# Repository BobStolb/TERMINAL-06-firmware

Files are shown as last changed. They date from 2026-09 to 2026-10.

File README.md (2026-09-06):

# TERMINAL-06 firmware

Six-digit Soviet nixie tube clock firmware — 4x IN-12A (HH:MM) + 2x IN-17 (SS),
built on Arduino Nano / ATmega328P.

Derived from [AlexGyver's NixieClock v2.5](https://github.com/AlexGyver/NixieClock_v2)
(MIT-spirited open project). Keep the original attribution if you redistribute
this source — see the header of `nixieClock_TS06.ino`.

## What's in here

- `firmware/nixieClock_TS06/` — the main clock sketch. Open
  `nixieClock_TS06.ino` in the Arduino IDE; the other `.ino` files in the same
  folder are tabs of the same sketch and compile together automatically.
  `nixieClock_TS06.hex` alongside them is a precompiled build — flashable
  directly with avrdude if you don't want to rebuild from source.
- `firmware/secCathodeMap/` — a standalone bench jig (its own `setup()`/
  `loop()`, deliberately kept in a separate sketch folder from the main
  firmware so the two don't collide at compile time). Run it once per new
  SEC module to map IN-17 cathodes to K155ID1 pins — see the comment header
  in `secCathodeMap.ino` for the full procedure.
- `libraries/` — actual source for the third-party libraries this sketch
  depends on: `GyverButton/` and `RTClib/`, each in the standard Arduino
  library layout (`.h`/`.cpp`, `library.properties`, examples). To build
  from scratch, copy both folders into your Arduino sketchbook's
  `libraries/` directory before compiling. Wire and EEPROM are built into
  the Arduino AVR core and don't need anything extra.

## Status vs. the project spec (as of 28.08.26)

This code is the display-layer port described in `TERMINAL-06-spec.md` §5:
six-tube multiplex ISR (Timer2 at AlexGyver's original prescaler 8, 50 Hz
refresh with 640 us of optocoupler dead time — see MULTIPLEX TIMING in the
sketch), anti-poisoning and glitch effects extended to all six tubes (both
now switchable off at build time, and currently off pending bench sign-off
of the timing), buzzer removed (D2 reused),
old rev B control scheme (2 buttons + 1 lever) — not the rotary/lever panel
described elsewhere in the project, which is a later firmware milestone.

**One known discrepancy, not yet fixed here:** the spec states `DOT_BRIGHT`
was retuned for neon (170/90) instead of the LED-era default (35/15), but
this source still has `DOT_BRIGHT 35` / `DOT_BRIGHT_N 15`
(`nixieClock_TS06.ino`). Doesn't affect the digit-multiplex testing this
firmware is used for (P2 in the prototype plan), but worth fixing before the
colon step (P6).

## Board settings for flashing

Arduino IDE: Board = Arduino Nano, Processor = ATmega328P. If upload fails
with a programmer-not-responding error, switch Processor to
"ATmega328P (Old Bootloader)" — common on CH340-based Nano clones.

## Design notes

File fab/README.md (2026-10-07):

# Fab packages: TS06-DISP, TS06-DRV and the fascia R

**To order, read `ORDER.md` (the order sheet for the owner).** Pictures of the boards are in `preview/`.

One zip per board of the through-hole pair, built from the committed boards by `tools/mkfab.sh`
(grill.md G8, second half). Rebuilt 30.09.26 from `pcb/kicad-boards` at 77e3b11 (TS06-DISP with
the circuit-as-ornament silkscreen art; TS06-DRV unchanged), with KiCad 10.0.6's `kicad-cli` in Docker.
First built at b8d3f25 (the rev B merge).

The fascia R (rev A, with the Divider gold) was added on 02.10.26. **On 07.10.26 it became rev B** (J1 is the upright JST B6B-PH-SM4-TB instead of the
side-entry S6B-PH-SM4-TB, `PCB/TS06-FASCIA-rhythm/J1-UPRIGHT.md`): `TS06-FASCIA-R-revB-divider-holes04-fab.zip` is the ordered one (control holes
opened 0.4 mm and level leaders, picked by the owner on 02.10.26). Rev A's zip with those holes is kept as `TS06-FASCIA-R-revA-divider-holes04-notordered-fab.zip`
and the first fascia zip, holes as drawn, as `TS06-FASCIA-R-revA-divider-slope-notordered-fab.zip`: both NOT ordered. See below.
It was rebuilt the same day, after the design-for-manufacture check (`tools/dfm_check.py`, the table below) had found
four things on it: thin silk, a small back legend, slivers of mask at four dial rings, and "None" as the finish in its job file.
All four are fixed in the generators; TS06-DISP's and TS06-DRV's zips did not change.

Not ordered: the prototype run is the owner's decision (grill G14). Filling the committed board files (G8, first half) is also the owner's decision.

## What is in each zip

`TS06-DISP-revB-fab.zip` and `TS06-DRV-revB-fab.zip` hold the same 12 files, named after the board:

| File | What it is |
|---|---|
| `<board>-F_Cu.gtl`, `<board>-B_Cu.gbl` | Copper, front and back, with the pours filled by KiCad (`--check-zones`) |
| `<board>-F_Mask.gts`, `<board>-B_Mask.gbs` | Solder mask, front and back |
| `<board>-F_Silkscreen.gto`, `<board>-B_Silkscreen.gbo` | Silkscreen, front and back |
| `<board>-Edge_Cuts.gm1` | Board outline |
| `<board>-PTH.drl`, `<board>-NPTH.drl` | Excellon drills, mm, plated and non-plated in separate files |
| `<board>-PTH-drl_map.gbr`, `<board>-NPTH-drl_map.gbr` | Drill maps (Gerber X2) |
| `<board>-job.gbrjob` | Gerber job file: board size, layer count, thickness, the file list |

All Gerbers are Gerber X2, 4.6 mm format, KiCad's default Protel extensions. There are no paste
layers: every part is through-hole (no SMD pads on either board), and neither board has a via.

| Board | Size (job file) | Plated holes | Non-plated holes |
|---|---|---|---|
| TS06-DISP rev B | 191.5 × 44.1 mm | 179 | 10 |
| TS06-DRV rev B | 191.5 × 100.1 mm | 427 | 8 |
| Fascia R rev B, Divider gold | 191.45 × 40.05 mm, 2.0 mm thick | 0 | 9 |

TS06-DISP's silkscreen files carry the art: front 29 kB to 121 kB, back 104 kB to 173 kB. Its
copper, mask, outline and drill files are the same as before the art, apart from the creation
date, and the thinnest silk line in them is 0.15 mm (the apertures in the two silk files).
TS06-DRV's files are the same as before, apart from the creation date.

The hole counts are the drill files' hits; they equal the boards' through-hole and
non-plated pads. Both job files say 2 layers, 1.6 mm and ENIG, from the boards' own setup; the
finish and the mask colour are chosen when the boards are ordered.

## The fascia R zip

`TS06-FASCIA-R-revB-divider-holes04-fab.zip` is the fascia `PCB/TS06-FASCIA-rhythm` (rev B) with the Plates white
print and a gold: the **Divider** by default. The committed board has no gold of its own, so `tools/mkfab.sh`
builds the art board in its scratch directory with `tools/fascia_gold.py divider OUT --base R` (that
script's own checks must be clean) and plots that. Nothing under `PCB/` is written.

* The zip has 11 files: the same names as above with the prefix `TS06-FASCIA-R-divider`, and one more,
  `B_Paste.gbp` (the eight 1206 resistors are surface-mount on the back). There is no plated drill file or
  plated drill map: the board has no plated hole. The board is 2.0 mm thick (the job file says so), and its job
  file says finish ENIG, as the other two: the board file carries the same stack-up (black mask, white silk, ENIG), written by `tools/mkpcb_fascia_rhythm.py`.
* The gold is in F.Cu as copper, 0.05 mm wider each side than the opening in F.Mask over it, so a mask
  misregistration shows gold and never bare board. `tools/mkfab.sh` reads the plotted Gerbers back with
  `tools/gerbers.py gold` (no KiCad): F.Cu must carry the gold; F.Mask must be open over all of it (about
  85% of the copper's area, the rest is the 0.05 mm rim); no opening may lie past the copper. The same check is
  run on a mask with the gold's openings removed, and must FAIL. Found: the openings are present, and no thin web
  of mask is left over the gold (the Divider's lines end clear of the dial rings' holes; before, four rings had 0.05 mm slivers).
* The name carries the gold. `--gold VARIANT` picks another (`ladder`, `fans`, `guilloche`; `none` is the bare
  board, `TS06-FASCIA-R-revB-bare-fab.zip`). Only the divider is laid out for R; the other three stop on their own
  checks (`tools/fascia_gold.py` says why).

## Design-for-manufacture check

`python3 tools/dfm_check.py` (limits *inferred*, typical of a low-cost two-layer service; `ORDER.md` lists them) reads each
board twice: KiCad's DRC under the fab limits, and the zip's own Gerbers and drills. Worst value found, and the
rule's limit; the fascia R's column is after the fixes, with the value it had before.

| Rule | Limit | TS06-DISP | TS06-DRV | Fascia R (before the fixes) |
|---|---|---|---|---|
| Track width | 0.15 | 0.25 | 0.25 | 0.25 |
| Copper clearance | 0.15 | 0.25 | 0.21 | 0.325 (rev A 0.375) |
| Annular ring | 0.15 | 0.30 | 0.20 | over 0.40 |
| Copper to edge | 0.30 | 0.75 | 0.75 | over 0.80 |
| Silk line, DRC text stroke | 0.15 | 0.15 | 0.15 | 0.15 (0.12) |
| Silk text height | 1.0 | 1.0 | 1.0 | 1.0 (0.8) |
| Smallest silk aperture, front / back, from the zip | 0.15 | 0.15 / 0.15 | 0.15 / 0.15 | 0.15 / 0.15 (0.12 / 0.10) |
| Smallest plated / non-plated drill | 0.3 / 0.5 | 0.9 / 3.2 | 0.8 / 3.2 | none / 2.7 |
| Narrowest mask web, front | 0.10 | 0.3 | 0.3 | 0.100 (0.05) |
| Narrowest mask web, back | 0.10 | 0.3 | 0.3 | over 0.35 |
| Board size | within 500 x 400 | 191.4 x 44.0 | 191.4 x 100.0 | 191.4 x 40.0 |
| **Result** | | all PASS | all PASS | all PASS (4 rows FAILed) |

Rows that do not appear above (plated drill, non-plated drill and hole-to-hole in the DRC; the fascia's gold exposed) also
PASS. The check's own self-test, a copy of TS06-DISP with one planted fault per rule, shows FAIL on all 17 rows, so the
rows can fail. The mask web reading is the raster's (steps of 0.025 mm, about +-0.03 mm).

## Region check

Every copper Gerber is exported twice: with `--check-zones` (KiCad fills every pour before it
plots; this is the set in the zip) and without it (a control, not shipped). The script counts the
region blocks (`G36` … `G37`) in each. A copper layer that carries a pour in the board file must
have more regions filled than unfilled, or the script fails and does not write the zip.

| Board | Copper layer | Pour in the board file (net) | Regions without --check-zones | Regions with --check-zones | Difference | Check |
|---|---|---|---|---|---|---|
| TS06-DISP rev B | F.Cu | BL_K | 0 (13 kB) | 1 (221 kB) | +1 | PASS |
| TS06-DISP rev B | B.Cu | none | 0 (27 kB) | 0 (27 kB) | +0 | n/a: no pour on this layer |
| TS06-DRV rev B | F.Cu | GND | 0 (57 kB) | 15 (550 kB) | +15 | PASS |
| TS06-DRV rev B | B.Cu | GND | 0 (54 kB) | 10 (443 kB) | +10 | PASS |

**What the difference means.** The committed boards store no fill. Plotted without
`--check-zones`, TS06-DISP's F.Cu has no BL_K pour, so all nine LEDs would be open, and TS06-DRV
has no ground pour on either face. TS06-DISP's back face has no pour by design, so it has nothing
to check. The filled counts equal the pieces KiCad's own fill keeps in
`tools/verify_pair.sh`'s "pours (KiCad)" rows (BL_K 1; GND 15 on the front, 10 on the back): one
region per piece.

## Rebuild

From the repository root:

```
bash tools/mkfab.sh                                   # all three boards; prints the table above
bash tools/mkfab.sh TS06-FASCIA-rhythm --gold fans    # the fascia with another gold (see above)
bash tools/mkfab.sh --keep                            # the same, and keeps the scratch directory (both exports, logs)
python3 tools/dfm_check.py                            # design-for-manufacture tables (inferred generic limits), see ORDER.md
bash tools/mkfab.sh TS06-FASCIA-rhythm --committed-holes   # the fascia as committed (holes 8.8 / 8.0), NOT ordered: ...-notordered-fab.zip
python3 tools/dfm_check.py --committed-holes          # the same DFM check on that zip (the default checks the ordered one)
```

`TS06-FASCIA-R-revB-divider-holes04-fab.zip` is the ordered fascia zip (the dial hole 8.8 opened to 9.2, the lever and button holes 8.0 to 8.4:
the owner's pick, 2026-10-02) with the level leaders (his second pick, the same day). The zip with the holes as drawn is kept as
`TS06-FASCIA-R-revA-divider-slope-notordered-fab.zip`, not ordered. `HOLES-VARIANT.md` says what differs and the margins; `ORDER.md` names the zip.

It needs `zip`, `python3` and KiCad 10's `kicad-cli`: a local one, or Docker with
`mirror.gcr.io/kicad/kicad:10.0`, found the same way as in `tools/verify_pair.sh`. The committed
board files are only read. The Gerbers and drills carry their creation date, so a rebuild is not
byte-identical to these zips; the region counts and the file list are. So that a rebuild does not leave a
changed file behind for nothing, `tools/mkfab.sh` keeps the zip already in this folder when the rebuilt one
differs from it only in those dates (it says so).

The fascia's gold check needs numpy, scipy and Pillow as well; `tools/dfm_check.py` needs the same.

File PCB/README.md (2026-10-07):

# TERMINAL-06 — custom PCBs

The fascia goes to Rezonit with the clock's electronics. For a small production run, the electronics are the through-hole pair **TS06-DISP + TS06-DRV**: tubes on one board, everything else on the one behind it, no vias on either. The one-board TS06-MAIN is kept, with its history. A tube board of the old kind is deliberately deferred.

| Board | Size | Stack | Status |
|---|---|---|---|
| **TS06-FASCIA** | 176 × 40 mm | 2.0 mm FR4, black mask, white silk, ENIG | Routed. The control panel AND the printed product face. One board, not two. Surface-mount build: no solder visible from the front. Height compressed from the original 52mm 2026-09 - see below. |
| **TS06-FASCIA-rhythm** (fascia R) | 191.4 × 40 mm | 2.0 mm FR4, black mask, white silk, ENIG | **The fascia of the order** (`fab/ORDER.md`). Controls on the tubes' grid, surface-mount on the back, no plated hole. **Rev B (7.10.26): J1 is an upright JST B6B-PH-SM4-TB** (top entry: the plug stands off the back and the wires leave straight back; rev A had the side-entry S6B-PH-SM4-TB, whose lead bent 90 + 12 degrees onto the floor and cost the case 7.3 mm) - `PCB/TS06-FASCIA-rhythm/J1-UPRIGHT.md`, `PCB/TS06-FASCIA-rhythm/bom.md`. The 176 TS06-FASCIA above is unchanged (it keeps the side-entry part). |
| **TS06-FASCIA-THT** | 176 × 52 mm | same stack, ENIG | Second build of the same board, routed. Through-hole, with the A6 divider ON the face. Pick one to fabricate; they are alternatives, not a pair. Not yet height-compressed (the SMD build was chosen for fabrication). |
| **TS06-DISP** + **TS06-DRV** | 191.4 × 44 mm + 191.4 × 100 mm | 1.6 mm, matte black | **The through-hole pair (25.09.26), the build for a small production run.** A display board with the tubes and nothing else, plugged by pin strips into a driver board behind it, the way AlexGyver builds his. **Zero vias on either board.** Both at rev B (30.09.26): TS06-DRV rev B is routed and merged, `tools/verify_pair.sh` gives 27 PASS, 0 FAIL, 0 SKIP, and the fab packages are in `../fab/`. Not ordered. See below. |
| **TS06-MAIN** / **TS06-MAIN-THT** | 176 × 96 mm | 1.6 mm, matte black | **The whole clock on one board**, two builds, one outline, one netlist. Placed and checked; routing in progress — see below. Replaces the inherited AlexGyver board, SEC and COLON. |
| ~~TS06-SEC~~ | 67 × 55 mm | 1.6 mm, matte black | **Superseded 17.09.26 by TS06-MAIN.** Surface-mount build routed and clean (1159 tracks, 79 vias); kept as the worked example of a hard placement and of the router. |
| ~~TS06-COLON~~ | 6.5 mm strip | — | **Superseded 17.09.26 by TS06-MAIN**, which carries the two ИНС-1 at the same measured positions. Placement only. |
| ~~TS06-TUBE~~ | — | — | **Deferred 08.09.26.** See below. |

## The two builds of the fascia

Same outline, same artwork, same netlist, same connector. They differ in one decision:
where the solder is.

* **TS06-FASCIA** — every pad is surface-mount on the back face. The customer sees black
  mask, white silkscreen and the decorative gold, and no joint anywhere. Routed with 64
  signal tracks, all on B.Cu, and **zero vias anywhere on the board** — F.Cu carries only
  the decorative gold, so no signal net can ever collide with it. GND is a pour over the
  back face, same as THT, and reaches all 7 GND pads on its own: R6 (the A7 pull-up) used
  to sit directly in the corridor the other five nets needed to reach J1, walling three
  GND pads (SW4.1, R8.2, R7.2) off from the plane with no B.Cu path a router could find at
  any trace width. Moving R6 out of that corridor — no other placement changed — opened it
  up enough that the pour alone closes the gap, confirmed by checking every GND pad against
  KiCad's own computed `filled_polygon`, not just this repo's simulated one. No stitch
  traces, no vias, nothing extra: placement fixed what routing couldn't.
* **TS06-FASCIA-THT** — the A6 resistor ladder is on the FRONT: five axial resistors above
  the rotary's seven landing holes, and the copper between them is bare, so the divider
  reads as a circuit rather than as decoration. Every other part is behind the panel with
  its front mask closed, so those holes show no gold ring. Routed with 34 tracks and no
  vias: the ladder on F.Cu under opened mask, six signals on B.Cu under mask, and GND as a
  pour over the whole back face.

`preview.svg` (`preview.png` too, where regenerated) in each board's folder is generated
by `tools/render.py` from the board file itself — front face and back face — so the board
can be looked at without opening KiCad.

**TS06-FASCIA height compression (2026-09).** The board felt oversized next to the tube
row, so it was cut from 52mm to 40mm tall. This was a pure translation, not a re-route:
every footprint, all 64 tracks, the GND pour and the silkscreen legend were shifted up by
a fixed 12mm (the dead margin above the control row - SR25's 12.5mm lever-throw keepout
was the real floor, not the visible knob bezel), then the board outline itself was
redrawn 12mm shorter. Nothing about the routing was redesigned, so R6's placement (still
load-bearing for the GND pour closing without vias, see above) is untouched. The two
mounting holes nearest the top edge are the one exception: they're anchored to the board
edge, not the control row, so they were NOT shifted, keeping their original 4.5mm inset
from the (new) top edge. All five checker tools pass clean and match the pre-compression
board's output exactly (same 2 pour islands, same 86% coverage, same 12-net agreement
with the schematic). One thing the pure translation did NOT fix on its own: the MODE
dial's decorative arc (position labels 1-6, their tick marks, and the "MODE" title)
was drawn for the old 26mm-radius-from-center clearance and clipped the new 14mm
budget - the checker tools don't validate silkscreen against the board edge, only
copper, so this needed its own pass. Fixed by rescaling the whole arc/tick/number
system by 0.789 (position 1, the tallest point, now sits at 12.5mm above center
instead of 15.84mm) and moving the "MODE" title from directly above the shaft to
its left, clear of position 1's tick - it was the single tallest element (19mm)
and didn't belong to the numbered fan, so it got its own placement rather than
being scaled with the rest. `checkpcb.py`'s rotary-keepout check had the rotary's position
hardcoded as a literal (30.0, 26.0) from the old layout - fixed to read the rotary
footprint's real position instead, since a checker that only works for one specific
layout isn't a checker. TS06-FASCIA-THT was not touched - the SMD build was the one
chosen for fabrication.

**Two leftovers of that compression, fixed 30.09.26.**
* **Five circles moved by half.** The compression moved each circle's end point up 12 mm
  but not its centre. The rotary's 25 mm body ring, on F.SilkS, would have printed as a
  34.7 mm ring 12 mm below the knob and run 3.3 mm off the bottom edge. Its four siblings
  (lever and button keepouts on User.1) had the same fault. These were the board's only 2
  KiCad DRC warnings. All five centres are moved up 12 mm, so each radius is horizontal
  again (12.5 and 12.0 mm). The body ring is back on User.1, where `tools/mkpcb.py` drew it.
* **A stale ground fill.** The stored GND fill reached 11.5 mm above the top edge, and
  Gerbers plot the stored fill. KiCad 10 refilled the pour and saved the board.

After both fixes:
* KiCad DRC: 0 violations and 0 unconnected, at every severity.
* `checkpcb`, `checkcopper` and `audit`: clean.
* `checkmatch`: agrees with the schematic.

**One picture outlived the fix.** `PCB/TS06-FASCIA-rhythm/composite-0-centred.png`, the
reference that the fascia variants are judged against, was drawn from a board older than
the ring fix. So it still showed the ring 12 mm below the knob, and the owner's review
reported it as "the SW1 white circle isn't centred on its hole". It is redrawn from the
fixed board. `tools/mkpcb_fascia_rhythm.py` now refuses to draw a composite from a board
whose F.SilkS ring encloses a control hole off-centre (`silk_rings_off_centre()`).
`tools/render_kicad.py` renders a board in KiCad 10 with the black mask and white silk
that are ordered.

**Fascia R, rev B (7.10.26): J1 is upright.** The footprint `TS06_JST_PH_B6B-PH-SM4-TB_Back` (KiCad's land pattern, mirrored in X for the back; SMD, no plated hole) keeps the pin order and the place between the buttons; the case model's floor rose from Y -7.3 to -4.5 (204.4 × 120.0 × 81.0 mm outside). The rest of this section is about the 176 TS06-FASCIA.

**J1 pin order is fixed for both builds: 1 +5V, 2 GND, 3 A6, 4 A7, 5 D7, 6 D8.** It used
to be whatever the surface-mount routing preferred (D8, D7, GND, A7, +5V, A6). The
through-hole board cannot route to that order, and two builds of one product must not
need two different cables, so the pin order stopped being a layout convenience and became
a specification. The legend is printed on the back silkscreen of both boards.

## TS06-DISP + TS06-DRV — the through-hole pair (25.09.26)

**The clock as two stacked boards, the way AlexGyver builds his: a display board with the tubes
and nothing else, and a driver board behind it with everything else, joined by pin strips.**
Through-hole throughout, **no vias on either board**. The layout is designed as a whole, not
packed and then routed. This supersedes TS06-MAIN-THT as the build for a small production
run. TS06-MAIN (SMD) and its history stay as they are.

A critical review of the pair, and what it means for the case, is in
`../Claude outputs/TS06-pair-review.md`.

### Why two boards, and why these two

The one-board TS06-MAIN failed on the thing the owner cares most about:
* 476, then 339, then 177 vias;
* a ground pour in hundreds of islands;
* cathode switches squeezed into tube rings.

The split study (`../Claude outputs/TS06-split-study.md`) found an 18-wire cut. The owner chose
the Gyver cut instead: **tubes only on the display board**. The halves join the way Gyver joins
his, with a straight pin strip (PLS / рейка штыревая) on one board plugged into a socket strip
(PBS) on the other. No wires, no cable to make up.

That cut is what makes zero vias possible:
* The display board has no drivers, so its copper is only the tube wiring. The ИН-12 cathode
  bus can be threaded through the sockets on one face, as Gyver's tube half does it.
* The driver board has no tube fields, so every block can sit behind the strip pins it drives.

### Circuit changes for the pair (owner, 24.09.26)

| Change | Why |
|---|---|
| **ИН-15 pair on 2 × К155ИД1 + 1 × MCP23017** instead of 18 MPSA42 + 18 base resistors + 2 expanders | A symbol tube lights one glyph at a time, exactly like a digit, so a decoder does the whole job. 37 fewer parts, ~110 fewer joints. Firmware writes a code per tube; 10–15 blanks it. |
| **Every backlight LED addressable**: one MCP23017 port-B pin and one resistor per LED (RN1, an isolated 8 × 220 R network), cathodes common through the MPSA42 on D11 | A lit LED can show which tube's setting is being changed; D11 stays the global brightness PWM. |
| **A second К155ИД1 (U17) for the ИН-17 pair**, on the same A0–A3 lines | The display board delivers the ИН-12 bus and the ИН-17 bundle in the orders their tubes impose. One decoder feeding both would need a ten-line permutation, which two layers cannot make without vias. |
| **`BOARD_TYPE 4`** in the firmware | The pair's own digit map, `digitMask[] = {1, 0, 5, 4, 6, 7, 3, 2, 9, 8}`, and its own anode order `opts[]` (hours on D6/D5, minutes on D4/D3, S10 on D2, S1 on D13: the order types 1 and 2 use). The anode pins are the same six, driving different tubes, so the Nano's digital row fans out without crossing itself. |

Every other Nano pin keeps its function.

### The stack

**TS06-DISP**, 191.4 × 44 mm.
* **On its front:** 4 × ИН-12, 2 × ИН-17, 2 × ИН-15, 2 × ИНС-1 and 9 LEDs.
* **On its back, seven male strips:**
  * XP11 on the left edge (the ИН-12 bus);
  * XP12 on the top edge (31 pins: the ИН-17 bundle and both ИН-15, with 3 spares after pin 10);
  * XP21–XP25 on the bottom edge (anodes, colon, LEDs).
* **Silkscreen: the circuit as ornament** (the owner's choice of 30.09.26, from three art
  directions: "the best for display pcb is circuit as ornament"). It is drawn over rev B's labels
  by `tools/mkpcb_disp.py`, which writes it by default (`tools/disp_art.py`; `--art none` writes
  plain rev B). The art is the board's own circuit: the ИН-12 bus strands and the cathode order
  1 6 2 7 5 0 4 9 8 3 on the front, only where the finished clock shows the board, and every
  socket's pinout on the back. White silk only, lines from 0.15 mm, clear of every pad; the copper
  is unchanged. Three back-face pin labels are left out for room (H and m, the top pins of the two
  ИН-15; A, the ИН-15Б's ampere cathode); XP12's legend names all three.

**TS06-DRV**, 191.4 × 100 mm, sits 11 mm behind the display on M3 standoffs (a standard 8.5 mm
PBS socket plus a 2.5 mm PLS body). Its seven socket strips are on its **back** face, towards
the display. Every other part is on its front, towards the back of the case, so nothing taller
than the strips lives between the boards. It has three bands:
* **The top band, 26 mm above the display:**
  * the Nano across the top-right corner, its USB proud of the edge;
  * the 12 V jack through the other edge;
  * fuse, polarity diode and 5 V regulator;
  * the 185 V converter in one tight loop, with its driver and control block beside it, and
    (rev B) an over-voltage clamp that stops the switch at 225-270 V without the comparator.
* **The tube band, behind the display:**
  * the three К155ИД1 for the ИН-15 pair and the ИН-17 pair under the top strip;
  * U2 beside the left strip;
  * the six anode channels as three cells over the bottom strips: two resistors and two optos
    per pair of tubes. Rev B draws the resistors for МЛТ-0,5 (15.24 mm), so the seconds' cell lays
    its two back to back in one row and the minutes' and hours' cells keep two rows 5.0 mm apart.
* **The bottom band, 30 mm below the display:**
  * the MCP23017 with its LED network stacked on port B;
  * the RTC module;
  * J1, the fascia connector. It is top-entry, so the cable leaves straight towards the fascia.
    Rev B's 1 k + 10 nF on D7 and D8 and 1 M on A6 sit between the strips and J1, each part on its
    own line's way in, so the lines still fan into J1 in its pin order
    (`recovered/drv-revb/OPTIONS.md`: placed as a block in front of J1, they stalled the route).

The strip order is a specification shared by both boards (`tools/ts06pair.py HEADERS`).
`tools/mkpcb_drv.py` proves three things: every XS pin lands on its XP pin, it carries the
same net, and every display standoff has its hole.

**Why 191.4 mm, not 176** (29.09.26). The two ИН-17 were first drawn 13 mm apart, as every board
before had them, but their Ø20 stems need 20.5 (the tube's outline drawing; concept Rev F). The
owner chose to widen the boards and keep the Gyver pitch:
* the ИН-12s and the colon did not move;
* the seconds pair now stands 20.5 apart, each stem 2.2 mm from the glass beside it;
* the ИН-15 pair moved 15.4 mm right.

XP12 stays one strip of 31 pins, with three spares where the ИН-15 group moved further than the
ИН-17 group. On the driver board, what sits behind the ИН-17s moved 7.62 mm, and what sits behind
the ИН-12s, with the Nano and U2, moved 15.4. It was then re-routed. The review has the finding.

### How the driver board has no vias

A through-hole pad is copper on both faces, so it is the only place a net may change face.
The driver board is placed so that every crossing happens in a part the circuit already has.
There are no wire links and no zero-ohm jumpers.

The long buses are laid by hand, each on one face:
* **Port A of the expander:** out of the bottom of U3, up the left edge, and east under the
  two ИН-15 decoders, as one eight-line bus. In every bend, the inner line turns first.
* **The LED ribbon:** from the network up into lanes under the bottom strips. The two lines
  to the hours' strip run on the front face, so the back face under the strips is free for
  the button lines to cross on their way to J1.
* **The U17 branch of A0–A3:** it leaves under the Nano and runs down a corridor beside it.
  It enters U17 between the chip's rows, the one approach that lands every line on its own
  pin; from below, the bus would arrive mirrored.
* **D9, D10, D12 and D13:** they share that corridor and end in four standing resistors at
  its exit. Their outputs leave on the other face.

The Nano's fan-out below the module is also laid by hand:
* **The digital row, on the back face,** in lanes just below the module:
  * D2–D4 go to the minutes' and S10's opto resistors, standing under the module's end;
  * D5 and D6 go to the hours' opto resistors, lying straight above their optos;
  * D7, D8 and D11 go down the gap between the hours' cell and U2.
* **A7, A6, SCL and SDA, on the front face,** come down the same gap and west between the
  hours' optos' pin rows. They end in one column of their filters and pull-ups, in the order
  they arrive, and change face there.

Everything else is routed by `tools/netroute.py`, which never places a via. It uses negotiated
congestion (PathFinder), with diagonals priced above two straight steps, so long runs come out
square with 45° corners. A polish pass then re-routes each net alone. The result is saved in
`tools/mkpcb_drv_routes.json`, so the board regenerates exactly.

### Assembly-friendly by design

* **Every part is through-hole**, on standard footprints read out of KiCad 10's own libraries
  (`PCB/lib/TS06.pretty`). Nothing needs hot air or paste.
* **Every IC is in a socket and the Nano is on two PBS-15 strips**, so a dead chip or Nano is
  a swap, not a desolder.
* **References are on the silkscreen** of TS06-DRV's component face, and (rev B) the legends a
  builder needs: the block names, the 185 V areas fenced and marked "DANGER 185 V", "12 V DC,
  centre +" at the jack, "HV SET" at the trimmer, "fit U12 before U11", "USB only with 12 V on",
  the RTC module's "- NC C D +" and its outline, J1's pinout and every strip's pin 1 on the face
  towards the display, and the title. All at the fab's floor: 1.0 mm text, 0.15 mm lines, off
  every pad.
* **No wiring harness between the boards.** The fascia cable (JST PH, spec pin order) is the
  only cable.
* **The anode channels are drawn from one pattern**, so a mistake in one is easy to see in all.
* **High voltage is kept in its own net class**, with 0.6 mm clearance enforced by KiCad's DRC
  from the project file. On TS06-DRV (rev B) every bare high-voltage pad keeps 0.8 mm
  (IPC-2221B table 6-1, A6) from all other copper on both faces, the ground pours included: a
  rule in `TS06-DRV.kicad_dru` that KiCad's DRC and zone filler apply, that the router routes to,
  and that `checkcopper.py --hv-pad 0.8` checks. Cathode pads keep 0.5 mm from other nets.
* **No copper within 3.8 mm of a standoff hole** on TS06-DRV (rev B), both faces: keep-out areas
  KiCad holds, clear of a 7 mm washer (3.5) and a 5.5 mm hex spacer's corners (3.18).

**Solder the strips while the two boards are plugged together.** See the review, finding 2.

### TS06-DRV rev B (30.09.26): what changed

Rev B closes the review's open items for the driver board (the review's second grill, E, M and R
rows). Rev A is 78105d6. The record of the work, with the routing choice, is in
`../recovered/drv-revb/` (`STATUS.md`, `OPTIONS.md`).

| Change | Parts | Review item |
|---|---|---|
| **An over-voltage clamp independent of U12:** a zener string (82 + 82 + 75 V) into an NPN that pulls PWM_G low. It starts at 225 V or more and clamps by 270 V at every tolerance (computed in `tools/ts06pair.py`, not measured) | VD5, VD6 (1N4762A), VD7 (1N4761A), R75 100k, R76 10k, VT2 2N3904 | E1 |
| **0.8 mm from every bare 185 V pad to all other copper**, both faces, the ground pours included: a rule in `TS06-DRV.kicad_dru` that KiCad's DRC and zone filler apply | - | E3 |
| **A USB back-feed diode** across the 5 V regulator | VD3 1N5819 | E5 |
| **An input TVS** after the fuse, so a 19-24 V adapter trips F1 | VD4 1.5KE18A | E8 |
| **The fascia inputs filtered and pulled down:** 1 M from A6 to ground, 1 k + 10 nF on D7 and D8 (J1 pins 5 and 6 are now D7_J and D8_J). Placed by hand between the strips and J1, each on its own line's way in | R72, R73, R74, C18, C19 | E11 |
| **0.5 mm from cathode pads to other nets**, with oval-pad sockets for the decoders | U2, U15-U17 | E10, R8 |
| **МЛТ-0,5 footprints** for the 0.5 W resistors: 1.1 mm holes at 15.24 mm | R27-R32, R56-R63 | M4 |
| **A real L1:** Bourns 5900-221-RC, 220 µH, 1.8 A, axial, lying | L1 | E4, M2 |
| **The RTC module on a male PLS-5**, its outline and the "- NC C D +" legend drawn | U13 | M1 |
| **Larger holes** for VT21 (1.2 mm) and J1 (0.85 mm) | VT21, J1 | M7 |
| **No copper within 3.8 mm of a standoff hole**, as KiCad keep-out areas | H1-H8 | M12, R1 |
| **Silkscreen legends at the fab's floor** (1.0 mm text, 0.15 mm lines): block names, the 185 V fences, the jack, the trimmer, the bring-up order, J1's pinout | - | M8 |
| **The DNP attribute** on the bleeders | R33-R44 | R13 |
| **A reproducible route:** the router pins its hash seed, and a fresh `--route` rebuilds the saved route byte for byte (2aec60c) | - | R6 |

**What rev B scores against rev A** (`scorecard.py`, from the board files alone):

| | Rev A (78105d6) | Rev B |
|---|---|---|
| Segments / vias | 1097 / **0** | 1164 / **0** |
| Signal copper / its floor | 5936 / 4479 mm = 1.33 | 5918 / 4533 mm = **1.31** |
| Straight (0°/90°) share | **86.1 %** | 83.3 % |
| DIP orientations | 3 | 4 (U11, below) |
| Case depth (the case model) | 83.6 mm | **81.6 mm** |

**U11 now stands at 0°, a fourth DIP orientation.** In rev A the TC4420 stood at 180°, like U12
and U2. Rev B's placement came from the work recovered after the layout agent was lost, and it
puts U11 at 0°, moved from (81, 20.7) to (57, 14.8) in the board's frame. It is not on the change
list above. The board passes every check with it, but a fourth orientation is one more way to
fit a socket backwards (review, finding 5). Whether to turn it back is the owner's choice;
turning it moves its pins, so the board would be routed again.

**The case is 81.6 mm deep, not 83.6.** The case model now reads the new footprints' real
heights. With U13 on a male header, C7 (20 mm, worst case) is the tallest part, 5.0 mm clear of
the rear panel.

### Checked

`tools/verify_pair.sh` runs every check below on both boards in one command, with the accepted items
listed in its header. `TS06-pair-testing.md` explains it for the owner, with how to view the boards
and the staged bench bring-up. Two of its checks read the written files with KiCad's own geometry
(`tools/kicad_checks.py`, under the KiCad image's Python):
* **`mate`:** all 63 strip pins and the 4 standoff holes, with their positions, nets, drills
  and faces;
* **`fill`:** the pours as KiCad fills them.

**The committed boards store no zone fill.** Refill before plotting Gerbers: press B in the PCB
editor, or use `kicad-cli pcb export gerbers --check-zones`. TS06-DISP's LED return, BL_K, is a
pour with no tracks, so a Gerber plotted unfilled leaves all nine LEDs open. `tools/mkfab.sh`
builds the fab packages that way (`../fab/`, grill.md G8) and checks that every poured copper
layer's Gerber carries its pour regions. Filling the committed files is the owner's decision.

**`tools/verify_pair.sh` on rev B (30.09.26, after 2dc04ec, and again with the circuit silk, 77e3b11): 27 PASS, 0 FAIL, 0 SKIP.**

`checkcopper.py --hv` is run with the pair's HV list, `ts06pair.HV_PATTERNS`:
`HV185,SW,BLEED_*,FB_MID,COLON_*,ANODE_*,EMIT_*`. The cathode nets have their own class,
CATH, at 0.25 mm.

Both boards are generated from `tools/mkpcb_disp.py` and `tools/mkpcb_drv.py` and pass every
board checker in this repo, plus KiCad 10's own DRC (`kicad-cli pcb drc --refill-zones`, HV class from
the project file). Since 30.09.26 the pair has schematics as well, generated from the same netlist by `tools/mksch_pair.py`, one sheet per section. `checksch.py` finds no dangling pin, `checkmatch.py` agrees net for net with each board (136 nets on rev B's TS06-DRV, 59 on TS06-DISP), and KiCad's ERC reports 0 violations at every severity. `verify_pair.sh` runs all three.
The results as of 30.09.26 (TS06-DRV rev B), on the widened boards:

| | TS06-DISP | TS06-DRV |
|---|---|---|
| Tracks / vias | rev B (30.09.26): 388 / **0** | rev B (30.09.26): 1164 / **0** (373 laid by hand, 791 routed); rev A 1097 / 0 |
| Copper, and its ratio to the placement's floor | 2125 mm, 1.15× its 1851 mm floor. Like for like with TS06-DRV: signals only, since BL_K is poured and has no tracks (the 1.04× given before counted BL_K's 164 mm in the floor; rev A was 1.14× on this basis) | 6689 mm: 5918 mm of signals, 1.31× their 4533 mm floor, and 772 mm of ground tracks under the ground pours (rev A: 5936 mm, 1.33× 4479 mm) |
| Straight (0°/90°) share of the copper | 53 % | 83.3 % (rev A 86.1 %) |
| DIP orientations | - | 4 (rev A 3): U11 now stands at 0°, from the recovered placement and not on rev B's change list; the owner decides whether to turn it back |
| Ground pours as KiCad fills them | BL_K: 1 piece | GND: 15 pieces on the front (the largest 92 %), 10 on the back (the largest 33 %); rev A 13 and 14 |
| Case model (`3d/case-pair`) | the pair's case: 204.4 × 122.8 × 81.6 mm outside | 81.6 mm deep (rev A 83.6): C7 is the tallest part, 5.0 mm clear of the rear panel |
| Routing | drawn by hand; every bare 185 V pad 0.8 mm from other copper (IPC-2221B A6), every cathode pad 0.5 mm, no copper within 3.8 mm of a standoff hole | converged in negotiated routing: round 13, 0 nets sharing, 0 unrouted; then polished (30 nets shorter). PYTHONHASHSEED pinned to 0 by the script: a fresh `--route` reproduces the saved route byte for byte (checked 30.09.26); the saved route is the source. Every bare HV pad 0.8 mm from other copper (the `.kicad_dru` rule, proved live), 0 cathode pads under 0.5 mm, no copper within 3.8 mm of a standoff hole |
| `check_mate()` | — | `[]`: all 63 strip pins (59 carry a net) land on their pins with the same net, all four display standoffs have holes |
| `checkcopper.py --hv` | clean | clean |
| `audit.py` | clean; BL_K in one piece | clean |
| KiCad 10 DRC | **0 unconnected**, 0 warnings, 2 errors, accepted, awaiting the test fit: the colon lamps' courtyards overlap the M10 tube's by 0.135 mm. Run with `TS06-DISP.kicad_dru`, the A6 rule (0.8 mm, HV pad to any other net), which the pour fill honours too | **0 errors, 0 unconnected**, 2 warnings: the Nano's USB outline stands past the edge by design. Run with `TS06-DRV.kicad_dru`, the A6 rule (0.8 mm, HV pad to any other net) |
| `checkpcb.py` | H3's courtyard 0.15 mm past the top edge; XP11's 0.17 mm past the left edge (the mirror of XS11); the two colon overlaps | the Nano's courtyard past the edge (its USB, by design); XS11's 0.17 mm past it (the strip sits where the display's XP11 is) |

A second, independent model checks the boards as objects too: the case model in `3d/case-pair`
reads both generators and tests the tubes, strips, standoffs, tall parts and connectors against
the case. It is what found the ИН-17 spacing. Its check of the pair now reads stem to stem
0.5 mm, and 2.2 mm to the glass either side.

The same checks against the display's standoffs caught one thing no courtyard check sees: a
standoff and a strip body share the 11 mm gap. H4 was moved 2 mm to clear XP12 (review, finding 1).

### Open before fabrication

* **Bench gates:** the ИН-17 lead order, the ИН-15 pinouts, the ИН-17 pip and the RTC module
  (rev B draws the module lying beside its PLS-5; check its body falls on the outlined side).
* **Rev B on the bench:** with U12 out of its socket and RP1 at either end, the OV clamp must
  hold the rail between 225 and 270 V (typically ~242 V; computed from the parts' tolerances, not
  yet measured) - bring it up on a current-limited 12 V supply with C7 bled. L1 is the Bourns 5900-221-RC (axial, 1.8 A): check the supplier's
  datasheet revision before ordering.
* **Parts to measure:** the PBS and PLS heights of the batch being bought.
* **Test fit:** the colon lamps against the M10 glass.
* **The owner's decisions:** whether rev B is the board for the prototype, and whether U11 turns
  back to 180° (rev B stands it at 0°, a fourth DIP orientation); the prototype order (grill.md
  G14); filling the committed boards (G8, first half). The fab packages are built (`../fab/`).

Cathode-order surprises are firmware tables. Only anode identity and the RTC pin order are
copper. On the firmware side, `BOARD_TYPE 4` now runs the pair: six slots, the "m" LED, the
expander, and the MODE rotary as PROGRAM/RUN. The rotary's other screens, the levers on A7 and
the ИН-15 content are still to write. The review has the list.

## TS06-SEC — seconds and AM/PM

Generated by `tools/mkpcb_sec.py`: placement, then routing by `tools/pcbroute.py`. A full
run takes about five minutes. The generator's docstring carries the reasoning in full; in
short:

* **67 × 55 mm, not the spec's 46 × 34.** The tube centres are not a layout choice — they
  come from the reviewed 8-tube assembly (`3d/Clock.FCStd`). The four tubes span 66 mm and
  their glass covers most of the front, so everything but the tubes, the three LEDs and the
  connectors mounts on the back. The ИН-17 at V5 overhangs the left edge by 1.37 mm (its
  glass, standing on its leads, not the board); `checkpcb.py` reports that courtyard, and it
  is accepted.
* **What it carries:** 2× ИН-17 and their TLP627 anode drivers; 2× ИН-15 (V9 ИН-15Б for AM,
  V10 ИН-15А for PM) with 18 cathode channels — two MCP23017s and eighteen MMBTA42s, one per
  real cathode; the colon switch (the colon board arrives on XS4); two amber backlight LEDs
  for the ИН-17s and the "m" LED HL3. XS1 is 185 V in, XS2 the ИН-17 cathode bus (IDC 2×5),
  XS3 the logic connector.
* **High voltage is its own clearance class:** 0.6 mm around the 185 V feed, the tube
  anodes, the TLP627 emitters, the bleed mid-points, every ИН-15 cathode and the colon
  return. The ИН-17 cathode bus is not in it: the К155ИД1 outputs clamp near 60 V, and the
  tube's own pins sit 0.9 mm apart.
* **79 vias — the first board in the family with any.** Four tube pin fields, ~90 nets and
  every part on one face of 67 × 55 mm do not route on two layers without them. The router
  charges each via as much as 15 mm of track, so each one is a detour it could not find.
* **Routing.** The high-voltage locals are laid first. Everything else — the ИН-17 bus, the
  185 V feed, the 5 V signals, +5V and GND — is negotiated at once in the manner of
  PathFinder, because laid one net at a time they walled each other in: the 185 V feed cut
  the back face in two, and the bus, laid early, boxed in the backlight LEDs.
* **GND is a routed tree and a pour on each face.** The pours alone left GND pads in
  pockets that signal tracks had closed on both faces — `audit.py` and KiCad's refilled DRC
  both said so — so GND is routed from XS3 like any other net, and the pours fill whatever
  the tracks leave. Surface-mount pads join the pours solid, through-hole pads by spokes;
  HL3's GND pin joins solid too, because tracks leave no room there for two spokes.
* **Checked:** `checkcopper.py --hv "HV185,CAT_*,ANODE_*,EMIT_*,BLEED_*,COLON_RET"` clean,
  `audit.py` clean (both pours), KiCad 10 DRC with zones refilled clean at every severity;
  `checkpcb.py` reports only the V5 overhang above. There is no SEC schematic yet, so
  `checksch.py` and `checkmatch.py` do not apply.
* **Footprints corrected on the way:** `TS06_IN12_Socket` and `TS06_IN17_Socket` were
  mirrored in Y; the ИН-12 socket's description carried raw quotes that stopped the whole
  `TS06.pretty` library loading; the ИН-17 pip hole is gone — the ТУ's 8 mm soldering rule
  holds the glass at least 6.4 mm off the board — and its silkscreen outlines were redrawn
  clear of the pads.
* **Still open:** the through-hole build (tube board plus a stacked driver board); a bench
  check of the ИН-15 pinouts (taken from tec.org.ru and rudatasheet.ru, which agree) and of
  the ИН-17 pip's projection, which must be under 6.4 mm; HL3's position is provisional; and
  the fascia was drawn around the old SEC outline, to be revisited.

## Checking

Nothing here is checked by KiCad until it is opened in KiCad, so five tools check it
first. Run all of them after any change to `tools/mk*.py`:

    python3 tools/checkpcb.py   <board>.kicad_pcb    # placement, keepouts, front copper vs pads
    python3 tools/checkcopper.py <board>.kicad_pcb   # clearance and per-pad connectivity
    python3 tools/audit.py      <board>.kicad_pcb    # per-net connectivity, pour fill, silkscreen
    python3 tools/checksch.py   <board>.kicad_sch    # dangling pins and the net list
    python3 tools/checkmatch.py <board>.kicad_sch <board>.kicad_pcb   # the two files agree

`checkcopper.py --hv NETS` (a trailing `*` matches every net with that prefix) holds 0.6 mm wherever a listed net is on
either side of a gap, and keeps copper 0.25 mm from unplated holes. `audit.py` checks a
poured net as one net across both faces — pour islands, pads, tracks and vias together — so
a back-face pad that reaches a front pour through a via is checked rather than skipped; a
round pad is cut out of the pour as a circle, not its bounding square; and two vias of a net
count as joined only where their copper touches. `checkpcb.py` reads each courtyard graphic
as a whole block and compares courtyards only between parts on the same face.

`checkmatch.py` is the one that matters most and was written last: every other tool can
pass while the schematic and the board disagree about what they are connecting.

All five tools, plus `render.py`, read `.kicad_pcb` files two different ways depending on
who last saved them: this repo's own `tools/mk*.py` generators outdent each `(footprint
...)` block to column 0 and always number net references, while the real KiCad 10 install
this board gets edited in indents footprints normally *and* writes every net reference —
pads, tracks, vias, the zone itself — as a bare name with no code at all, no matter how
many times the file gets saved. Every tool here parses both forms; nothing needs
reformatting by hand before a check runs, and nothing should ever again. If a check comes
back suspiciously empty (`0 footprints`, `no tracks or vias`) after a real KiCad save, that
means a *new* variant slipped through, not that the board is broken — fix the parser, not
the file.

`IN-12_norm/` is the inherited AlexGyver/itworkclub board's fab data, kept as reference.
`lib/` holds project-local symbols and footprints — nothing here relies on a stock KiCad
library, because none of the Soviet panel hardware has one.

## Why TS06-TUBE is deferred

Three reasons were ever offered for fabricating a custom ИН-12 tube board. Only one is
still alive, and it is not an electrical one:

1. **Four anode bleed resistors need a home.** **Withdrawn 06.09.26** — the ghosting root
   cause turned out to be empty multiplex slots (spec §5a-pre), not the anode drivers.
   Dead reason.
2. **The socket pin pattern.** **Not a reason.** The footprint is fully known from the
   inherited board's Gerbers — see `../TERMINAL-06-measurements-PCB-IN12BOARD.md`. The
   tube defines the pattern, so any socket that fits the tube fits those holes.
3. **Deck geometry — the only live reason.** Tube pitch (23.36 / 27.42 / 23.36 mm), deck
   height, forward offset and rake are all fixed by someone else's layout. Spec §6's
   "Brow reveal" note is the argument: the brow was sized to clear the 18.63 mm digit, but
   the envelope is 28.70 mm, so ~10 mm of glass sits behind the top deck.

**Against it:** ten main boards are already owned, therefore ten tube halves are already
owned. TS06-TUBE is ~1 425 ₽/unit of Group D that does not have to be spent.

**Decision rule: print a brow, test-fit it against a real tube, and see whether the case
alone gives the reveal.** Do not order copper to fix a plastic problem. Revisit only if
the test-fit fails.

## TS06-MAIN — one board for the whole clock (17.09.26)

The three-board electrical stack (inherited AlexGyver board + TS06-SEC + TS06-COLON) is
replaced by **one board carrying every tube, every driver, the Nano, the RTC and the 185 V
converter**, in two builds like the fascia: **TS06-MAIN** (surface-mount wherever a part
exists in that form) and **TS06-MAIN-THT**. Same outline, same netlist, same connectors;
one gets fabricated. The brief is `../Claude outputs/TS06-MAIN-handoff.md`.

**Decisions taken by the owner on 17.09.26**, answering the brief's open questions:

| Question | Decision |
|---|---|
| Power input | **12 V on the same 5.5 × 2.1 mm barrel jack the stock board uses, not 5 V**: the stock converter is an energy-limited stage good for ≈1 W and the full clock needs ≈3.5 W (see `../TERMINAL-06-measurements-PCB-GYVER-NETLIST.md`). An R-78E5.0-1.0 switching regulator feeds the 5 V rail. The Nano's USB is reachable through the left edge, for reflashing and for a PC time-set link; USB alone runs the logic with the tubes dark. |
| MCU | Arduino Nano on headers in **both** builds. |
| RTC | Bare DS3231SN with a CR2032 holder in the SMD build; the owner's **DS3231 mini module** (pins − NC C D +, the same header the stock board carries) on a 5-way header in the THT build. The one place the two netlists differ. |
| Tube positions | The reviewed coordinates, Gyver pitch included, unchanged. The board is sized for itself; the fascia is not a width constraint (it happens to be 176 mm too). |
| Anode chain | One series resistor per digit tube (the stock board has a single shared 10 kΩ) plus DNP bleed footprints on all six. 6k8 for the ИН-12s is a design value until bench gate 2. |
| Optos | Six TLP627 singles. |
| "m" LED | HL9 on the free D12 through its resistor, so always-on versus 12-hour-only is a firmware choice. |
| Backlight | Eight amber LEDs, the ИН-15 pair included. |
| Layers | Two. Vias budgeted, not hunted. |

**How it is built.** `tools/ts06main.py` is the netlist both builds share — every part,
pin and net, with the display chain, the AM/PM section and the colon carried over from the
inherited copper and SEC, and the converter redesigned: 12 V in, the same 220 µH / 31 kHz
boost clocked from D9, but through a TC4420 driver, with an LM393 watching the rail through
a 1.5 M / 20.5 k divider and holding the driver off whenever the rail is above the set-point
(152–252 V on the trimmer). `tools/mksch_main.py` draws it as a labelled netlist grouped by
function into `lib/TS06M.kicad_sym`; `tools/mkfp_main.py` adds the footprints (every land
pattern read out of KiCad 10's own libraries, back-mounted and pre-rotated as this repo does
it); `tools/mkpcb_main.py` places and, with `--route`, routes either build; `tools/bom_main.py`
writes each build's `bom.md`.

**Where things are.** The board is vertical in the plane the inherited tube board
occupied, tubes on the front, everything else on the back. World coordinates are the FreeCAD
assembly's; board local (x, y) = (world X, 100 − world Y), so the board runs from world Y 100
down to 4 — the extra height is below the tubes, behind the fascia, where the through-hole
build needs it. Three bands on the back: the logic band above the tube rings (Nano across the
top left with its USB 2.4 mm proud of the left edge, the converter, the two ИН-17 anode
switches, the AM/PM small parts above the ИН-15 rings), the tube band (bleed pairs inside the
ИН-12 rings, ИН-15 cathode switches inside their rings), and the power band below the LEDs
(the four ИН-12 anode switches under their tubes, the 12 V jack at the left edge, the
converter's control loop, the fascia cable at the bottom edge, the decoder, the RTC, the two
expanders under the ИН-15s).

**Checked.** Both placements pass `checkpcb.py` except three intended items — the Nano's USB
connector proud of the edge, and the two colon lamps' courtyards touching the M10 glass
courtyard by 0.3 mm at their measured positions — and `checkcopper.py --hv` finds no bare
pad pair inside the high-voltage clearance. Both schematics pass `checksch.py` with no
dangling pin, KiCad 10 loads them, and **KiCad's own netlist export agrees with the netlist
module net for net** (141 nets in the SMD build). `3d/Clock.FCStd` now carries the board
(`3d/TS06-MAIN.step`, KiCad's export) in the tube plane with the two inherited halves and
the colon board switched off.

**Routing, 18.09.26.** Three stages and a retry, and the ORDER is most of it. High voltage
first including the 185 V trunk, then GND as a tree while there is still room, then everything
else negotiated at once, then one more try alone at whatever was dropped. Five other orders were
tried and every one is worse; each is recorded beside its decision in `tools/mkpcb_main.py`.

The rest is the cost function, and it was rebuilt after the first routed board turned out to be
legal and badly routed at the same time — 476 vias, no grain at all, a ground pour in 292
islands, and every checker in this repo quiet. Ten rules were implemented, each switchable, each
run against a control; twenty-two configurations were measured. `../Claude outputs/TS06-routing-study.md`
has the table and the reasoning, including the two ideas of mine that turned out to be wrong.
What is kept: a face grain (F.Cu east-west, B.Cu north-south), a via priced honestly at 9 mm of
track instead of 2.5, a relaxation that lets a net off the grain when it keeps failing, two
passes of rip-up-and-reroute for length, and an exemption that frees any net with eight or more
pads from all of it. What is implemented and off, with numbers: compaction, bundling, the
return-path rule, T-junction discipline, the via lattice, history decay.

| | TS06-MAIN | TS06-MAIN-THT |
|---|---|---|
| Tracks / vias | 2852 / **339** (was 3047 / 476) | 2340 / **177** (was 2823 / 271) |
| Nets not connected | **0** (was 1) | **13**, unchanged |
| Copper | 8726 mm at 1.23× its floor | 7403 mm at 1.30× |
| Grain, front / back | **49 / 11**, **46 / 13** (was 33 / 25) | **44 / 14**, **43 / 13** (was 26 / 33) |
| GND through copper alone | 3 pieces; the pour closes one | **whole** |
| `checkmatch.py` | agrees, 141 nets | agrees, 140 nets |
| `checkcopper.py --hv` | **clean** | 87 items, all pads of the 13 split nets |

**The surface-mount build routes completely.** Every signal net is connected — the VT2 base that
used to be split is routed — and `checkcopper.py --hv` finds nothing at all. `checkpcb.py` still
reports the same three intended items as before: the Nano's USB proud of the edge and the two
colon lamps touching the M10 glass courtyard by 0.3 mm.

**Its one remaining defect is two ground pads,** and it is now understood. VT10.2 and VT11.2, the
emitters of two ИН-15 cathode switches, sit inside a socket ring and cannot be reached. The
ring's PADS are not the fence — they leave 1.9 to 2.5 mm between them and a 0.2 mm track between
two 185 V pads needs 1.4 — it is stage 1's twelve cathode TRACKS, which leave the ring through
those same gaps with a 0.6 mm halo each and never move.

Letting them out first works and costs too much, measured twice: all twelve in-ring GND pads
given a stub before the high voltage gives a whole ground and **24** signal nets overlapping;
only the two the high voltage actually walls in gives a ground in two pieces and **7** signal
nets lost. Seven signals for two grounds is a bad trade, so it is not made. Those two emitters
need a wire link, or the switches moved out of the ring — itself measured, and worse (3 nets
unplaced became 13). Widening the in-ring switch spread does not help either: the escape
corridor measures the same at 4.7, 5.2 and 5.6 mm, because the barrier is the tracks.

This defect was in every board this project has made. It was hidden by a stage-2 retry that
offered a stranded pad the three nearest GND pads **regardless of whether they were themselves
connected**: the two are 4.4 mm apart, each was offered the other, the connection succeeded and
both were counted saved. The retry now only anchors on pads that reach the hub, and the routing
log prints how many pieces the copper alone joins GND into before the pour is given any credit.

**The through-hole build is still not routable as placed.** The new rules improve its copper
markedly — 177 vias against 271, and a grain of 44 / 14 where it used to run more across than
along — but they do not touch its connectivity: 13 nets are split either way, including the I²C
pair, the backlight return and one cathode line. Through-hole pads block both faces, so there is
far less room. It is the alternative build and only one gets made, so this does not block the
surface-mount board. What it needs is a placement pass, not a router.

**And the router was not the main thing wrong.** `tools/placecheck.py` measures what a placement
costs before any routing: the Euclidean MST over each net's own pads, which no router can beat.
The Nano sits in a corner with 28 connections reaching across a 176 mm board, and the decoder
sits 40 mm above the row of tubes it drives, so each of its ten cathode lines pays that detour
twice. Sliding the Nano along the edge it is already pinned to — USB unchanged — is worth 7.4 %
of the floor, and moving the decoder onto the tube row beside it takes it to **16 %**. That is
five times what every routing rule put together achieved. Both positions collide with tube
sockets as they stand, so it needs a real placement pass.

`tools/boardsplit.py` prices the other way out, the one the inherited board took: a display board
and a driver board joined by **18 wires** — three power, four BCD, six ИН-12 anodes, SDA, SCL,
the backlight cathode and two spare Nano pins. `../Claude outputs/TS06-split-study.md` has the
curve and the case either way. It agrees with the placement finding: both say the decoder belongs
beside the tubes.

**The bench still owes** the items in `../knowledge/TERMINAL-06-measurements-TS06-MAIN-gates.txt`:
the stock stage's operating point, the sustaining voltages, the ИН-17 lead order, the ИН-15
pinouts, the pip projection, the mini module's battery, the adapter.

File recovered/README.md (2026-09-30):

# Recovered work of two agents lost on 30.09.26

Two of the orchestrator's agents went silent on 30.09.26 between 02:27 and 02:33 UTC. The platform
later reported them as "stopped by the user", but the owner stopped nothing. **The likely cause:** a
message from the owner reached the orchestrator as "[Request interrupted by user]" at about 02:28.
That interrupt ends the orchestrator's turn, and the platform stops the background agents with it.

The evidence:
* The viewer agent's last screenshot is timestamped 02:27:06.
* The layout agent's router wrote its last round at 02:33:26.
* The only agents lost were the two still running at that moment. Every other agent that night had
  finished earlier.

Both agents' work is kept here, in full, so a successor can pick it up.

## TS06-DRV rev B (the layout agent)
**Mission:** the driver board's revision B, all the review's open items:
* an independent over-voltage clamp;
* 0.8 mm at bare 185 V pads, as a KiCad rule;
* the USB back-feed diode and the input TVS;
* the fascia-input RC and pull-down;
* МЛТ-0,5 footprints;
* a real L1;
* the RTC's male header;
* keep-outs at the mounting holes;
* the silkscreen legends.

**Done:**
* `patches/0001`: the tools. The HV pad rule, the hole keep-outs and the DNP attribute.
* `patches/0002`: the rev B netlist and footprints. The OV clamp, the protection parts, МЛТ-0,5
  and L1.
* `patches/0003`: the recovered work in progress: `tools/mkpcb_drv.py` (+446/−93 lines) and the
  README, uncommitted when the agent was lost.

**Left unfinished:** the routing.
* Run r1 stalled at 5 nets sharing after 45 rounds.
* Run r2 was at 4 nets sharing after round 15: +5V, D8, GND and SCL. See `scratch/route-r*.log`.
* The congestion sits round J1, where the fascia link now carries the new 1 k + 10 nF on D7/D8 and
  1 M on A6.
* The agent was re-placing parts when it was lost. See `scratch/diag*.log`, `scratch/region.py`
  and `scratch/clamp.py`.

**To resume:**
1. Start a worktree from `pcb/kicad-boards`.
2. `git am recovered/drv-revb/patches/*.patch`.
3. Place, then route. The saved route no longer matches the netlist.

## Viewer v2 (the page agent)
**Mission:** rebuild the board viewer in three.js:
* camera buttons, with dragging that works;
* the assembled stack in its case, with an explode slider;
* an 18-step build and bring-up walkthrough;
* the schematic sections;
* the fascia variants A/W/R/F;
* a black mask with white silkscreen.

**Done:** the page and its build.
* `index.html` and `app.js` are the built page.
* `src/` is the source.
* `tools/` holds the exporters: `kicad_export.sh`, `glb2json.py`, `assembly.py`, `stl2gltf.py`,
  `kparts.py` and `sections.py`.
* `test/` holds its Playwright tests.
* `build.sh` rebuilds everything from the repo's boards. The built assets (about 26 MB) are not
  kept here.

**Left unfinished:** its last run of the final tests, and the rebuild from the latest boards. It was
built from f376a3b, before TS06-DISP rev B's silkscreen was merged.

## Lessons (also in agent-commons lessons.md)
* Interrupting the orchestrator's turn stops its background agents. So:
  * finish or checkpoint long runs before an interrupt;
  * a long agent commits work in progress at least every 30 minutes, so a loss costs at most 30
    minutes.
* An agent's report of "stopped by the user" isn't proof that the owner stopped it. Check the
  timeline.

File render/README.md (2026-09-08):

# -06 render toolkit

Generates every drawing in the concept-plate pages from millimetre dimensions. Pure Python
standard library — **no pip install, no dependencies**. Tested on Python 3.11; needs 3.6+
for f-strings.

## The three files

| File | What it is | Run it? |
|---|---|---|
| `tubes.py` | Shared primitives — the hand-authored wire-cathode glyph paths, the glow filter stack, the tube face, the knob / lever / button / hexmark. | No. Imported by the other two. |
| `render.py` | **Axonometric heroes** (3/4 views) and **general-arrangement sheets** (front + profile + plan, dimensioned). Self-contained. | Yes |
| `render2.py` | **Lit front elevations**, the **rear panel** and the **tube macro**. Imports `tubes` and `render`. | Yes |
| `render3.py` | **Night heroes** and the **rear three-quarter**. Imports `tubes` and `render`. | Yes |
| `render4.py` | **TERMINAL-06 extended set** — left 3/4, right profile, plan, exploded, fascia macro, scale sheet. Imports `tubes`, `render`, `render3`. | Yes |

Keep all five in the same folder.

## Running it

```bash
python3 render.py     # 8 files: svg-*-hero.svg, svg-*-ga.svg
python3 render2.py    # 6 files: v-*-front.svg, v-terminal-rear.svg, v-terminal-macro.svg
python3 render3.py    # 5 files: n-*-night.svg, n-terminal-rear34.svg
python3 render4.py    # 6 files: n-terminal-{left,profile,plan,exploded,fascia,scale}.svg
```

Both write `.svg` into **their own folder** (`OUT = os.path.dirname(__file__)`), print each
filename and its byte size, and overwrite silently. 14 files, ~740 KB total.

| Output | View |
|---|---|
| `svg-terminal-hero.svg` · `svg-mimi-hero.svg` · `svg-quadrant-hero.svg` · `svg-scaler-hero.svg` | 3/4 axonometric |
| `svg-terminal-ga.svg` · `svg-mimi-ga.svg` · `svg-quadrant-ga.svg` · `svg-scaler-ga.svg` | front + right profile + plan, with dimensions |
| `v-terminal-front.svg` · `v-mimi-front.svg` · `v-quadrant-front.svg` · `v-scaler-front.svg` | lit front elevation, 1:1, full silkscreen |
| `v-terminal-rear.svg` | rear panel — DC in, service USB, vent, HV warning |
| `v-terminal-macro.svg` | one ИН-12А at ×5 with callouts (listing slot 4) |
| `n-terminal-night.svg` · `n-mimi-night.svg` · `n-quadrant-night.svg` · `n-scaler-night.svg` | night 3/4 — tubes are the only light source |
| `n-terminal-rear34.svg` | rear three-quarter, night — DC in, service port, vent, HV triangle |
| `n-terminal-left.svg` | left three-quarter, lit — the side the hero hides |
| `n-terminal-profile.svg` | right profile, 1:1 orthographic, dimensioned |
| `n-terminal-plan.svg` | plan, 1:1 orthographic — plinth inset, tube pitch, the two gaps |
| `n-terminal-exploded.svg` | four layers on the vertical, captioned |
| `n-terminal-fascia.svg` | fascia detail ×2.6 — rotary at 32°/detent, levers, buttons |
| `n-terminal-scale.svg` | 1:1 beside a 146 × 71 phone and a ⌀80 × 95 mug |

## Fonts — read this before judging the output

The SVGs reference **IBM Plex Sans Condensed** and **IBM Plex Mono** by name. They are not
embedded. If those aren't installed on the machine viewing the file, every label silently
falls back to Arial Narrow / a default mono and the drawings look subtly wrong — wider
labels, collisions in the dial legend.

Install both (free, OFL): <https://github.com/IBM/plex/releases> or Google Fonts. In the
published plate pages this doesn't arise, because the page loads them from Google Fonts.

Digits inside the tubes are **not** type — they're vector paths, so they render identically
everywhere regardless of fonts.

## Viewing and rasterising

Open any `.svg` straight in a browser. For PNG:

```bash
# best quality, honours installed fonts
inkscape --export-type=png --export-width=2400 v-terminal-front.svg

# lighter alternative
rsvg-convert -w 2400 v-terminal-front.svg -o v-terminal-front.png

# no tools installed? headless Chrome works
chromium --headless --screenshot=out.png --window-size=2400,1400 v-terminal-front.svg
```

For Etsy, export the front elevations at **2000 px on the long edge or more** — the glow is
built from Gaussian blur filters and low resolution muddies it.

## Changing the design

All geometry is millimetres, declared as constants at the top of each product block.

**`render.py`** — world coordinates, **y up**, z into the screen.

```python
T_W, T_H, T_D, T_LEAN            = 237.0, 56.0, 104.0, 12.0   # base slab + front rake
T_PW, T_PH, T_PD, T_PX, T_PZ     = 213.0, 16.0, 46.0, 12.0, 30.0   # plinth: w, h, d, inset, setback
T_TUBES = [(24.5, 22, 24, "2"), ...]   # (centre_x, width, height, lit glyph)
```

Camera lives in each `*_hero()`: `Scene(yaw=29, pitch=10, scale=2.75)`. Lower `pitch` for a
flatter, more product-shot angle; `scale` is px per mm and only affects framing.

**`render2.py`** — screen coordinates, **y down** from the top of the object.

```python
TW, TBASE_H, TPL_H, TTUBE_H = 237.0, 56.0, 16.0, 24.0
TUBES = [(24.5, 22, 24, "2"), ...]
SCREENS = ["RUN", "TIME", "DISP", "AMB", "INFO", "DATE"]   # dial legend
```

**`tubes.py`** — the `GLYPH` dict holds one SVG path per cathode, authored in a 12 × 18 box,
y down. They are **stroked, never filled** (`stroke-linecap="round"`), because a nixie cathode
is a bent wire. To add a glyph, draw it in that box and add an entry. `tube_face()` takes
`digit_frac` (glyph height as a fraction of tube height), `ghost_op` (unlit cathode opacity),
`dim` (0–1 brightness) and `glyphset` (which cathodes exist in this tube).

**`render3.py`** — same world as `render.py` (y up), plus two things worth knowing.

`night(col, k, warm, warmth)` is the whole lighting model: take the daylight colour, multiply
it down by `NIGHT * k`, then bleed `warmth` of the glow colour into it. Every surface in every
night render is one call to that. Raise `NIGHT` to lift the whole set; change a face's `k` to
relight one panel.

`frag_on_face(sc, origin, frag)` drops a `tubes.tube_face()` fragment — glass, mesh, ghost
cathodes, the four-layer glow — onto an axonometric face, so the 3/4 views get the same tube
rendering the 1:1 elevations do. `origin` is the world point the fragment's **top-left** corner
lands on, which for a tube is `(x0, deck + height, z)`.

> **The y-flip trap.** The world is y-**up**; every `tube_face()` fragment is y-**down**. The
> helper passes `(0, -1, 0)` as the face's v vector to reconcile them. Get that sign wrong and
> every glyph renders vertically mirrored — and it is genuinely hard to spot, because a flipped
> 3 still looks like a 3 and a flipped A looks like a slightly odd A. Check a **4** or a **9**.

Note also that `glyph_path()` falls back to the `"8"` path for any character not in `GLYPH`,
silently. Cyrillic **Р** and **П** are their own entries now (U+0420 / U+041F) — they are *not*
the Latin lookalikes, and before they were added the AM/PM tube rendered a perfectly plausible
8. If a new symbol tube renders an 8 you did not ask for, that is why.

**`render4.py`** — two lessons are baked into this one, both worth knowing before you add
a view of your own.

*Do not use the axonometric camera for a plan or a profile.* `Scene` sorts faces by a depth
term that **grows with height**, so at a steep pitch the upper geometry sorts as *further
away* and the drawing silently inverts — the plan view came out as a bare case lid with
mirrored type on it. Elevations are built as true orthographic SVG instead, which is what
they should have been anyway: they are drawings, and a drawing is measurable.

*Captions are not silkscreen.* `text_on_face()` maps type onto a surface, which is right for
a wordmark on a panel and wrong for a label — on a horizontal plane it foreshortens into an
unreadable smear. `screen_label()` projects an anchor point and then writes plain
screen-space text, and it also pushes the text's far end into `sc.pts` so the viewBox
actually includes it. Without that last step a caption hangs off the edge of the sheet with
no warning, because `Scene` sizes its viewBox from geometry only.

One more, for any hand-built sheet: **those are screen-space, y down.** The detent-fan and
knob-pointer maths were copied from the world-space (y up) code and came out mirrored, with
the dial legend fanning below the knob instead of around it. Negate `cos` when you move
angle maths between the two.

### The one trap

**The two scripts each hold their own copy of the dimensions.** Change the plinth width in
`render.py` and the hero updates but the elevation doesn't — they will silently disagree.
This is the same class of error that put a 190 mm plinth under a 210 mm tube row in Rev E.

Until a shared `dims.py` exists: **change a number in both files, then regenerate both and
put the hero and the elevation side by side before trusting either.**

## Where the output goes

The plate pages inline these SVGs directly rather than linking them, so regenerating a file
does not update a published page — the SVG has to be re-injected and the page republished.
The pages that consume them:

- TERMINAL-06 concept plates → hero, GA, front, rear, macro
- MIMI-06 «KURO» → hero, GA, front
- QUADRANT → hero, GA, front
- SCALER-06 → hero, GA, front

## Provenance

Written for the TERMINAL-06 Rev E case revision, 02.09.2026. Supersedes nothing — the older
`terminal06-render-source.zip` toolchain (`front.py`, `dial.py`, `hero.py`) still describes
the **Rev C trench geometry** and has not been updated. Feed `dial.py` **32°**, the measured
detent angle, if you go back to it.

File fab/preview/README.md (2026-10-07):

# Pictures of the boards as ordered

Rendered by KiCad 10's own 3D renderer from the committed board files, as the fab would build them:
black solder mask, white silkscreen, ENIG (gold) where the mask is open. Front (top) views. Saved here
so that a product page can use them later; nothing in this folder is published.

| Picture | What it shows |
|---|---|
| `fascia-R-divider-top.png` | The fascia R (`PCB/TS06-FASCIA-rhythm`, rev B) with the Plates white print and the Divider gold, seen from the front: the six position names, MODE / FIELD / SUB nameplates, the dial drawn as its own resistor divider, the SUB rule, the lever ladder and the two key frames. 191.4 x 40 mm. |
| `three-boards-top.png` | The three boards one under the other, each labelled: TS06-DISP rev B (the tubes), TS06-DRV rev B (the driver) and the fascia R with the Divider gold. Same scale for all three. |

## Regenerate

From the repository root (KiCad 10 in Docker, or `KICAD_CLI`; needs Pillow):

```
python3 tools/fab_preview.py fab/preview                    # both pictures, the Divider gold
python3 tools/fab_preview.py fab/preview --gold ladder      # another gold (see fab/ORDER.md: only the divider is laid out for R)
```

`tools/fab_preview.py` builds the fascia's art board in a scratch directory with `tools/fascia_gold.py`
(nothing under `PCB/` is written) and renders each board with `tools/render_kicad.py`. A single board
can be rendered by hand, for example:

```
python3 tools/fascia_gold.py divider /tmp/fascia-R-divider.kicad_pcb --base R
python3 tools/render_kicad.py /tmp/fascia-R-divider.kicad_pcb fascia.png --side top --px-per-mm 12
```

Size limits kept by the script: at most 2400 px wide and 3 MB a file.

Each board is shown whole, with a 2 mm margin. `tools/render_kicad.py` frames a board from a rule that holds for the
fascia (191.4 x 40 mm) but not for TS06-DRV (191.4 x 100 mm), where KiCad draws about 9% larger than the rule says; the
three-board picture used to lose TS06-DRV's left and top edges because of it. `tools/fab_preview.py` now measures the
scale first (two white squares planted on a scratch copy are found in a test render) and frames the real render from
that. It needs numpy and scipy as well as Pillow.

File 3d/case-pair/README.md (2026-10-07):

# TS06 pair case, concept A

A parametric case for the through-hole pair, TS06-DISP riding on TS06-DRV. It is drawn around
the boards as they are in this repository. The brief is the case section of
`Claude outputs/TS06-pair-review.md`. It keeps Rev F's idea: two cheeks carry everything, and
nothing else is structure. The module (both boards) hangs from four bosses and lifts out
backwards as one piece. A brow, a top plate, a trench frame, a base and a rear panel close the
box between the cheeks.

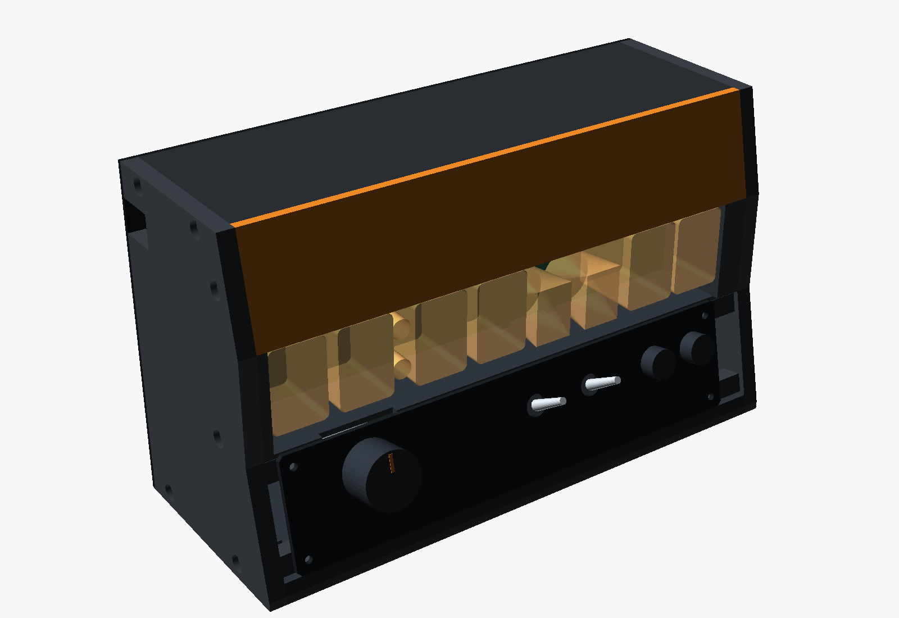
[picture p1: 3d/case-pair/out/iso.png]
front


| File | What it is |
|---|---|
| `case_pair.py` | The generator. It reads the boards, holds every dimension with its source, derives the geometry, runs the checks, and writes `params.scad`, `checks.md` and the drawings. |
| `case.scad` | The OpenSCAD model. It includes `params.scad` and derives the same numbers. It echoes them so they can be compared with the generator's (`--render` does this). |
| `params.scad` | Generated. Every dimension is a named variable with its kind and source, plus the board data in world coordinates. |
| `boards.json` | Generated by `--extract`. Holes, parts and courtyards of TS06-DISP, TS06-DRV and TS06-FASCIA in world coordinates, with hashes of the files they came from. |
| `checks.md` | Generated. The envelope, every interference check, every screw, and every dimension with its source. |
| `out/front.svg`, `section.svg`, `plan.svg`, `exploded.svg` | Dimensioned drawings at 1:1: front elevation, side section through M10 with the ±10° sight lines and every cheek screw, plan section through the jack axis, exploded side view with the screws per part. |
| `out/*.png` | OpenSCAD views: `iso`, `iso_rear`, `front`, `exploded`, `module`. |
| `out/*.stl` | Printable parts in world position: `cheek_l`, `cheek_r`, `brow`, `top`, `trench`, `base`, `rear`, and `fascia_blank` (the PETG fit proxy that cad-component-library §5 asks for). `fascia_frame` is variant D's (below). |

**Frame.** X and Y are the FreeCAD assembly's frame, the one the review uses. X runs across the
front from the clock's left, where TS06-DISP's x = 0. Y points up: TS06-DISP's top edge is at
78 and TS06-DRV's bottom edge is at 4. Z is depth: 0 at the ИН-12 glass front, positive toward
the back. OpenSCAD maps x = X, y = Z, z = Y, so the clock faces -y.

**Where the board numbers come from.** `tools/mkpcb_disp.py` and `tools/mkpcb_drv.py` are
imported as modules. That runs their placement and hand-laid copper, with no router and no file
written; the same generators write the committed `PCB/TS06-DISP` and `PCB/TS06-DRV` boards.
`TS06-FASCIA.kicad_pcb` is parsed directly, and `FASCIA_PCB=<board>` puts another fascia in its
place. Parts are keyed by reference; each TS06-DRV part also carries whether any of its pads is on
a 185 V net (the generator's own net classes) and the height its footprint's descr states. A
footprint the height table does not know takes that height, so a new L1 footprint is picked up,
not refused.

## Envelope: 204.4 W x 122.8 H x 83.6 D (mm, outside)

It was 204.4 x 120.3 x 83.6. The case review's end blocks (below) put an 8 mm block under the
top plate at the rear, above TS06-DRV's top edge, so the case is 2.5 mm taller.

**7 October 2026, fascia R rev B: the fascia's J1 is upright.** The wires leave the plug straight back, so the
7.3 mm the side-entry bend cost is gone: the floor is at Y -4.5 (was -7.3) and the case is **204.4 x 120.0 x 81.0**
(2.8 mm lower, 0.55 mm shorter at the toe). What holds the floor at -4.5 now is the base's end blocks (8 mm tall on
the floor), which must clear TS06-DRV's bottom edge by 0.5 as the module slides out (checks.md 7 and 8); the lead
no longer sets it. The depth, width and what-if tables below predate this and some of the depths (83.6, the 81.6 of
`PCB/README.md`); `checks.md`, regenerated, has the current ones. `PCB/TS06-FASCIA-rhythm/J1-UPRIGHT.md` has the study.

| Width | mm | Source |
|---|---|---|
| Boards | 191.4 | `mkpcb_disp.W`, `mkpcb_drv.W` (widened from 176 for the ИН-17 pair's 20.5 mm) |
| Clearance, 2 x 0.5 | 1.0 | review, envelope |
| Cheeks, 2 x 6 | 12.0 | review, envelope |
| **Outside** | **204.4** | |

| Depth, front to back | mm | Source |
|---|---|---|
| Kick-strip toe to the face plane | 9.8 (9.25 since rev B) | the 12° rake (spec §6) run down to the floor |
| Glass recess behind the face | 1.0 | design: a knock lands on the case, not the glass |
| ИН-12 glass to TS06-DISP's front face | 30.0 | envD 25.5 (`3d/IN12.FCStd`) + socket seat 4.5 (**assumed**, review "≈ 30") |
| TS06-DISP | 1.6 | pcbkit |
| Stack gap | 11.0 | PBS 8.5 + PLS body 2.5 (`bom.md`); review finding 1: measure them |
| TS06-DRV | 1.6 | pcbkit |
| Tallest part, U13 (DS3231 mini standing) | 22.0 | review finding 6 |
| Air in front of the rear panel | 5.0 | review, envelope |
| Rear panel, FR4 blank | 1.6 | review suggestion 2 |
| **Outside** | **83.6** | glass front to the rear panel is 71.2 (review: 65–72) |

| Height, bottom to top | mm | Source |
|---|---|---|
| Base | 3.0 | design |
| Floor to TS06-DRV's bottom edge | 8.5 (was 11.3) | 4.0 in the FreeCAD frame, + 4.5 for the base's end blocks (below); the fascia lead no longer sets it (was + 7.3) |
| TS06-DRV | 100.0 | `mkpcb_drv.H` (Y 4 to 104) |
| Top clearance | 5.5 | 0.5 for the module to slide + an 8 mm rear block − the 3 mm plate (was the review's 3) |
| Top plate | 3.0 | design |
| **Outside** | **120.0** (was 122.8) | inside, floor to top plate: 114.0 (review: ~106) |

The front face, bottom up: kick strip 4.4 (7.2 before rev B) · TS06-FASCIA 39.1 (40 along the 12° rake) · trench
window 36.4 · brow 37.1. The trench window is 179.0 wide (X 3.0–182.0).

What-ifs are one command each (see "Regenerate"):

| What changes | Outside W x H x D |
|---|---|
| This concept | 204.4 x 122.8 x 83.6 |
| U13, C7 and VT21 laid down (review finding 6) | 204.4 x 122.8 x 78.2 |
| Tubes soldered straight into the board, no socket seat (`IN12_SEAT=0`) | 204.4 x 122.8 x 79.1 |
| 7.0 mm PBS instead of 8.5 (`PBS_H=7.0`) | 204.4 x 122.8 x 82.1 |
| The floor at Y -1.5 (needs the base's end blocks cut to 8 mm tall counting the 3 mm base; not drawn): 3.0 mm lower again | about 204.4 x 117.0 (estimated, not run) |
| Variant D, the fascia frame (`FASCIA_FRAME=1`) | 204.4 x 122.8 x 83.6 |

## Review suggestions implemented

1. **Cheeks and boards.** Two 6 mm cheeks. TS06-DRV's H6 and H8 go to the left cheek (world X 3.5;
   Y 7.5 and 81.5), and H5 and H7 to the right (X 187.9; Y 7.5 and 100.5). Each lands on an 8 mm
   boss with an M3 heat-set insert, in front of TS06-DRV. The display rides on its four 11 mm
   standoffs, so the pair lifts out as one module.
2. **The rear panel is a board.** It is a 1.6 mm FR4 blank. Seven 2.0 mm vent slots sit over the
   logic side (X 6.9–35.9, Y 85–100, over the Nano), and the panel carries the 12 V / 185 V /
   "unplug, wait 15 s" label. It is fixed along its long edges (below).
3. **Connector openings.**
   - DC jack: a Ø9 hole through, and a Ø14 counterbore **from the outside** that leaves a 1.5 mm
     web. The plug engages 7.2 mm. The review's "pocket from inside" would leave the outer face
     where it is, and the plug would engage only 2.7 mm.
   - USB: a 12 x 9 slot, **open to the cheek's rear edge**. The mini-B receptacle sits 1.9 mm
     inside the cheek, so a closed window would trap the module.
4. **Brow and trench.**
   - The soffit is 0.8 mm above the tall glass. Behind the ИН-17 pair a valance rib comes down to
     Y 74.0, the "top 4 mm" of the review, and hides XP12. Over the ИН-12s and ИН-15s the rib
     cannot be there: those tubes would not come out past it.
   - The left trench wall is at X 3.0 and hides XP11. The right wall is at X 182.035: ИН-15А's
     glass plus the +0.4 allowance plus 0.5. It hides the H4 screw and XP12's last pins (X 183.55).
   - A sill at Y 39.0 hides XP21–25. That is the review's "≥ 38", kept under the ИН-17 LEDs.
   - The brow face is safety orange (spec §6); the top plate behind it is a separate part, black
     like the chassis.
5. **Fascia.**
   - The fascia is tied to the cheeks with four M2.5 bosses at its real holes. It is centred under
     the tube row (`FASCIA_X0` 4.305, X 4.3–180.3): on the middle of H10 and ИН-15А, X 92.3, not
     on the boards' middle, 95.7. TS06-DISP's margins are 3.5 mm left of the glass and 10.3 right.
   - The fascia lead runs from DRV J1 (top entry, X 44–54, Y 9) down to the floor, diagonally
     across it, and up into the fascia's J1 at X 156.3.
6. **Heat.** Top-of-panel vents only, as the review says; over the logic, not over the 185 V
   converter.
7. **Service.** Take the rear panel off (6 screws) and the module screws out (4). Draw the module
   back, unplug DRV J1 from below, and lift it out.

## Case review (30.09.26): what changed

- **F7, fixings.** The cheek's M3 holes used to land on the edges of 3 mm plates (the top bar at
  Y 108.5, the base at −8.8), and the M3 x 8 into the 3.5 mm left trench wall reached X 3.5,
  0.025 mm from H10's glass (3.475). Every cheek screw now goes into a heat-set insert in an end
  block of at least 8 mm on the part it holds:
  - base: 8 x 11 x 8 blocks on the floor at each cheek, front (Z 10) and rear (Z 59.2);
  - trench: 8 x 8 blocks under H10's and ИН-15А's glass, through the sill (Y 36.7–44.7, 1.0 below
    the glass), where the wall is too thin for an insert;
  - brow: 8 x 8 blocks behind the face at Y 93.5;
  - top plate: 8 x 8 blocks at the front (Z 20) and the rear (Z 59.2), and a full-width 8 mm lip
    at the rear. That lip sits above TS06-DRV's top edge, which is why the case grew 2.5 mm.

  The trench screw now stays 3.5 mm from H10's glass; check 10 measures every screw's whole shank
  against the glass and the boards, and none comes within 2.5 mm. Screw lengths are on
  `section.svg` and `exploded.svg`, and in the table below.
- **F8, lead-ins.** 45° x 3 mm lead-ins on the rear edges the module passes within 1 mm: the
  soffit's (0.8 over the tall glass; the soffit ends in a 2 mm lip that carries it), the left trench
  wall's inner edge (0.475 from H10), and the sill's, only at X 105.7–111.5 and 126.2–132.0 where
  HL5 and HL6's flanges pass 0.59 over it. A full-width sill lead-in would let XP21–25's joints be
  seen from about 20° to 52° above; these stay 2.65 mm clear of the pads. The new trench blocks'
  rear top edges have one too. What they cost in sight lines: XP11's joints now show from the
  right past 7.8° (was 28.8°), only through H10's glass; TS06-DRV's front face at Y 95 shows from
  48–52° below, through the soffit's lead-in.
- **F9, printed spacing, FR4 holes.** The printed crossmembers set the 192.4 mm between the
  cheeks; at 0.4% shrink they come out 0.77 mm short, and TS06-DRV's H5–H8 float only 0.1. So:
  **screw the module in first, so the DRV locates the cheeks**, then tighten the crossmember screws;
  scale the crossmembers (brow, top plate, trench, base, frame) by +0.4% in X in the slicer, or by
  whatever a 150 mm test bar in the same filament says. The FR4 rear panel's holes are slotted
  ±0.6 along X. The crossmembers themselves are held by screws along X through the cheeks, which a
  slot cannot float; the module-first order and the scale do that job.
- **m1, rotary.** `ROTARY_D` 25.00, from `knowledge/TERMINAL-06-spec.txt` §6, MEASURE BEFORE
  ORDERING PANELS, which supersedes the withdrawn 26.94. `ROTARY_DEPTH` 22: the lugs sit at least
  11.3 behind the fascia and are 10 long. The sill notch is re-derived: it steps back to Z 3.55 (was
  8.21), over X 20.8–47.8, leaving a 2.5 mm slot behind the fascia's top edge (was 7.2).
- **m4, rear panel.** Six M2.5 x 6: three along the bottom into the base's rear lip and three
  along the top into the top plate's, at X 3.5, 95.7 and 187.9. Its longest free edge is 92.2 mm
  (was 198.4). None go into the cheeks' 6 mm rear edges: an M2.5 insert (Ø3.5) there has 1.25 mm
  of wall. In the lips it has 2.25. The vents moved from X 100–130, over VT21, C7, VD1 and R62, to
  X 6.9–35.9 over the Nano; no 185 V part is within 5 mm of them.
- **m5, top plate.** A separate part, black; the brow face stays safety orange.
- **n1.** `LEAD_LEN` 190 (the BOM's 180–200): 51 mm of slack, was 11. Every output regenerated.
  Stale text fixed: the generator's docstring (TS06-DRV is not "the older 100 x 70 driver half"),
  the front elevation's fascia registration note and label, the plan's fascia outline, the BOM
  line on case screws (it now lists all four, H5–H8).

## Screws

| Screw | Qty | Holds | Into |
|---|---|---|---|
| M3 x 8, low head (DIN 7984), from a 2 mm counterbore | 4 | base | inserts in its end blocks, front and rear |
| M3 x 8, low head | 2 | trench (sill and walls) | the blocks under H10 and ИН-15А |
| M3 x 8, low head | 2 | brow | its end blocks |
| M3 x 8, low head | 4 | top plate | its end blocks, front and rear |
| M3 x 8 + nylon washer | 4 | the module (H5–H8) | cheek bosses, from behind TS06-DRV |
| M2.5 x 6 | 4 | TS06-FASCIA | cheek bosses |
| M2.5 x 6 | 6 | rear panel (holes slotted ±0.6 in X) | the base's and the top plate's rear lips |
| M3 x 6 | 8 | TS06-DISP to TS06-DRV | 11 mm standoffs (`PCB/TS06-DISP/bom.md`) |

Inserts: 12 x M3 (5.7 long, Ø4.0 hole), 10 x M2.5 (4 long, Ø3.5 hole), plus 4 x M3 in the module
bosses. Variant D: no fascia bosses on the cheeks; add 2 x M3 x 8 into the frame, 4 x M2.5 x 6
for the panel and 2 x M2.5 x 6 countersunk ties down through the sill. Clearances to glass and
boards per screw are in `checks.md`, "Screws".

**Assembly order.** Cheeks and crossmembers loosely together; the module in and screwed down, so
TS06-DRV sets the cheeks' spacing; then the crossmember screws; the rear panel last.

## Variant D: the fascia frame (`FASCIA_FRAME=1`, off by default)

The owner has not chosen a fascia variant, so the fascia stays as it is and the frame is a switch.
With it on, a printed frame sits between the cheeks, raked 12°. Its pocket continues the trench
walls (X 3.0–182.035) and takes a 179 x 40 panel in a rabbet: a 2 mm ledge behind its sides and
bottom, a top rail under the sill, and two ribs behind its middle, at X 71.8 and 134.7, in the
widest gaps between the controls. The panel screws into four bosses: two over the ribs at the
top, two at its bottom corners. Each cheek screws into an end block; the sill bears on the top
rail and is screwed down into the rib heads. It replaces the four bosses cantilevered from the
cheeks. The frame is cut over the rotary and over the fascia's J1. There is no 179 board yet;
the 176 board stands in, at its own X 4.3–180.3, marked "176 STAND-IN" in the views; its holes do
not meet the frame's.

| Against today's mounting | Today (cheek bosses) | Variant D |
|---|---|---|
| Boss vs R5's courtyard | −1.20 mm, on the pad (**fail**) | 1.86 mm to the bottom-left boss (ok) |
| SW5 (КМД1) vs the top-right fixing | 1.22 / 2.62 mm from the hole, by orientation (**tight**) | no fixing there; 1.04 / 2.62 mm to the frame's top rail (ok) |
| Open slots beside the fascia | 4.80 mm left, 11.59 right; TS06-DRV shows (note) | 179 panel: 0.02 a side; 176 stand-in: 1.30 / 1.73, the ledge behind both (ok) |
| The 179 panel's fit in the pocket | – | 0.02 a side (**tight**): make the board 178.6, or ease the pocket 0.2 a side |
| Sill | held at its ends | also tied along its front edge |
| Envelope | 204.4 x 122.8 x 83.6 | the same |

## Interference results

Full table: `checks.md`. What does not simply pass:

| | Result |
|---|---|
| Rear panel vs parts | U13 is 5.0 clear, C7 7.0, VT21 8.0, the Nano 10.4 (16.6 tall, not the review's ~15), and L1 11.0 (16 tall per its footprint, not 12–14). |
| Jack engagement | Plain 6 mm cheek: 2.7 mm (**fail**). Outside counterbore: 7.2 mm (ok). The review's inside pocket: 2.7 mm (**fail**). |
| Brow at 10° from above | The digits stay visible for any cathode depth, up to 12.6° for the rearmost one. The glass top shows only for its first 3.6 of 25.5 mm; the brow takes the dome band, as spec §6's "brow reveal" describes. |
| What the brow hides | XP12 over the ИН-17s is hidden down to 43.6° below. Over the ИН-15s it shows only through the 0.8 mm slot above the glass (±0.8°), or through the glass from below. TS06-DRV's top band is hidden within ±47°. XP21–25 are hidden within ±60°. |
| Left trench wall vs H10 glass | 0.475 mm nominal, 0.075 mm with the library's +0.4 glass allowance (**tight**; the trench coupon settles it). A lead-in guides the glass past it. |
| Sill vs ИН-17 LEDs | 0.59 mm (**tight**), with a lead-in under them. |
| Right trench wall vs ИН-15А glass | 0.9 mm nominal, 0.5 mm with the +0.4 glass allowance (ok). |
| SR25 rotary vs sill | The rotary (Ø25.00, 22 deep) comes 1.5 mm below the fascia's top edge. The sill steps back to Z 3.55 over X 20.8–47.8, which leaves a 2.5 mm slot behind the fascia's top edge (**tight**). |
| Fascia lead vs floor | Fascia R rev B's J1 is upright: the plug stands 9.5 off the back (assumed) and the wires leave straight back over its pin row, 6.8 above the FreeCAD Y 0. The lead goes to the floor on a 45° slope between two R3 bends. The floor is at **Y -4.5** (was -7.3 with the side-entry J1), held there by the base's end blocks, 0.5 mm under TS06-DRV's bottom edge. |
| Fascia plug vs the КМД1 bodies and the kick strip | 4.3 mm to the nearest КМД1 body (assumed 20 deep), 3.25 mm from the plug's courtyard to the fascia's bottom edge (the old side-entry plug stood below it, 0.5 mm from the strip: tight). |
| КМД1 (SW5) vs the fascia's top-right hole | 1.2 or 2.6 mm from the hole centre, depending on how the body is turned (**tight**). Variant D removes it. |
| Fascia boss vs R5 | −1.2 mm to R5's courtyard: the boss lands on R5's pad (**fail**). Trim the boss, move the hole, or take variant D (1.9 mm clear). |
| ИН-17 pair | Centres 20.5 apart against Ø20 stems: 0.5 mm stem to stem, 2.2 mm to the glass either side (**tight**). |

## Still assumed

- The socket seat of 4.5 mm (the ИН-12 glass front 30 in front of TS06-DISP).
- PBS 8.5 and PLS 2.5 (review finding 1).
- Part heights: U13 22, C7 20, VT21 19; the jack body 11 with its axis 6.5; F1, U14, the
  trimmer, discs and DIP sockets.
- A 9.5 mm 5.5/2.1 barrel whose nose is Ø10, needing 7 mm of engagement.
- The mini-B receptacle at 7.7 x 4.0, and its overmould at 11 x 8.
- The fascia lead's geometry: the upright header 6.0 high (inferred: the 6.0 of the through-hole B6B-PH-K's STEP
  and JST's listing; the SM4-TB datasheet was not readable), the mated PHR-6 9.5 off the fascia's back (the same
  as DRV J1's), a 45° slope to the floor, and a bend radius of 3.
- The control bodies behind the fascia: МТ1 30 deep, КМД1 20 deep. The КМД1's orientation is
  not known. (The rotary's 25.00 x 22 is now from the spec.)
- The LED flange of Ø3.8, the pin tails of 1.5, and low screw heads of 2.0.
- Heat-set inserts: M3 Ø4.0 x 5.7, M2.5 Ø3.5 x 4; PETG shrink 0.4%; a 0.8 mm nylon washer.
- The fascia's registration in X: centred under the tube row here; the FreeCAD assembly has it elsewhere (review 5).
- Variant D: the 179 board's layout. The ribs and the panel's holes are placed against the 176
  board's controls and back-side parts; the new board has to leave them free.

## Regenerate

```
python3 3d/case-pair/case_pair.py --extract   # re-read the boards (imports tools/, writes boards.json only)
python3 3d/case-pair/case_pair.py             # params.scad, checks.md, out/*.svg
python3 3d/case-pair/case_pair.py --render    # + out/*.stl and out/*.png (OpenSCAD 2021.01, xvfb-run)
python3 3d/case-pair/case_pair.py IN12_SEAT=0 # what-if: prints the envelope, writes nothing
openscad -D 'PART="cheek_r"' -o cheek_r.stl 3d/case-pair/case.scad
openscad -D FASCIA_FRAME=1 -D 'PART="cheek_l"' -o cheek_l.stl 3d/case-pair/case.scad   # variant D's cheeks
```

The generator needs only Python 3's standard library. OpenSCAD comes from apt
(`apt-get install openscad`). The PNG views need an X server, so `--render` wraps them in
`xvfb-run`. The `--render` step also checks that `case.scad` derives the same numbers as the
generator, and prints `ok` or `MISMATCH` for each. Variant D is scored in `checks.md` section 12
on every run, whatever `FASCIA_FRAME` is set to.

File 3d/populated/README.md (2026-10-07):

# TS06 boards with every component drawn

Populated renders of the three TS06 boards (TS06-DISP, TS06-DRV and the fascia **R**, `PCB/TS06-FASCIA-rhythm`),
the three together as they stand in the case, the GLBs the product page's 3D view can load, the fit table made
from the placed models, and everything that regenerates them. Nothing under `PCB/` or `fab/` was edited: the
models are attached to a scratch copy of each board at render time (`tools/models3d.json`).

**The fascia is drawn as it is ordered**: R with the Plates white print and the **Divider gold** (`fab/ORDER.md`),
not the committed board with its plain silk. The committed `PCB/TS06-FASCIA-rhythm` carries no gold; `tools/fascia_gold.py
divider OUT --base R` builds the art board in a scratch directory (the board `tools/mkfab.sh` plots), and the render
reads that, with the same model map, so the controls keep their bodies. The option is `--gold VARIANT` (`none` is the
committed board; `divider` is the default of `tools/populated_all.sh`; the other three golds are laid out for the
narrower fascia A and stop on their own checks on R).

Everything below is regenerated by one command, `tools/populated_all.sh` (about 8 minutes: KiCad 10 in Docker,
then headless Chromium). Each picture's own command is in the tables.

## Pictures

All PNGs are transparent, trimmed to the board, at most 2400 px wide and under 3 MB.

| File | Shows | Command |
|---|---|---|
| `TS06-stack-front.png` | The assembled stack seen from the front: TS06-DISP (tubes, lamps, LEDs) in front of TS06-DRV, the fascia R (with its Plates print and Divider gold) in front of both, placed from `3d/case-pair/case_pair.py`'s geometry. The gold lines are real geometry in the fascia's GLB (see below); this scene gives the metallic gold a diffuse lean so it reads as gold and not as the pale cream a mirror-metal gives in a dim room | `node 3d/populated/stack/render_stack.mjs 3d/populated/stack.json 3d/populated 3d/populated front` |
| `TS06-stack-iso.png` | The same, from the front right and above | `... render_stack.mjs ... iso` |
| `TS06-DISP-top.png` `-iso.png` `-bottom.png` | The display board: six ИН-12/15 on their socket contacts, two ИН-17 on wire leads (the glass 19.72 mm long, its pip under it), the two ИНС-1 colon lamps, nine LEDs; bottom = the face that meets TS06-DRV, with the XP headers on their pads | `python3 tools/render_populated.py TS06-DISP 3d/populated` |
| `TS06-DRV-top.png` `-iso.png` `-bottom.png` | The driver board: 14 DIP chips in their sockets, the Nano on its PBS strips, the RTC module on its header, the choke L1, the МЛТ resistors, the fuse; bottom = the display-facing face, the PBS strips on their pads | `python3 tools/render_populated.py TS06-DRV 3d/populated` |
| `TS06-FASCIA-rhythm-top.png` `-iso.png` `-bottom.png` | The fascia R **as ordered, with the Plates print (white names, the MODE / FIELD / SUB nameplates, hairlines) and the Divider gold** (the dial's six taps as pads with a resistor between each pair, the FIELD / SUB rule, the divider chain, the - and + frames): the dial (SR25), two МТ1 levers and two КМД1 buttons with their bodies, the bushings in the panel holes; bottom = the back, with the bodies, the eight 1206 resistors and the JST header. KiCad draws the ENIG gold yellow | `python3 tools/render_populated.py TS06-FASCIA-rhythm 3d/populated --gold divider` |
| `before/TS06-*-iso.png` | Today's bare render of each board (only the models the boards carry themselves), same camera: the "before" half of the review pairs | `python3 tools/render_populated.py TS06-DRV 3d/populated/before --views iso --no-glb --bare` |

## 3D files

| File | What | Size |
|---|---|---|
| `TS06-DISP-populated.glb` | the populated display board | 6.0 MB (5.7 MiB) |
| `TS06-DRV-populated.glb` | the populated driver board | 14.0 MB (13.4 MiB) |
| `TS06-FASCIA-rhythm-populated.glb` | the populated fascia R, with its Plates print and the Divider gold. The gold is graphic lines on F.Cu under openings in the mask; KiCad writes copper graphics only with `--include-tracks`, so `--gold` exports this GLB with the copper (without it the mask is open over bare FR4 and the gold is not in the file) | 1.24 MB (1.19 MiB) |
| `stack.json` | where each board stands in the case: a 4x4 matrix per board, the case numbers the fit table uses; `fascia_gold` names the gold of the fascia it was made for | small |

The GLBs of TS06-DISP and TS06-DRV are exported with `--fuse-shapes` and **without the copper tracks** (they lie under the black mask; pads, silk,
mask and every part are in). TS06-DRV with tracks and fused shapes is 15.7 MB (15.0 MiB), and 19.6 MB without
`--fuse-shapes`, so the tracks stay out to keep each file under 15 MB; `--glb-tracks` puts them back.
The fascia R's GLB is the exception: it is exported **with** the copper, because its gold is copper graphics that KiCad writes only then (the file grows from 0.64 to 1.19 MiB; 953 copper pieces under the mask openings).

Frame of a board's GLB: KiCad's: metres, x right, y up out of the board, z = the board's y (down the page); the
board's back face at y = 0, its component face at y = thickness (1.6 mm; fascia 2.0 mm). To stack them in three.js:
load each GLB, `scene.scale.setScalar(1000)` (to millimetres), and put the group under
`new Matrix4().set(...stack.matrix["TS06-DISP" | "TS06-DRV" | "fascia"])`. The stack frame is X across the front from
the clock's left, Y up, Z towards the viewer, the ИН-12 glass front at Z = 0.
`stack/stack.html` + `stack/render_stack.mjs` do exactly that (three.js r186 vendored in `stack/vendor/three`, MIT).

## The fit table

`fit-table.md` (and `fit-table.json`): per board and side, the tallest parts as drawn against the space
`case_pair.py` gives. Command: `python3 tools/fit_table.py 3d/populated 3d/populated/fit-table.md 3d/populated/fit-table.json --gold divider`
(27 PASS, 8 TIGHT, 0 FAIL). `tools/stack_frame.py` and `tools/fit_table.py` read the fascia board for its outline, holes and
parts; with `--gold divider` they read the art board, which has the same ones (the gold and the print change no footprint, hole
or edge: `fascia_gold.py` asserts it), so the numbers are the same as for the committed board, and the files now say which board
they were made for.
`python3 3d/case-pair/case_pair.py --extract` still ends `checks: 3 FAIL, 7 NOTE, 62 OK, 9 TIGHT`, the same three
FAILs as before: the two rejected jack openings and the fascia boss on R5 (variant A). Running it changes only a
stale source hash in `3d/case-pair/boards.json` (`tools/mkpcb_disp.py` was committed after the last extract); the
geometry is identical, and that file was left as committed.

The control holes in the table are read from the fascia board, not typed: from the board that is ordered, every control hole opened 0.4 mm
(+0.29 a side; the owner's pick, `fab/HOLES-VARIANT.md`). Under the table is the same three bushing rows for the committed holes (8.8 / 8.0,
+0.09 a side, the zip that was not ordered): shown beside the table, not in its tally, and in `fit-table.json` under `holes_committed`, not in its rows.
`--in17-seat MM` seats the ИН-17 glass at another height than the case model's 10.28 (next section); without it the table is the case model's seat. The ИН-17's three rows (the glass front against the window plane, the lead against the ТУ's 8 mm and the tube's 35 mm, the nearest part) are in the table at whatever seat.
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

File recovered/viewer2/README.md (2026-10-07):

# TS06 board viewer v2: the source of the product page

The page "TS06 Board Viewer v2": a three.js viewer of the boards, the case and the fascia, a build and bring-up
stepper, the circuit sections, the front panel view, and the **Order** view. This folder is its whole source. A fresh
clone and one command build it; nothing is read from a session's scratch folder any more.

```
bash recovered/viewer2/build.sh                    # builds recovered/viewer2/site/ (git-ignored), about 2 minutes
OUT=/some/dir bash recovered/viewer2/build.sh      # builds into /some/dir/site instead, nothing written in the checkout
node recovered/viewer2/test/run.mjs                # the Playwright checks (SITE=... if you built elsewhere)
```
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

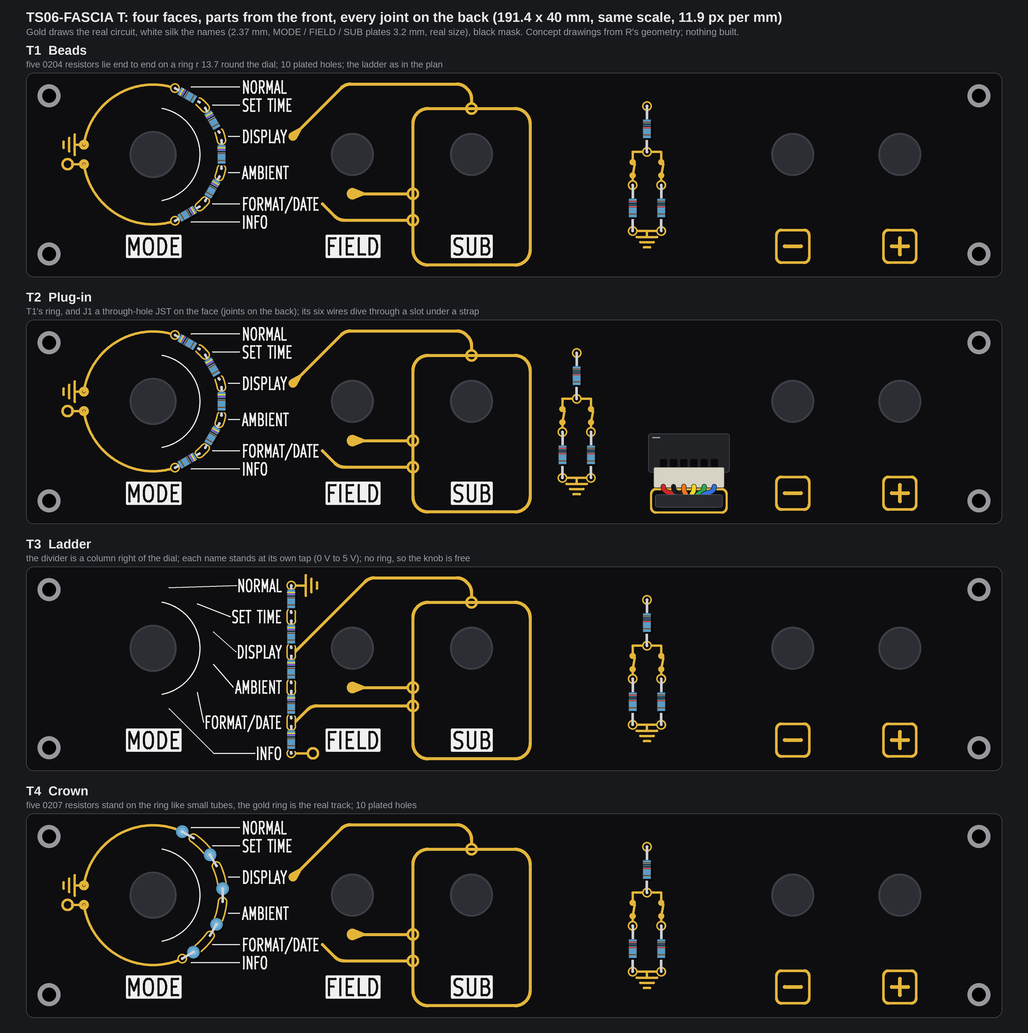
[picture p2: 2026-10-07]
PCB/TS06-FASCIA-T-concepts/contact-sheet.png

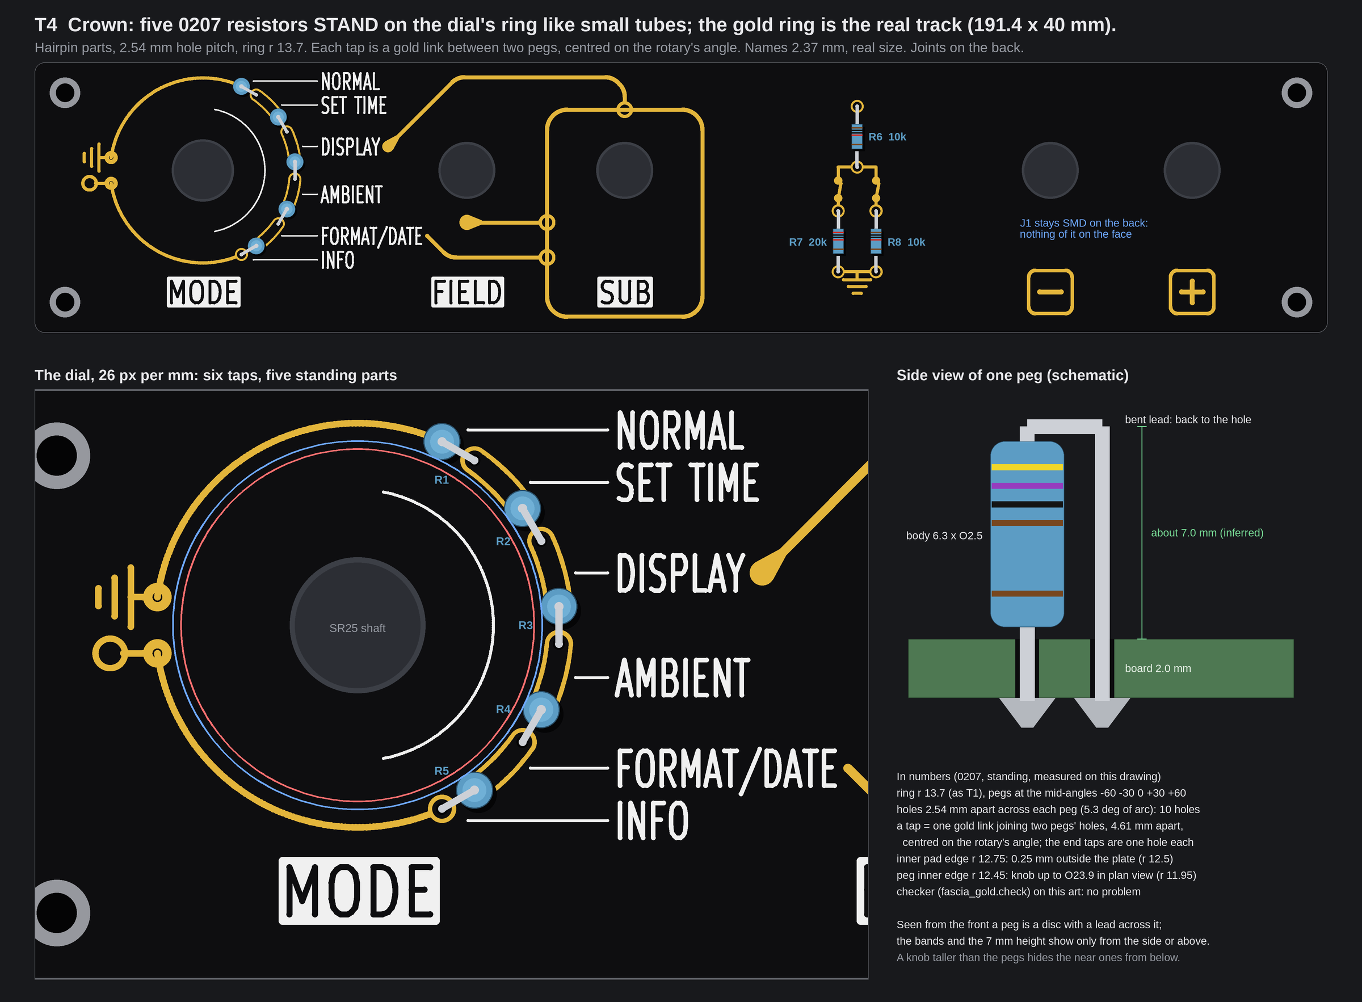
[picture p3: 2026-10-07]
PCB/TS06-FASCIA-T-concepts/T4-crown.png

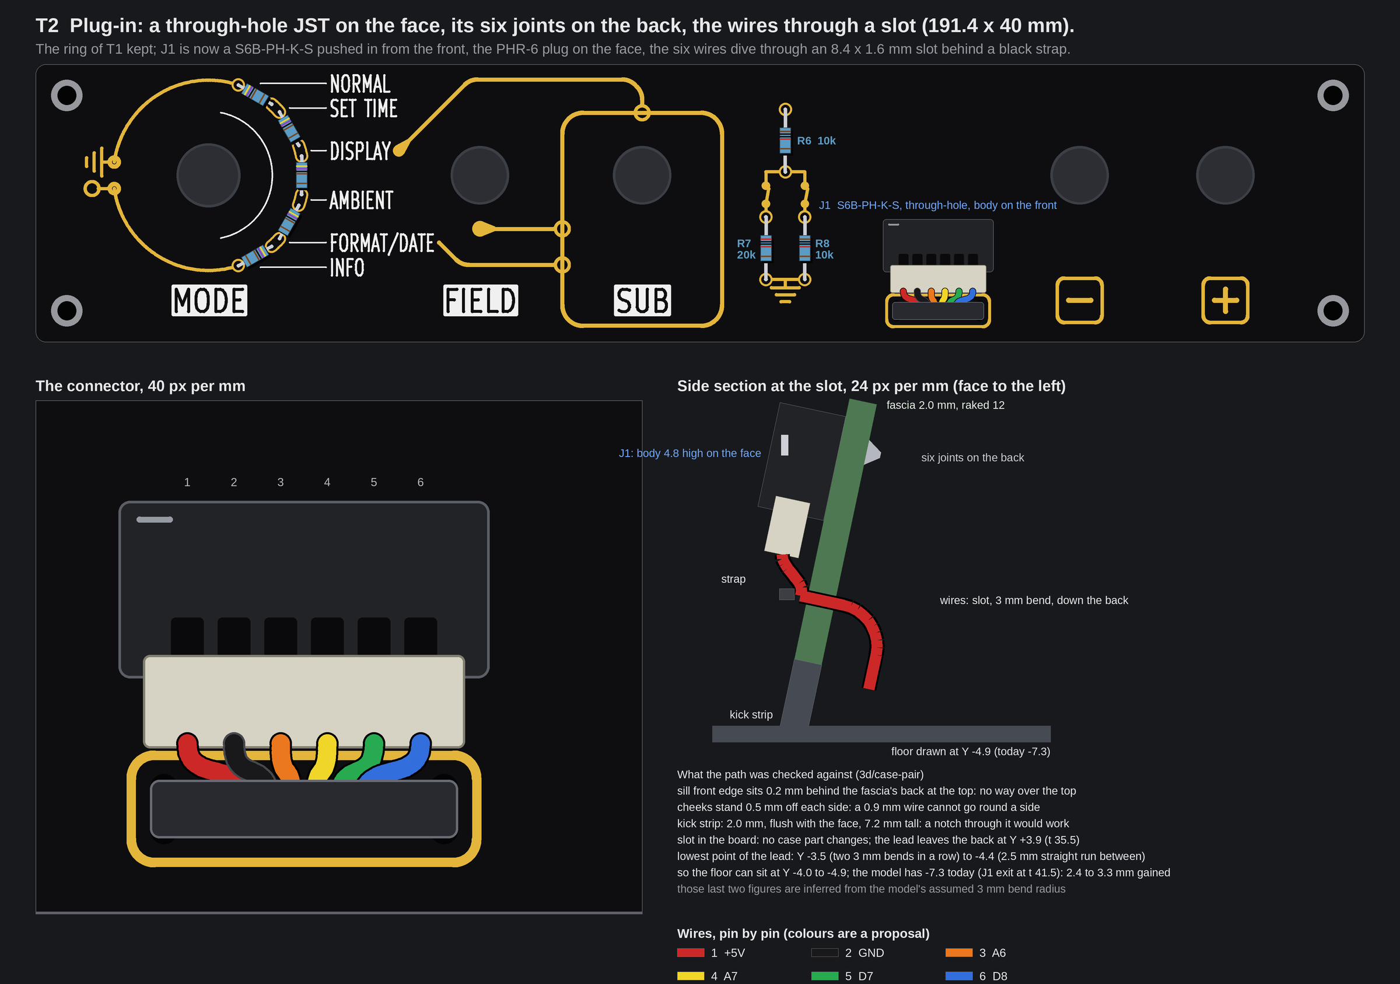
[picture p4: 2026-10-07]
PCB/TS06-FASCIA-T-concepts/T2-plug-in.png

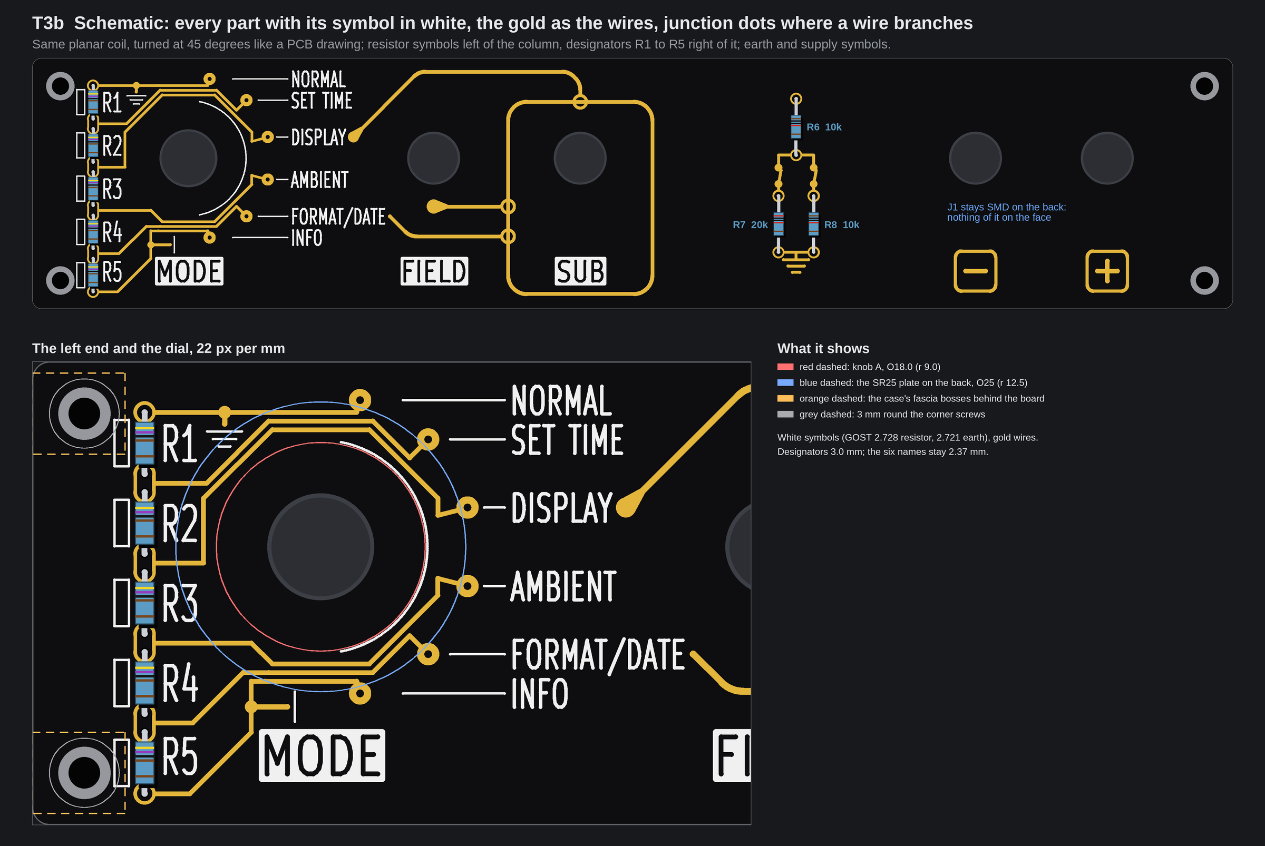
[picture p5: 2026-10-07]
PCB/TS06-FASCIA-T3-variants/T3b-schematic.png

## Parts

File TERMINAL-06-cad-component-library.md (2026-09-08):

# TERMINAL-06 — building a 3D component library

**Purpose:** a parametric library of the physical parts so enclosure revisions are a
boolean operation instead of a re-measurement. Open-source toolchain, STEP as the
interchange format, git as the history.

---

## 0. What you are modelling (and what you are not)

You are not making replicas. You are making **fit solids**. Every part in the library
carries two solids:

| Solid | Contains | Used for |
|---|---|---|
| `BODY` | Simplified real geometry — envelope, bushing, base, leads | Renders, sanity, section views |
| `KEEPOUT` | Worst case swept volume: body ⊕ lever swing ⊕ plunger travel ⊕ tool access ⊕ finger access | The boolean the enclosure is cut with |

Clearance lives in `KEEPOUT`, never in the enclosure. When you find out the МТ1 lever
fouls the brow, you fix it in one file and every downstream part updates.

The third thing each part carries is a **published hole diameter**. The fascia sketch
should reference `INS_MT1.HOLE_D`, not a number you typed from memory.

---

## 1. Toolchain

| Tool | Role | Why this one |
|---|---|---|
| **FreeCAD 1.0+** | Primary CAD. Part Design, Sketcher, Spreadsheet, Assembly WB | Real B-rep solids, native STEP in and out, parametric, toposcopy improved in 1.0 |
| **KiCad 8/9 + StepUp** | Export TS06-FASCIA and the tube board as STEP | Makes the PCB the single source of truth for hole X/Y. You already have Gerbers; hole positions should never be typed twice |
| **OpenSCAD** | Optional, for parts that are pure numbers (neon holder, J-LEAD comb, print jigs) | Plain text → diffs cleanly in git, trivially parametric |
| **Blender 4.x** | Listing renders only | Import via FreeCAD → glTF/OBJ. Do not model dimensioned parts here |
| **Inkscape** | Trace scanned silhouettes → SVG → FreeCAD sketch | For irregular metal bodies (КМД1-1 box, lever mounting plate) |
| **git + git-lfs** | History | `.FCStd` is a zip; LFS it. Commit measurement tables as plain text so they diff |

**Skip photogrammetry.** Meshroom on a nixie tube is the worst case in the discipline:
transparent envelope, specular metal cathodes, no texture, and no scale reference. You
get an unusable mesh after an hour. Calipers take four minutes and are more accurate.

---

## 2. Conventions — decide once, before the first part

### Origin rules

These matter more than modelling skill. Get them right and placing a part in an
assembly is one drag, no arithmetic.

- **Panel-mount parts** (levers, buttons): origin at the **centre of the mounting hole,
  on the front face of the panel**. +Z points out of the panel toward the user. +Y up.
  The bushing straddles the origin — hardware in front, body behind.
- **Socketed board-mount parts** (IN-12): the tube's own origin is **on the tube axis at
  the pin-exit shoulder** — the plane where glass meets the pin comb, i.e. where it seats
  into a socket. That's intrinsic to the tube and doesn't move if the board layout does.
  The **socket** is a separate part, origin on the tube axis at the PCB top surface; its
  height is what actually places the tube above the board. Digit-centre-above-PCB is
  therefore always `socket.seat_h + tube.pin_exit_to_digit`, never a number either part
  owns by itself — don't let it drift back into being "the tube's height."
  +Z along the viewing direction.
- **Wire-ended parts** (IN-17, ИНС-1): origin at the seating plane your jig defines, not
  at the glass. The J-LEAD comb sets the real Z — so model the jig and let it own the
  datum, and the tube references it. The samples on the mat came with a **loose moulded
  spacer that slides along the leads** rather than a fused base — that's not a socket,
  it's close kin to the J-LEAD comb the build plan already calls for. Worth photographing
  it dimensioned on its own; it may save you designing the jig from scratch.

### Naming

```
TS06-LIB-IN12.FCStd
TS06-LIB-SOCKET.FCStd
TS06-LIB-IN17.FCStd
TS06-LIB-INS1.FCStd
TS06-LIB-MT1.FCStd
TS06-LIB-KMD1.FCStd
TS06-LIB-ROTARY.FCStd
TS06-LIB-DCJACK.FCStd
```

### Spreadsheet-driven

Every part document opens with a `dims` spreadsheet. Alias every measured number:
`env_w`, `env_h`, `pin_pcd`, `bush_d`, `bush_len`, `body_l`, `swing_deg`, `clear_r`,
`panel_t`. Nothing typed into a sketch dimension box. When you re-measure a better
sample, you edit one cell.

Also alias the **derived** values you want published: `HOLE_D = bush_d + fit_clear`.

---

## 3. Measuring

Ground rules for Soviet stock:

- Digital calipers at 0.01 mm. Measure **three samples minimum**, record min / mean / max.
  Design against **max + clearance**. Your own spec already flags batch variance in
  envelope tint — dimensional spread is the same story.
- Never clamp glass. Set the jaws slightly open and slide the part until it just drags.
- Threads: pitch gauge plus major diameter. Record as `M12×0.75`, not "about 12".
- **Flatbed scanner trick** — part flat on the glass, black card draped over it, 600 dpi,
  steel rule in frame. You get a 1:1 silhouette. Verify against the rule, trace in
  Inkscape, import the SVG as a FreeCAD sketch and dimension over it. Best method there
  is for the КМД1-1's stamped box and the toggle's mounting plate.
- Photograph alternative: maximum working distance plus zoom, ruler in the same plane as
  the feature. Your cutting-mat shots are good documentation but too close for tracing —
  perspective on the near corner will cost you a millimetre.

### Per-part capture sheets

**IN-12 (ИН-12А)** — tube-intrinsic only. Nothing here should depend on how it's mounted.
- Envelope W × H × D at widest point; corner radius
- Tip-off pip: location and projection (this is what hits a trench wall)
- Pin count, pin circle / grid pitch, pin diameter, free pin length
- **Pin-exit shoulder to digit centre** — measured from where glass meets the pin comb,
  i.e. the tube's own seating reference. This is the number that used to be miscast as
  "seated height above PCB"; it isn't that, because the socket owns the other half of
  the stack-up (below)
- Depth from front glass to the digit plane — matters for parallax under the 12° rake
- Getter flash location (photographs badly if it lands in the trench opening)

**Tube socket** — not yet in the library; add it before the trench floor is trustworthy.
- PCB top face to the seat where the tube's pin-exit shoulder lands (`seat_h`) — this is
  the other half of digit-centre-above-PCB
- Pin/pin-hole pattern, matched to the tube's pin circle — same alias source, don't
  re-measure it independently and risk the two drifting apart
- Outer body diameter and height — this is what actually occupies the trench floor and
  needs its own keepout; the tube keepout alone understates the footprint
- Retention style (friction socket vs. soldered pins) — affects whether the tube can be
  pulled for service without touching the board, worth noting in `docs/measurements.md`
  even though it doesn't drive a dimension
- **Digit centre height above the PCB** is `socket.seat_h + tube.pin_exit_to_digit` — a
  derived value, computed in the assembly document, not typed into either part's
  spreadsheet

**IN-17 (seconds)**
- Glass max diameter, overall length, base disc diameter and thickness — n/a, no base;
  see lead spacer below instead
- **Two glass-only diameter passes so far: 19.30 mm and 17.50 mm**, at different points
  along the body (confirmed jaws-on-glass, not on the lead spacer). Single sample each —
  needs min/mean/max before either is a `dims.*` alias
- Lead count, lead circle diameter, lead diameter, free lead length — rough visual count
  off zoomed photos: ~6–8 leads, low confidence, count by hand once fanned out. Worth
  reconciling against a full 0–9 cathode set if this is meant to share the K155ID1 bus
- Digit centre height above the base seat → reword: **above the J-LEAD jig's seating
  plane** once that jig exists
- Front glass to digit plane — not yet visible in any shot with a ruler in frame
- **Loose lead spacer** — dimension it as its own small part. If its slide positions are
  usable as-is, it may substitute for designing J-LEAD from scratch; if not, at minimum
  it tells you the target lead spacing directly instead of guessing it

**ИНС-1 (colon neon)** — asymmetric ends, not a simple wire-both-sides part. One end is a
fine flexible lead; the other terminates in a **metal ferrule/cap** rather than a second
bare lead, and the viewing surface is a rounded glass dome past the cap end. Worth
confirming which end actually carries the mounting connection before committing to a
wire-ended-both-sides model — this may need a hybrid origin, cap-referenced rather than
lead-referenced, closer in spirit to a subminiature lamp base than to a two-lead neon.
- Glass diameter and length, lead diameter and free length — **first two readings in
  hand: envelope diameter 6.97 mm (confident, jaws pinched tight on bare glass); overall
  span ~22.7 mm (low confidence — caliper was photographed upside-down, worth re-shooting
  right-side-up before trusting the digit)**
- Metal cap: diameter, length, and how it's actually retained (crimped, soldered,
  cemented) — new field, not in the original sheet, added because the cap turned out to
  be real rather than assumed away
- **Glow-point position along the axis** — the holder registers on the glow, not the
  envelope centre. Two tubes with identical glass can glow 1.5 mm apart

**МТ1 / ТВ1-2 lever** — four clean caliper reads in hand, two more need a re-shoot
right-side-up. See `TERMINAL-06-measurements-MT1.md` for the full table.
- Bushing thread major diameter and pitch — not directly measured; rough visual estimate
  off a face-on reference photo against the mat grid puts it around 8–9 mm, placeholder
  only
- **Bushing usable length** — this caps your fascia + any dress plate stack
- Anti-rotation flat: width across, angular position relative to the lugs — not yet
  measured
- Body box L × W × H behind the panel (your spec says 30 mm depth; verify per sample) —
  two candidates in hand (10.43 mm, 11.92 mm), endpoints not fully confirmed
- Solder lug projection and how far lugs extend past the body — not yet measured
- Front hardware stack height: nut + lockwasher + any dress nut — two ambiguous caliper
  reads exist for this area but the photos were upside-down; not trustworthy yet
- **Lever swing:** length from pivot to tip, and full throw angle. Model as a revolved
  cone or a union of the two extreme positions. Under a 12° rake the up position sweeps
  toward the brow — this is a real collision, not a theoretical one. Not yet measured —
  none of the current photos capture the lever at its throw extremes

**КМД1-1 button** — measured differentially against МТ1: only what's unique to this part
was captured this round. See `TERMINAL-06-measurements-KMD1.md` for the full table.
- Bushing thread and usable length — **not re-measured; carried over from МТ1 on the
  assumption the bushing hardware is shared between the two parts.** That's a real
  assumption, not a confirmed fact — both parts look like they use the same
  thread/nut/washer stack in the reference photos, but nothing has actually put a caliper
  on this part's bushing yet. Flag it before it becomes load-bearing
- Body box behind the panel — **two new readings unique to this part: 13.75 mm and
  16.91 mm**, best-guess candidates for body box length/width, not yet assigned to L vs.
  W with confidence
- Plunger free height and pressed height → **travel** goes in `KEEPOUT` — confirmed the
  front element is a **plunger/button cap**, not a lever (visible in reference photos) —
  but travel itself not yet measured
- Lug orientation relative to the anti-rotation feature. The body is a rectangular box
  wider than the bushing, so its rotation is not free — record the orientation you
  intend and model it that way
- **Three solder terminals** visible along one edge of the body — new confirmed detail,
  not in the original field list

**SR25-style rotary switch (6-position selector)** — the part arrived; real caliper
readings now replace the Ozon listing numbers below. The listing's own two variants
(25 mm / 19 mm body) turned out not to match the physical part particularly well — see
`TERMINAL-06-measurements-ROTARY.md` for the full readout. This is the "datasheet is a
hypothesis" warning from Section 7 playing out exactly as written; treat the old
listing-derived numbers as superseded, not as a second data point to average against.
- **Body/wafer diameter: 26.94 mm, measured.** Neither listing variant (25 mm, 19 mm)
  — closer to the 25 mm one but 1.94 mm over it, which is not caliper noise
- Bracket/mounting ear width: **8.59 mm, measured** — best-guess identity, jaws were on
  the metal bracket arm near the bushing, not yet confirmed which exact feature this is
- A tighter feature near the front wafer (possibly stop-screw head, possibly a bracket
  tab): **~5.8 mm, low confidence** — this one's digit read is uncertain, worth a
  re-shoot right-side-up
- A cross-section near the pin comb, shaft end of the switch: **12.10 mm, clean read** —
  best guess is wafer-stack depth along the shaft axis, not yet confirmed
- Shaft diameter, bushing thread size, bushing usable length, position count, pole
  count — still not directly measured; the listing's 6 mm shaft figure is now similarly
  suspect given the body diameter mismatch and shouldn't be trusted without its own
  caliper pass
- Panel-mount origin rule already covers this part — same convention as МТ1 and КМД1-1,
  no new modelling question here

---

## 4. FreeCAD build recipe (per part)

1. New document. Add a spreadsheet named `dims`, alias everything from the capture sheet.
2. New Body. **Sketch on an origin plane or a datum plane — never on a face of an
   existing feature.** Face-attached sketches are what break when you change a
   dimension. FreeCAD 1.0 is better here but not immune.
3. Revolve / pad the `BODY`. Simplify aggressively:
   - No modelled threads. A plain cylinder at major diameter. Cosmetic thread only if a
     render needs it, in a separate body you can suppress
   - No knurling
   - Skip chamfers under ~0.3 mm
   Threads and knurls destroy rebuild time and bloat STEP files for zero fit information.
4. Second Body named `KEEPOUT`, same document, red at 60 % transparency:
   - Body silhouette + radial clearance
   - Lever swing cone / plunger travel
   - **Tool access.** A nut driver on a 13 mm bushing nut needs roughly 17–19 mm across
     flats plus wall — model the socket OD as a cylinder from the panel face forward.
     This is the classic panel-mount failure: five controls that individually fit and
     collectively cannot be tightened
   - Finger access on anything the customer operates
5. Export both to `lib/step/`.
6. Assembly document: `App::Link` each part in, attach to the fascia face by LCS.
7. Enclosure document: boolean-subtract the union of all `KEEPOUT` solids, then
   Part → Check Geometry, then take a section along the digit centreline and check it
   against the numbers already committed in the spec (trench 166 × 21, floor 32 mm back,
   digit centreline 17 mm down, brow y 9.5–22 / z 74.5–79).

---

## 5. Verify before spending money

- **Fascia proxy:** print 176 × 52 × 1.6 mm in PETG with the exact hole pattern and fit
  the real switches. Two hours of print time against a 15-board Rezonit order in black
  mask with a surcharge and a long lead time.
- **Trench coupon:** one tube position, full rake, real IN-12 **seated in its actual
  socket** — not floated at an assumed height. A tube held loose at "roughly where it'll
  sit" confirms nothing about the real digit centreline, since that number is a
  socket + tube stack-up, not a tube property. Confirms the 17 mm centreline and the
  brow clearance at a 10° viewing angle before you commit ten hours of chassis print.
- **Interference check** in the FreeCAD assembly, then a visual pass at the listing
  camera angle.

---

## 6. Repo layout

```
terminal06-cad/
  lib/            one .FCStd per component
  lib/step/       exported STEP, the interchange format
  pcb/            KiCad → StepUp → STEP (fascia, tube board, SEC)
  asm/            assembly documents
  print/          3MF/STL exports — outputs only, never inputs
  jigs/           J-LEAD comb, neon holder (OpenSCAD)
  docs/
    measurements.md    the capture sheets, as plain text tables
```

`.gitattributes`: LFS on `*.FCStd`, `*.step`, `*.3mf`, `*.stl`.
Tag the repo when a PCB is ordered — `fascia-rev-A` — so the library state that produced
those boards is recoverable.

---

## 7. Pitfalls

- **Datasheet dimensions are a starting hypothesis**, not a measurement. 1984 stock from
  Meshok is not held to the drawing.
- **Never use STL between your own tools.** It is a lossy export format. STEP in, STEP out.
- **Don't put clearance in the enclosure.** It belongs in `KEEPOUT`, in the part file.
- **Don't attach sketches to faces.** Datum planes only.
- **Glass gets max-of-sample + 0.4 mm**, minimum.
- **One part per file.** The temptation to build the whole clock in one document ends in
  a 40-second rebuild and a dependency graph you cannot reason about.

---

## Open flag on the photographed parts

The spec currently fixes the fascia at ⌀12.2 mm for 12 mm anti-vandal buttons and
⌀13.2 mm for the levers. The button in these photos is a **КМД1-1**, which is not that
part — different bushing, and a stamped rectangular body rather than a round barrel.

Three things to settle before the fascia goes to Rezonit:

1. Re-derive `HOLE_D` for both controls from measured bushings, plus the anti-rotation
   flat geometry.
2. Body depth behind the panel against the 12° rake — the wedge gives you depth at the
   bottom of the face and takes it away at the top.
3. Lug and body footprint on a 176 × 52 mm board. SET at X = 22 and ADJ at X = 154 put a
   rectangular body close to the board edge; the levers at 64 / 88 / 112 sit on a 24 mm
   pitch, which is where the nut-driver keepout earns its place.

Modelling those two parts first, from the samples in front of you, answers all three.

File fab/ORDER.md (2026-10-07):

# Order sheet: the three TS06 boards

For the owner, who places the order by hand. Nothing here was sent to a board house: no site was
contacted, nothing was uploaded, no price was looked up, so there are no prices on this page. Anything
marked *inferred* is a typical figure for a low-cost two-layer service, not something a fab told us;
check it against the fab you choose.

Status: the three zips are built and checked, and every row of the DFM check passes on all three boards. The
four findings the fascia had in the first version of this sheet (silk lines, back legend text, mask slivers, the
finish in its job file) are fixed in the generators and the zip is rebuilt; they are closed below.

**Fascia R is now rev B (7 October 2026): J1 is an upright JST B6B-PH-SM4-TB** instead of the side-entry S6B-PH-SM4-TB, so the six-wire lead
leaves it straight back and no longer bends 90 + 12 degrees at the base (the owner, about 14:50 UTC: "maybe we change the connector from a 90
degree bend to normal upright?"; `PCB/TS06-FASCIA-rhythm/J1-UPRIGHT.md`). **This replaces the fascia zip: nothing had been placed.** The zip
to send is `fab/TS06-FASCIA-R-revB-divider-holes04-fab.zip`. Everything else on the fascia is as rev A: the board, the gold, the holes, the
leaders, the thickness, the finish. The rev A zip is kept as `fab/TS06-FASCIA-R-revA-divider-holes04-notordered-fab.zip`: **do not send it.**
The case is 2.8 mm lower with the upright part (`3d/case-pair/checks.md`). The DISP and DRV zips are unchanged.

**The fascia zip is the one with the control holes opened** (the owner, 2026-10-02: "1-  yes", 10:37 UTC; `fab/HOLES-VARIANT.md`)
**and the level leaders** (the owner, 11:31 UTC: "a"). `fab/TS06-FASCIA-R-revB-divider-holes04-fab.zip` (rev B, see above) is the fascia to
send to the fab. The zip with the holes as drawn (8.8 and 8.0 mm) and the sloped leaders is kept as
`fab/TS06-FASCIA-R-revA-divider-slope-notordered-fab.zip`: **it is NOT ordered**, a record of what was not picked. Nor is the rev A zip with the
holes opened and the level leaders, `fab/TS06-FASCIA-R-revA-divider-holes04-notordered-fab.zip` (side-entry J1). Do not send either.

## The three zips

All three are in this folder. Upload one zip per board; each holds the Gerbers, the drills and a job file.

| Board | Zip | Size | Layers | Thickness | Holes (plated / non-plated) | DFM check |
|---|---|---|---|---|---|---|
| TS06-DISP rev B (the tubes) | `fab/TS06-DISP-revB-fab.zip` (120 kB) | 191.4 x 44.0 mm | 2 | 1.6 mm | 179 / 10 | all PASS |
| TS06-DRV rev B (the driver) | `fab/TS06-DRV-revB-fab.zip` (333 kB) | 191.4 x 100.0 mm | 2 | 1.6 mm | 427 / 8 | all PASS |
| Fascia R rev B (upright J1) with the Divider gold, control holes opened, level leaders | `fab/TS06-FASCIA-R-revB-divider-holes04-fab.zip` (49 kB) | 191.4 x 40.0 mm | 2 | **2.0 mm** | 0 / 9 | all PASS |

Notes on the table:
* The job files inside the zips say 191.5 x 44.1, 191.5 x 100.1 and 191.45 x 40.05: they add the width of the outline line. The boards are the sizes in the table.
* All three job files now say finish ENIG, and the fascia's says 2.0 mm (its board file carries the same stack-up as TS06-DISP and TS06-DRV). KiCad does not write the mask and silk colours into a job file; they are in the boards' stack-ups (black, white) and in the renders.
* The fascia is **2.0 mm** thick, not 1.6 mm. That is deliberate: the case is drawn for a 2.0 mm fascia (`PCB/README.md`, `3d/case-pair`). Make sure the fab quote says 2.0 mm for this one.
* **The fascia's five control holes are opened by 0.4 mm** (the dial 9.2 mm, the levers and buttons 8.4 mm; the four M2.5 screw holes stay 2.7): 0.29 mm a side round the bushings instead of 0.09 (`fab/HOLES-VARIANT.md`, the fit table `3d/populated/fit-table.md`). The drill file in the zip holds one 9.2, four 8.4 and four 2.7 mm.
* **The fascia's leaders are level** (`tools/fascia_art.py`, style `level`): each of the six position names stands at its mark's height and is joined to it by one level white line. To make that fit, the six names are **2.37 mm** tall (the nameplates MODE, FIELD and SUB stay 3.2 mm), below the 3 mm legend rule of G11 (see "The G11 conditions" below).
* **Not ordered:** `fab/TS06-FASCIA-R-revA-divider-holes04-notordered-fab.zip` is rev A (side-entry J1) as it stood before the change to the upright part, a record. And
  `fab/TS06-FASCIA-R-revA-divider-slope-notordered-fab.zip` is the fascia as it was before the two picks, holes 8.8 / 8.0 and the sloped leaders, kept as a record. Neither is to be sent; the page's Order view does not list it.
* The fascia has no plated holes (every part is surface-mounted on its back; the front holes are for the switch bodies and screws). Its zip therefore has no plated drill file. It does carry a back solder-paste layer, for the eight 1206 resistors, in case you want a stencil; ignore it if you solder by hand.
* The gold of the fascia is in the zip as copper on the front with openings in the front mask over it. That was read back out of the Gerbers, not just trusted: the mask is open over all of the gold (see "What was checked").

Pictures: `fab/preview/` (the fascia with the gold, and the three boards side by side).

## What you choose at the fab

* **Quantity: 10 of each board (the owner's choice).** A prototype run, not the production batch.
  * The cheap promotional prices at the usual fabs are for small boards (often up to 100 x 100 mm, 1.6 mm, HASL, green). These boards are 191.4 mm long, the fascia is 2.0 mm and needs ENIG, so they likely cost more than the promo (*inferred*; no prices were checked).
* **Mask and silk colours (the owner's choice, all three boards).**
  * Solder mask: black, **matte black if the fab offers it at a small extra cost**.
  * Silk: white.
  * The stack-ups of all three boards say "Black" and "White" (KiCad has no matte setting), so the renders agree with this; matte is chosen at the fab. These are the colours the fascia art and its renders assume (`tools/fascia_art.py`, `tools/render_kicad.py`): the gold shows against black, the names in white.
* **Surface finish.** ENIG on all three. All three job files say ENIG (the fascia's does since this rebuild: its board file now carries the stack-up). The fascia's gold look needs ENIG: with HASL the "gold" would be silver-grey (inferred).
* **The fab's own order number on the silk.** Many fabs print one. On the fascia, which is the visible face, ask for **no number**, or a hidden spot on the back (inferred: most have a "no marking" or "marking position" option; some charge for it). On DISP and DRV the number can go anywhere on the back.

## Picked by the owner (closed, 2026-10-02)

* **The control holes opened by 0.4 mm** (10:37 UTC: "1-  yes"): the fascia zip is `fab/TS06-FASCIA-R-revB-divider-holes04-fab.zip` (rev A's had the same holes), 0.29 mm a side round each bushing instead of 0.09 (`fab/HOLES-VARIANT.md`). The play is the price: until its nut is tightened a part can sit up to 0.29 mm off centre. A dry fit with real parts (G14) closes that.
* **Level leaders** (11:31 UTC: "a"): the white lines from the dial's six positions to their names are level, each name at its mark's height (the names 2.37 mm; see "The G11 conditions"). The other two styles the owner was shown (dogleg, centred) and the sloped one are still options in `tools/fascia_art.py`; the zip is rebuilt with one by `bash tools/mkfab.sh TS06-FASCIA-rhythm --leaders dogleg` (its name then carries the style).

## Your open choices

1. **G11, which fascia.** R is recommended (3 to 0 in the referendum). This sheet and the zip assume R. If you choose another fascia, the zip is to be rebuilt; say so.
2. **The gold.** Divider is the leader's pick and is what the zip holds. The other three (ladder, fans, guilloche) are still in `tools/fascia_gold.py`, and the zip can be rebuilt with another by one command:
   ```
   bash tools/mkfab.sh TS06-FASCIA-rhythm --gold ladder      # or fans, guilloche; --gold none is the bare board
   ```
   The zip's name carries the gold. **Be aware:** ladder, fans and guilloche are laid out for the narrower fascia A (176 mm), not for R. On R the generator stops and prints what is wrong with them (ladder: its rows do not line up; fans and guilloche: gold touches the white names and a control). So today only the Divider is ready for R; another gold on R needs a layout first. The flag is there; the artwork is not.
3. **G8, first half.** Whether to commit the board files themselves "filled" (with the copper pours stored in them). The zips are built with the pours filled either way, and you order from the zips, so this does not hold up the order.

## What only the prototype can close (G14)

Parts and a bench are needed for these; the prototype run is the way to close them:
* the ИН-15 / ИН-17 pinouts and the pip height;
* the PBS / PLS heights;
* the RTC module's pin order;
* the L1 part;
* the anode resistors marked TBC;
* the ИН-12 brightness at 6 slots (E6);
* the КМД1 and МТ1 dry fit (also a G11 condition);
* the colon courtyard overlap.

## What was checked

* `bash tools/verify_pair.sh`: 27 PASS, 0 FAIL, 0 SKIP.
* `bash tools/mkfab.sh`: PASS for all three (the pours are in the Gerbers; the fascia's gold is in F.Cu and open in F.Mask, with no thin mask web over it). The DISP and DRV zips are unchanged by the rebuild.
* `python3 tools/dfm_check.py`: every row PASS on all three boards, exit 0. It is KiCad's DRC with generic fab limits (below, *inferred*), plus a second reading of the zips themselves. Every check was also run on a deliberately broken board first and shows FAIL there (the self-test, 17 rows).
* `python3 tools/dfm_check.py --g11`: the boss-to-R5 row passes; **the legend row FAILs** for the six position names (2.37 mm set, below the 3 mm rule; the owner's pick of the level leaders), and the command exits 1 (below).
* The fascia rows above are the ordered zip, `fab/TS06-FASCIA-R-revB-divider-holes04-fab.zip` (holes opened, level leaders, upright J1), read on 2026-10-07; against rev A only the copper clearance moved (0.375 to 0.325 mm: A7 passes 0.325 mm under the tails of the new J1), and every row still passes. The zip not ordered is not in these tables.
* `python3 tools/fascia_art.py --selftest`: the art check's model of the slash in FORMAT/DATE (a stroke, not a box across the name) reads its four planted cases as it must; the six names' size, 2.37 mm, is the largest at which `tools/fascia_art.py` and `tools/fascia_gold.py` pass every check with the leaders level.

The limits used (all *inferred*, typical of a low-cost two-layer service): track width 0.15 mm; copper clearance 0.15 mm; plated drill 0.3 mm; non-plated drill 0.5 mm; annular ring 0.15 mm; copper to board edge 0.3 mm; hole to hole 0.5 mm wall to wall; silk line 0.15 mm; silk text height 1.0 mm; mask sliver 0.1 mm; board within 400 x 500 mm.

Worst values found (smaller is nearer the limit):

| | TS06-DISP | TS06-DRV | Fascia R |
|---|---|---|---|
| Track width (limit 0.15) | 0.25 | 0.25 | 0.25 |
| Copper clearance (0.15) | 0.25 | 0.21 | 0.325 (rev A 0.375) |
| Annular ring (0.15) | 0.30 | 0.20 | over 0.40 |
| Copper to edge (0.3) | 0.75 | 0.75 | over 0.80 |
| Smallest plated / non-plated drill (0.3 / 0.5) | 0.9 / 3.2 | 0.8 / 3.2 | none / 2.7 |
| Silk line, from the Gerbers (0.15) | 0.15 | 0.15 | 0.15 (was 0.10 back, 0.12 front) |
| Silk text height (1.0) | 1.0 | 1.0 | 1.0 (was 0.8) |
| Narrowest mask web, front (0.1) | 0.3 | 0.3 | 0.100 (was below 0.1: 0.05) |
| Board size | 191.4 x 44.0 | 191.4 x 100.0 | 191.4 x 40.0 |

Reading the fascia's mask web: 0.100 mm is the raster's reading, which steps in 0.025 mm and carries about +-0.03 mm, so
it means "no piece of mask thinner than 0.1 mm of any size worth the name". What is left near that value are the
tips of the crescents of mask where a box edge crosses an entry ring's hole (three rings of the SUB box, 0.004 mm2 each).

### The four findings on the fascia: closed

All four are fixed in the generators and the fascia zip is rebuilt. (They were found by the first DFM check, in the
version of this sheet before.)
1. **Front silk rings of 0.12 mm round the controls:** `tools/mkfp.py` draws every silk line at least 0.15 mm (`SILK_W`); the five rings are 0.15 now.
2. **Back silk:** the eight 1206 outlines (0.10) and J1's outline (0.12) are 0.15 mm, in the same footprint generator; J1's pin legend text is 1.0 mm tall with a 0.15 mm stroke (it was 0.8 / 0.12), in `tools/mkpcb_fascia_rhythm.py`. TS06-DISP and TS06-DRV use none of those footprints: their board files and their zips are unchanged.
3. **Mask slivers at the dial rings:** `tools/fascia_gold.py` (the Divider) ends every gold line 0.1 mm clear of a ring's hole, so no line cuts a hole's disc of mask in two. The check also found the +5V terminal ring 0.096 mm from the GND symbol (a mask web just under the limit, which the raster read as 0.1): it is moved 0.4 mm out and the gap is asserted. Done for R and for A. The other three golds on A (ladder, fans, guilloche) have no line ending in a ring's hole.
4. **The finish "None" in the fascia's job file:** the fascia board now carries the stack-up (black mask, white silk, ENIG, 2.0 mm), written by `tools/mkpcb_fascia_rhythm.py`.

Not closed, and not on the order: guilloche on A (not laid out for R) still leaves thin mask pieces (the narrowest 0.05 mm, 0.004 mm2 each) at the wavy rings of its two medallions: a different cause (a tight wave), in a gold that is not chosen. TS06-FASCIA (A), TS06-FASCIA-wide, TS06-FASCIA-THT, TS06-MAIN and TS06-MAIN-THT still carry the footprint copies with the thinner silk in their board files: A and wide have no generator that writes them (`tools/mkpcb.py` still draws the older 52 mm board; wide is made from A), and none of them is in the order.

## The G11 conditions, measured on the fascia with the gold

* **Legends of at least 3 mm: NOT met by the six position names, by the owner's pick of the level leaders.** `python3 tools/dfm_check.py --g11` prints FAIL on this row (and exits 1). The six names (NORMAL, SET TIME, DISPLAY, AMBIENT, FORMAT/DATE, INFO) are set 2.37 mm tall; the drawn capitals measure 2.67 mm (FORMAT/DATE 3.68 mm because of its slash). The three nameplates MODE, FIELD and SUB are set 3.2 mm, the capitals 3.5 mm. 2.37 mm is the largest size at which every art check passes with every leader level (the marks of NORMAL / SET TIME and of FORMAT/DATE / INFO are 2.93 mm apart), and it is well over the fab's 1.0 mm silk-text limit (row "Silk text height" above). Before the pick all nine legends were 3.2 mm and this row passed. If the 3 mm rule is to hold for the six names, the dogleg or centred leaders keep them at 3.2 mm (`--leaders dogleg`, `--leaders centred`).
* **Boss to R5 margin: 1.4 mm is left.** The boss round the bottom-left screw clears R5's courtyard by 1.69 mm as drawn (the 1.7 mm of G11); to R5's pad copper itself 2.04 mm. Against typical fab tolerance (outline about +-0.2 mm, hole position about +-0.1 mm, *inferred*, both against us) that leaves 1.39 mm to the courtyard and 1.74 mm to the copper. Still clear.
* **The dry fit of a real КМД1 and МТ1 needs the parts**, so it stays open for the prototype (G14).

## Rebuild and re-check

```
bash tools/mkfab.sh                      # all three zips (the fascia's is the ordered one: holes opened, level leaders); a zip is kept if only its creation date would change
python3 tools/dfm_check.py               # the DFM tables, with the deliberately broken board first
python3 tools/dfm_check.py --g11         # the G11 measurements above (its legend row FAILs for the six names: see above)
python3 tools/fab_preview.py fab/preview # the pictures (each board whole; the fascia as ordered)
python3 tools/fascia_art.py --selftest   # the planted cases of the art check's model of the slash in FORMAT/DATE
```

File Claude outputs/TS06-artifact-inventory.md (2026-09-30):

# TS06 artifact inventory (read-only)

> Repo copy: artifact links are left out on purpose (two of the pages are shared with anyone who has the link). The owner's artifact list has them.

Prepared 2026-09-30 for the migration of 17 artifacts into the TS06 Board Viewer ((link in the owner's artifact list)). Nothing was published, changed, pinned or deleted. The old artifacts stay untouched.

- **Method:** each artifact was read with the Artifact tool (`read`, and `list` with scope `files`). Every one is a single page with no published files, and none declares runtime capabilities, so none has an asset store. Dates come from the artifact list.
- **Today's design** (from README.md and PCB/README.md on branch pcb/kicad-boards): TS06-DISP rev B + TS06-DRV rev B (191.4 mm, through-hole, zero vias), TS06-FASCIA 176 x 40, case 204.4 x 122.8 x 81.6 mm.
- **Sizes:** exact byte counts where the read service reported them (1 KB = 1000 bytes); estimates for the five small pages it returned inline.
- **Marks:** each claim is marked **seen** (read in the artifact, the list or the repo) or **inferred** (judgement or estimate). In the table, (s) = seen and (i) = inferred.
- **Personal data:** none is copied here. Pages that hold it say "contains seller or personal details (not copied)".

## Summary

**Headline, by primary target view:** History 6 · Family 8 · Front panel 2 · Parts and buying 1 · Product 0 · Build 0 · Circuit 0 · Case 0.
Secondary feeds: Circuit ← A1, A2 (the A6/A7 ladders) · Case ← A4 (IN-17 20.5 mm spacing, two-cheek origin) · Product ← A5 (effects player) · Parts and buying ← A5 (dated Rev E cost), B7, B8 (anonymised).

| ID | Artifact | Updated | Size | Target view | Effort | Flags |
|---|---|---|---|---|---|---|
| A1 | TS06-FASCIA Panel Drawing | 2026-09-08 | ~30 KB (i) | Front panel | M | pinned |
| A2 | TS06-FASCIA Reference | 2026-09-09 | ~15 KB (i) | Front panel | S | — |
| A3 | TS06-FASCIA Buy List | 2026-09-09 | ~15 KB (i) | Parts and buying | S | personal data |
| A4 | TERMINAL·06 Rev F | 2026-09-09 | 345 KB (s) | History | M | — |
| A5 | TERMINAL-06 Plate Set | 2026-09-05 | 372 KB (s) | History | L | — |
| A6 | TERMINAL-06 Open Deck | 2026-09-02 | 185 KB (s) | History | S | — |
| A7 | Terminal·06 Concept Plates (24.08) — Rev C | 2026-08-24 | 421 KB (s) | History | M | inline data, personal data |
| A8 | Terminal·06 Concept Plates (25.08) — Rev A | 2026-08-25 | 371 KB (s) | History | M | link-shared, inline data, personal data |
| A9 | Terminal 06 3D model | 2026-08-25 | 650 KB (s) | History | M | link-shared, inline data, 3D |
| B1 | MIMI-06 Kuro | 2026-09-02 | 332 KB (s) | Family | M | pinned |
| B2 | Mimi·06 Concept Plates | 2026-08-25 | 2,323 KB (s) | Family | M | pinned, inline data |
| B3 | QUADRANT Desk Miniature | 2026-09-05 | 100 KB (s) | Family | S | personal data |
| B4 | SCALER-06 Decatron | 2026-09-02 | 136 KB (s) | Family | S-M | personal data |
| B5 | Staircase Nixie Clock | 2026-08-25 | ~24 KB (i) | Family | S | — |
| B6 | Not a Nixie | 2026-08-28 | ~40 KB (i) | Family | M | personal data |
| B7 | Meshok Tube Board | 2026-08-25 | 66 KB (s) | Family | M | personal data |
| B8 | Meshok Watchlist | 2026-08-25 | 50 KB (s) | Family | M | personal data |

Group A = TERMINAL-06 (A1–A9); group B = sibling clock and tube projects (B1–B8).

**Cross-cutting findings**
- **The two Concept Plates copies differ** (seen): the 24.08 copy is **Rev C** (6 plates) and the 25.08 copy is **Rev A** (5 plates). The list dates run opposite to the content age; see "A7 vs A8" below.
- **TERMINAL-06 Open Deck is a strict subset of TERMINAL-06 Plate Set** (seen, by diff): nothing to migrate beyond a dated link.
- **Repo copies** (seen): knowledge/ in the repo holds browser-saved copies of A1, A4, B1, B2, B3 and B4, each matching the live version's dates and plates, so those six are not the only copy.
- **Link-shared pages** (seen): A8 (Concept Plates, Rev A) and A9 (3D model) are shared with anyone who has the link.
- **Big inline data** (seen): B2 2.3 MB (1.7 MB SVG + 2 base64 JPEGs), A9 0.65 MB bundle (three.js + fonts), A7/A8 about 0.4 MB each incl. one base64 JPEG, A4/A5/B1 about 0.3 MB of SVG.
- **Browser-only state** (seen): A3 keeps the owner's buying ticks in localStorage (key ts06-buylist-v1). They exist only in the owner's browser and will not move with the page.
- **Scripts that read the clock or use randomness** (seen): A5, A6, B1, B3 (setInterval + the viewer's clock), B4 (random simulation). No page fetches live data. External resources are Google Fonts stylesheets and plain links.

## Per-artifact sections

### A1. TS06-FASCIA Panel Drawing
- **URL:** (link in the owner's artifact list) · **updated** 2026-09-08 · pinned (seen, list)
- **Form:** single page, no published files; no assets capability, so no asset store (seen). Size about 30 KB of HTML (inferred, estimated from the read). No runtime capabilities (seen).
- **Holds (seen):**
  - Title block: TS06-FASCIA rev A, 2026-09-08, "Rezonit order, 15 off"; 176.00 × 52.00 mm, 2.0 mm FR4 2-layer, matte black mask, white silk, ENIG gold; 1 × JST-XH 6-way; 8 R, 5 SW, 1 J.
  - Panel drawing: front face and back-side placement ("x-ray"), two tabs, inline SVG drawn 1:1 by script (dial, FIELD/SUB levers, −/+ buttons, gold SUB traces, R1–R8, landing pads, J1).
  - "What the controls do": interactive 6-position dial (Normal, Set Time, Display, Ambient, Format/Date, Info) showing what FIELD, SUB and the buttons do on each screen; the "SUB is live only when FIELD is on its second throw" rule.
  - Hardware table (rotary Ø8.62 bushing → 8.80 hole, 7.00 mm usable, Ø6 shaft, Ø25 body, 30° × 6; МТ1 and КМД1 bushings Ø7.82 → 8.00 holes) and the control scheme rev B table.
  - Ladder design: A6 tapped divider (5 × 4k7, ADC codes 0/205/409/614/818/1023, 5.64 k source impedance) and A7 lever ladder (R6 10k, R7 20k, R8 10k; codes 1023/682/512/409); why no pull-ups and why the filter caps sit at the main-board end.
  - "Open before Gerbers" log: 12 detents (closed), bushing stack depth (open), SUB rule and INFO-to-6 (resolved), the 26.94 mm body figure withdrawn.
- **Images / 3D:** no raster images; all drawings are inline SVG built by inline script (seen). No 3D.
- **Superseded by today's design:**
  - 176 × 52 mm outline: today's TS06-FASCIA is 176 × 40 (height compressed 2026-09), with 191.4 × 40 variants beside it (seen, PCB/README.md, PCB/TS06-FASCIA-variants.md).
  - J1 "GND +5V A6 A7 D7 D8" on JST-XH: today J1 is fixed as 1 +5V, 2 GND, 3 A6, 4 A7, 5 D7, 6 D8, and the cable is JST PH (seen, PCB/README.md).
  - "Hand-wired controls with lugs behind" and the dial arc geometry: today's board is a routed SMD build with a rescaled MODE arc (seen, PCB/README.md); the drawing's positions no longer match the board file (inferred).
  - "Two 100 nF caps at the main-board end": DRV rev B adds its own filters (1 M on A6, 1 k + 10 nF on D7/D8) (seen); whether A6/A7 still get 100 nF is not checked (inferred partly superseded).
- **Still current:** the A6 divider and A7 lever ladder (R6 is still the A7 pull-up, seen in PCB/README.md); the control scheme rev B and its dial semantics (a repo file TERMINAL-06-control-scheme-revB.md exists, seen by name only); the hardware bushing figures (inferred).
- **Unique:** the interactive dial explainer (per-position FIELD/SUB/button roles) and the ladder rationale with ADC code tables, as written here (inferred unique among artifacts; the Reference page may overlap, see A2). A browser-saved copy of this same version (rev A, 2026-09-08) is in the repo at knowledge/TS06-FASCIA Panel Drawing.html (seen).
- **Target view:** Front panel (drawing + controls + ladder); the 176 × 52 drawing itself to History, marked "superseded by TS06-FASCIA 176 × 40".
- **Effort:** M. The dial explainer and ladder SVGs are script-built and need re-hosting as code, not copy; the drawing must be split into current (controls, ladders) and history (outline, J1 order).
- **Risks:** Google Fonts stylesheet (external, allowed); inline script builds all SVG, so a text-only copy loses the drawings (seen). No local storage, no live data (seen). Dark-only palette, no light theme (seen).

### A2. TS06-FASCIA Reference
- **URL:** (link in the owner's artifact list) · **updated** 2026-09-09 (seen, list)
- **Form:** single page, no published files, no runtime capabilities, so no asset store (seen). About 15 KB (inferred, estimated from the read).
- **Holds (seen):**
  - Header stats: 176 × 52 mm, 2.0 mm FR4 2-layer ENIG, black mask/white silk, B.Cu-only signals, 0 vias, 6-pin JST-PH to the main board. Written for the SMD build.
  - 01 Front face: one static inline SVG (MODE dial with six labels, FIELD/SUB levers with gold boxes, −/+ buttons, SW1–SW5 callouts); points to PCB/TS06-FASCIA/preview.svg.
  - 02 "Five controls on two analog pins": A6 tapped divider table (positions → taps) and A7 two-lever table (paths to GND).
  - 03 Net reference: +5V, GND, A6, TAP2–TAP5, A7, LEVA/LEVB, D7, D8, each with pads and the reason.
  - 04 J1 pinout 1 +5V, 2 GND, 3 A6, 4 A7, 5 D7, 6 D8. 05 Routing notes: 64 B.Cu tracks, 0 vias, the R6 corridor story and the GND pour fix.
- **Images / 3D:** one static inline SVG, CSS-variable coloured (seen). No raster, no 3D.
- **Superseded by today's design:** the 176 × 52 outline and the dial label geometry (today 176 × 40 after the 2026-09 compression, with a rescaled MODE arc) (seen, PCB/README.md).
- **Still current:** J1 pin order and JST-PH; the net list; B.Cu-only routing with 0 vias; the R6 move and GND pour story (all match PCB/README.md, seen).
- **Unique:** the per-net "why" table is the only net-by-net explanation among the artifacts (inferred); the R6 story is also in PCB/README.md (seen), so not unique.
- **Target view:** Front panel (net reference, J1 pinout, routing notes) and Circuit (the ladders).
- **Effort:** S. Static HTML and one SVG; only the outline figure needs updating or a "176 × 52, before compression" caption.
- **Risks:** Google Fonts stylesheet only (seen). Already has light and dark tokens (seen). No script, no storage, no live data (seen).

### A3. TS06-FASCIA Buy List
- **URL:** (link in the owner's artifact list) · **updated** 2026-09-09 (seen, list)
- **Form:** single page, no published files, no runtime capabilities, so no asset store (seen). About 15 KB (inferred, estimated from the read).
- **Holds (seen):**
  - A tickable checklist for 15 fascia boards (10 units + 5 spares), with a live "n / N ticked" tally.
  - Step 1: one JST S6B-PH-SM4-TB side-entry SMD connector to check the footprint before the board order; Step 2: the bulk connector buy with a pack-size question, and how to spot a through-hole clone.
  - 1206 resistors (4.7 k 1 % ×100, 10 k ×100, 20 k ×100) with the reason for 1 %; cable side (PHR-6 housings, SPH-002T-P0.5 contacts, 26 AWG six-colour wire); tools (PH crimper IWS-3220 class, flux, tweezers, wick, loupe, IPA).
  - The board: TS06-FASCIA 176 × 52, 2.0 mm, ENIG "not optional" (the gold artwork); "already yours" counts for rotary, МТ1 and КМД1-1 (have 1/10/11 of 20).
  - Four open questions (listing pack size, 6-way housings in the owner's box, crimper fit, bushing stack depth).
- **Personal data:** contains seller or personal details (not copied): one seller handle next to the МТ1 levers, and marketplace listing prices.
- **Images / 3D:** none (seen).
- **Superseded by today's design:** the board line "176 × 52" (today 176 × 40, or 191.4 × 40 variants) (seen, PCB/README.md, TS06-FASCIA-variants.md); the note that the main-board end is JST-XH with an XH crimper (today's TS06-DRV J1 is a top-entry connector on a JST PH cable) (inferred from PCB/README.md "fascia cable (JST PH)").
- **Still current:** the SMD connector, resistor values and counts, cable parts, tools, ENIG requirement, and the control-part counts (inferred; not checked against PCB/TS06-*/bom.md).
- **Unique:** the purchasing checklist itself, the "have n of 20" counts, the fake-listing advice and the open buying questions (inferred unique; the repo BOMs cover the pair, not these notes). The owner's tick state lives only in the owner's browser (seen: localStorage key "ts06-buylist-v1").
- **Target view:** Parts and buying.
- **Effort:** S. Static rows plus a 20-line tick script; the only care is personal data and the tick state.
- **Risks:** localStorage for ticks (per-viewer; ticks do not move with the page, and a shared page would need a shared-state capability instead) (seen). Seller handle and prices must not be carried over verbatim (seen). Google Fonts only (seen). Dark-only palette (seen).
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

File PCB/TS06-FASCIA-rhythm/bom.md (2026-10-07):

# TS06-FASCIA-rhythm (fascia R) rev B: bill of materials

Hand-written from `tools/mkpcb_fascia_rhythm.py` (its `VALUE` and `FP` tables); there was no BOM for the fascia before. The pair's BOMs
(`PCB/TS06-DISP/bom.md`, `PCB/TS06-DRV/bom.md`) are generated by `tools/bom_pair.py`; this one is not. Board: 191.4 x 40 mm, 2.0 mm FR4,
black mask, white silk, ENIG (`fab/ORDER.md`). Every part is on the back, soldered by hand; no plated hole.

| Qty | Part | Refs | Footprint | Notes |
|---|---|---|---|---|
| 1 | **JST B6B-PH-SM4-TB**: PH 2.0 mm, 6 way, **top entry (upright)**, SMD, two retention tabs | J1 | `TS06_JST_PH_B6B-PH-SM4-TB_Back` | **Rev B (7 October 2026); rev A had the side-entry S6B-PH-SM4-TB.** The plug (PHR-6) stands straight off the back and the wires leave straight back. The tabs carry the load. Pin 1 = +5V at the right seen from the front. Header height 6.0 mm *inferred* (`PCB/TS06-FASCIA-rhythm/J1-UPRIGHT.md`) |
| 1 | SR25-style 6-position rotary (galette), panel mount, 12 detents of 30 degrees | SW1 | `TS06_Rotary_SR25_PanelMount_Rhythm` | MODE; bushing 8.62 mm in a 9.2 mm hole (opened 0.4 mm in the ordered zip); body 25.00 mm behind the panel |
| 2 | МТ1 toggle lever, panel mount | SW2, SW3 | `TS06_MT1_Lever_PanelMount` | FIELD, SUB; bushing 7.82 mm in an 8.4 mm hole (ordered zip) |
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

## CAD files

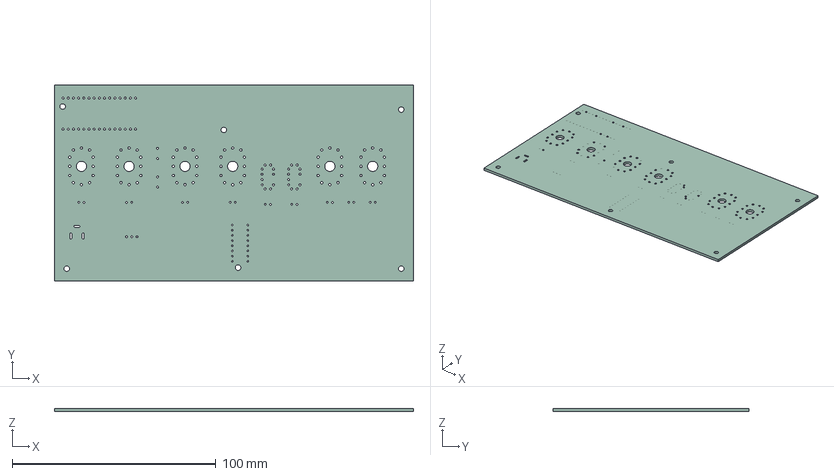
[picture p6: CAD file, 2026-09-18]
3d/TS06-MAIN.step
176.0 x 96.0 x 1.51 mm

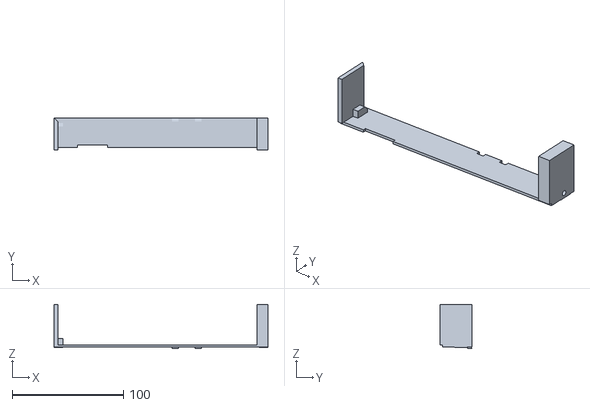
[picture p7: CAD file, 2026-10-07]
3d/case-pair/out/trench.stl
192.4 x 28.5 x 39.9

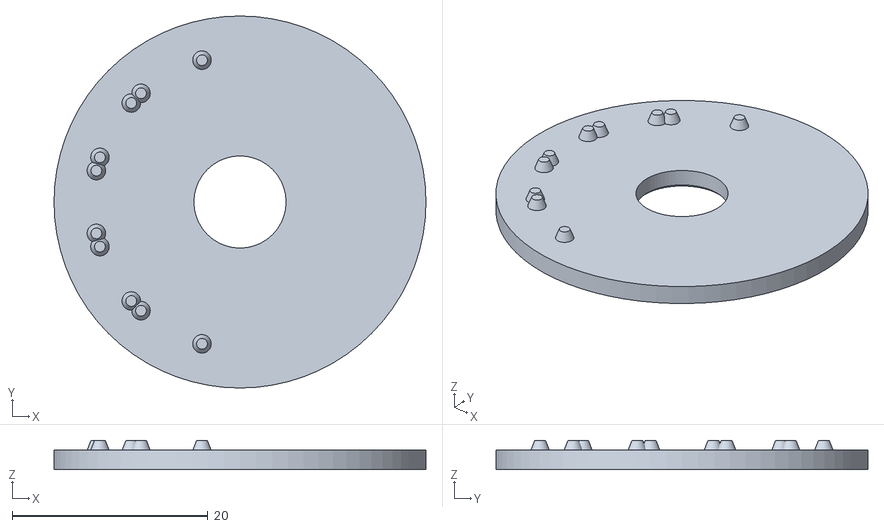
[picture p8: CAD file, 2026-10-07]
3d/jig/jig_plate_L2.stl
38.0 x 38.0 x 3.00

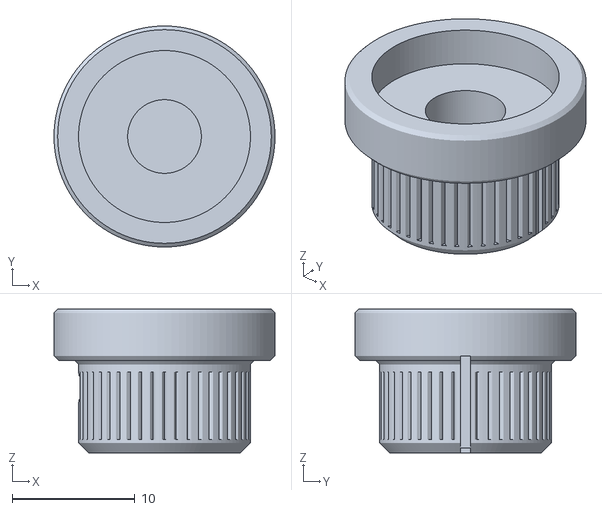
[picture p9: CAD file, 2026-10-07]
3d/knob/knob_C.stl
18.0 x 18.0 x 11.7

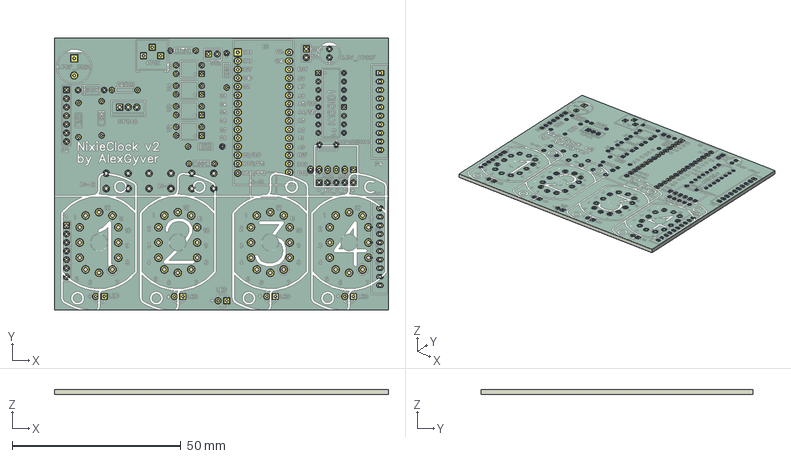
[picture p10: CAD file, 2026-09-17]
PCB/IN-12_norm/gyver.step
99.1 x 80.8 x 1.66 mm
gyv93DA_copper
gyv93DA_via
gyv93DA_silkscreen x 2
gyv93DA_soldermask x 2
gyv93DA_PCB

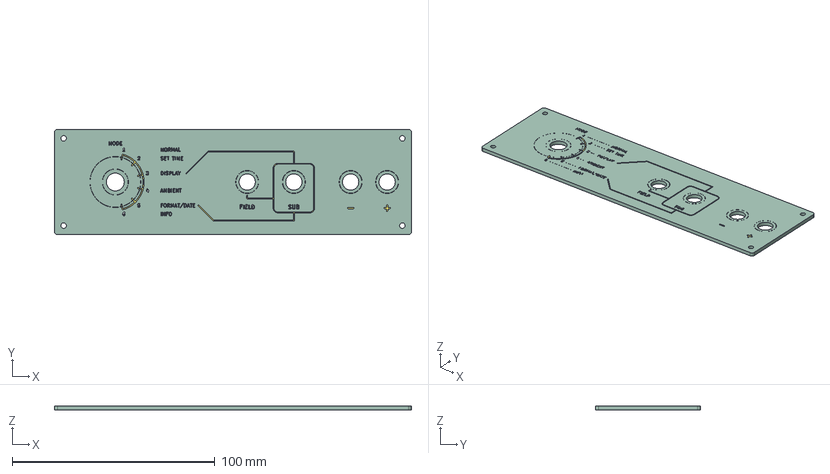
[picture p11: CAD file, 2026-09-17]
PCB/TS06-FASCIA/TS06-FASCIA.step
176.0 x 52.0 x 2.06 mm
TS01272_copper
TS01272_silkscreen x 2
TS01272_PCB

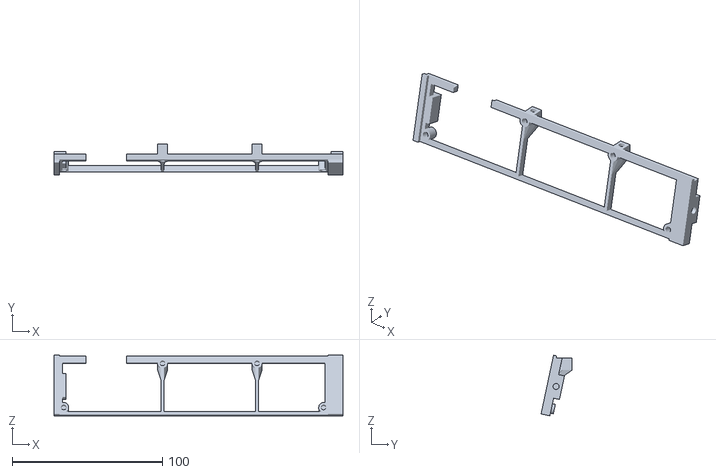
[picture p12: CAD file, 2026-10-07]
3d/case-pair/out/fascia_frame.stl
192.4 x 20.6 x 40.4

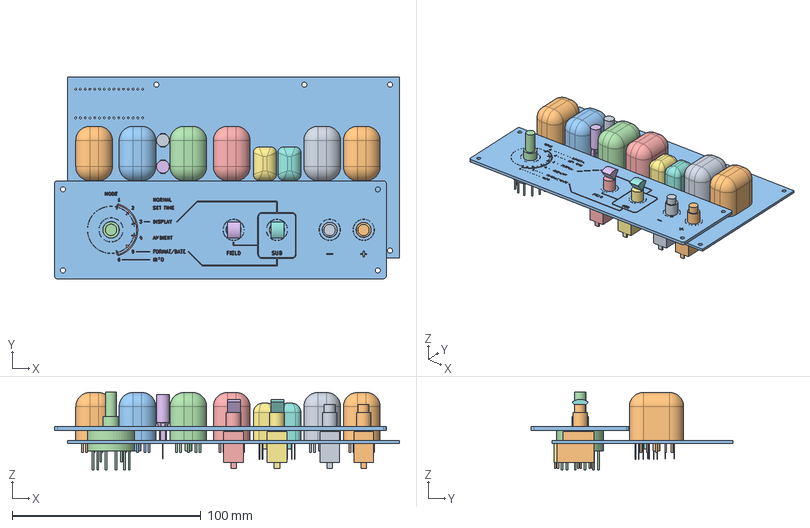
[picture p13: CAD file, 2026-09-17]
3d/Clock.FCStd
183.0 x 107.0 x 41.3 mm
INS1
IN12_BODY
IN12_BODY001
IN12_BODY002
IN12_BODY003
INS001
IN17
IN001
IN12_BODY004
IN12_BODY005
TS01272_copper
TS01272_copper001
TS01272_copper002
TS01272_copper003
TS01272_copper004
TS01272_copper005
TS01272_copper006
TS01272_copper007
TS01272_copper008
TS01272_copper009
TS01272_copper010
TS01272_copper011
TS01272_copper012
TS01272_copper013
TS01272_copper014
TS01272_silkscreen
TS01272_silkscreen001
TS01272_silkscreen002
TS01272_silkscreen003
TS01272_silkscreen004
TS01272_silkscreen005
TS01272_silkscreen006
TS01272_silkscreen007
TS01272_silkscreen008
TS01272_silkscreen009
TS01272_silkscreen010
TS01272_silkscreen011
TS01272_silkscreen012
TS01272_silkscreen013
TS01272_silkscreen014
TS01272_silkscreen015
TS01272_silkscreen016
TS01272_silkscreen017
TS01272_silkscreen018
TS01272_silkscreen019
TS01272_silkscreen020
TS01272_silkscreen021
TS01272_silkscreen022
TS01272_silkscreen023
TS01272_silkscreen024
TS01272_silkscreen025
TS01272_silkscreen026
TS01272_silkscreen027
TS01272_silkscreen028
TS01272_silkscreen029
TS01272_silkscreen030
TS01272_silkscreen031
TS01272_silkscreen032
TS01272_silkscreen033
TS01272_silkscreen034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

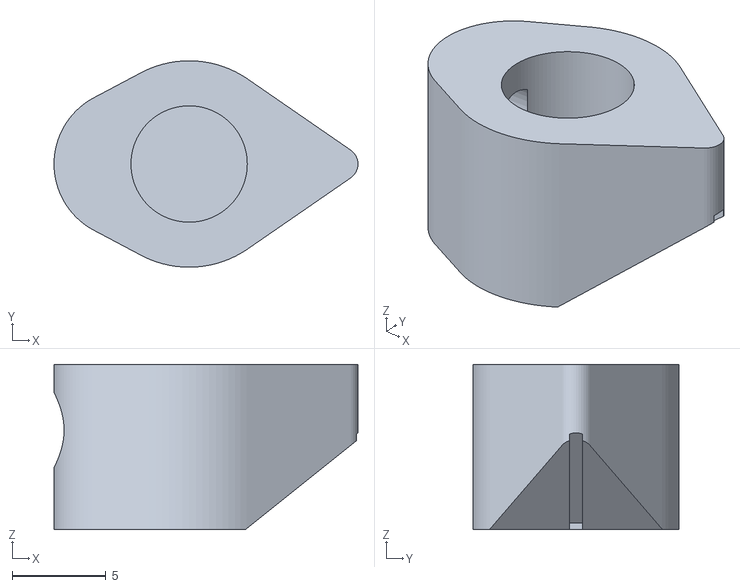
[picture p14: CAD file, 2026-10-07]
3d/knob/knob_B.stl
16.2 x 11.0 x 8.80

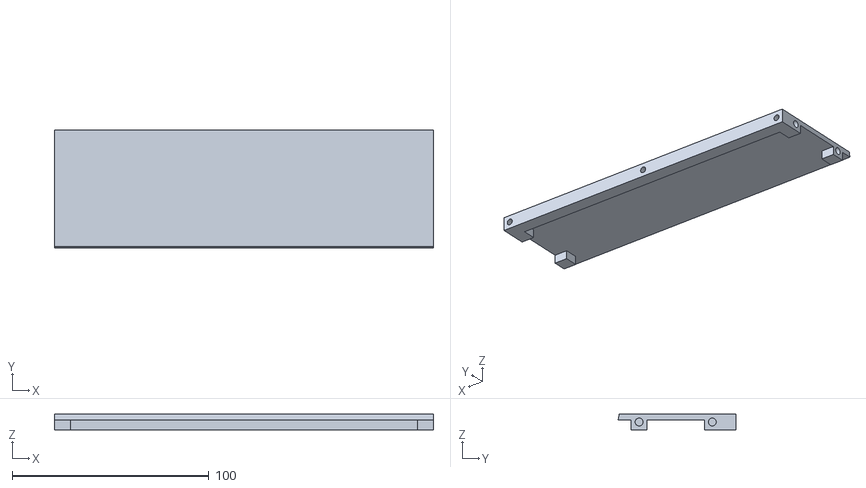
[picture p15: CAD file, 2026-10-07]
3d/case-pair/out/top.stl
192.4 x 59.9 x 8.00

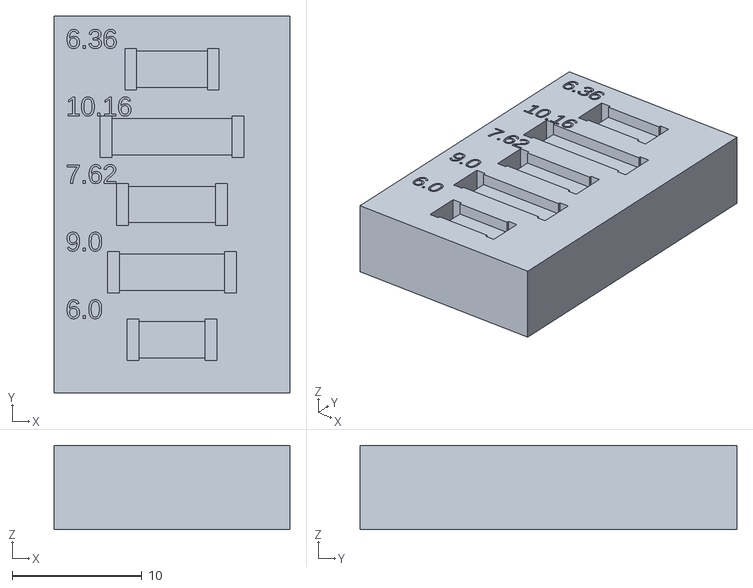
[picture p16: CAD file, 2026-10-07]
3d/jig/jig_former.stl
18.2 x 29.0 x 6.50

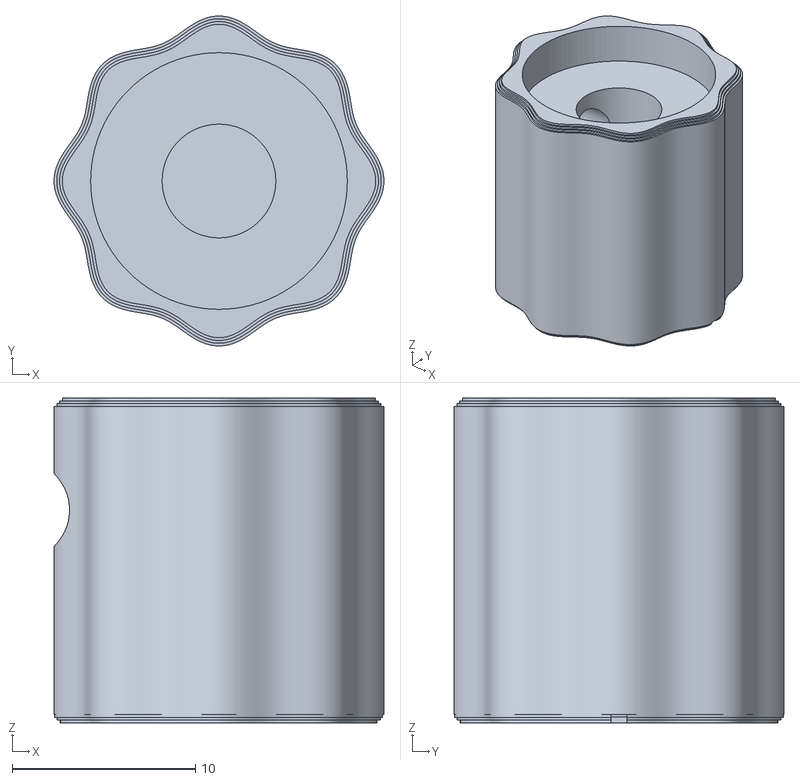
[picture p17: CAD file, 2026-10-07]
3d/knob/knob_A_uncut.stl
18.0 x 18.0 x 17.7

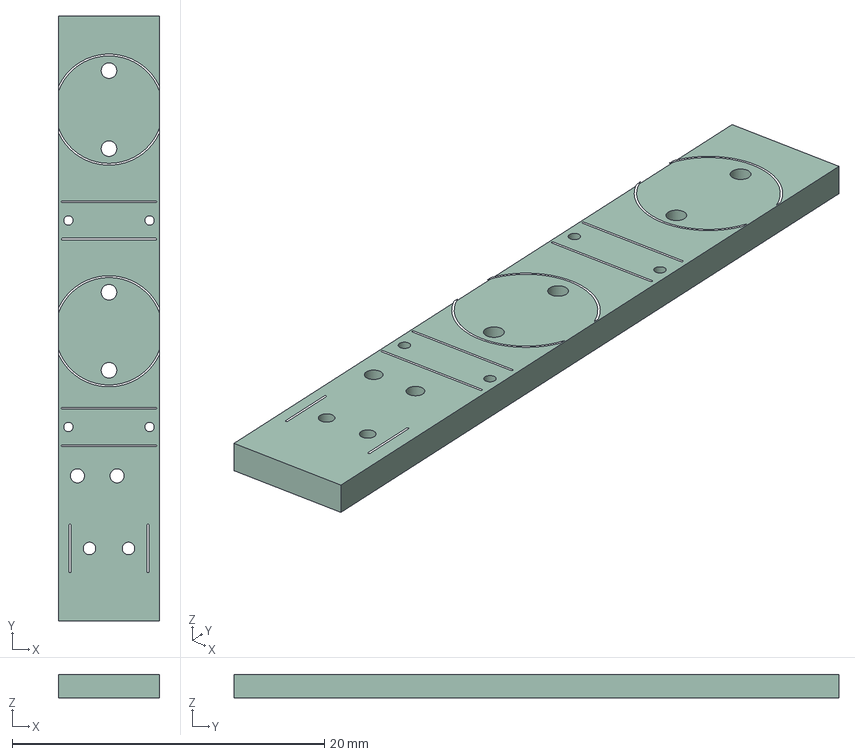
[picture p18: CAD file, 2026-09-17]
3d/TS06-COLON.step
6.50 x 38.8 x 1.58 mm
TS06-COLON_silkscreen
TS06-COLON_PCB

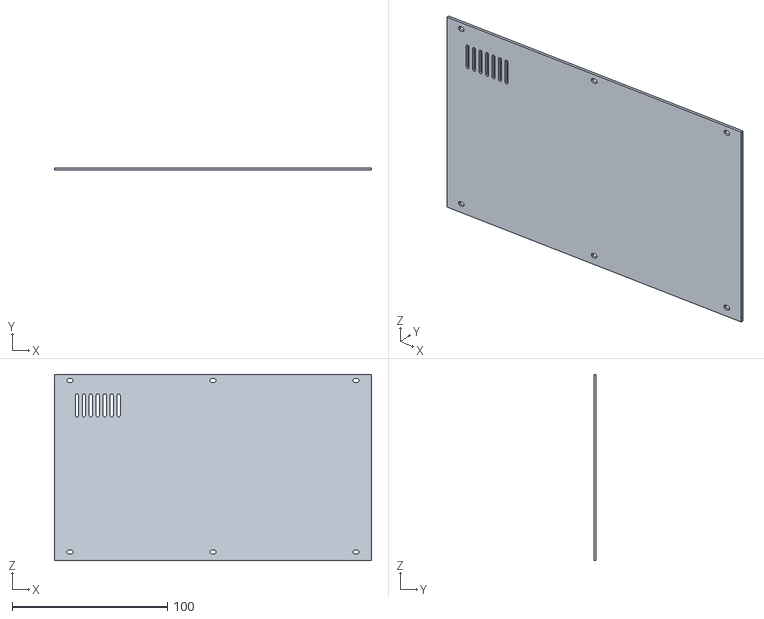
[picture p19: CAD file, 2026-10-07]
3d/case-pair/out/rear.stl
204.4 x 1.60 x 120.0

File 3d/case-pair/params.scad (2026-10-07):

// params.scad - GENERATED by case_pair.py from boards.json and the DIMS table. Do not edit:
// change case_pair.py (or pass -D NAME=value to openscad for a quick what-if) and regenerate.
// World frame: X across the front from the clock's left, Y up (FreeCAD assembly), Z depth
// from the ИН-12 glass front, + toward the back. case.scad maps x = X, y = Z, z = Y.
// Kinds: board = read from the board files; doc = stated in a repo document; design = chosen
// here; assumed = typical value, not yet measured.


// ---- boards
BOARD_W            = 191.4;  // [board] tools/mkpcb_disp.py W = tools/mkpcb_drv.py W
DISP_H             = 44;  // [board] tools/mkpcb_disp.py H
DISP_TOP_Y         = 78;  // [board] tools/mkpcb_disp.py TOP: world Y of TS06-DISP's top edge
DRV_H              = 100;  // [board] tools/mkpcb_drv.py H
DRV_Y0             = 26;  // [board] tools/mkpcb_drv.py Y0: TS06-DRV's top edge is 26 above TS06-DISP's
PCB_T              = 1.6;  // [board] tools/pcbkit.py Board.thickness (both boards)
FASCIA_W           = 176;  // [board] PCB/TS06-FASCIA/TS06-FASCIA.kicad_pcb Edge.Cuts
FASCIA_H           = 40;  // [board] PCB/TS06-FASCIA/TS06-FASCIA.kicad_pcb Edge.Cuts (was 52, PCB/README.md)
FASCIA_X0          = 4.305;  // [design] the owner, 29.09.26: the fascia centred under the tube row, on the middle of H10 and ИН-15А (X 92.305), kept within the board width
FASCIA_T           = 2;  // [doc] PCB/README.md: TS06-FASCIA 2.0 mm FR4
FASCIA_HOLE_D      = 2.7;  // [board] TS06-FASCIA.kicad_pcb mounting holes (M2.5)

// ---- stack
PBS_H              = 8.5;  // [doc] PCB/TS06-DRV/bom.md: socket strip PBS, 8.5 mm (review finding 1: PBS runs 7.0-8.5)
PLS_BODY           = 2.5;  // [doc] PCB/TS06-DISP/bom.md: 11 mm = 8.5 PBS + 2.5 PLS body
IN12_W             = 19.47;  // [doc] 3d/IN12.FCStd envW (render/rev_f.py DIMS)
IN12_H             = 28.86;  // [doc] 3d/IN12.FCStd envH (render/rev_f.py DIMS)
IN12_D             = 25.5;  // [doc] 3d/IN12.FCStd envD: glass front to rear seating plane (measurements-IN12)
IN12_DIGIT         = 18.63;  // [doc] render/rev_f.py DIGIT_12, caliper 27.08
IN12_SEAT          = 4.5;  // [assumed] socket seat: review puts the socketed glass front ~30 in front of TS06-DISP; TS06-LIB-SOCKET is not captured
IN17_FACE          = 14;  // [doc] ИН-17 outline drawing: face 14 (measurements-IN17 Rev 5)
IN17_H             = 20;  // [doc] ИН-17 outline drawing: 20 across the long face axis
IN17_D             = 19.72;  // [measured] the owner's bench caliper, 2026-10-02: ИН-17 glass 19.72 from the dome to the end of the glass (the outline drawing's 22 is not glass + pip: 19.72 + IN17_PIP is about 23.7)
IN17_PIP           = 4;  // [estimate] the owner's estimate, 2026-10-02: the exhaust pip under the glass end, between the leads, about 4 mm (not a caliper reading). The drawing's 22 is therefore no longer glass + pip; IN17_D stays the measured 19.72
IN17_STEM          = 20;  // [doc] ИН-17 outline drawing: round stem Ø20 at the base
IN17_DIGIT         = 9;  // [doc] render/rev_f.py DIGIT_17
IN17_STANDOFF_MIN  = 6.4;  // [doc] TS06_IN17_Socket descr: >= 6.4 mm glass to board (TU: no solder within 8 mm)
GLASS_ALLOW        = 0.4;  // [doc] TERMINAL-06-cad-component-library.md §7: glass gets max-of-sample + 0.4
LED_D              = 3;  // [board] TS06_LED_D3.0mm
LED_H              = 5.3;  // [assumed] 3 mm LED body height above the board
LED_FLANGE_D       = 3.8;  // [assumed] 3 mm LED flange diameter
INS1_D             = 6.97;  // [doc] TS06_INS1_Lamp descr: measured 6.97 mm envelope
PIN_TAIL           = 1.5;  // [assumed] trimmed through-hole lead + fillet proud of a board face
SCREW_HEAD         = 2;  // [assumed] M3 low head (DIN 7984 2.0; ISO 7380 1.65) - review finding 3
SCREW_HEAD_D       = 5.5;  // [assumed] M3 low-head diameter

// ---- design
CHEEK_T            = 6;  // [doc] pair review, envelope: 6 mm cheeks
CHEEK_CLR          = 0.5;  // [doc] pair review, envelope: 0.5 mm each side
GLASS_RECESS       = 1;  // [design] tube glass sits 1 mm behind the face plane, so a knock lands on the case
SILL_TOP_Y         = 39;  // [design] trench floor: above the XP21-25 pads (37.55; review: >= 38), below the ИН-17 LEDs' flange (41.49 - 1.9 = 39.59)
SILL_T             = 2;  // [design] printed
BACK_GAP           = 2.5;  // [design] no case part closer than this to TS06-DISP's front face (pin tails, screw heads)
TRENCH_L_X         = 3;  // [doc] pair review 4: the trench's left wall hides XP11, the left 3 mm
TRENCH_R_X         = 182.035;  // [design] right wall: ИН-15А (V10) glass + GLASS_ALLOW + 0.5, still hiding the H4 standoff screw and XP12's end
BROW_CLR           = 0.8;  // [design] soffit above the tall glass: 2 x GLASS_ALLOW
VALANCE_Y0         = 74;  // [doc] pair review 3: the brow covers the display board's top 4 mm (78 - 4)
VALANCE_T          = 1.5;  // [design] printed rib behind the ИН-17 pair
BROW_T             = 3;  // [design] printed brow face
SOFFIT_T           = 2;  // [design] printed
BROW_RAKE          = 12;  // [doc] spec §6: front raked 12° - the brow leans back like the fascia
TOP_T              = 3;  // [design] printed top plate, black like the chassis (case review m5; spec §6: chassis matte black)
MOD_CLR            = 0.5;  // [doc] the module's clearance to a case part it slides past: the pair review's 0.5 to each cheek
END_BLOCK          = 8;  // [doc] case review F7: every insert a cheek screw goes into sits in a block of at least 8 mm
TOP_CLR            = 5.5;  // [design] TS06-DRV's top edge to the top plate's underside: MOD_CLR + END_BLOCK - TOP_T, so the plate's rear block (the rear panel's inserts, the cheek screws) clears the board; was the pair review's 3
REAR_AIR           = 5;  // [doc] pair review, envelope: 5 mm of air in front of the rear panel
REAR_T             = 1.6;  // [doc] pair review suggestion 2: the rear panel is a 1.6 mm FR4 blank
BASE_T             = 3;  // [design] printed or 3 mm aluminium
KICK_T             = 2;  // [design] the raked strip under the fascia; thin enough to clear the fascia plug
FASCIA_RAKE        = 12;  // [doc] spec §6 and cad-component-library: front raked 12°
FLOOR_CLR          = 0.5;  // [design] between the fascia lead's lowest point and the floor
FLOOR_REV_A        = -7.3;  // [doc] this model's floor with fascia R rev A's side-entry J1 (checks.md row 8 of 3d/case-pair at 15f1d4d): kept to say how much the upright J1 saves
VENT_W             = 2;  // [doc] pair review 4: slots no wider than 2.5 mm (2.0 used)
VENT_X0            = 6.9;  // [board] case review m4: over the logic side - a 30 mm span (the pair review's) centred on U1, the Nano (courtyard X -2.4-43.8 in mkpcb_drv)
VENT_X1            = 36.9;  // [board] VENT_X0 + 30
VENT_Y0            = 85;  // [doc] pair review suggestion 2: world Y 85-100 (inside the Nano's Y 85.2-103.5)
VENT_Y1            = 100;  // [doc] pair review suggestion 2
VENT_PITCH         = 4.5;  // [design] 
VENT_HV_CLR        = 5;  // [design] no 185 V part (a pad on an HV-class net) within this of the vent field, projected
BOSS_W             = 8;  // [design] square boss on a cheek's inner face, M3 heat-set insert
BOSS_D             = 10;  // [design] boss length in Z, in front of TS06-DRV
FBOSS_D            = 8;  // [design] fascia boss depth behind the fascia
JACK_HOLE_D        = 9;  // [doc] pair review suggestion 3: Ø9 through
JACK_CB_D          = 14;  // [doc] pair review suggestion 3: Ø14 pocket (put on the OUTSIDE here - see checks)
JACK_WEB           = 1.5;  // [doc] pair review suggestion 3: thin the cheek to 1.5-2 mm
USB_SLOT_W         = 12;  // [doc] pair review suggestion 3: slot about 12 x 9 (12 along Y)
USB_SLOT_H         = 9;  // [doc] pair review suggestion 3 (9 along Z)
VIEW_DEG           = 10;  // [doc] cad-component-library §5 / spec §6: brow clearance at a 10° viewing angle
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

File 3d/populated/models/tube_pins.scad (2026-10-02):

// What the nixie tubes of TS06-DISP stand on. Made for 3d/populated.
//
// layers: sleeve=#d1ad45 wire=#c9cdd1 pip=#e3e7ea
// variants: in12_contacts MODE=0 ; in17_wires MODE=1 ; in17_pip MODE=2
//
// FRAME  KiCad model frame (a footprint's y negated), origin = the footprint origin, z up from the board face.
//
// in12_contacts (V1-V4, V9, V10)   twelve tube-socket contacts on the TS06_IN12_Socket pad ring, one per pad.
//   pad positions    MEASURED (repo source): PCB/lib/TS06.pretty/TS06_IN12_Socket.kicad_mod, pads 1-12
//   sleeve height    4.5 mm      INFERRED: case_pair.py IN12_SEAT 4.5 (assumed there: "TS06-LIB-SOCKET is not captured"). The
//                                tube model (3d/IN12.step) is placed with its glass 4.5 mm above the board face to match.
//   sleeve D1.7, bore not drawn, tail D1.0 to 1.0 mm past the back face   INFERRED; PCB/TS06-DISP/bom.md only says
//                                "tube socket contact, 12 per tube, tail to suit the 1.2 mm hole"
//
// in17_wires (V5, V6)    the wire leads of the IN-17 between the end of the model's own stubs and the board.
//   pad positions    MEASURED (repo source): TS06_IN17_Socket.kicad_mod, the 11 pads (the 12th lead is absent)
//   why             3d/IN17.step carries only 5.5 mm of lead, and tools/models3d.json scales the whole model along the tube's
//                   axis by 19.72 / 24.3 (the owner's bench caliper, 2026-10-02: the glass is 19.72 from the dome to the end of
//                   the glass), so its stubs are 4.46 mm long. With the glass end STANDOFF = 10.28 mm off the board (case_pair.py
//                   IN17_STANDOFF = Z_DISP_F - IN17_D, so the faces are coplanar with the IN-12s) the stubs end 5.82 mm above
//                   the board, so wires D0.4 are drawn from there down to 0.8 mm past the back face.  INFERRED
//                   (wire D0.4; the stubs in IN17.step measure 0.3 across).  See README.md, open item "IN-17 leads".
//
// in17_pip (V5, V6)      the exhaust pip of the IN-17, standing out of the glass end between the leads.
//   length          4.0 mm      THE OWNER'S ESTIMATE, 2026-10-02 (case_pair.py IN17_PIP, kind estimate): "closer to 4 mm". Not a caliper
//                               reading. The outline drawing's 22 mm is therefore not the glass (19.72, measured) plus the pip.
//   diameter 3.5, round tip     INFERRED (the lead pattern is 5.6 mm across, so a pip under 5 mm stands between the rows).
//   place           centred on the lead pattern; the tip 4.0 mm below the glass end, 6.28 mm above the board face.
STANDOFF = 10.28;     // the glass end above the board face: case_pair.py IN17_STANDOFF
PIP = 4.0;            // case_pair.py IN17_PIP
STUB_END = STANDOFF - 5.5 * 19.72 / 24.3;      // where the model's scaled stubs end above the board: 5.82
MODE = 0;
L = "sleeve";

IN12 = [[-3.981, -8.002], [0.000, -8.990], [3.987, -8.002], [5.741, -4.494], [5.741, 0.000], [5.741, 4.495],
        [3.987, 8.000], [0.000, 8.991], [-3.981, 8.000], [-5.742, 4.495], [-5.742, 0.000], [-5.742, -4.494]];
IN17 = [[2.7774, -1.5], [2.7774, -4.0], [1.3649, -6.0], [-1.3651, -6.0], [-2.7776, -4.0], [-2.8576, -1.5],
        [-2.8176, 1.1425], [-2.7776, 3.6825], [-1.3651, 5.6825], [1.3649, 5.6825], [2.7774, 3.6825]];

if (MODE == 0 && L == "sleeve") for (p = IN12) {
    translate([p[0], -p[1], -2.6]) cylinder(d = 1.0, h = 2.6 + 0.2, $fn = 14);
    translate([p[0], -p[1], 0]) cylinder(d = 1.7, h = 4.5, $fn = 18);
}
if (MODE == 1 && L == "wire") for (p = IN17) translate([p[0], -p[1], -2.4])
    cylinder(d = 0.4, h = 2.4 + STUB_END + 0.1, $fn = 10);
if (MODE == 2 && L == "pip") translate([-0.04, 0.16, 0]) hull() {
    translate([0, 0, STANDOFF - PIP + 1.75]) sphere(d = 3.5, $fn = 24);
    translate([0, 0, STANDOFF + 0.09]) cylinder(d = 3.5, h = 0.01, $fn = 24);
}

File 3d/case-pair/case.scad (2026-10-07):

// case.scad - TS06-DISP + TS06-DRV case, concept A.
//
// Two cheeks carry everything (Rev F's idea, kept): the electronics module (TS06-DISP riding on
// TS06-DRV) hangs from four bosses, the fascia from four more, and a brow, a top plate, a trench
// frame, a base and a rear panel close the box between them. Every number is a named variable in
// params.scad with its source; this file only derives from them (the same maths as case_pair.py,
// which also runs the checks and draws the dimensioned sheets).
//
//   openscad -D 'PART="assembly"' case.scad          assembly (also: module, cheek_l, cheek_r, brow,
//                                                     top, trench, base, rear, fascia_blank,
//                                                     fascia_frame, none)
//   openscad -D EXPLODE=1 ...                         pulled apart
//   openscad -D FASCIA_FRAME=1 ...                    variant D: the fascia in a printed frame
//
// World frame: X across the front from the clock's left, Y up (FreeCAD assembly), Z depth from
// the ИН-12 glass front, + toward the back. OpenSCAD: x = X, y = Z, z = Y (the clock faces -y).

include <params.scad>

PART = "assembly";
EXPLODE = 0;
$fn = 40;

// ============================================================ derived (mirrors case_pair.py)
r  = FASCIA_RAKE;
rb = BROW_RAKE;
Z_FACE     = -GLASS_RECESS;                         // the face plane: brow front, fascia top edge
Z_DISP_F   = IN12_D + IN12_SEAT;                    // TS06-DISP front face
Z_DISP_B   = Z_DISP_F + PCB_T;
STACK_GAP  = PBS_H + PLS_BODY;                      // 11: review finding 1 - measure the strips
Z_DRV_F    = Z_DISP_B + STACK_GAP;                  // TS06-DRV, display-facing face
Z_DRV_B    = Z_DRV_F + PCB_T;                       // TS06-DRV, component face (toward the rear)
Z_BACK     = Z_DISP_F - BACK_GAP;                   // no case part behind this, in front of TS06-DISP
IN17_STANDOFF = Z_DISP_F - IN17_D;                  // ИН-17 faces coplanar with the ИН-12s
NANO_H     = PBS_H + PLS_BODY + NANO_PCB_T + USB_H;
DISP_BOT_Y = DISP_TOP_Y - DISP_H;
DRV_TOP_Y  = DISP_TOP_Y + DRV_Y0;
DRV_BOT_Y  = DRV_TOP_Y - DRV_H;
IN12_TOP   = IN12_Y + IN12_H / 2;
IN12_BOT   = IN12_Y - IN12_H / 2;
SOFFIT_Y   = round((IN12_TOP + BROW_CLR) * 100) / 100;
Y_TOP_IN   = DRV_TOP_Y + TOP_CLR;
Y_TOP      = Y_TOP_IN + TOP_T;
X_IN_L = -CHEEK_CLR;            X_IN_R = BOARD_W + CHEEK_CLR;
X_OUT_L = X_IN_L - CHEEK_T;     X_OUT_R = X_IN_R + CHEEK_T;
PART_MAX   = max([for (p = DRV_PARTS) if (p[6] == 0) p[5]]);
Z_REAR_IN  = Z_DRV_B + PART_MAX + REAR_AIR;
Z_REAR_OUT = Z_REAR_IN + REAR_T;

// the fascia: its front face passes through the sill's front edge (SILL_TOP_Y, Z_FACE), raked back.
// fpt(t, s) = [Y, Z] of the point t down the face from the top edge and s behind the front face.
function fpt(t, s = 0) = [SILL_TOP_Y - t * cos(r) - s * sin(r), Z_FACE - t * sin(r) + s * cos(r)];
function zy(p) = [p[1], p[0]];
FAS_BOT    = fpt(FASCIA_H);
Z_SILL_F   = Z_FACE + FASCIA_T / cos(r) + 0.2;

// the fascia's own J1 (fascia R rev B) is UPRIGHT: the plug stands off the back along the fascia's normal and the wires leave its top straight
// back into the case, over the pin row. The floor is the model's rule on the lead's lowest point at the plug (never above the frame's Y 0),
// held down by the base's end blocks, which have to clear TS06-DRV's bottom edge by MOD_CLR as the module slides out (checks.md, 7 and 8)
FJ_EXIT  = fpt(FJ_PIN_T, FASCIA_T + FJ_MATED_H);
FJ_LOW_Y = FJ_EXIT[0] - CABLE_HALF;
Y_FLOOR_LEAD  = min(0, floor((FJ_LOW_Y - FLOOR_CLR) * 10) / 10);
Y_FLOOR_SWEEP = floor((DRV_BOT_Y - END_BLOCK - MOD_CLR) * 10) / 10;
Y_FLOOR  = min(Y_FLOOR_LEAD, Y_FLOOR_SWEEP);
Y_BOT    = Y_FLOOR - BASE_T;
Z_TOE    = Z_FACE - (SILL_TOP_Y - Y_FLOOR) * tan(r);
Z_BROW_TOP = Z_FACE + (Y_TOP - SOFFIT_Y) * tan(rb);
OUT_W = X_OUT_R - X_OUT_L;  OUT_H = Y_TOP - Y_BOT;  OUT_D = Z_REAR_OUT - Z_TOE;

// openings
JACK_Y = JACK_PIN1[1];
JACK_Z = Z_DRV_B + JACK_AXIS_H;
JACK_MOUTH_X = JACK_PIN1[0] + JACK_BODY_L - 0.8;    // F.Fab: the mouth is 13.7 from pin 1
USB_X = NANO_BOX[0];
USB_Y = (NANO_ROWS_Y[0] + NANO_ROWS_Y[1]) / 2;
USB_Z = Z_DRV_B + PBS_H + PLS_BODY + NANO_PCB_T + USB_H / 2;

// the brow's rib behind the ИН-17 pair, between M1's and ИН-15Б's glass
VAL_X0 = IN12_X[3] + IN12_W / 2 + GLASS_ALLOW;
VAL_X1 = IN15_X[0] - IN12_W / 2 - GLASS_ALLOW;

// the SR25's rim rises above the sill's underside close behind the fascia's top edge: the sill steps back over it
ROT = FASCIA_CTRL[0];                               // ["SW1", x, y, hole]
ROT_T_TOP = ROT[2] - ROTARY_D / 2;
ROT_S_CLR = (SILL_TOP_Y - ROT_T_TOP * cos(r) - (SILL_TOP_Y - SILL_T - 0.5)) / sin(r);
SILL_NOTCH_Z  = round(max(Z_SILL_F, fpt(ROT_T_TOP, ROT_S_CLR)[1]) * 100) / 100;
SILL_NOTCH_X0 = FASCIA_X0 + ROT[1] - ROTARY_D / 2 - 1;     // world X: the fascia is centred
SILL_NOTCH_X1 = FASCIA_X0 + ROT[1] + ROTARY_D / 2 + 1;

// ---- fixings (case review F7): every cheek screw goes into a heat-set insert in an END_BLOCK block
function zin(y) = Z_FACE + (y - SOFFIT_Y) * tan(rb) + BROW_T / cos(rb);   // the brow face's inside
EB = END_BLOCK;
FIX_BASE_Y  = (Y_BOT + Y_FLOOR + EB) / 2;
FIX_BASE_Z  = [BASE_FIX_Z, Z_REAR_IN - REAR_FIX_DZ];
WALL_BLK_Y1 = IN12_BOT - GLASS_BLK_CLR;                     // under H10's and ИН-15А's glass
WALL_BLK_Y0 = min(SILL_TOP_Y - SILL_T, WALL_BLK_Y1 - EB);
FIX_WALL_Y  = (WALL_BLK_Y0 + WALL_BLK_Y1) / 2;
FIX_BROW_Y  = (SOFFIT_Y + SOFFIT_T + Y_TOP_IN) / 2;
FIX_BROW_Z  = zin(FIX_BROW_Y) + EB / 2;
FIX_TOP_Y   = Y_TOP - EB / 2;
FIX_TOP_Z   = [TOP_FIX_Z, Z_REAR_IN - REAR_FIX_DZ];
TOP_LIP_Y0  = Y_TOP - EB;                                   // TS06-DRV's top edge + MOD_CLR
FF_FIX      = fpt(FF_FIX_T, FASCIA_T + EB / 2);             // [Y, Z]: the fascia frame's end blocks
CHEEK_FIX = concat([for (z = FIX_BASE_Z) [FIX_BASE_Y, z]], [[FIX_WALL_Y, WALL_FIX_Z], [FIX_BROW_Y, FIX_BROW_Z]],
                   [for (z = FIX_TOP_Z) [FIX_TOP_Y, z]], FASCIA_FRAME ? [FF_FIX] : []);
// the rear panel (m4): corners and mid-span, along the bottom into the base's lip, along the top into the top plate's
REAR_SCREWS = [for (y = [FIX_BASE_Y, FIX_TOP_Y]) for (x = [X_IN_L + REAR_FIX_X, BOARD_W / 2, X_IN_R - REAR_FIX_X]) [x, y]];
// lead-ins (F8): the sill only where the lowest LEDs' flanges pass, so it still hides XP21-25
SILL_LEADS = [for (l = LEDS) if (l[1] - LED_FLANGE_D / 2 - SILL_TOP_Y < LEADIN_BELOW)
              [l[0] - LED_FLANGE_D / 2 - LEAD_MARGIN, l[0] + LED_FLANGE_D / 2 + LEAD_MARGIN]];
WALL_L_LEAD = IN12_X[0] - IN12_W / 2 - TRENCH_L_X < LEADIN_BELOW;

module check(name, a, b) echo(str(name, " scad=", a, " py=", b, abs(a - b) < 0.01 ? "  ok" : "  MISMATCH"));
check("Z_DISP_F", Z_DISP_F, PY_Z_DISP_F);
check("Z_DRV_B", Z_DRV_B, PY_Z_DRV_B);
check("PART_MAX", PART_MAX, PY_PART_MAX);
check("Z_REAR_IN", Z_REAR_IN, PY_Z_REAR_IN);
check("SOFFIT_Y", SOFFIT_Y, PY_SOFFIT_Y);
check("Y_FLOOR", Y_FLOOR, PY_Y_FLOOR);
check("Z_TOE", Z_TOE, PY_Z_TOE);
check("OUT_W", OUT_W, PY_OUT_W);
check("OUT_H", OUT_H, PY_OUT_H);
check("OUT_D", OUT_D, PY_OUT_D);
check("SILL_NOTCH_Z", SILL_NOTCH_Z, PY_SILL_NOTCH_Z);
check("SILL_NOTCH_X0", SILL_NOTCH_X0, PY_SILL_NOTCH_X0);
check("FIX_BASE_Y", FIX_BASE_Y, PY_FIX_BASE_Y);
check("WALL_BLK_Y0", WALL_BLK_Y0, PY_WALL_BLK_Y0);
check("WALL_BLK_Y1", WALL_BLK_Y1, PY_WALL_BLK_Y1);
check("FIX_BROW_Y", FIX_BROW_Y, PY_FIX_BROW_Y);
check("FIX_BROW_Z", FIX_BROW_Z, PY_FIX_BROW_Z);
check("FIX_TOP_Y", FIX_TOP_Y, PY_FIX_TOP_Y);
check("TOP_LIP_Y0", TOP_LIP_Y0, PY_TOP_LIP_Y0);
check("FF_FIX_Y", FF_FIX[0], PY_FF_FIX_Y);
check("FF_FIX_Z", FF_FIX[1], PY_FF_FIX_Z);
check("SILL_LEAD_X0", SILL_LEADS[0][0], PY_SILL_LEAD_X0);
check("REAR_SCREWS", len(REAR_SCREWS), PY_REAR_SCREWS);
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

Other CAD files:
3d/jig/jig_plate_L1.stl
3d/IN17.step
3d/jig/jig_shims.stl
3d/knob/knob_C_uncut.stl
3d/jig/jig.scad
3d/IN12.FCStd
3d/IN12.step
3d/IN17.FCStd
3d/INS1.FCStd
3d/INS1.step
3d/KMD1.step
3d/MT1.FCStd
3d/MT1.step
3d/SR25.FCStd
3d/SR25.step
3d/case-pair/out/base.stl
3d/case-pair/out/brow.stl
3d/case-pair/out/cheek_l.stl
3d/case-pair/out/cheek_r.stl
3d/case-pair/out/fascia_blank.stl
3d/case-pair/power-options/power_options.scad
3d/jig/jig_plate_flat.stl
3d/knob/knob.scad
3d/knob/knob_A.stl
3d/knob/knob_B_uncut.stl
3d/populated/models/axial_lying.scad
3d/populated/models/dip_chip.scad
3d/populated/models/ds3231_module.scad
3d/populated/models/fuse_ptc.scad
3d/populated/models/led3.scad
3d/populated/models/nano_on_pbs.scad
3d/populated/models/smd_fascia.scad

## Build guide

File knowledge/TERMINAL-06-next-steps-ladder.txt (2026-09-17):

# TERMINAL-06 — the ladder
 
**Created 06.09.26**, after a week trapped on P2. This doc exists to stop that happening again.
 
## The two rules
 
**1. One rung per sitting. Finish it, stop, and don't chain into the next one.**
 
**2. If a rung takes more than one evening, STOP and say so.** That is the tripwire. P2 ate a
week because nobody called it after night two. Anything that overruns gets re-scoped or parked
— it does not get pushed through.
 
**Rungs 3–7 cannot reopen the ghosting question.** None of them touch the digit multiplex.
That is deliberate: there is a run of work here with no route back into the swamp.
 
---
 
## Phase 1 — bank what already works (one evening, ~30 minutes total)
 
**Rung 1 — Commit and push the firmware.** *(10 min)*
Right now `BOARD_TYPE 0`, the timing constants, the `MUX_SLOTS` diagnostic and its comment block
all sit on unpushed local branches. That is the best work of the week and it exists in one place
on one machine.
**Done when:** it's on GitHub.
 
**Rung 2 — Set the time and leave it running.** *(5 min)*
Put it where you'll see it. Let it run overnight.
**Done when:** it's still showing the right time in the morning — which also silently confirms
the DS3231, the boost stage and thermal behaviour, three things never yet checked over hours.
 
**Rung 3 — Measure the HV rail.** *(10 min)*
One number, meter on 600 V DC, black lead clipped to ground before power-on. Closes **P3**,
open since the beginning.
**Done when:** a voltage is written into the prototype plan.
 
---
 
## Phase 2 — make it look like a product (one evening each, any order)
 
**Rung 4 — Fit the backlight LEDs.** Six amber on D11 PWM, pads already on the board.
**Done when:** the tubes glow from behind. Biggest visual change for the least work on this list.
 
**Rung 5 — Fit the colon.** 2× ИНС-1, **220 kΩ ballast each, never shared** (spec §3), low-side
MPSA42 on D10.
**Done when:** the colon blinks. This is the rung where it stops reading as a test rig and starts
reading as a clock.
 
**Rung 6 — Caliper the socket.** Seat height above PCB, tip-off pip projection, front-glass-to-
digit depth. Twenty minutes with the calipers.
**Done when:** `TS06-LIB-SOCKET` exists. Unblocks the case geometry, which is currently resting
on assumptions (the 32 mm floor / 17 mm centreline are still guesses).
 
**Rung 7 — Print the chassis and brow, test-fit.** Unattended machine time.
**Done when:** you're holding it and can see whether the brow reveal is right (spec §6).
 
---
 
## Phase 3 — the two that finish it
 
**Rung 8 — Build the SEC module.** 2× ИН-17 + their 2 TLP627s on D2/D13. Then set
`MUX_SLOTS 6` and look.
**This is the payoff rung.** If the empty-slot theory is right, the ghosting simply is not there
— the slots have real tubes and real anodes now. And if it is clean, **re-run the refresh sweep
before accepting the 50 Hz/camera-flicker concession**; that trade was priced under a wrong
model and may not need paying.
*By this point seven rungs are banked, so this one can fail without the project feeling stuck.*
 
**Rung 9 — Rotary fascia artwork.** Pure design, no electronics, no soldering. All the
dial-critical numbers are already measured (26.94 mm body, 6 mm shaft, 6 positions over ~160°).
Good rung for an evening with no patience for hardware.
 
---
 
## Parked, deliberately
 
- **TS06-TUBE** — decide it on tube-reveal geometry after rung 7, not on bleed resistors. Its
  resistor justification is withdrawn.
- **Anode-driver hardware** (MPSA92, HV shift registers) — not needed for this product. Kept in
  the study for QUADRANT and the decatron build.
- **The four fitted ИН-12 bleed resistors** — leave them in. Harmless, and desoldering risks
  joints for nothing.

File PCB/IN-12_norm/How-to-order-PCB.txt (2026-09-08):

How to Order PCB

Please refer to:
https://docs.easyeda.com/en/PCB/Order-PCB

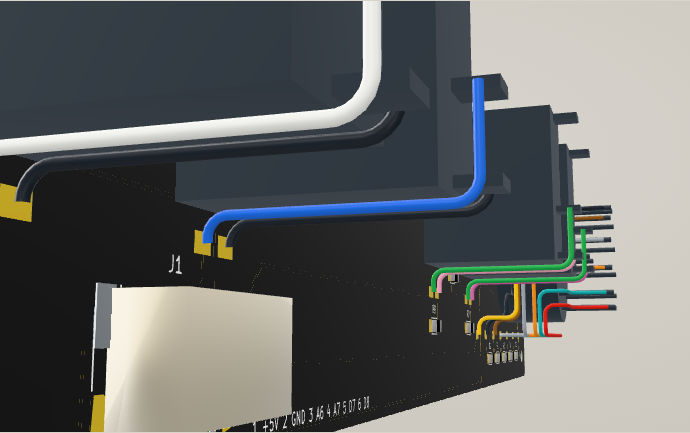
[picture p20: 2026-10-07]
qa/page-wiring/handwire-tidy/after-light-btn-side.png

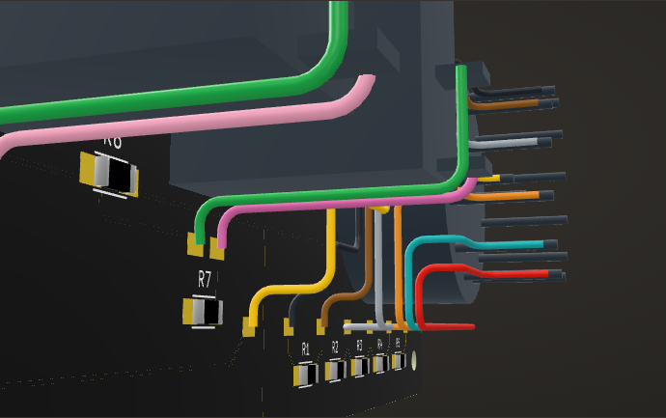
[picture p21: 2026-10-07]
qa/page-wiring/handwire-tidy/after-dark-lev-side.png

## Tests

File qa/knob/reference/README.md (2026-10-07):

# Knob references from the owner (chat, 2026-10-07)

Screenshots of meshok.net the owner pasted as examples for the MODE knob.

* `meshok-RSI4-knob.png`: "Радиостанции СССР периода ВОВ. Ручка управления. Оригинал." A black lobed knob from the
  РСИ-4 / РСИ-3 radio sets (1940s to 1960s): a fluted rim, words engraved round the ring and filled in cream
  ("СВЯЗЬ", "ОБРАТН"), a dot, and a raised centre cap with a curved arrow. Listed at 1 200 ₽, buy-now until 08.10.
  The bore and fixing are not shown in the screenshot.
* `meshok-beak-knobs.png`: search results for "клювик" (beak, or chicken-head) instrument knobs, 20 to 25 ₽ each, some
  stated for a 6 mm shaft, and a black knob for a 6 mm shaft.

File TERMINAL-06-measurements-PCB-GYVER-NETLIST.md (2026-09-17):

# TERMINAL-06 — measurement sheet: the inherited board's netlist (Gerber-derived)

**Source:** `PCB/IN-12_norm/` — the EasyEDA Gerbers and drill files the physical boards
were made from (v6.3.53, 2020-06-13). **Method:** `tools/tracegyver.py` rasterises both
copper layers at 0.05 mm, labels the connected copper, joins the layers through the
plated holes and names every hole from geometry. Nothing here was read off a photo or a
datasheet drawing of the board; the board's own copper is the source. Regenerate the
tables with `python3 tools/tracegyver.py`; `--png` also writes
`PCB/IN-12_norm/gyver_copper.png`.

**Captured 17.09.26**, as phase 0 of TS06-MAIN. The board is AlexGyver's *NixieClock
v2.2, IN-12_norm* ("Based on itworkclub PCB", says the bottom copper). AlexGyver's own
page states the project **never had a schematic — the PCB was drawn directly**, so this
sheet is the first circuit record of it.

Companion sheet: `TERMINAL-06-measurements-PCB-IN12BOARD.md` (the geometry, 08.09.26).
Coordinates below are mm from the panel's bottom-left corner, Y up, seen from the
component side. Part names follow AlexGyver's silkscreen render
(`schemes/IN-12_norm.jpg` in his repo): U1 Nano, D1 К155ИД1, U2–U5 TLP627, P1–P4 the
mating headers, S1–S3 the tact switches.

---

## 1. The circuit, in one picture

```
                         5 V in ─┬──────────────┬─────────────────────┬──── U1 5V (Nano)
                        470 µF ═╪═   100 nF ═══╪═  L1 220 µH          │
                                │              │      │               ├──── D1 pin 5 VCC
   D9 ──100 Ω──┤ gate     drain ┼──────────────┼──────┘               ├──── RTC + / VCC
             VT1 IRF840   source│              │  │                   └──── switches' returns
                                └───── GND ────┴──┼─────────────── GND pour (both halves)
                                                  │
                                    VD1 HER106  ──┴──►│──┬── HV+ ──┬──────────────┬── RP1 470 kΩ
                                                         │         │              │   (variable bleed,
                                              C1 4.7 µF ═╪═  Ranode 10 kΩ       one end open)
                                                350 V    │         │              │
                                                        GND        ├── U2..U5 collector (pin 4)  GND
                                                                   │
              D3 ─┤U5 LED  U5 emitter├── P2.5 ─ P1.5 ─ V1 anode (pad 7)   tube 1, hours tens
              D4 ─┤U4      U4       ├── P2.4 ─ P1.4 ─ V2 anode           tube 2, hours units
              D5 ─┤U3      U3       ├── P2.3 ─ P1.3 ─ V3 anode           tube 3, minutes tens
              D6 ─┤U2      U2       ├── P2.2 ─ P1.2 ─ V4 anode           tube 4, minutes units
                    all four LED cathodes ── 470 Ω ── GND

   A3 ── D1 pin 3 (A, 1)    A1 ── pin 6 (B, 2)    A0 ── pin 7 (C, 4)    A2 ── pin 4 (D, 8)
   D1 outputs Q0..Q9 ── P4.k ─ P3.k ── the same socket pad on all four tubes   (§4)

   D10 ── 150 Ω ── P2.6 ─ P1.6 ── HL5 "dot" LED ── GND        (the colon position)
   D11 ── 100 Ω ── P2.1 ─ P1.1 ── HL1..HL4 in parallel ── GND  (backlight, one resistor for four)
   D2  ── 100 Ω ── BUZ+                                        (buzzer, removed in this firmware)
   D7 / D8 / D12 ── S1 / S2 / S3 ── GND                        (SET, ADJ, lever; no pull-ups)
   A4 ── SDA, A5 ── SCL ── both RTC headers                    (§6)
   not connected: D13, A6, A7, VIN, 3V3, REF, RST, TX, RX
```

## 2. The 185 V converter — what it is, and what it is not

| Part (silkscreen) | Connection |
|---|---|
| VT1 **IRF840** TO-220, pins S-D-G left to right at Y 60.20 | gate ← 100 Ω ← D9; source → GND; drain → L1 and VD1 anode |
| L1 **220 µH** | drain node ↔ +5 V |
| VD1 **HER106** | anode at the drain node, cathode → HV+ |
| C1 **4.7 µF 350 V** | HV+ ↔ GND, the reservoir |
| **10 kΩ** (vertical, left of the optos) | HV+ → the common collector bus of U2..U5. **The one and only anode resistor on the board, shared by all four tubes** — legal because only one opto conducts at a time |
| RP1 **470 kΩ** trimmer | one end unconnected, wiper on HV+, other end on GND: **a variable bleed resistor from HV+ to GND, nothing else** |
| **470 Ω** (top, beside the trimmer) | the four opto LED cathodes → GND, one resistor for four LEDs |

**There is no feedback.** Nothing measures the rail. D9 runs at a fixed 31 kHz and a fixed
on-time (`DUTY 190` of 255 in the firmware, 23.8 µs), the MOSFET is driven straight from
the 5 V pin through 100 Ω with no pull-down, and the stage delivers a **fixed energy per
cycle** in discontinuous conduction:

| Quantity | Value |
|---|---|
| Peak inductor current, 5 V in, 23.8 µs on, 220 µH | 0.54 A |
| Energy per cycle ½·L·I² | 32 µJ |
| Deliverable power at 31.25 kHz | **≈ 1.0 W** (before losses) |
| Discharge time at 185 V | 0.7 µs of the 8 µs left — deep DCM, the model holds |
| Four multiplexed ИН-12 at 2.5–5 mA average | 0.5–0.9 W |
| Same stage fed from 12 V | 1.3 A peak, 186 µJ, **≈ 5.8 W** |

The rail therefore sits wherever the load balances that 1 W: with four tubes it is
≈185 V, with nothing but the trimmer it would climb towards √(P·R) — several hundred
volts against a 350 V capacitor — which is why the trimmer exists at all. It is the
adjustable dummy load that keeps the rail down, not a regulator. AlexGyver's page says
exactly this in fewer words: the voltage is set by "the resistor and the PWM duty".

**Consequences for TS06-MAIN** (the numbers behind the 17.09.26 power-input decision):
six multiplexed digits plus two statically driven ИН-15 at 8k2 plus the colon need
≈3.5 W at 185 V. The stock stage cannot supply it from 5 V at any trimmer setting. Fed
from 12 V, the same topology has margin; a real feedback loop replaces the bleed
trimmer; and every tube gets its own anode resistor, because a stiff rail and a shared
10 kΩ would no longer limit anything.

## 3. Corrections to earlier documents

| Where | It said | The copper says |
|---|---|---|
| `TERMINAL-06-measurements-PCB-IN12BOARD.md` §1 | "Ground pour: none, either layer" | Both halves carry a **bottom-side pour**: GND on the driver half, the LED/GND return (P1.7) on the tube half. Top layer: pads only, 53 sub-millimetre stubs, no traces — that part was right. |
| prototype plan, 04.09.26 | "the 100 Ω resistors beside the optos are LED-side current limiters, ~38 mA" | The three 100 Ω are the D9 gate resistor, the D11 backlight resistor and the D2 buzzer resistor. The opto LEDs share **one 470 Ω** on the cathode side: ≈8 mA, not 38. |
| prototype plan, 06.09.26 | "a 470 kΩ fixed resistor plus the 500 kΩ P504 trimmer between HV+ and ground (the feedback divider)" | Only the trimmer sits between HV+ and GND, as a bleed. The "470" is the LED resistor. There is no divider and nothing to feed back to. |
| spec §4 | "the stock board has no per-tube anode resistor" | True per tube. There is one **shared 10 kΩ** from HV+ to all four collectors. |
| handoff §6.1 | "topology and component values are not recorded anywhere in this repo" | Now they are — above. Only the trimmer's setting and the rail under load still need a meter (gates sheet, gate 1). |
| handoff §6.2, IN12BOARD §3 | "which hole is the anode and which are the ten cathodes is not known — meter it" | Known, §4 below, and cross-checked four ways. No meter session needed. |
| firmware header | "IN-12 turned" board, `BOARD_TYPE 0` | Confirmed: the mask that matches this copper is `{7, 3, 6, 4, 1, 9, 8, 0, 5, 2}`. |

## 4. The display chain — closed four ways

The К155ИД1 (DIP-16, pin 1 top-left at (78.23, 70.36), pins 1–8 down the left column,
9–16 up the right) is wired from the Nano exactly as the datasheet pinout requires, and
exactly as the firmware's `decoderNibble` assumes:

| Nano | К155ИД1 pin | Function | firmware bit (`1_setup.ino`) |
|---|---|---|---|
| A3 | 3 | A, weight 1 | bit 0 of the mask |
| A1 | 6 | B, weight 2 | bit 1 |
| A0 | 7 | C, weight 4 | bit 2 |
| A2 | 4 | D, weight 8 | bit 3 |
| 5 V / GND | 5 / 12 | VCC / GND | — |

The ten outputs go to P4, which mates pin-for-pin with P3 on the tube board (a pure
translation of 40.13 mm in Y, the FreeCAD assembly and the header rows agree), and each
P3 pin reaches **the same socket pad on all four tubes**. Socket pads are numbered as in
`TS06_IN12_Socket`: clockwise from the upper-left as seen from the tube side; pad 7 is
the anode (unique copper per tube), pad 8 has no copper at all (ИН-12А pin 12, n/c). The
ИН-12А datasheet (pin 1 anode, pins 2–11 cathodes 0 9 8 7 6 5 4 3 2 1) lands pin *d* on
pad ((7 − d) mod 12) + 1.

```
К155ИД1 output -> header pin -> socket pad (all four tubes) -> ИН-12А cathode, against firmware digitMask (BOARD_TYPE 0):
  Q0 pin 16 -> P4.8  = P3.8  -> pad  3 = cathode 7   firmware shows digit 7 with code 0: ok
  Q1 pin 15 -> P4.7  = P3.7  -> pad 12 = cathode 4   firmware shows digit 4 with code 1: ok
  Q2 pin  8 -> P4.4  = P3.4  -> pad  5 = cathode 9   firmware shows digit 9 with code 2: ok
  Q3 pin  9 -> P4.1  = P3.1  -> pad  9 = cathode 1   firmware shows digit 1 with code 3: ok
  Q4 pin 13 -> P4.5  = P3.5  -> pad 11 = cathode 3   firmware shows digit 3 with code 4: ok
  Q5 pin 14 -> P4.6  = P3.6  -> pad  4 = cathode 8   firmware shows digit 8 with code 5: ok
  Q6 pin 11 -> P4.3  = P3.3  -> pad 10 = cathode 2   firmware shows digit 2 with code 6: ok
  Q7 pin 10 -> P4.2  = P3.2  -> pad  6 = cathode 0   firmware shows digit 0 with code 7: ok
  Q8 pin  1 -> P4.10 = P3.10 -> pad  2 = cathode 6   firmware shows digit 6 with code 8: ok
  Q9 pin  2 -> P4.9  = P3.9  -> pad  1 = cathode 5   firmware shows digit 5 with code 9: ok
  10/10 agree
```

Four independent sources — the К155ИД1 datasheet pinout, the ИН-12А datasheet cathode
order, this copper, and a firmware table proven on the bench with real tubes — agree on
all ten digits. A wrong assumption in any one of them would show up as a scrambled
permutation, not as ten matches.

**Socket pad → function, ИН-12А, in `TS06_IN12_Socket` numbering:**

| pad | 1 | 2 | 3 | 4 | 5 | 6 | 7 | 8 | 9 | 10 | 11 | 12 |
|---|---|---|---|---|---|---|---|---|---|---|---|---|
| cathode | 5 | 6 | 7 | 8 | 9 | 0 | **anode** | n/c | 1 | 2 | 3 | 4 |

**What TS06-MAIN copies.** Name the cathode bus by digit, K0..K9, and wire К155ИД1
output Q*c* to the cathode of digit *d* where `digitMask[d] = c` — i.e. Q0→K7, Q1→K4,
Q2→K9, Q3→K1, Q4→K3, Q5→K8, Q6→K2, Q7→K0, Q8→K6, Q9→K5 — and the firmware keeps
`BOARD_TYPE 0` unchanged. (Wiring Q*d*→K*d* and switching to `BOARD_TYPE 3` would be
the equally valid alternative; it costs one `#define` and buys nothing.) The ИН-17 cathode
for digit *d* joins K*d*; its lead order is gate 3 of the bench sheet.

## 5. The mating headers

P1 (tube board, left edge) mates with P2 (driver board), P3 with P4, pin *k* to pin *k*.

| pin | P1 = P2 | P3 = P4 |
|---|---|---|
| 1 | backlight LED anodes (D11 via 100 Ω) | Q3 → cathode 1 |
| 2 | V4 anode (minutes units) ← U2 emitter | Q7 → cathode 0 |
| 3 | V3 anode (minutes tens) ← U3 emitter | Q6 → cathode 2 |
| 4 | V2 anode (hours units) ← U4 emitter | Q2 → cathode 9 |
| 5 | V1 anode (hours tens) ← U5 emitter | Q4 → cathode 3 |
| 6 | dot LED anode (D10 via 150 Ω) | Q5 → cathode 8 |
| 7 | GND (LED cathodes, the tube half's pour) | Q1 → cathode 4 |
| 8 | — | Q0 → cathode 7 |
| 9 | — | Q9 → cathode 5 |
| 10 | — | Q8 → cathode 6 |

Opto to tube: U5 (top) = D3 = hours tens = V1, U4 = D4 = V2, U3 = D5 = V3, U2 (bottom)
= D6 = V4 — the firmware's `KEY0..KEY3 = D3..D6` in tube order. TLP627 pins: 1 LED anode
(from the Nano pin), 2 LED cathode (to the shared 470 Ω), 3 emitter (to the anode), 4
collector (the 10 kΩ bus).

## 6. Everything else on the driver half

| Item | Holes | Net |
|---|---|---|
| Power in "5V / GND" | (74.67, 74.93) / (74.67, 77.47), 2.54 mm pair | +5 V / GND. The 470 µF 6.3 V sits across it; the "ANY CERAMIC" 100 nF sits by the К155ИД1 |
| RTC mini header | (78.48 … 88.64, 37.85), five at 2.54 | **− NC C D +** = GND, n/c, SCL (A5), SDA (A4), +5 V. This is the small DS3231 module's pin order |
| RTC ZS-042 header | (75.94 … 88.64, 41.66), six at 2.54 | **32K SQW SCL SDA VCC GND**: 32K and SQW unconnected, the rest as above. The board takes either module |
| S1, S2, S3 | 6 × 6 mm tact pattern, 6.5 × 4.5 mm, at X 15.34 / 28.04 / 40.74, Y 36.07 / 40.57 | to D7, D8, D12; the other side on GND. No pull-ups on the board |
| BUZ | (45.72, 75.95) − / (48.26, 75.95) + | − GND, + ← 100 Ω ← D2 |
| Nano U1 | X 54.35 (D side) and 69.59 (A side), 15 each at 2.54, pin 1 (TX1 / VIN) at Y 76.45; the D12 hole sits at Y 40.64, off-pitch | as in §1. Powered through its **5V pin**, VIN open |
| Mounting | NPTH Ø3.0 at (3.56, 78.23), (3.56, 36.58), (95.56, 78.23), (95.56, 36.58) | 3.5 mm inset, 92.0 × 41.65 mm apart |

Tube half: four sockets (`IN12BOARD.md` §3), the Ø5 pip holes, HL1–HL4 backlight LEDs
at Y 4.06 (anode at X 12.19 / 35.56 / 62.99 / 86.10, cathode 2.54 to the right), the
dot LED HL5 at (48.51 / 51.05, 2.79), P1 and P3.

## 7. Still open on this board

* The **trimmer's setting and the rail under load** — gate 1 of
  `knowledge/TERMINAL-06-measurements-TS06-MAIN-gates.txt`. The copper fixes the
  circuit; only the operating point is a bench number.
* Whether the physical boards carry the silkscreen's values (IRF840, HER106, 220 µH,
  4.7 µF 350 V, 470 kΩ) — a glance, not a measurement; the prototype plan read the
  trimmer as "P504".

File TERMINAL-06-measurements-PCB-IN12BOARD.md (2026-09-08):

# TERMINAL-06 — measurement sheet: the inherited ИН-12 board (Gerber-derived)

**Source:** `PCB/IN-12_norm/` — EasyEDA v6.3.53, generated 2020-06-13T07:22:25+03:00.
**Method:** parsed directly from `Gerber_BoardOutline.GKO`, `Gerber_Drill_PTH.DRL` and
`Gerber_Drill_NPTH.DRL`. These are **not** estimates off a photo — they are the
fabrication data the physical board was made from, converted from imperial
(2.4 format, inches) to millimetres. Origin is the board's bottom-left corner.

**Captured 08.09.26**, during the "do we actually need TS06-TUBE" question. Every
number here is exact to the resolution the Gerbers carry (0.0001 in = 2.54 µm).

---

## 1. Panel

| Item | Value |
|---|---|
| Panel outline | **99.06 × 80.77 mm** (3.8999 × 3.1800 in) |
| Layers | 2. **Top layer carries no traces at all** — 142 pad flashes only. All routing is bottom-side. |
| Ground pour | **None, either layer.** All copper is discrete traces. A pad is never grounded by sitting in a pour on this board. |
| Construction | Ships as ONE panel, cut along the silkscreened white line into the tube board and the driver board, which then mate via P1↔P2 / P3↔P4. |
| Tube half | Y ≈ 0 … 44 mm of the panel (the four tube positions plus the mating headers at Y 36–42). |

## 2. ИН-12А tube positions — the four numbers that fix the deck geometry

All four tube centres sit on **Y = 20.07 mm**.

| Tube | X centre (mm) | Gap to next (mm) |
|---|---|---|
| 1 (H tens) | 13.21 | — |
| 2 (H units) | 36.57 | **23.36** |
| 3 (M tens) | 63.99 | **27.42** ← the HH:MM group break |
| 4 (M units) | 87.37 | **23.38** |

**Pitch is 23.36 / 27.42 / 23.36 mm.** This is the single most consequential number
on the board: it is fixed by someone else's layout and it is what TS06-TUBE would
exist to change.

## 3. ИН-12А socket footprint — complete, ready to draw in KiCad

**12 plated holes, Ø 1.194 mm (0.047 in), plus one unplated Ø 5.00 mm (0.197 in)
centre hole.** The pattern is **not a circle and not an ellipse** — it is a
stadium/oval: two straight vertical flanks joined by top and bottom arcs. Do not try
to generate it from a "pin circle diameter"; use the coordinates.

Offsets from the tube centre (the 5 mm NPTH hole), in mm:

| # | ΔX | ΔY |
|---|---|---|
| 1 | +5.74 | 0.00 |
| 2 | +5.74 | +4.49 |
| 3 | +3.99 | +8.00 |
| 4 | 0.00 | +8.99 |
| 5 | −3.99 | +8.00 |
| 6 | −5.74 | +4.49 |
| 7 | −5.74 | 0.00 |
| 8 | −5.74 | −4.50 |
| 9 | −3.99 | −8.01 |
| 10 | 0.00 | −8.99 |
| 11 | +3.99 | −8.01 |
| 12 | +5.74 | −4.50 |

Overall pin envelope: **11.48 mm across (X) × 17.98 mm tall (Y).** The tube's wide
axis therefore runs along **Y** in this layout, i.e. the tubes stand upright with the
board flat.

**Pin numbering is NOT established.** These are geometric positions only. Which
physical hole is the anode and which are the ten cathodes has to be metered, exactly
as `secCathodeMap` does for the ИН-17s. The 04.09.26 procedure still applies:
continuity between the **same-position** hole on two **different** tube positions —
**no continuity → anode** (unique per tube), **continuity → shared cathode** (bussed
to the К155ИД1).

## 4. Other features on the tube half

| Y (mm) | X positions (mm) | Ø | Reading |
|---|---|---|---|
| 4.06 | 12.19 / 14.73 · 35.56 / 38.10 · 62.99 / 65.53 · 86.10 / 88.64 | 0.81 mm | **Four LED positions**, 2.54 mm pitch pairs, one under each tube — the D11 backlight row. Matches the bench observation that the LED-negative pads daisy-chain along the bottom edge. |
| 2.79 | 48.51 / 51.05 | — | Single 2.54 mm pair on the centreline. |
| 37.85 | 78.48 … 88.64, 2.54 mm pitch | 0.89 mm | **5-pin 0.1 in header** — one half of a mating pair. |
| 41.66 | 75.94 … 88.64, 2.54 mm pitch | — | **6-pin 0.1 in header.** |
| 36.07 / 40.64 | 15.34 / 21.84 / 28.04 / 34.54 / 40.74 / 47.24 (+54.35) | — | Left-hand inter-board connection, irregular ~6.2/6.5 mm pitch. Not a standard header pitch — inspect physically before copying. |

## 5. What this settles, and what it does not

**Settles:** the ИН-12 socket footprint is fully known and can be drawn in KiCad
without touching a caliper. "We need a new board because the socket pins are a
different width" is **not** a reason — the tube defines the pattern, so any socket
that fits the tube fits these holes.

**Settles:** the tube pitch (23.36 / 27.42 / 23.36) and the fact that all four tubes
sit on one Y line with the tube's wide axis vertical.

**Does not settle:** hole-to-function mapping (anode vs. cathodes) — meter it.

**Does not settle:** whether TS06-TUBE is worth fabricating. That is a **case**
decision (deck height, forward offset, rake — spec §6 "Brow reveal"), not an
electrical one, and it should be judged against a printed brow test-fit. Note the
counter-argument on the other side: ten main boards are already owned, which means
ten tube halves are already owned, and TS06-TUBE is ~1 425 ₽/unit of Group D that
does not have to be spent. The anode-bleed rationale for this board was **withdrawn
06.09.26** (root cause was empty multiplex slots, spec §5a-pre), so geometry is the
only live reason left.

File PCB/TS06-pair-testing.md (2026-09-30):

# TS06-DISP + TS06-DRV: how to view the boards and test everything

This guide covers the through-hole pair and the fascia cable. It has three parts:

* **A. Viewing.** How to open the boards in KiCad 10 and the case in OpenSCAD.
* **B. Automated checks.** One command, `tools/verify_pair.sh`, runs every check the repository has on the pair.
* **C. Bench bring-up.** Eight stages, from bare boards to a 24-hour soak. Each stage gives the expected value, calculated from the netlist.

The netlist and every part value come from `tools/ts06pair.py`. Board positions come from `tools/mkpcb_disp.py` and `tools/mkpcb_drv.py`. The design decisions are in `PCB/README.md` and `Claude outputs/TS06-pair-review.md`.

---

## A. Viewing the boards

### A1. Install KiCad 10

Download it from the official page, **https://www.kicad.org/download/**, and choose your system:

| System | What to do |
|---|---|
| Windows | Run the 10.x installer with its default options. The defaults include the 3D models. |
| macOS | Open the 10.x `.dmg` and drag the KiCad folder into Applications. |
| Linux | Follow the page for your distribution (Ubuntu PPA, Flatpak, Fedora, Arch, and others). Make sure the version is 10.x. Some distributions ship the 3D models as a separate package, often named `kicad-packages3d`, or as a Flatpak extension. Install it too, or the 3D view shows bare boards. |

The files are KiCad 10 files. KiCad 9 and older cannot open them.

On the first start, KiCad may offer to set up the global libraries. Accept the default. The pair does not use them, but other projects will.

**No online viewer is known to read KiCad 10 files reliably, so none is recommended here.** To look without installing anything, open `copper.png` in each board's folder. It shows both copper faces and is generated from the board file.

### A2. Get the files

```
git clone -b pcb/kicad-boards https://github.com/BobStolb/TERMINAL-06-firmware
cd TERMINAL-06-firmware
```

Later, `git pull` brings the latest version. Without git, choose the `pcb/kicad-boards` branch on GitHub, then **Code → Download ZIP**.

### A3. Open each board

1. Start KiCad. Choose **File → Open Project** and open `PCB/TS06-DISP/TS06-DISP.kicad_pro`.
2. In the project window, double-click `TS06-DISP.kicad_pcb` to open the PCB Editor.
3. Do the same with `PCB/TS06-DRV/TS06-DRV.kicad_pro`.

**There is no schematic for the pair.** Its netlist is the Python file `tools/ts06pair.py`, and the generators write the boards from it. The folders hold no `.kicad_sch` file, so leave the Schematic Editor alone.

**Do not save the boards.** The files in the repository are written by the generators. Refilling zones or running DRC changes the board in memory, so KiCad asks to save when you close it. Answer **Discard**. If you save by accident, restore the file with `git checkout -- PCB/`. Otherwise `tools/verify_pair.sh` reports the board as edited by hand (part B).

### A4. Why the footprint library is inside the project

Each board folder has its own `fp-lib-table`. It names one library, `TS06`, at `${KIPRJMOD}/../lib/TS06.pretty`, which is `PCB/lib/TS06.pretty` in this repository. KiCad reads it when it opens the project, so there is nothing to install or configure. There are three reasons:

* **The Soviet parts have no stock footprints.** The ИН-12 and ИН-15 sockets, the wire-ended ИН-17 and the ИНС-1 lamps are drawn here. The ordinary parts were copied from KiCad 10's own libraries and adjusted.
* **Nobody's library setup can change the boards.** Every footprint the board uses comes from this repository.
* **KiCad can compare each footprint with its library copy.** The generators write rotated copies (`_R90`, `_R180`, `_R270`) into the library for that reason. The DRC's "footprint does not match library" check depends on it (part B).

### A5. Look around the board

* **Faces.** On TS06-DISP, the tubes are on the front face (F) and the pin strips XP11–XP25 are on the back (B). On TS06-DRV, the component face is F, towards the back of the case. The socket strips XS11–XS25 are on B, towards the display. To see a board from behind, use **View → Flip Board View**.
* **Layers.** The **Appearance** panel on the right has a **Layers** tab. The eye icon beside each layer shows or hides it. The **Layer presets** list at the bottom switches between front and back layers. **Ctrl+H** dims every layer except the active one. **PgUp** and **PgDn** switch the active layer between F.Cu and B.Cu.
* **Nets.** Hover over a pad and the status bar names its net. The **`** key (back-quote) highlights every pad and track of the net under the cursor. **Inspect → Net Inspector** lists every net with its length. For example, highlight `HV185` to see where 185 V goes.
* **Find a part.** **Ctrl+F** finds any reference, such as `C7`, `RP1` or `XS21`. Pin 1 of every part is its square pad.
* **Measure.** Use **Inspect → Measure Tool** (**Ctrl+Shift+M**) and click two points. Alternatively, press **Space** to zero the relative coordinates, and the status bar shows dx, dy and the distance. **Inspect → Clearance Resolution** takes two selected items and shows the rule between them. For example, any pad of an `ANODE_*` net shows 0.6 mm, the HV class.
* **Net classes.** Open **File → Board Setup → Design Rules → Net Classes**. `HV` has 0.6 mm clearance and covers `HV185`, `SW`, `BLEED_*`, `FB_MID`, `COLON_*`, `ANODE_*` and `EMIT_*`. `CATH` covers the cathode lines and `PWR` the rails.

### A6. Run KiCad's DRC in the GUI

1. Choose **Inspect → Design Rules Checker**.
2. Tick **Refill all zones before performing DRC**. TS06-DRV's ground pours must be refilled before they can be judged.
3. Click **Run DRC**. The results should be:

| Board | Errors | Warnings | Unconnected | Every item is accepted |
|---|---|---|---|---|
| TS06-DISP | 2 | 0 | 0 | Both errors are courtyard overlaps: V3/V7 and V3/V8, the colon lamps against the M10 tube |
| TS06-DRV | 0 | 4 | 0 | Two are silkscreen past the board edge on U1, the Nano with its USB. Two are library mismatches on VT21 and XS1 |

Part B explains each accepted item. Anything else in the list is new and needs a look. When you close the board, answer **Discard** (see A3).

### A7. The 3D viewer

Choose **View → 3D Viewer** (**Alt+3**). Drag to rotate, scroll to zoom and middle-drag to pan. The toolbar has buttons for the standard views.

* **TS06-DRV** shows KiCad's stock bodies for nearly every part: 95 models. These include the Nano, the jack, L1, C7, VT21, the DIP sockets and the socket strips. The chips themselves are not modelled, so every IC shows as an empty socket, and the RTC module shows as its 5-way socket.
* **TS06-DISP** shows almost nothing but the bare board and its seven pin strips. **No 3D bodies are included for the Soviet parts:** the ИН-12, ИН-17 and ИН-15 tubes and the ИНС-1 lamps. The LEDs have none either. To see the tubes in 3D, use the case model below. Separate STEP models of the tubes are in `3d/` (`IN12.step`, `IN17.step`, `INS1.step`) and open in FreeCAD.
* If a board shows no bodies at all, KiCad's 3D model library is missing. On Linux, install the package mentioned in A1.

### A8. The case model

The case is in `3d/case-pair/`. It is drawn around these boards, and `checks.md` there lists every interference check with its source.

* **OpenSCAD.** Install it from https://openscad.org/downloads.html and open `3d/case-pair/case.scad`. It includes the generated `params.scad`, so keep the two files together. **F5** previews and **F6** renders.
  * To view one part, change `PART = "assembly";` near the top. The choices are `module` (both boards), `cheek_l`, `cheek_r`, `brow`, `trench`, `base`, `rear` and `fascia_blank`.
  * `EXPLODE = 1;` pulls the parts apart.
  * From a terminal: `openscad -D 'PART="module"' -o module.stl 3d/case-pair/case.scad`.
* **STL files.** `3d/case-pair/out/*.stl` (cheeks, brow, trench, base, rear panel and a fascia blank) open in any slicer: PrusaSlicer, Cura, Bambu Studio or OrcaSlicer. Windows 3D Viewer and macOS Quick Look also show them. They are exported where they sit in the assembly, not flat on a bed. Lay each one on a face before printing; in PrusaSlicer, use **Place on face**, key F.
* **Drawings and pictures.** `out/front.svg`, `section.svg`, `plan.svg` and `exploded.svg` are 1:1 drawings. They open in a browser; print at 100 %. There are also PNG views: `iso.png`, `iso_rear.png`, `front.png`, `exploded.png` and `module.png`.
* **Current numbers.** `checks.md` is regenerated every time the checks run, so it has the current envelope: 204.4 × 122.8 × 81.6 mm (TS06-DRV rev B's real part heights). Some tables in the case's own `README.md` still quote the old 176 mm boards.

---

## B. Automated checks: `tools/verify_pair.sh`

### B1. Run it

From the repository root:

```
tools/verify_pair.sh              # everything, about a minute
tools/verify_pair.sh --no-drc     # everything but KiCad's DRC
tools/verify_pair.sh --keep       # keep the logs and DRC reports, and print where they are
```

* **What it needs.** Bash, Python 3.8 or newer, and numpy (`pip install numpy`).
  * On Windows, run it from Git Bash, which comes with Git for Windows, or from WSL.
  * For KiCad's DRC, it uses a KiCad 10 `kicad-cli` if one is on the PATH or in the usual install folder. You can also name one with `KICAD_CLI=/path/to/kicad-cli`.
  * Without KiCad, it uses Docker: the image `mirror.gcr.io/kicad/kicad:10.0`, about 1 GB, pulled once.
  * With neither, the two DRC lines say **SKIP**, the other KiCad-only checks (pours, HV rule live, erc) are not run, and the rest still runs.
  * If Docker cannot see `/tmp` (a snap-installed Docker), run `TMPDIR=$HOME/tmp tools/verify_pair.sh`.
* **What it touches.** Nothing in the working tree. Every regeneration goes into a scratch copy that is deleted at the end.
* **What it prints.** One line per check: **PASS**, **FAIL** or **SKIP**, with the key numbers. On a FAIL, the tool's own output follows, indented. The script exits with 1 if anything failed and 0 otherwise.

This is the output on the committed boards, 30.09.26 06:23 UTC (TS06-DRV rev B):

```
PASS  netlist                    disp 26 parts/59 nets, drv 108 parts/136 nets, 63 strip pins: consistent
PASS  mate                       63 strip pins (59 with a net) land on their pins, same net; 4 standoffs have holes
PASS  firmware tables            BOARD_TYPE 4 digit map, anode order, decoder bits, MCP 0x20; bring-up sketch tables: agree with tools/ts06pair.py
PASS  TS06-DISP generator        TS06-DISP.kicad_pcb, TS06-DISP.kicad_pro, fp-lib-table, TS06.pretty: identical to a fresh run of tools/mkpcb_disp.py
PASS  TS06-DISP checkpcb         30 footprints, 189 pads; accepted: H3 standoff above the colon 0.15 mm, XP11 at the left edge, its pads inside 0.17 mm, colon lamp V7 vs M10, colon lamp V8 vs M10
PASS  TS06-DISP checkcopper --hv 388 tracks, 0 vias, 378 pad-layers; HV 0.6 mm: clean
PASS  TS06-DISP audit            copper 2125 mm, 1.15x its floor, 0 vias, pour islands 1: clean
PASS  TS06-DISP checksch         179 pins connected, 0 dangling
PASS  TS06-DISP checkmatch       59 nets in the schematic, 59 on the board: they agree
PASS  TS06-DRV generator         TS06-DRV.kicad_pcb, TS06-DRV.kicad_pro, fp-lib-table, TS06.pretty: identical to a fresh run of tools/mkpcb_drv.py
PASS  TS06-DRV checkpcb          116 footprints, 435 pads; accepted: Nano USB proud of the edge 2.40 mm, XS11 behind the display's XP11 0.17 mm
PASS  TS06-DRV checkcopper --hv  1164 tracks, 0 vias, 870 pad-layers; HV 0.6 mm: clean
PASS  TS06-DRV audit             copper 6689 mm, 1.30x its floor, 0 vias, pour islands 9,7: clean
PASS  TS06-DRV checksch          516 pins connected, 0 dangling
PASS  TS06-DRV checkmatch        136 nets in the schematic, 136 on the board: they agree
PASS  TS06-DISP drc              KiCad 10.0.6 (docker mirror.gcr.io/kicad/kicad:10.0): 2 errors, 0 warnings, 0 unconnected; all accepted: colon V7 / M10 courtyards, colon V8 / M10 courtyards
PASS  TS06-DRV drc               KiCad 10.0.6 (docker mirror.gcr.io/kicad/kicad:10.0): 0 errors, 2 warnings, 0 unconnected; all accepted: Nano silk past the edge
PASS  pair mate (written files)  63 strip pins (59 with a net), 7 strips a side, 4 standoff holes, from the written files: positions, nets, drills and faces agree
PASS  TS06-DISP pours (KiCad)    BL_K F.Cu: 1 pieces, the largest 100% of 6103 mm2, 0 under 1 mm2
PASS  TS06-DRV pours (KiCad)     GND F.Cu: 15 pieces, the largest 92% of 12963 mm2, 2 under 1 mm2; GND B.Cu: 10 pieces, the largest 33% of 10721 mm2, 2 under 1 mm2
PASS  TS06-DISP HV rule live     V1.7 (ANODE_H10): a K2 track 0.70 mm from its edge: DRC reports 'HV pad clearance, IPC-2221B A6'
PASS  TS06-DRV HV rule live      C7.1 (HV185): a K2 track 0.70 mm from its edge: DRC reports 'HV pad clearance, IPC-2221B A6'
PASS  TS06-DISP erc              KiCad ERC, all severities: 0 violations
PASS  TS06-DRV erc               KiCad ERC, all severities: 0 violations
PASS  bom                        TS06-DISP 26 fitted, TS06-DRV 96 fitted + 12 DNP: identical to tools/bom_pair.py's output
PASS  case                       envelope 204.4 x 122.8 x 81.6 mm; 81 checks: 62 OK, 9 TIGHT, 7 NOTE, 3 FAIL; known: the two rejected jack-opening alternatives; OPEN: the fascia boss on R5's pad (review P6)
PASS  case outputs               7 generated files identical to a fresh run
----
27 PASS, 0 FAIL, 0 SKIP
```

### B2. What each check means

| Check | In one line |
|---|---|
| netlist | `tools/ts06pair.py`: every net has at least two pads, and every net on both boards crosses on a strip pin with the same name on both halves. |
| mate | Every XS socket pin on TS06-DRV sits exactly behind its XP pin on TS06-DISP and carries the same net, and every display standoff has its hole. |
| firmware tables | The clock firmware's `BOARD_TYPE 4` tables agree with the netlist: the digit map, the anode order, the decoder input bits and the expander's address. So do the bring-up sketch's tables. |
| generator | The committed `.kicad_pcb`, `.kicad_pro` and `fp-lib-table`, and the library's rotated footprints, are byte for byte what the generator writes today. So the checks below test the source, not a stale file. |
| checkpcb | Placement: every pad and courtyard inside the outline, and no two courtyards overlapping on the same face. |
| checkcopper --hv | Copper clearance. It holds 0.6 mm wherever a high-voltage net is on either side of a gap, keeps copper away from unplated holes, and confirms zero vias. |
| audit | Per-net connectivity through tracks and pours, which catches a pad that is cut off. It also counts pour islands and checks the silkscreen. |
| checksch | Every pin in the board's schematic sheets is connected; none is left dangling. |
| checkmatch | The schematic and the board carry the same nets. |
| drc | KiCad 10's own DRC with the zones refilled and every severity on, using the HV net class from the project file and the 0.8 mm HV pad rule in the `.kicad_dru`. |
| pair mate (written files) | The mate check again, read from the files KiCad wrote rather than from the netlist: positions, nets, drills and faces of every strip pin and standoff. |
| pours (KiCad) | KiCad fills every pour and the script counts its pieces: the largest share, and slivers under 1 mm². |
| HV rule live | Plants a track 0.70 mm from a 185 V pad in a scratch copy and confirms that KiCad's DRC reports it, so the 0.8 mm rule is really applied. |
| erc | KiCad's electrical rules check on the schematics, every severity on. |
| bom | `PCB/TS06-*/bom.md` is exactly what `tools/bom_pair.py` writes from the netlist today. |
| case | The case model re-reads both boards and the fascia and runs its 81 interference checks. |
| case outputs | The committed `boards.json`, `params.scad`, `checks.md` and drawings match a fresh run of the case model. |

### B3. The accepted exceptions

These items appear in the output but never FAIL. The script's header documents each one. If an accepted item grows past its limit, or a new item appears, the check FAILs.

| Where | Item | Why it is accepted |
|---|---|---|
| TS06-DISP checkpcb | H3's courtyard is 0.15 mm past the top edge | H3 is the standoff hole above the colon. The courtyard is only the keep-out drawn around the hole, not copper. It FAILs past 0.25 mm. |
| TS06-DISP checkpcb and DRC (2 errors) | Colon lamps V7 and V8 overlap the M10 tube's courtyard by 0.135 mm | The lamps stand at their measured positions, inherited from TS06-MAIN. Only a test fit with a real tube settles it (review 9). KiCad 10 files these as `courtyards_overlap` with severity *error*. |
| TS06-DRV checkpcb | U1's courtyard is 2.4 mm past the edge | The Nano's USB socket stands proud of the board on purpose, so the cable can reach it through the case cheek. It FAILs past 2.6 mm. |
| TS06-DRV checkpcb | XS11's courtyard is 0.17 mm past the edge | The strip must sit exactly behind the display's XP11, which is on the edge. It FAILs past 0.25 mm. |
| TS06-DRV DRC (2 warnings) | Silkscreen clipped by the board edge, on U1 | This is the Nano's outline around the same USB overhang. |
| case | Two rows read FAIL: "plain 6 mm cheek" and "Ø14 pocket from inside" | These are the two rejected ways of passing the DC jack through the cheek, recorded to show why the model counterbores it from the outside. The counterbore row reads OK, with 7.2 mm of plug engagement. The power entry is open again: the owner asked for more options (30.09.26). |
| case | A third row reads FAIL: the fascia boss on R5's pad | An OPEN finding (review P6), on the committed fascia A. It goes when the fascia is chosen (grill G11). |

### B4. When something FAILs

| Check | Usual cause | Fix |
|---|---|---|
| generator | The board was saved from KiCad | `git checkout -- PCB/` |
| generator | A generator changed and the board was not regenerated | `python3 tools/mkpcb_disp.py` or `python3 tools/mkpcb_drv.py`, then commit |
| bom | The BOM is stale | `python3 tools/bom_pair.py`, then commit |
| case outputs | The case outputs are stale | `python3 3d/case-pair/case_pair.py --extract`, then commit |
| Any other | A real finding | Read the indented lines under it: they are the tool's own words |

---

## C. Bench bring-up and test
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

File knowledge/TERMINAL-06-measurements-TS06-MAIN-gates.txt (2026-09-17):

# TERMINAL-06 — bench gates for TS06-MAIN

**Created 17.09.26.** The brief (`Claude outputs/TS06-MAIN-handoff.md` §6) listed seven
unknowns that had to be measured before a combined main board could be ordered. Four of
them turned out to be answerable from the inherited board's own fabrication data, and
that is now done — `tools/tracegyver.py` reads every net of the AlexGyver board off its
Gerbers, and `TERMINAL-06-measurements-PCB-GYVER-NETLIST.md` writes the result up. **What
follows is only what the bench still has to supply**, in the order the design needs it,
each with the procedure, the instrument and what the number decides.

Fill the blanks in this file. One evening covers all of it; nothing here needs a scope.

## What is NOT needed any more

| Brief item | Status | Why |
|---|---|---|
| 6.1 converter topology and values | **closed from the Gerbers + silkscreen** | D9 → 100 Ω → IRF840 gate, 220 µH from +5 V, HER106, 4.7 µF 350 V, one shared 10 kΩ anode resistor to four TLP627 collectors, and a 470 kΩ trimmer used as a variable bleed from HV+ to GND. No feedback of any kind. See the netlist sheet. |
| 6.2 ИН-12 hole → function | **closed** | Anode = socket pad 7, NC = pad 8, and the ten cathode digits per pad follow from the copper, the К155ИД1 datasheet pinout, the ИН-12А datasheet cathode order and the bench-confirmed `digitMask` for `BOARD_TYPE 0` — all four agree, ten of ten. |
| 6.5 ИН-12 anode resistor values | **closed, as a null** | The stock board has no per-tube anode resistor; it has one shared 10 kΩ, and the rail is set by the converter's energy limit. TS06-MAIN designs its own per-tube value from gate 2 below. |
| 6.7 mounting | **design choice** | No case model exists in `3d/`; the board defines its holes and the case follows. |

## Safety, every gate that has HV on

185 V DC behind a 4.7 µF reservoir that stays charged after power-off. Meter on a
600 V DC range before it touches anything. **Power off, clip the black lead to GND,
power on, then touch only the red probe.** Never hold both leads. After power-off, bleed
the reservoir through ~100 kΩ for 10 s and verify < 10 V before touching the HV side.
GND on the stock driver board: the `GND` pad of the 2-pin power input, or the − lead of
the 470 µF electrolytic beside it. HV+: the + lead of the 4.7 µF 350 V cap, top-left of
the driver board, or the cathode (banded end) of the HER106.

---
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

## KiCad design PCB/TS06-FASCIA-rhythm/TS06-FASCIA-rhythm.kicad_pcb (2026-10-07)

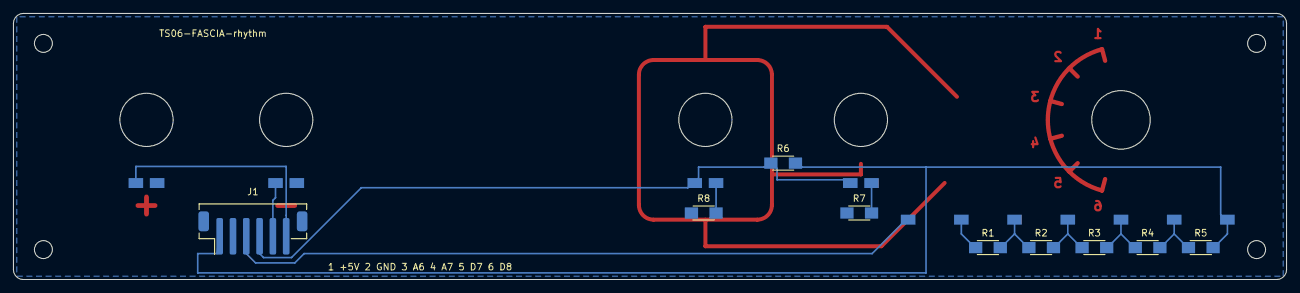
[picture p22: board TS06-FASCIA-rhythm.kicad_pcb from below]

Board: 2 copper layers, 191.4 x 40.0 mm, 18 parts (9 on the bottom side), 12 nets.

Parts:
H1, H2, H3, H4: MountingHole_2.7mm
J1: PH 6; TS06_JST_PH_B6B-PH-SM4-TB_Back
R1, R2, R3, R4, R5: 4k7; TS06_R_1206_HandSolder
R6, R8: 10k; TS06_R_1206_HandSolder
R7: 20k; TS06_R_1206_HandSolder
SW1: SR25 6-pos; TS06_Rotary_SR25_PanelMount_Rhythm
SW2: FIELD; TS06_MT1_Lever_PanelMount
SW3: SUB; TS06_MT1_Lever_PanelMount
SW4: MINUS; TS06_KMD1_Button_PanelMount
SW5: PLUS; TS06_KMD1_Button_PanelMount

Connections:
+5V: J1.1, R5.1, R6.1, SW1.6
A6: J1.3, SW1.7
A7: J1.4, R6.2, SW2.2, SW3.2
D7: J1.5, SW4.2
D8: J1.6, SW5.2
GND: J1.2, R1.2, R7.2, R8.2, SW1.1, SW4.1, SW5.1
LEVA: R7.1, SW2.1
LEVB: R8.1, SW3.1
TAP2: R1.1, R2.2, SW1.2
TAP3: R2.1, R3.2, SW1.3
TAP4: R3.1, R4.2, SW1.4
TAP5: R4.1, R5.2, SW1.5

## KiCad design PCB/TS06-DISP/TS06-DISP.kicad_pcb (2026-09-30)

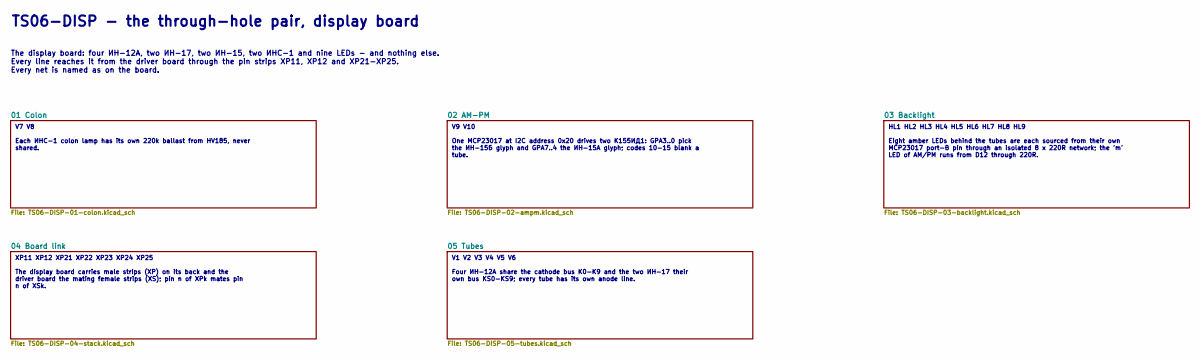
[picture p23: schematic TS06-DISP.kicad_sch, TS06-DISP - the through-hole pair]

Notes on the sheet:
TS06-DISP - the through-hole pair, display board
The display board: four ИН-12А, two ИН-17, two ИН-15, two ИНС-1 and nine LEDs - and nothing else. Every line reaches it from the driver board through the pin strips XP11, XP12 and XP21-XP25. Every net is named as on the board.
V7 V8 Each ИНС-1 colon lamp has its own 220k ballast from HV185, never shared.
V9 V10 One MCP23017 at I2C address 0x20 drives two К155ИД1: GPA3..0 pick the ИН-15Б glyph and GPA7..4 the ИН-15А glyph; codes 10-15 blank a tube.
HL1 HL2 HL3 HL4 HL5 HL6 HL7 HL8 HL9 Eight amber LEDs behind the tubes are each sourced from their own MCP23017 port-B pin through an isolated 8 x 220R network; the 'm' LED of AM/PM runs from D12 through 220R.
XP11 XP12 XP21 XP22 XP23 XP24 XP25 The display board carries male strips (XP) on its back and the driver board the mating female strips (XS); pin n of XPk mates pin n of XSk.
V1 V2 V3 V4 V5 V6 Four ИН-12А share the cathode bus K0-K9 and the two ИН-17 their own bus KS0-KS9; every tube has its own anode line.

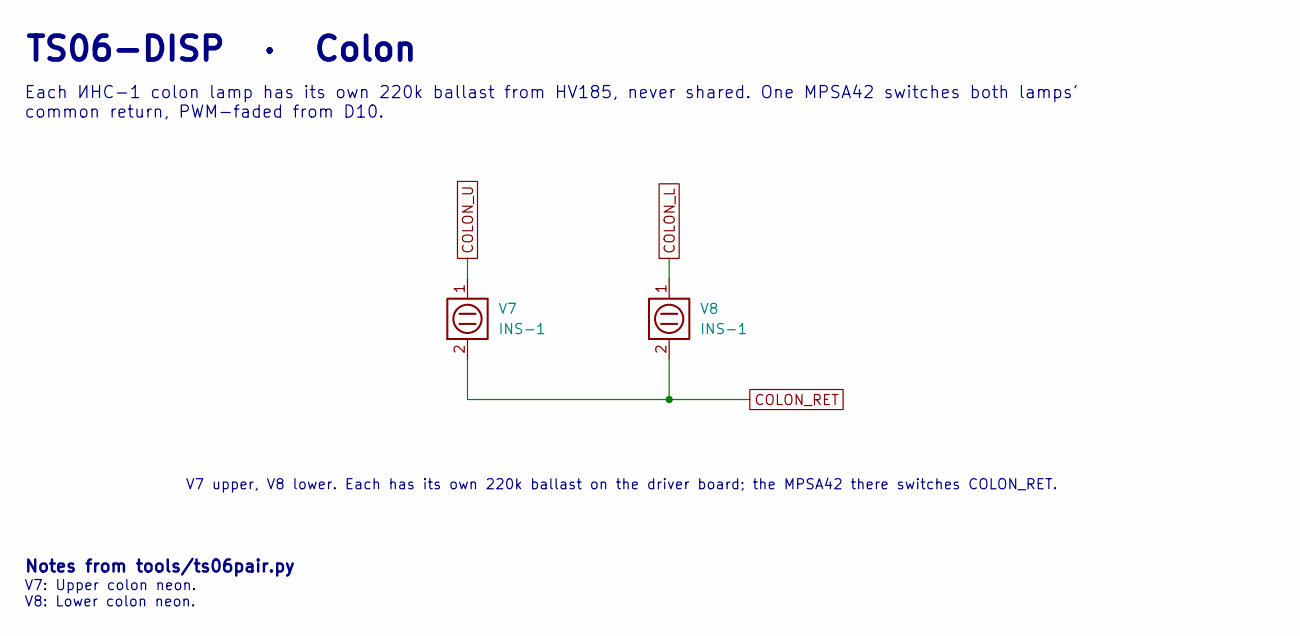
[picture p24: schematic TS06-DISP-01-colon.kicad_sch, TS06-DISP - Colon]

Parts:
V7, V8: INS-1; TS06_INS1_Lamp

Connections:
COLON_L: V8.1 (A); also elsewhere on the board
COLON_RET: V7.2 (K), V8.2 (K); also elsewhere on the board
COLON_U: V7.1 (A); also elsewhere on the board

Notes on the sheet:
TS06-DISP · Colon
Each ИНС-1 colon lamp has its own 220k ballast from HV185, never shared. One MPSA42 switches both lamps' common return, PWM-faded from D10.
V7 upper, V8 lower. Each has its own 220k ballast on the driver board; the MPSA42 there switches COLON_RET.
Notes from tools/ts06pair.py
V7: Upper colon neon. V8: Lower colon neon.

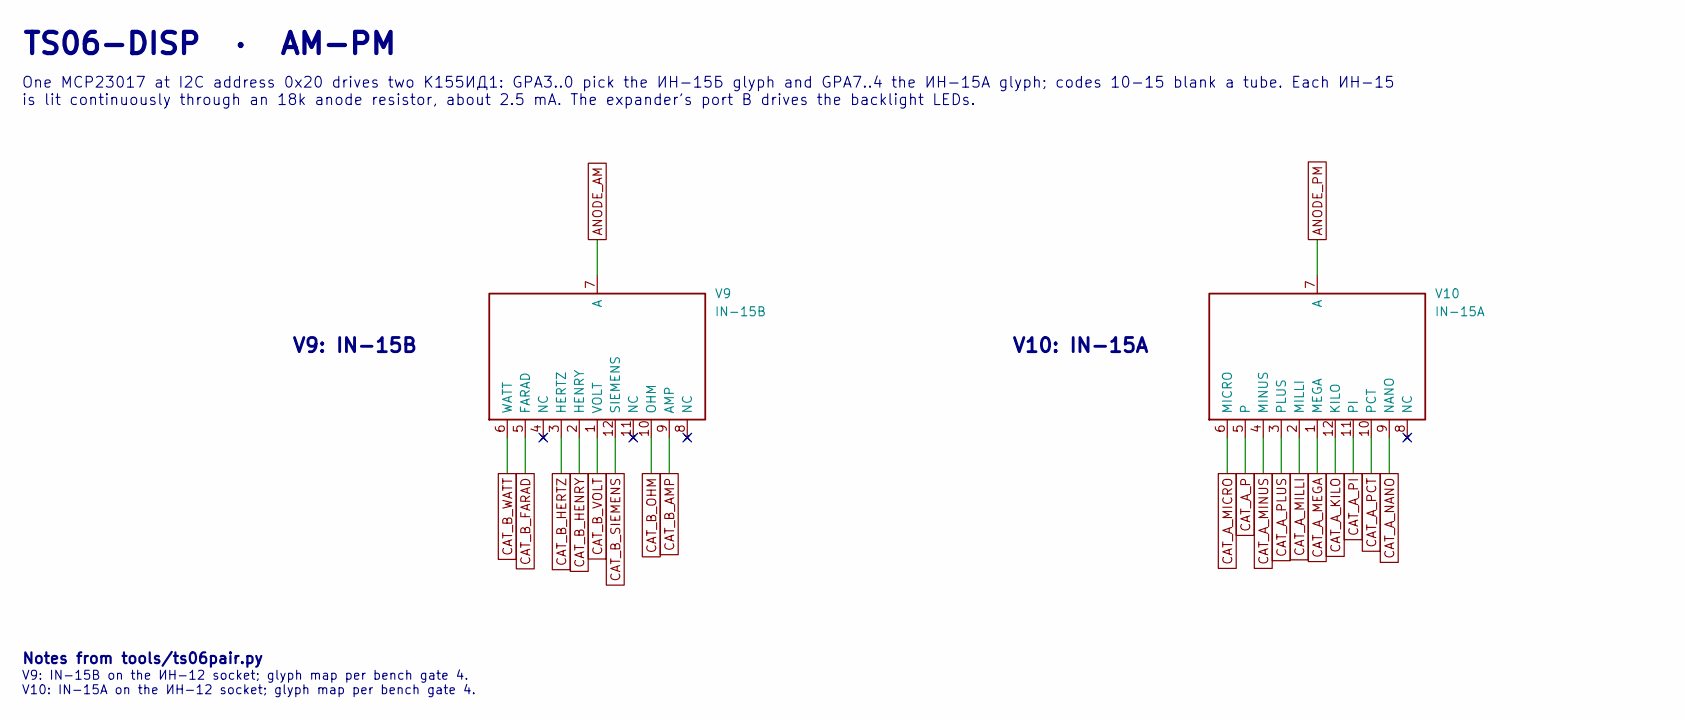
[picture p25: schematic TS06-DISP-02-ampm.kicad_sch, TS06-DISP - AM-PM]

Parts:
V9: IN-15B; TS06_IN12_Socket
V10: IN-15A; TS06_IN12_Socket

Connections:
ANODE_AM: V9.7 (A); also elsewhere on the board
ANODE_PM: V10.7 (A); also elsewhere on the board
CAT_A_KILO: V10.12 (KILO); also elsewhere on the board
CAT_A_MEGA: V10.1 (MEGA); also elsewhere on the board
CAT_A_MICRO: V10.6 (MICRO); also elsewhere on the board
CAT_A_MILLI: V10.2 (MILLI); also elsewhere on the board
CAT_A_MINUS: V10.4 (MINUS); also elsewhere on the board
CAT_A_NANO: V10.9 (NANO); also elsewhere on the board
CAT_A_P: V10.5; also elsewhere on the board
CAT_A_PCT: V10.10 (PCT); also elsewhere on the board
CAT_A_PI: V10.11 (PI); also elsewhere on the board
CAT_A_PLUS: V10.3 (PLUS); also elsewhere on the board
CAT_B_AMP: V9.9 (AMP); also elsewhere on the board
CAT_B_FARAD: V9.5 (FARAD); also elsewhere on the board
CAT_B_HENRY: V9.2 (HENRY); also elsewhere on the board
CAT_B_HERTZ: V9.3 (HERTZ); also elsewhere on the board
CAT_B_OHM: V9.10 (OHM); also elsewhere on the board
CAT_B_SIEMENS: V9.12 (SIEMENS); also elsewhere on the board
CAT_B_VOLT: V9.1 (VOLT); also elsewhere on the board
CAT_B_WATT: V9.6 (WATT); also elsewhere on the board

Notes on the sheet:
TS06-DISP · AM-PM
One MCP23017 at I2C address 0x20 drives two К155ИД1: GPA3..0 pick the ИН-15Б glyph and GPA7..4 the ИН-15А glyph; codes 10-15 blank a tube. Each ИН-15 is lit continuously through an 18k anode resistor, about 2.5 mA. The expander's port B drives the backlight LEDs.
V9: IN-15B
V10: IN-15A
Notes from tools/ts06pair.py
V9: IN-15B on the ИН-12 socket; glyph map per bench gate 4. V10: IN-15A on the ИН-12 socket; glyph map per bench gate 4.

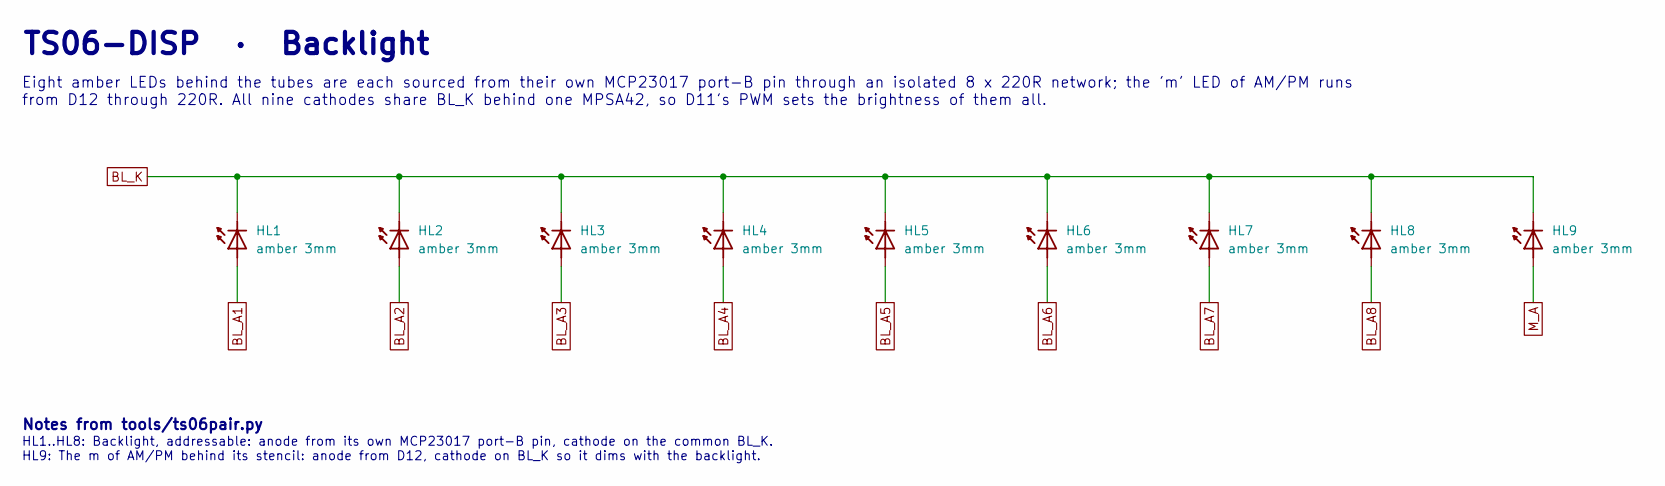
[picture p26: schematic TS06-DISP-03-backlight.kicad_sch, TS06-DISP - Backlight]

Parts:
HL1, HL2, HL3, HL4, HL5, HL6, HL7, HL8, HL9: amber 3mm; TS06_LED_D3.0mm

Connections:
BL_A1: HL1.2 (A); also elsewhere on the board
BL_A2: HL2.2 (A); also elsewhere on the board
BL_A3: HL3.2 (A); also elsewhere on the board
BL_A4: HL4.2 (A); also elsewhere on the board
BL_A5: HL5.2 (A); also elsewhere on the board
BL_A6: HL6.2 (A); also elsewhere on the board
BL_A7: HL7.2 (A); also elsewhere on the board
BL_A8: HL8.2 (A); also elsewhere on the board
BL_K: HL1.1 (K), HL2.1 (K), HL3.1 (K), HL4.1 (K), HL5.1 (K), HL6.1 (K), HL7.1 (K), HL8.1 (K), HL9.1 (K); also elsewhere on the board
M_A: HL9.2 (A); also elsewhere on the board

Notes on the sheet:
TS06-DISP · Backlight
Eight amber LEDs behind the tubes are each sourced from their own MCP23017 port-B pin through an isolated 8 x 220R network; the 'm' LED of AM/PM runs from D12 through 220R. All nine cathodes share BL_K behind one MPSA42, so D11's PWM sets the brightness of them all.
Notes from tools/ts06pair.py
HL1..HL8: Backlight, addressable: anode from its own MCP23017 port-B pin, cathode on the common BL_K. HL9: The m of AM/PM behind its stencil: anode from D12, cathode on BL_K so it dims with the backlight.

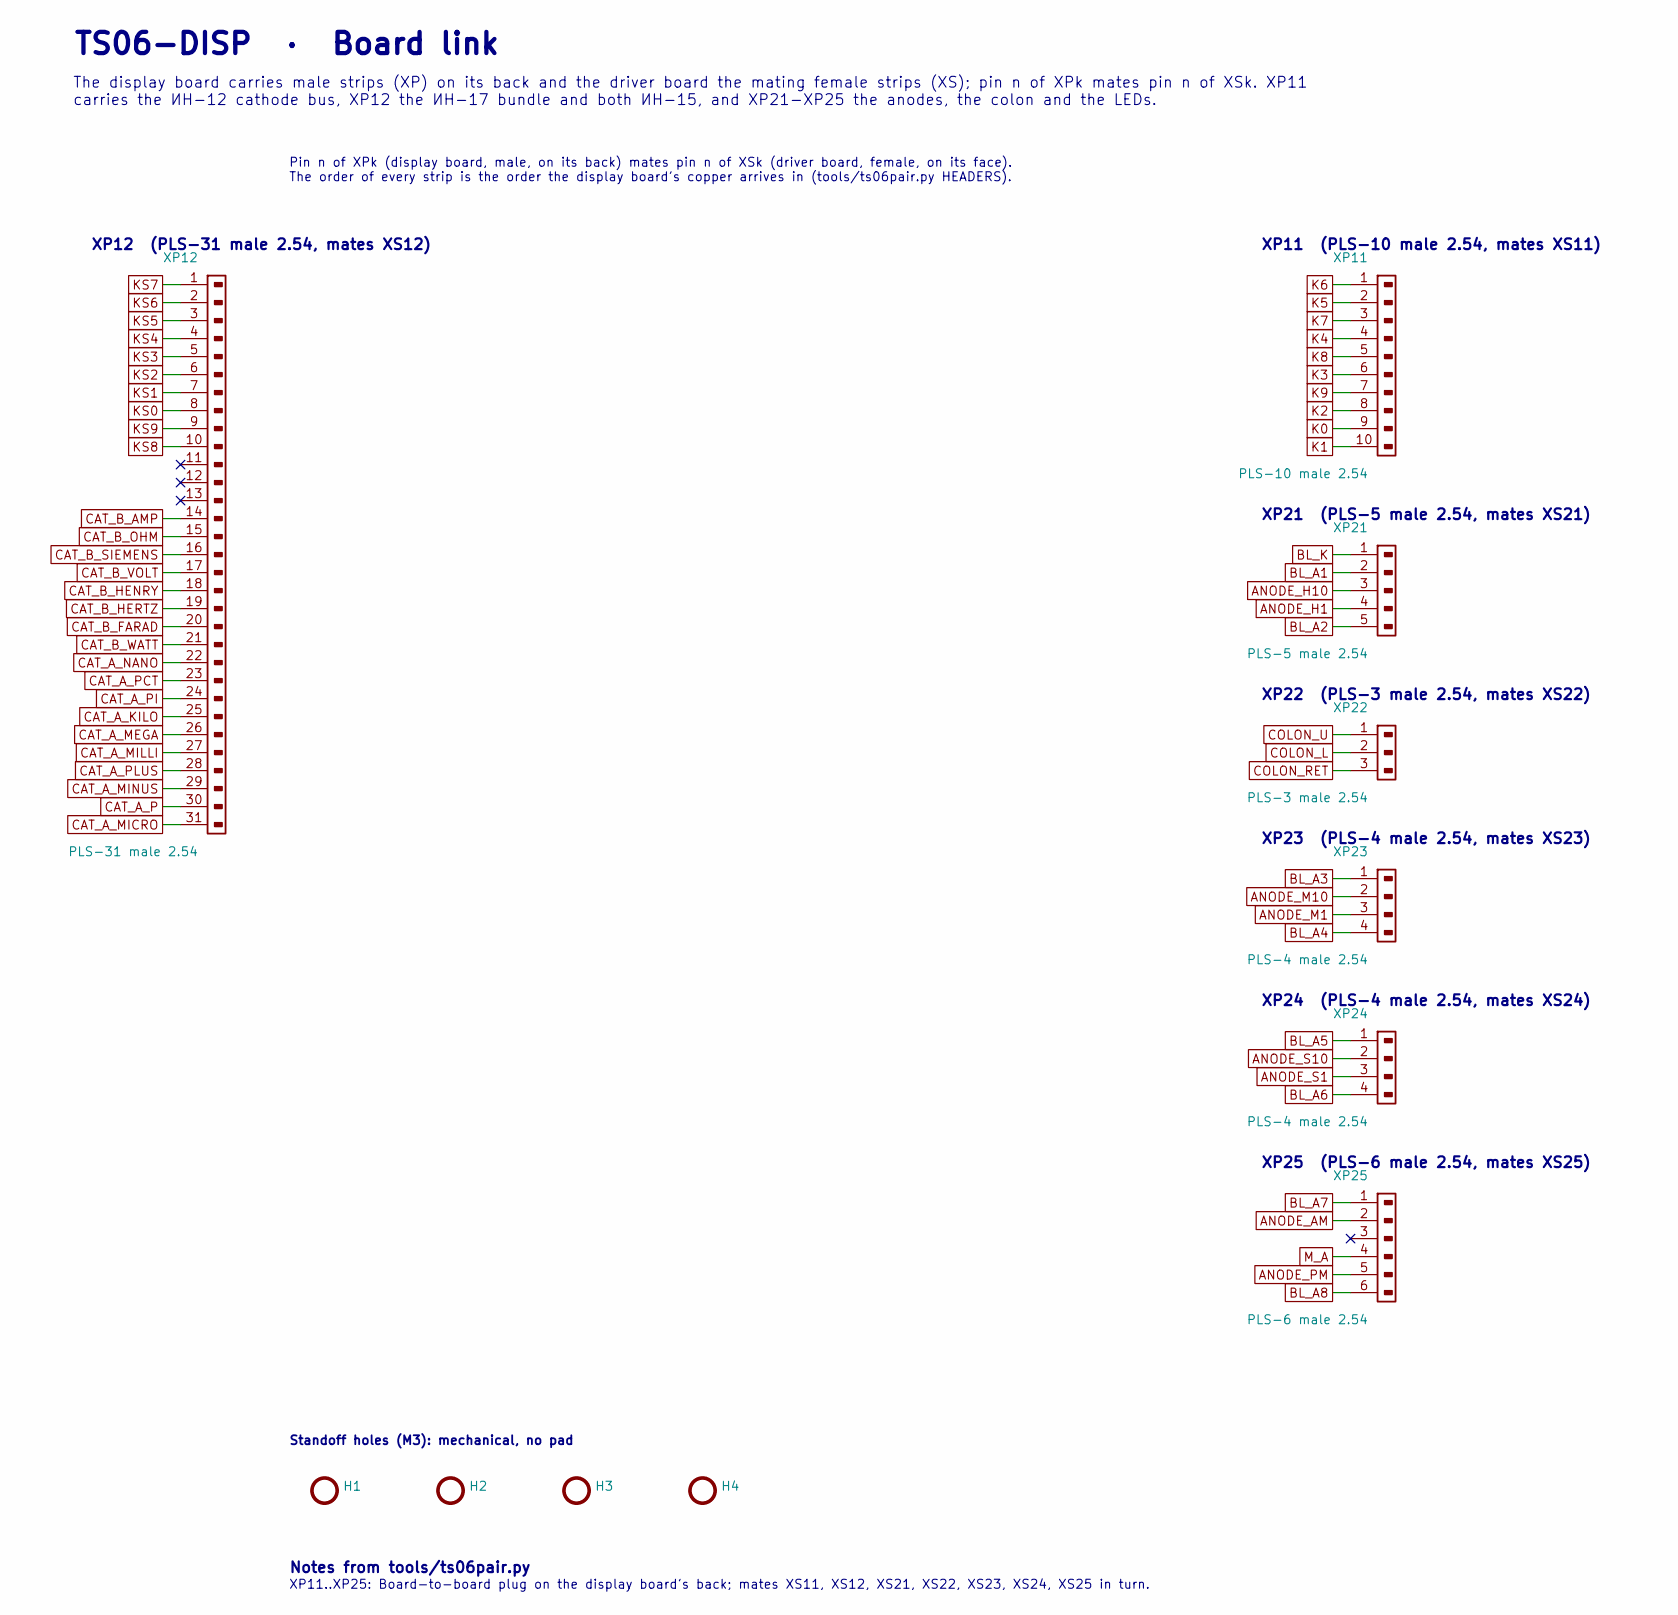
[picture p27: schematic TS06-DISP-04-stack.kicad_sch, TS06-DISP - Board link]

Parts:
H1, H2, H3, H4: TS06_MountingHole_M3
XP11: PLS-10 male 2.54; TS06_PinHeader_1x10_R180
XP12: PLS-31 male 2.54; TS06_PinHeader_1x31_R90
XP21: PLS-5 male 2.54; TS06_PinHeader_1x05_R90
XP22: PLS-3 male 2.54; TS06_PinHeader_1x03_R90
XP23, XP24: PLS-4 male 2.54; TS06_PinHeader_1x04_R90
XP25: PLS-6 male 2.54; TS06_PinHeader_1x06_R90

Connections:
ANODE_AM: XP25.2; also elsewhere on the board
ANODE_H1: XP21.4; also elsewhere on the board
ANODE_H10: XP21.3; also elsewhere on the board
ANODE_M1: XP23.3; also elsewhere on the board
ANODE_M10: XP23.2; also elsewhere on the board
ANODE_PM: XP25.5; also elsewhere on the board
ANODE_S1: XP24.3; also elsewhere on the board
ANODE_S10: XP24.2; also elsewhere on the board
BL_A1: XP21.2; also elsewhere on the board
BL_A2: XP21.5; also elsewhere on the board
BL_A3: XP23.1; also elsewhere on the board
BL_A4: XP23.4; also elsewhere on the board
BL_A5: XP24.1; also elsewhere on the board
BL_A6: XP24.4; also elsewhere on the board
BL_A7: XP25.1; also elsewhere on the board
BL_A8: XP25.6; also elsewhere on the board
BL_K: XP21.1; also elsewhere on the board
CAT_A_KILO: XP12.25; also elsewhere on the board
CAT_A_MEGA: XP12.26; also elsewhere on the board
CAT_A_MICRO: XP12.31; also elsewhere on the board
CAT_A_MILLI: XP12.27; also elsewhere on the board
CAT_A_MINUS: XP12.29; also elsewhere on the board
CAT_A_NANO: XP12.22; also elsewhere on the board
CAT_A_P: XP12.30; also elsewhere on the board
CAT_A_PCT: XP12.23; also elsewhere on the board
CAT_A_PI: XP12.24; also elsewhere on the board
CAT_A_PLUS: XP12.28; also elsewhere on the board
CAT_B_AMP: XP12.14; also elsewhere on the board
CAT_B_FARAD: XP12.20; also elsewhere on the board
CAT_B_HENRY: XP12.18; also elsewhere on the board
CAT_B_HERTZ: XP12.19; also elsewhere on the board
CAT_B_OHM: XP12.15; also elsewhere on the board
CAT_B_SIEMENS: XP12.16; also elsewhere on the board
CAT_B_VOLT: XP12.17; also elsewhere on the board
CAT_B_WATT: XP12.21; also elsewhere on the board
COLON_L: XP22.2; also elsewhere on the board
COLON_RET: XP22.3; also elsewhere on the board
COLON_U: XP22.1; also elsewhere on the board
K0: XP11.9; also elsewhere on the board
K1: XP11.10; also elsewhere on the board
K2: XP11.8; also elsewhere on the board
K3: XP11.6; also elsewhere on the board
K4: XP11.4; also elsewhere on the board
K5: XP11.2; also elsewhere on the board
K6: XP11.1; also elsewhere on the board
K7: XP11.3; also elsewhere on the board
K8: XP11.5; also elsewhere on the board
K9: XP11.7; also elsewhere on the board
KS0: XP12.8; also elsewhere on the board
KS1: XP12.7; also elsewhere on the board
KS2: XP12.6; also elsewhere on the board
KS3: XP12.5; also elsewhere on the board
KS4: XP12.4; also elsewhere on the board
KS5: XP12.3; also elsewhere on the board
KS6: XP12.2; also elsewhere on the board
KS7: XP12.1; also elsewhere on the board
KS8: XP12.10; also elsewhere on the board
KS9: XP12.9; also elsewhere on the board
M_A: XP25.4; also elsewhere on the board

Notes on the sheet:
TS06-DISP · Board link
The display board carries male strips (XP) on its back and the driver board the mating female strips (XS); pin n of XPk mates pin n of XSk. XP11 carries the ИН-12 cathode bus, XP12 the ИН-17 bundle and both ИН-15, and XP21-XP25 the anodes, the colon and the LEDs.
XP12 (PLS-31 male 2.54, mates XS12)
XP11 (PLS-10 male 2.54, mates XS11)
XP21 (PLS-5 male 2.54, mates XS21)
XP22 (PLS-3 male 2.54, mates XS22)
XP23 (PLS-4 male 2.54, mates XS23)
XP24 (PLS-4 male 2.54, mates XS24)
XP25 (PLS-6 male 2.54, mates XS25)
Pin n of XPk (display board, male, on its back) mates pin n of XSk (driver board, female, on its face). The order of every strip is the order the display board's copper arrives in (tools/ts06pair.py HEADERS).
Standoff holes (M3): mechanical, no pad
Notes from tools/ts06pair.py
XP11..XP25: Board-to-board plug on the display board's back; mates XS11, XS12, XS21, XS22, XS23, XS24, XS25 in turn.

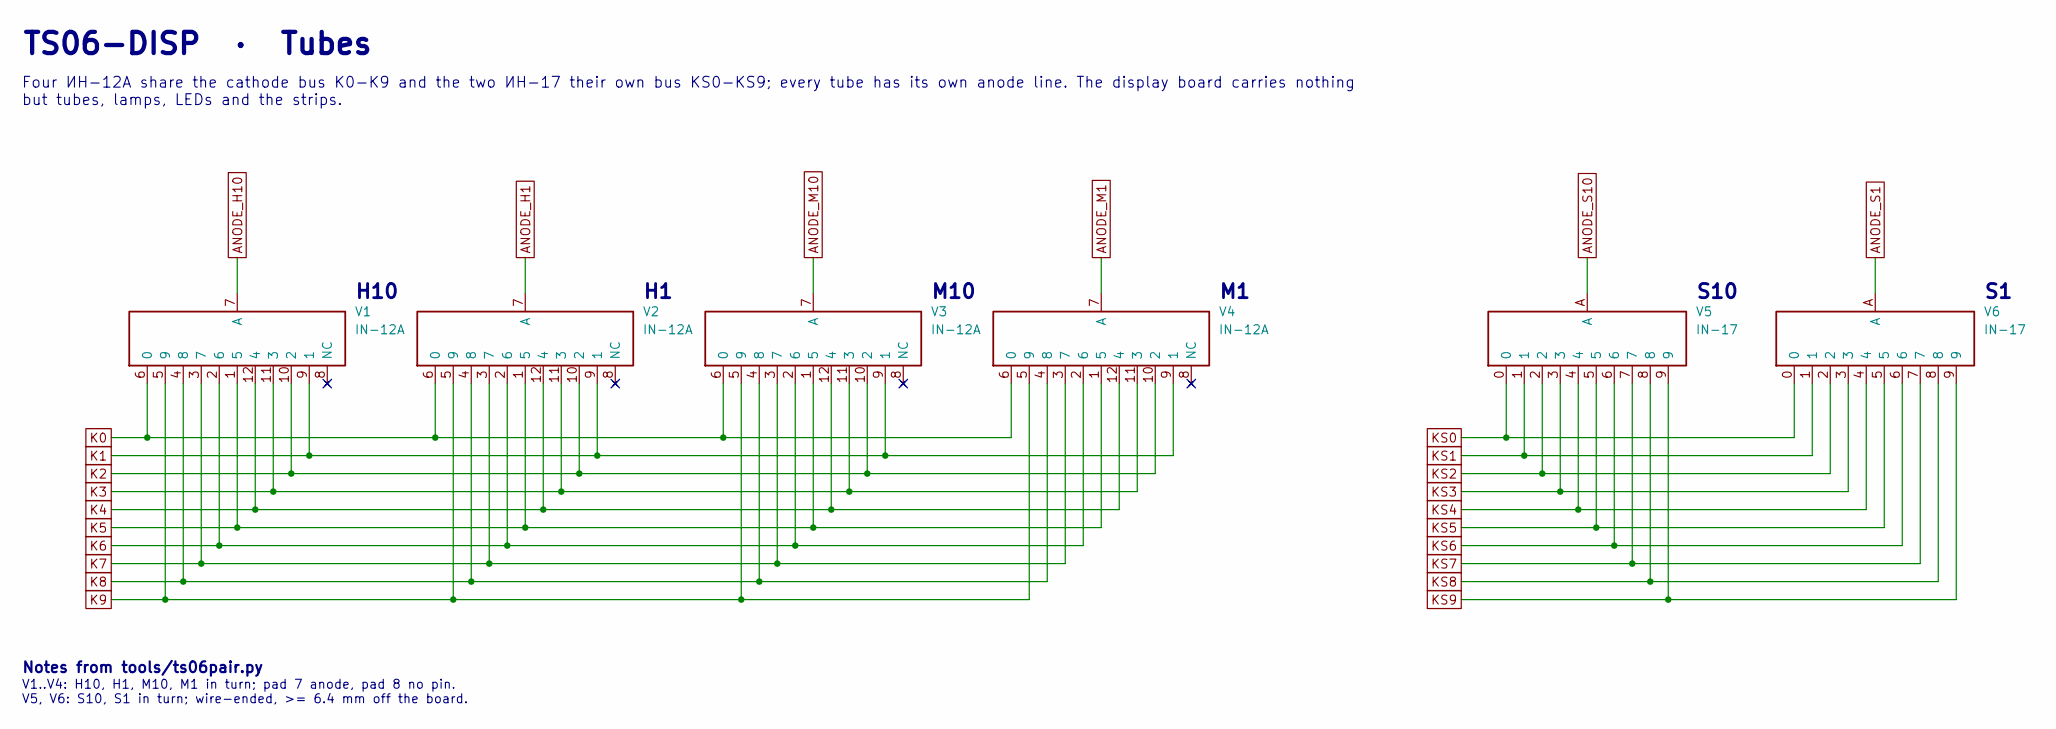
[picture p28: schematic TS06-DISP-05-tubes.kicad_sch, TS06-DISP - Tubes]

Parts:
V1, V2, V3, V4: IN-12A; TS06_IN12_Socket
V5, V6: IN-17; TS06_IN17_Socket

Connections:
ANODE_H1: V2.7 (A); also elsewhere on the board
ANODE_H10: V1.7 (A); also elsewhere on the board
ANODE_M1: V4.7 (A); also elsewhere on the board
ANODE_M10: V3.7 (A); also elsewhere on the board
ANODE_S1: V6.A; also elsewhere on the board
ANODE_S10: V5.A; also elsewhere on the board
K0: V1.6 (0), V2.6 (0), V3.6 (0), V4.6 (0); also elsewhere on the board
K1: V1.9 (1), V2.9 (1), V3.9 (1), V4.9 (1); also elsewhere on the board
K2: V1.10 (2), V2.10 (2), V3.10 (2), V4.10 (2); also elsewhere on the board
K3: V1.11 (3), V2.11 (3), V3.11 (3), V4.11 (3); also elsewhere on the board
K4: V1.12 (4), V2.12 (4), V3.12 (4), V4.12 (4); also elsewhere on the board
K5: V1.1 (5), V2.1 (5), V3.1 (5), V4.1 (5); also elsewhere on the board
K6: V1.2 (6), V2.2 (6), V3.2 (6), V4.2 (6); also elsewhere on the board
K7: V1.3 (7), V2.3 (7), V3.3 (7), V4.3 (7); also elsewhere on the board
K8: V1.4 (8), V2.4 (8), V3.4 (8), V4.4 (8); also elsewhere on the board
K9: V1.5 (9), V2.5 (9), V3.5 (9), V4.5 (9); also elsewhere on the board
KS0: V5.0, V6.0; also elsewhere on the board
KS1: V5.1, V6.1; also elsewhere on the board
KS2: V5.2, V6.2; also elsewhere on the board
KS3: V5.3, V6.3; also elsewhere on the board
KS4: V5.4, V6.4; also elsewhere on the board
KS5: V5.5, V6.5; also elsewhere on the board
KS6: V5.6, V6.6; also elsewhere on the board
KS7: V5.7, V6.7; also elsewhere on the board
KS8: V5.8, V6.8; also elsewhere on the board
KS9: V5.9, V6.9; also elsewhere on the board

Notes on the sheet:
TS06-DISP · Tubes
Four ИН-12А share the cathode bus K0-K9 and the two ИН-17 their own bus KS0-KS9; every tube has its own anode line. The display board carries nothing but tubes, lamps, LEDs and the strips.
H10
M10
S10
Notes from tools/ts06pair.py
V1..V4: H10, H1, M10, M1 in turn; pad 7 anode, pad 8 no pin. V5, V6: S10, S1 in turn; wire-ended, >= 6.4 mm off the board.

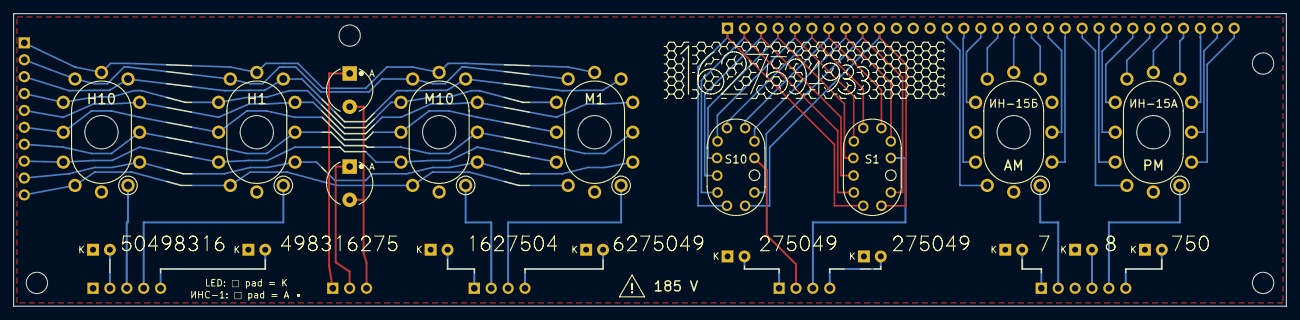
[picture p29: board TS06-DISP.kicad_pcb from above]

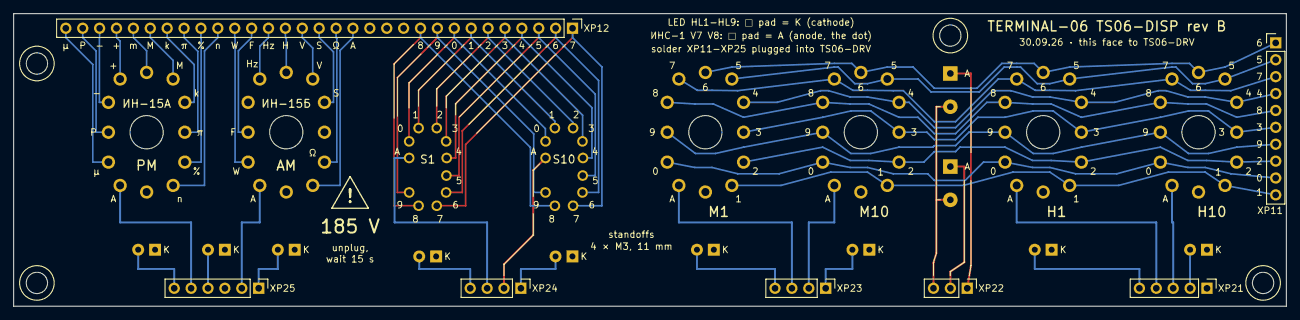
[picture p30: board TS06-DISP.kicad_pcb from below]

Board: 2 copper layers, 191.4 x 44.0 mm, 30 parts (7 on the bottom side), 59 nets.

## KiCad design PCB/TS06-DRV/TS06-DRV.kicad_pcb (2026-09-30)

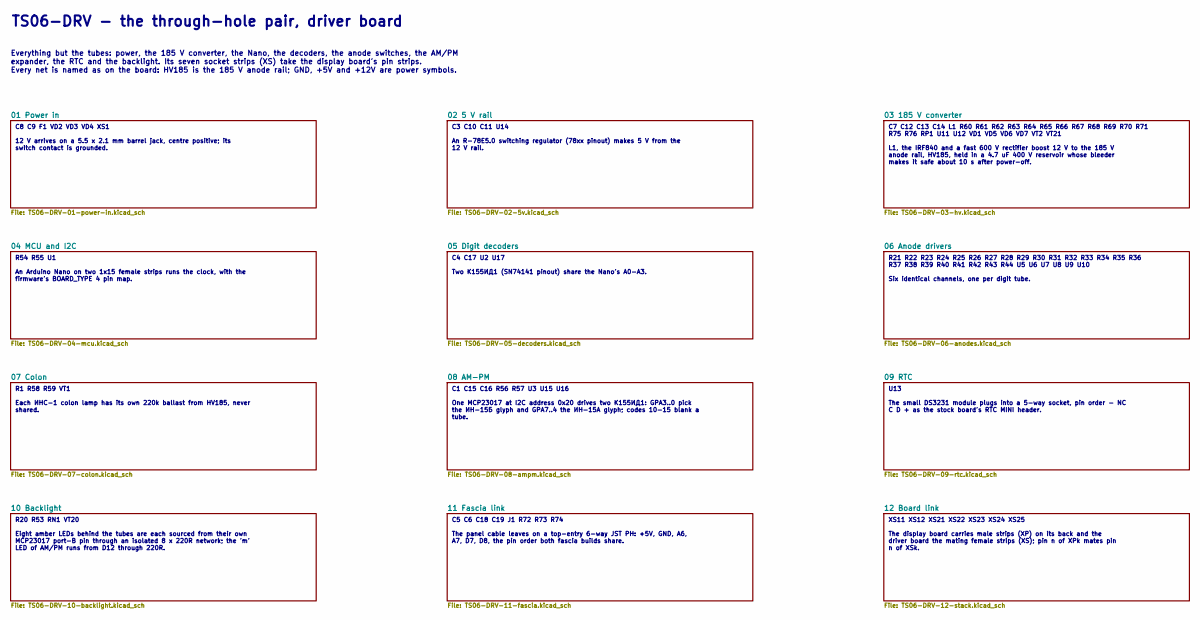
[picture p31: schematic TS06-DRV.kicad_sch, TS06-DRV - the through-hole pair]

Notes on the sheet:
TS06-DRV - the through-hole pair, driver board
Everything but the tubes: power, the 185 V converter, the Nano, the decoders, the anode switches, the AM/PM expander, the RTC and the backlight. Its seven socket strips (XS) take the display board's pin strips. Every net is named as on the board: HV185 is the 185 V anode rail; GND, +5V and +12V are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
C8 C9 F1 VD2 VD3 VD4 XS1 12 V arrives on a 5.5 x 2.1 mm barrel jack, centre positive; its switch contact is grounded.
C3 C10 C11 U14 An R-78E5.0 switching regulator (78xx pinout) makes 5 V from the 12 V rail.
C7 C12 C13 C14 L1 R60 R61 R62 R63 R64 R65 R66 R67 R68 R69 R70 R71 R75 R76 RP1 U11 U12 VD1 VD5 VD6 VD7 VT2 VT21 L1, the IRF840 and a fast 600 V rectifier boost 12 V to the 185 V anode rail, HV185, held in a 4.7 uF 400 V reservoir whose bleeder makes it safe about 10 s after power-off.
R54 R55 U1 An Arduino Nano on two 1x15 female strips runs the clock, with the firmware's BOARD_TYPE 4 pin map.
C4 C17 U2 U17 Two К155ИД1 (SN74141 pinout) share the Nano's A0-A3.
R21 R22 R23 R24 R25 R26 R27 R28 R29 R30 R31 R32 R33 R34 R35 R36 R37 R38 R39 R40 R41 R42 R43 R44 U5 U6 U7 U8 U9 U10 Six identical channels, one per digit tube.
R1 R58 R59 VT1 Each ИНС-1 colon lamp has its own 220k ballast from HV185, never shared.
C1 C15 C16 R56 R57 U3 U15 U16 One MCP23017 at I2C address 0x20 drives two К155ИД1: GPA3..0 pick the ИН-15Б glyph and GPA7..4 the ИН-15А glyph; codes 10-15 blank a tube.
U13 The small DS3231 module plugs into a 5-way socket, pin order - NC C D + as the stock board's RTC MINI header.
R20 R53 RN1 VT20 Eight amber LEDs behind the tubes are each sourced from their own MCP23017 port-B pin through an isolated 8 x 220R network; the 'm' LED of AM/PM runs from D12 through 220R.
C5 C6 C18 C19 J1 R72 R73 R74 The panel cable leaves on a top-entry 6-way JST PH: +5V, GND, A6, A7, D7, D8, the pin order both fascia builds share.
XS11 XS12 XS21 XS22 XS23 XS24 XS25 The display board carries male strips (XP) on its back and the driver board the mating female strips (XS); pin n of XPk mates pin n of XSk.

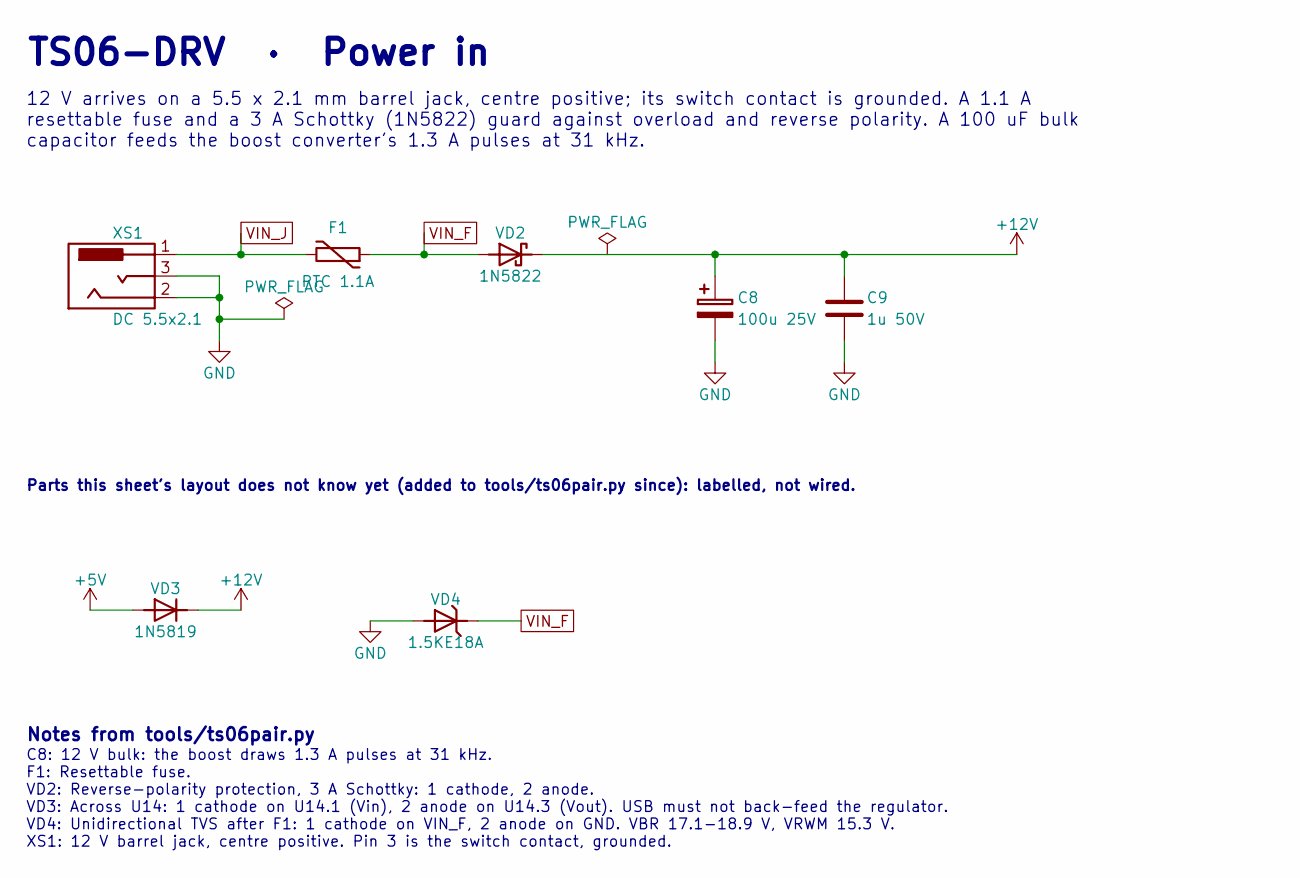
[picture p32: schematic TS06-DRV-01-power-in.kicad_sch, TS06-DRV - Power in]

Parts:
C8: 100u 25V; TS06_CP_Radial_D6.3mm_P2.50mm
C9: 1u 50V; TS06_C_Disc_P5.00mm_R270
F1: PTC 1.1A; TS06_Fuse_PTC_MF-RG1100
VD2: 1N5822; TS06_D_DO-201AD_P15.24mm_R180
VD3: 1N5819; TS06_D_DO-41_P10.16mm
VD4: 1.5KE18A; TS06_D_DO-201AD_P15.24mm
XS1: DC 5.5x2.1; TS06_BarrelJack_Horizontal

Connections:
+5V: VD3.2 (A); also elsewhere on the board
+12V: C8.1, C9.1, VD2.1 (K), VD3.1 (K); also elsewhere on the board
GND: C8.2, C9.2, VD4.2 (A), XS1.2 (-), XS1.3 (SW); also elsewhere on the board
VIN_F: F1.2, VD2.2 (A), VD4.1 (K)
VIN_J: F1.1, XS1.1 (+)

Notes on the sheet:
TS06-DRV · Power in
12 V arrives on a 5.5 x 2.1 mm barrel jack, centre positive; its switch contact is grounded. A 1.1 A resettable fuse and a 3 A Schottky (1N5822) guard against overload and reverse polarity. A 100 uF bulk capacitor feeds the boost converter's 1.3 A pulses at 31 kHz.
Parts this sheet's layout does not know yet (added to tools/ts06pair.py since): labelled, not wired.
Notes from tools/ts06pair.py
C8: 12 V bulk: the boost draws 1.3 A pulses at 31 kHz. F1: Resettable fuse. VD2: Reverse-polarity protection, 3 A Schottky: 1 cathode, 2 anode. VD3: Across U14: 1 cathode on U14.1 (Vin), 2 anode on U14.3 (Vout). USB must not back-feed the regulator. VD4: Unidirectional TVS after F1: 1 cathode on VI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

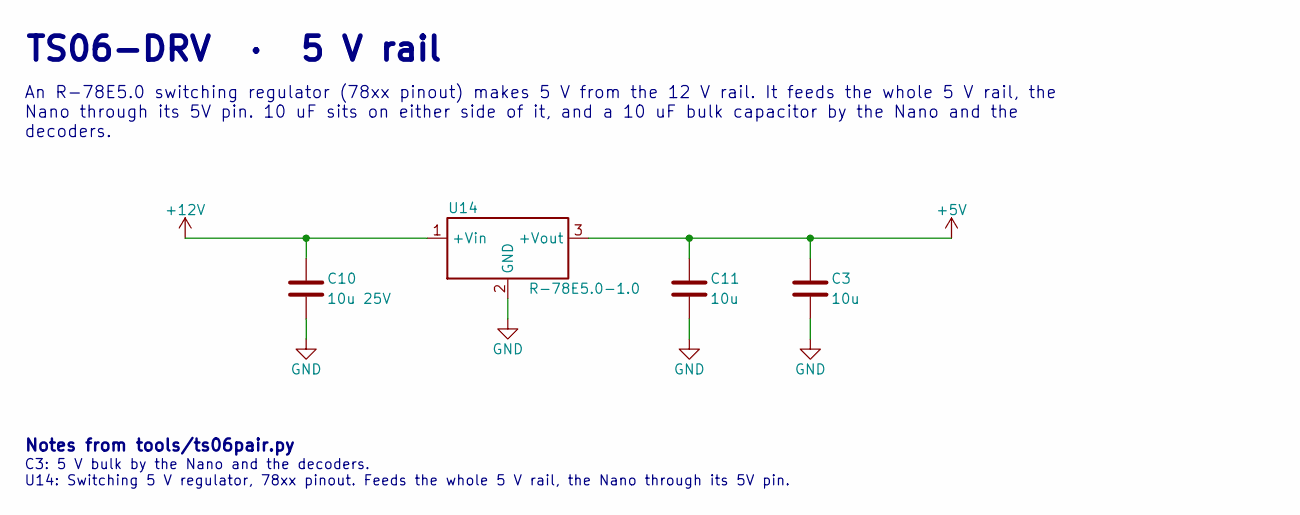
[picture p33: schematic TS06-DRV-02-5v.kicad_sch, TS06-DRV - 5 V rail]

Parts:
C3: 10u; TS06_C_Disc_P5.00mm
C10: 10u 25V; TS06_C_Disc_P5.00mm_R270
C11: 10u; TS06_C_Disc_P5.00mm_R90
U14: R-78E5.0-1.0; TS06_R-78E_SIP3

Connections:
+5V: C3.1, C11.1, U14.3 (+Vout); also elsewhere on the board
+12V: C10.1, U14.1 (+Vin); also elsewhere on the board
GND: C3.2, C10.2, C11.2, U14.2 (GND); also elsewhere on the board

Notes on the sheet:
TS06-DRV · 5 V rail
An R-78E5.0 switching regulator (78xx pinout) makes 5 V from the 12 V rail. It feeds the whole 5 V rail, the Nano through its 5V pin. 10 uF sits on either side of it, and a 10 uF bulk capacitor by the Nano and the decoders.
Notes from tools/ts06pair.py
C3: 5 V bulk by the Nano and the decoders. U14: Switching 5 V regulator, 78xx pinout. Feeds the whole 5 V rail, the Nano through its 5V pin.

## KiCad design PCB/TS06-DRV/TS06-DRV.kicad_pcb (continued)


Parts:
C7: 4u7 400V; TS06_CP_Radial_D10.0mm_P5.00mm_R180
C12: 1u 50V; TS06_C_Disc_P5.00mm_R270
C13: 100n; TS06_C_Disc_P5.00mm_R180
C14: 100n; TS06_C_Disc_P5.00mm
L1: 220u 1.8A 5900-221-RC; TS06_L_Axial_D11.5mm_L22.9mm_P27.94mm
R60, R61: 470k; TS06_R_Axial_MLT-0.5_P15.24mm
R62: 750k 1%; TS06_R_Axial_MLT-0.5_P15.24mm
R63: 750k 1%; TS06_R_Axial_MLT-0.5_P15.24mm_R270
R64: 18k 1%; TS06_R_Axial_DIN0207_P10.16mm
R65: 1M; TS06_R_Axial_DIN0207_P2.54mm_Vertical_R180
R66: 2k2; TS06_R_Axial_DIN0207_P2.54mm_Vertical_R270
R67: 10R; TS06_R_Axial_DIN0207_P2.54mm_Vertical
R68: 10k; TS06_R_Axial_DIN0207_P2.54mm_Vertical_R90
R69, R70: 10k 1%; TS06_R_Axial_DIN0207_P2.54mm_Vertical_R90
R71: 10k; TS06_R_Axial_DIN0207_P2.54mm_Vertical_R180
R75: 100k; TS06_R_Axial_DIN0207_P10.16mm_R180
R76: 10k; TS06_R_Axial_DIN0207_P10.16mm
RP1: 5k; TS06_Trimmer_3296W
U11: TC4420; TS06_DIP-8_W7.62mm_Socket
U12: LM393; TS06_DIP-8_W7.62mm_Socket_R180
VD1: HER106 / UF4007; TS06_D_DO-41_P10.16mm_R180
VD5: 1N4762A; TS06_D_DO-41_P10.16mm
VD6: 1N4762A; TS06_D_DO-41_P10.16mm_R180
VD7: 1N4761A; TS06_D_DO-41_P10.16mm
VT2: 2N3904; TS06_TO-92_Inline_Wide_R180
VT21: IRF840; TS06_TO-220-3_Vertical_HV

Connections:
+5V: C13.1, R69.1, U12.8 (V+); also elsewhere on the board
+12V: C12.1, L1.1, U11.1 (VDD), U11.8 (VDD); also elsewhere on the board
BLEED_HV: R60.2, R61.1
D9: R66.1; also elsewhere on the board
FB: R63.2, R64.1, U12.2 (IN1-)
FB_LOW: R64.2, RP1.1
FB_MID: R62.2, R63.1
GATE: R67.2, R68.1, VT21.1 (G)
GATE_D: R67.1, U11.6 (OUT), U11.7 (OUT)
GND: C7.2, C12.2, C13.2, C14.2, R61.2, R68.2, R70.2, R71.2, R76.2, RP1.2 (W), RP1.3, U11.4 (GND), U11.5 (GND), U12.4 (GND), U12.6 (IN2-), VT2.1 (E), VT21.3 (S); also elsewhere on the board
HV185: C7.1, R60.1, R62.1, VD1.1 (K), VD5.1 (K); also elsewhere on the board
OVZ_1: VD5.2 (A), VD6.1 (K)
OVZ_2: VD6.2 (A), VD7.1 (K)
OVZ_3: R75.1, VD7.2 (A)
OV_B: R75.2, R76.1, VT2.2 (B)
PWM_G: R65.1, R66.2, R71.1, U11.2 (IN), U12.1 (OUT1), VT2.3 (C)
SW: L1.2, VD1.2 (A), VT21.2 (D)
VREF: C14.1, R65.2, R69.2, R70.1, U12.3 (IN1+), U12.5 (IN2+)

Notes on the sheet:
TS06-DRV · 185 V converter
L1, the IRF840 and a fast 600 V rectifier boost 12 V to the 185 V anode rail, HV185, held in a 4.7 uF 400 V reservoir whose bleeder makes it safe about 10 s after power-off. D9's clock reaches the MOSFET through a TC4420 driver, and an LM393 holds the driver's input low while the divided rail is ab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
Parts this sheet's layout does not know yet (added to tools/ts06pair.py since): labelled, not wired.
Notes from tools/ts06pair.py
C7: The reservoir, 400 V. L1: Bourns 5900-221-RC: 220 uH, Isat 1.8 A, Irated 1.6 A, DCR 0.162 ohm; axial, lying, 1.1 mm holes 27.94 mm apart. R60: Bleeder: the reservoir is safe ~10 s after power-off. R62: Divider top, two in series: ~92 V each at 185 V and ~104 V at the trimmer's 210 V end, agains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


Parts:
R54, R55: 4k7; TS06_R_Axial_DIN0207_P2.54mm_Vertical
U1: Arduino Nano; TS06_Arduino_Nano_R90

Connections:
+5V: R54.1, R55.1, U1.27 (+5V); also elsewhere on the board
A0: U1.19 (A0); also elsewhere on the board
A1: U1.20 (A1); also elsewhere on the board
A2: U1.21 (A2); also elsewhere on the board
A3: U1.22 (A3); also elsewhere on the board
A6: U1.25 (A6); also elsewhere on the board
A7: U1.26 (A7); also elsewhere on the board
D2: U1.5 (D2); also elsewhere on the board
D3: U1.6 (D3); also elsewhere on the board
D4: U1.7 (D4); also elsewhere on the board
D5: U1.8 (D5); also elsewhere on the board
D6: U1.9 (D6); also elsewhere on the board
D7: U1.10 (D7); also elsewhere on the board
D8: U1.11 (D8); also elsewhere on the board
D9: U1.12 (D9); also elsewhere on the board
D10: U1.13 (D10); also elsewhere on the board
D11: U1.14 (D11); also elsewhere on the board
D12: U1.15 (D12); also elsewhere on the board
D13: U1.16 (D13); also elsewhere on the board
GND: U1.4 (GND), U1.29 (GND); also elsewhere on the board
SCL: R55.2, U1.24 (A5/SCL); also elsewhere on the board
SDA: R54.2, U1.23 (A4/SDA); also elsewhere on the board

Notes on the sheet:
TS06-DRV · MCU and I2C
An Arduino Nano on two 1x15 female strips runs the clock, with the firmware's BOARD_TYPE 4 pin map. A4 and A5 carry the I2C bus to the MCP23017 and the RTC module, pulled up to 5 V through 4k7.
I2C bus: pulled up here; on it U3, the MCP23017 at 0x20 (AM/PM), and U13, the DS3231 module (RTC).
Notes from tools/ts06pair.py
R54: I2C pull-ups. U1: On two 1x15 female strips. Pin map is the firmware's (see the module docstring).


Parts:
C4: 100n; TS06_C_Disc_P5.00mm_R270
C17: 100n; TS06_C_Disc_P5.00mm
U2: K155ID1; TS06_DIP-16_W7.62mm_Socket_Oval_R180
U17: K155ID1; TS06_DIP-16_W7.62mm_Socket_Oval_R90

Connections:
+5V: C4.1, C17.1, U2.5 (VCC), U17.5 (VCC); also elsewhere on the board
A0: U2.7 (C), U17.7 (C); also elsewhere on the board
A1: U2.6 (B), U17.6 (B); also elsewhere on the board
A2: U2.4 (D), U17.4 (D); also elsewhere on the board
A3: U2.3 (A), U17.3 (A); also elsewhere on the board
GND: C4.2, C17.2, U2.12 (GND), U17.12 (GND); also elsewhere on the board
K0: U2.15 (Q1); also elsewhere on the board
K1: U2.16 (Q0); also elsewhere on the board
K2: U2.14 (Q5); also elsewhere on the board
K3: U2.13 (Q4); also elsewhere on the board
K4: U2.11 (Q6); also elsewhere on the board
K5: U2.10 (Q7); also elsewhere on the board
K6: U2.9 (Q3); also elsewhere on the board
K7: U2.8 (Q2); also elsewhere on the board
K8: U2.2 (Q9); also elsewhere on the board
K9: U2.1 (Q8); also elsewhere on the board
KS0: U17.15 (Q1); also elsewhere on the board
KS1: U17.16 (Q0); also elsewhere on the board
KS2: U17.14 (Q5); also elsewhere on the board
KS3: U17.13 (Q4); also elsewhere on the board
KS4: U17.11 (Q6); also elsewhere on the board
KS5: U17.10 (Q7); also elsewhere on the board
KS6: U17.9 (Q3); also elsewhere on the board
KS7: U17.8 (Q2); also elsewhere on the board
KS8: U17.2 (Q9); also elsewhere on the board
KS9: U17.1 (Q8); also elsewhere on the board

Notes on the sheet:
TS06-DRV · Digit decoders
Two К155ИД1 (SN74141 pinout) share the Nano's A0-A3. U2 drives the ИН-12 cathode bus through XS11, U17 the ИН-17 pair through XS12 pins 1-10, both with the board's own digit map (BOARD_TYPE 4).
Inputs: A0 -> C, A1 -> B, A2 -> D, A3 -> A on both chips, the wiring the firmware's decoderNibble() assumes. Firmware digit map BOARD_TYPE 4: digitMask[] = {1, 0, 5, 4, 6, 7, 3, 2, 9, 8} (digit d -> code).
Notes from tools/ts06pair.py
U2: ИН-12 bus decoder -> XS11. Digit map BOARD_TYPE 4 (see DIGIT_MASK4). U17: ИН-17 pair decoder -> XS12 pins 1-10, same inputs and digit map as U2.


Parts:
R21, R22: 470R; TS06_R_Axial_DIN0207_P10.16mm_R270
R23, R24, R25, R26: 470R; TS06_R_Axial_DIN0207_P2.54mm_Vertical_R270
R27, R28, R29, R30: 6k8 TBC; TS06_R_Axial_MLT-0.5_P15.24mm
R31: 12k; TS06_R_Axial_MLT-0.5_P15.24mm_R180
R32: 12k; TS06_R_Axial_MLT-0.5_P15.24mm
R33, R36: 510k DNP; TS06_R_Axial_DIN0207_P2.54mm_Vertical_R180; not fitted
R34, R35, R37, R38, R39, R40, R42: 510k DNP; TS06_R_Axial_DIN0207_P2.54mm_Vertical; not fitted
R41, R43, R44: 510k DNP; TS06_R_Axial_DIN0207_P2.54mm_Vertical_R90; not fitted
U5, U6, U7, U8, U9, U10: TLP627; TS06_DIP-4_W7.62mm_Socket_R270

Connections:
ANODE_H1: R28.2, R35.1; also elsewhere on the board
ANODE_H10: R27.2, R33.1; also elsewhere on the board
ANODE_M1: R30.2, R39.1; also elsewhere on the board
ANODE_M10: R29.2, R37.1; also elsewhere on the board
ANODE_S1: R32.2, R43.1; also elsewhere on the board
ANODE_S10: R31.2, R41.1; also elsewhere on the board
BLEED_H1: R35.2, R36.1
BLEED_H10: R33.2, R34.1
BLEED_M1: R39.2, R40.1
BLEED_M10: R37.2, R38.1
BLEED_S1: R43.2, R44.1
BLEED_S10: R41.2, R42.1
D2: R25.1; also elsewhere on the board
D3: R24.1; also elsewhere on the board
D4: R23.1; also elsewhere on the board
D5: R22.1; also elsewhere on the board
D6: R21.1; also elsewhere on the board
D13: R26.1; also elsewhere on the board
EMIT_H1: R28.1, U6.3 (E)
EMIT_H10: R27.1, U5.3 (E)
EMIT_M1: R30.1, U8.3 (E)
EMIT_M10: R29.1, U7.3 (E)
EMIT_S1: R32.1, U10.3 (E)
EMIT_S10: R31.1, U9.3 (E)
GND: R34.2, R36.2, R38.2, R40.2, R42.2, R44.2, U5.2 (K), U6.2 (K), U7.2 (K), U8.2 (K), U9.2 (K), U10.2 (K); also elsewhere on the board
HV185: U5.4 (C), U6.4 (C), U7.4 (C), U8.4 (C), U9.4 (C), U10.4 (C); also elsewhere on the board
OPT_H1: R22.2, U6.1 (A)
OPT_H10: R21.2, U5.1 (A)
OPT_M1: R24.2, U8.1 (A)
OPT_M10: R23.2, U7.1 (A)
OPT_S1: R26.2, U10.1 (A)
OPT_S10: R25.2, U9.1 (A)

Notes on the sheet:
TS06-DRV · Anode drivers
Six identical channels, one per digit tube. A Nano pin lights a TLP627's LED through 470 R, and the opto's 300 V Darlington connects HV185 to the tube's anode through its series resistor. The 510k bleed pairs are fitted only if the bench asks for them.
H10
M10
S10
Notes from tools/ts06pair.py
R21..R26: Opto LED, ~8 mA. R27..R32: Anode series resistor, one per tube; TBC values wait for bench gate 2. R33..R43: Bleed pair, DNP unless the bench asks; ~92 V each, standing to keep the channel compact. U5..U10: Anode switch for H10, H1, M10, M1, S10, S1 in turn: 1 LED anode, 2 LED cathode, 3 e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


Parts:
R1: 10k; TS06_R_Axial_DIN0207_P2.54mm_Vertical_R270
R58, R59: 220k; TS06_R_Axial_MLT-0.5_P15.24mm_R270
VT1: MPSA42; TS06_TO-92_Inline_Wide_R270

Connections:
B1: R1.2, VT1.2 (B)
COLON_L: R59.2; also elsewhere on the board
COLON_RET: VT1.3 (C); also elsewhere on the board
COLON_U: R58.2; also elsewhere on the board
D10: R1.1; also elsewhere on the board
GND: VT1.1 (E); also elsewhere on the board
HV185: R58.1, R59.1; also elsewhere on the board

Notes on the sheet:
TS06-DRV · Colon
Each ИНС-1 colon lamp has its own 220k ballast from HV185, never shared. One MPSA42 switches both lamps' common return, PWM-faded from D10.
The lamps are on the display board: V7 upper, V8 lower (XS22 carries COLON_U, COLON_L and COLON_RET).
Notes from tools/ts06pair.py
R58: Own ballast per lamp, never shared (spec §3). VT1: Low-side switch for both lamps, PWM-faded from D10.

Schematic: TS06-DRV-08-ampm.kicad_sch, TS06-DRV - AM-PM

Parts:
C1: 100n; TS06_C_Disc_P5.00mm_R180
C15, C16: 100n; TS06_C_Disc_P5.00mm
R56, R57: 18k; TS06_R_Axial_MLT-0.5_P15.24mm
U3: MCP23017-E/SP; TS06_DIP-28_W7.62mm_Socket_R270
U15, U16: K155ID1; TS06_DIP-16_W7.62mm_Socket_Oval_R90

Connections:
+5V: C1.1, C15.1, C16.1, U3.9 (VDD), U3.18 (~RESET), U15.5 (VCC), U16.5 (VCC); also elsewhere on the board
ANODE_AM: R56.1; also elsewhere on the board
ANODE_PM: R57.1; also elsewhere on the board
CAT_A_KILO: U16.11 (Q6); also elsewhere on the board
CAT_A_MEGA: U16.13 (Q4); also elsewhere on the board
CAT_A_MICRO: U16.2 (Q9); also elsewhere on the board
CAT_A_MILLI: U16.14 (Q5); also elsewhere on the board
CAT_A_MINUS: U16.16 (Q0); also elsewhere on the board
CAT_A_NANO: U16.8 (Q2); also elsewhere on the board
CAT_A_P: U16.1 (Q8); also elsewhere on the board
CAT_A_PCT: U16.9 (Q3); also elsewhere on the board
CAT_A_PI: U16.10 (Q7); also elsewhere on the board
CAT_A_PLUS: U16.15 (Q1); also elsewhere on the board
CAT_B_AMP: U15.8 (Q2); also elsewhere on the board
CAT_B_FARAD: U15.15 (Q1); also elsewhere on the board
CAT_B_HENRY: U15.13 (Q4); also elsewhere on the board
CAT_B_HERTZ: U15.14 (Q5); also elsewhere on the board
CAT_B_OHM: U15.9 (Q3); also elsewhere on the board
CAT_B_SIEMENS: U15.10 (Q7); also elsewhere on the board
CAT_B_VOLT: U15.11 (Q6); also elsewhere on the board
CAT_B_WATT: U15.16 (Q0); also elsewhere on the board
GND: C1.2, C15.2, C16.2, U3.10 (VSS), U3.15 (A0), U3.16 (A1), U3.17 (A2), U15.12 (GND), U16.12 (GND); also elsewhere on the board
HV185: R56.2, R57.2; also elsewhere on the board
SCL: U3.12 (SCL); also elsewhere on the board
SDA: U3.13 (SDA); also elsewhere on the board
XA0: U3.21 (GPA0), U15.7 (C)
XA1: U3.22 (GPA1), U15.6 (B)
XA2: U3.23 (GPA2), U15.4 (D)
XA3: U3.24 (GPA3), U15.3 (A)
XA4: U3.25 (GPA4), U16.7 (C)
XA5: U3.26 (GPA5), U16.6 (B)
XA6: U3.27 (GPA6), U16.4 (D)
XA7: U3.28 (GPA7), U16.3 (A)
XB0: U3.1 (GPB0); also elsewhere on the board
XB1: U3.2 (GPB1); also elsewhere on the board
XB2: U3.3 (GPB2); also elsewhere on the board
XB3: U3.4 (GPB3); also elsewhere on the board
XB4: U3.5 (GPB4); also elsewhere on the board
XB5: U3.6 (GPB5); also elsewhere on the board
XB6: U3.7 (GPB6); also elsewhere on the board
XB7: U3.8 (GPB7); also elsewhere on the board

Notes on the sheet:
TS06-DRV · AM-PM
One MCP23017 at I2C address 0x20 drives two К155ИД1: GPA3..0 pick the ИН-15Б glyph and GPA7..4 the ИН-15А glyph; codes 10-15 blank a tube. Each ИН-15 is lit continuously through an 18k anode resistor, about 2.5 mA. The expander's port B drives the backlight LEDs.
Codes 10-15 light nothing: the tube is blank. The firmware keeps the inverse of this table.
Notes from tools/ts06pair.py
R56: Static anode resistor, ИН-15Б (bench gate 2 checks it). R57: Static anode resistor, ИН-15А. U3: I2C expander at 0x20 (A0-A2 grounded), 300-mil SPDIP. GPA3..0 -> U15 (ИН-15Б), GPA7..4 -> U16 (ИН-15А), GPB0-7 -> backlight LEDs through RN1. U15: ИН-15Б decoder, nibble on GPA3..0 per XA_IN. Codes 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

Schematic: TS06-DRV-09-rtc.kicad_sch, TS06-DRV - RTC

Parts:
U13: DS3231 mini; TS06_PinHeader_1x05_DS3231_R270

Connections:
+5V: U13.5 (+); also elsewhere on the board
GND: U13.1 (-); also elsewhere on the board
SCL: U13.3 (C/SCL); also elsewhere on the board
SDA: U13.4 (D/SDA); also elsewhere on the board

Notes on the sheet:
TS06-DRV · RTC
The small DS3231 module plugs into a 5-way socket, pin order - NC C D + as the stock board's RTC MINI header. It shares the I2C bus with the expander.
Notes from tools/ts06pair.py
U13: A male PLS-5 on the board: the module's own female header plugs onto it and the module lies over it. Pad 1 (square) is GND (-), then NC, C (SCL), D (SDA); the module's pin 1, +, lands on pad 5.

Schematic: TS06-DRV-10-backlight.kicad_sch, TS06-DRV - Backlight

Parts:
R20: 470R; TS06_R_Axial_DIN0207_P2.54mm_Vertical_R270
R53: 220R; TS06_R_Axial_DIN0207_P2.54mm_Vertical_R270
RN1: 8x220R isolated DIP-16; TS06_DIP-16_W7.62mm_Socket_R90
VT20: MPSA42; TS06_TO-92_Inline_Wide_R270

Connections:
B20: R20.2, VT20.2 (B)
BL_A1: RN1.9; also elsewhere on the board
BL_A2: RN1.10; also elsewhere on the board
BL_A3: RN1.11; also elsewhere on the board
BL_A4: RN1.12; also elsewhere on the board
BL_A5: RN1.13; also elsewhere on the board
BL_A6: RN1.14; also elsewhere on the board
BL_A7: RN1.15; also elsewhere on the board
BL_A8: RN1.16; also elsewhere on the board
BL_K: VT20.3 (C); also elsewhere on the board
D11: R20.1; also elsewhere on the board
D12: R53.1; also elsewhere on the board
GND: VT20.1 (E); also elsewhere on the board
M_A: R53.2; also elsewhere on the board
XB0: RN1.8; also elsewhere on the board
XB1: RN1.7; also elsewhere on the board
XB2: RN1.6; also elsewhere on the board
XB3: RN1.5; also elsewhere on the board
XB4: RN1.4; also elsewhere on the board
XB5: RN1.3; also elsewhere on the board
XB6: RN1.2; also elsewhere on the board
XB7: RN1.1; also elsewhere on the board

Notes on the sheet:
TS06-DRV · Backlight
Eight amber LEDs behind the tubes are each sourced from their own MCP23017 port-B pin through an isolated 8 x 220R network; the 'm' LED of AM/PM runs from D12 through 220R. All nine cathodes share BL_K behind one MPSA42, so D11's PWM sets the brightness of them all.
On the display board: BL_A1..BL_A8 feed the anodes of HL1..HL8, M_A the anode of HL9 (the 'm'), and BL_K is all nine cathodes. GPBk of U3 lights HL(k+1): tools/ts06pair.py BL_OF_GPB.
Notes from tools/ts06pair.py
R53: The m LED, from D12. Standing: one of the four series resistors where the Nano's corridor lines end and change face (tools/mkpcb_drv.py). RN1: Isolated resistor network, 8 x 220R (4116R-1-221 class): GPBk -> pin 8-k, resistor to pin 9+k -> its LED. VT20: Common-cathode switch for all nine LEDs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

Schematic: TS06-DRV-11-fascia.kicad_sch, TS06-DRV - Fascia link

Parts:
C5, C6: 100n; TS06_C_Disc_P2.50mm_R180
C18, C19: 10n; TS06_C_Disc_P2.50mm_R270
J1: PH 6 vertical; TS06_JST_PH_B6B-PH-K_Vertical
R72: 1M; TS06_R_Axial_DIN0207_P10.16mm_R180
R73, R74: 1k; TS06_R_Axial_DIN0207_P10.16mm_R180

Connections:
+5V: J1.1; also elsewhere on the board
A6: C5.1, J1.3, R72.1; also elsewhere on the board
A7: C6.1, J1.4; also elsewhere on the board
D7: R73.1; also elsewhere on the board
D7_J: C18.1, J1.5, R73.2
D8: R74.1; also elsewhere on the board
D8_J: C19.1, J1.6, R74.2
GND: C5.2, C6.2, C18.2, C19.2, J1.2, R72.2; also elsewhere on the board

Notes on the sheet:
TS06-DRV · Fascia link
The panel cable leaves on a top-entry 6-way JST PH: +5V, GND, A6, A7, D7, D8, the pin order both fascia builds share. The 100 nF ladder filters on A6 and A7 sit at this end of the cable.
To the fascia: JST PH, 6 ways, top entry.
Parts this sheet's layout does not know yet (added to tools/ts06pair.py since): labelled, not wired.
Notes from tools/ts06pair.py
C5: Ladder filters at the board end (spec §2). C18: Near J1, on the cable side of R73. J1: The panel cable; pin order is the specification both fascia builds share. Top entry, so the cable leaves towards the fascia. R72: A6 pull-down: a defined 0 with the fascia unplugged. R73: Series resistor on t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

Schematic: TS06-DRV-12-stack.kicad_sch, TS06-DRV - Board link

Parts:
H1, H2, H3, H4, H5, H6, H7, H8: TS06_MountingHole_M3
XS11: PBS-10 female 2.54; TS06_PinSocket_1x10_R180
XS12: PBS-31 female 2.54; TS06_PinSocket_1x31_R270
XS21: PBS-5 female 2.54; TS06_PinSocket_1x05_R270
XS22: PBS-3 female 2.54; TS06_PinSocket_1x03_R270
XS23, XS24: PBS-4 female 2.54; TS06_PinSocket_1x04_R270
XS25: PBS-6 female 2.54; TS06_PinSocket_1x06_R270

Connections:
ANODE_AM: XS25.2; also elsewhere on the board
ANODE_H1: XS21.4; also elsewhere on the board
ANODE_H10: XS21.3; also elsewhere on the board
ANODE_M1: XS23.3; also elsewhere on the board
ANODE_M10: XS23.2; also elsewhere on the board
ANODE_PM: XS25.5; also elsewhere on the board
ANODE_S1: XS24.3; also elsewhere on the board
ANODE_S10: XS24.2; also elsewhere on the board
BL_A1: XS21.2; also elsewhere on the board
BL_A2: XS21.5; also elsewhere on the board
BL_A3: XS23.1; also elsewhere on the board
BL_A4: XS23.4; also elsewhere on the board
BL_A5: XS24.1; also elsewhere on the board
BL_A6: XS24.4; also elsewhere on the board
BL_A7: XS25.1; also elsewhere on the board
BL_A8: XS25.6; also elsewhere on the board
BL_K: XS21.1; also elsewhere on the board
CAT_A_KILO: XS12.25; also elsewhere on the board
CAT_A_MEGA: XS12.26; also elsewhere on the board
CAT_A_MICRO: XS12.31; also elsewhere on the board
CAT_A_MILLI: XS12.27; also elsewhere on the board
CAT_A_MINUS: XS12.29; also elsewhere on the board
CAT_A_NANO: XS12.22; also elsewhere on the board
CAT_A_P: XS12.30; also elsewhere on the board
CAT_A_PCT: XS12.23; also elsewhere on the board
CAT_A_PI: XS12.24; also elsewhere on the board
CAT_A_PLUS: XS12.28; also elsewhere on the board
CAT_B_AMP: XS12.14; also elsewhere on the board
CAT_B_FARAD: XS12.20; also elsewhere on the board
CAT_B_HENRY: XS12.18; also elsewhere on the board
CAT_B_HERTZ: XS12.19; also elsewhere on the board
CAT_B_OHM: XS12.15; also elsewhere on the board
CAT_B_SIEMENS: XS12.16; also elsewhere on the board
CAT_B_VOLT: XS12.17; also elsewhere on the board
CAT_B_WATT: XS12.21; also elsewhere on the board
COLON_L: XS22.2; also elsewhere on the board
COLON_RET: XS22.3; also elsewhere on the board
COLON_U: XS22.1; also elsewhere on the board
K0: XS11.9; also elsewhere on the board
K1: XS11.10; also elsewhere on the board
K2: XS11.8; also elsewhere on the board
K3: XS11.6; also elsewhere on the board
K4: XS11.4; also elsewhere on the board
K5: XS11.2; also elsewhere on the board
K6: XS11.1; also elsewhere on the board
K7: XS11.3; also elsewhere on the board
K8: XS11.5; also elsewhere on the board
K9: XS11.7; also elsewhere on the board
KS0: XS12.8; also elsewhere on the board
KS1: XS12.7; also elsewhere on the board
KS2: XS12.6; also elsewhere on the board
KS3: XS12.5; also elsewhere on the board
KS4: XS12.4; also elsewhere on the board
KS5: XS12.3; also elsewhere on the board
KS6: XS12.2; also elsewhere on the board
KS7: XS12.1; also elsewhere on the board
KS8: XS12.10; also elsewhere on the board
KS9: XS12.9; also elsewhere on the board
M_A: XS25.4; also elsewhere on the board

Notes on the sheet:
TS06-DRV · Board link
The display board carries male strips (XP) on its back and the driver board the mating female strips (XS); pin n of XPk mates pin n of XSk. XP11 carries the ИН-12 cathode bus, XP12 the ИН-17 bundle and both ИН-15, and XP21-XP25 the anodes, the colon and the LEDs.
XS12 (PBS-31 female 2.54, mates XP12)
XS11 (PBS-10 female 2.54, mates XP11)
XS21 (PBS-5 female 2.54, mates XP21)
XS22 (PBS-3 female 2.54, mates XP22)
XS23 (PBS-4 female 2.54, mates XP23)
XS24 (PBS-4 female 2.54, mates XP24)
XS25 (PBS-6 female 2.54, mates XP25)
Pin n of XPk (display board, male, on its back) mates pin n of XSk (driver board, female, on its face). The order of every strip is the order the display board's copper arrives in (tools/ts06pair.py HEADERS).
Standoff holes (M3): mechanical, no pad
Notes from tools/ts06pair.py
XS11..XS25: Board-to-board socket on the driver board's face towards the display; mates XP11, XP12, XP21, XP22, XP23, XP24, XP25 in turn.



Board: 2 copper layers, 191.4 x 100.0 mm, 116 parts (8 on the bottom side), 136 nets.

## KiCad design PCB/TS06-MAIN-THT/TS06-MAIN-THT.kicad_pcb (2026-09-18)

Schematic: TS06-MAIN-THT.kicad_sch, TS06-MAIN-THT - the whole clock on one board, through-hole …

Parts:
C1, C2, C4, C5, C6, C13, C14: 100n; TS06_C_Disc_P2.50mm_Back
C3, C11: 10u; TS06_C_Disc_P5.00mm_Back
C7: 4u7 400V; TS06_CP_Radial_D8.0mm_P3.50mm_Back
C8: 100u 25V; TS06_CP_Radial_D6.3mm_P2.50mm_Back
C9, C12: 1u 50V; TS06_C_Disc_P5.00mm_Back
C10: 10u 25V; TS06_C_Disc_P5.00mm_Back
F1: PTC 1.1A; TS06_Fuse_Radial_MF-R_Back
HL1, HL2, HL3, HL4, HL5, HL6, HL7, HL8, HL9: amber 3mm; TS06_LED_D3.0mm
J1: PH 6; TS06_JST_PH_S6B-PH-K-S_Back
L1: 220u 2A; TS06_L_Radial_D10.0mm_P5.00mm_Back
R1, R2, R3, R4, R5, R6, R7, R8, R9, R10, R11, R12, R13, R14, R15, R16, R17, R18, R19, R68, R71: 10k; TS06_R_Axial_L6.3mm_P2.54mm_Vertical_Back
R20, R21, R22, R23, R24, R25, R26: 470R; TS06_R_Axial_L6.3mm_P2.54mm_Vertical_Back
R27, R28, R29, R30: 6k8 TBC; TS06_R_Axial_L9.9mm_P5.08mm_Vertical_Back
R31, R32: 12k; TS06_R_Axial_L9.9mm_P5.08mm_Vertical_Back
R33, R34, R35, R36, R37, R38, R39, R40, R41, R42, R43, R44: 510k DNP; TS06_R_Axial_L6.3mm_P2.54mm_Vertical_Back; not fitted
R45, R46, R47, R48, R49, R50, R51, R52, R53: 220R; TS06_R_Axial_L6.3mm_P2.54mm_Vertical_Back
R54, R55: 4k7; TS06_R_Axial_L6.3mm_P2.54mm_Vertical_Back
R56, R57: 8k2; TS06_R_Axial_L9.9mm_P5.08mm_Vertical_Back
R58, R59: 220k; TS06_R_Axial_L9.9mm_P5.08mm_Vertical_Back
R60, R61: 470k; TS06_R_Axial_L6.3mm_P2.54mm_Vertical_Back
R62, R63: 750k 1%; TS06_R_Axial_L6.3mm_P2.54mm_Vertical_Back
R64: 15k 1%; TS06_R_Axial_L6.3mm_P2.54mm_Vertical_Back
R65: 1M; TS06_R_Axial_L6.3mm_P2.54mm_Vertical_Back
R66: 2k2; TS06_R_Axial_L6.3mm_P2.54mm_Vertical_Back
R67: 10R; TS06_R_Axial_L6.3mm_P2.54mm_Vertical_Back
R69, R70: 10k 1%; TS06_R_Axial_L6.3mm_P2.54mm_Vertical_Back
RP1: 10k; TS06_Trimmer_3296W_Back
U1: Arduino Nano; TS06_Arduino_Nano_Back
U2: K155ID1; TS06_DIP-16_Back
U3, U4: MCP23017; TS06_DIP-28W_Back
U5, U6, U7, U8, U9, U10: TLP627; TS06_DIP-4_Back
U11: TC4420; TS06_DIP-8_Back
U12: LM393; TS06_DIP-8_Back
U13: DS3231 mini; TS06_PinHeader_1x05_Back
U14: R-78E5.0-1.0; TS06_R78E_SIP3_Back
V1, V2, V3, V4: IN-12A; TS06_IN12_Socket
V5, V6: IN-17; TS06_IN17_Socket
V7, V8: INS-1; TS06_INS1_Lamp
V9: IN-15B; TS06_IN12_Socket
V10: IN-15A; TS06_IN12_Socket
VD1: HER106; TS06_D_DO-41_P10.16mm_Back
VD2: 1N5822; TS06_D_DO-201_P15.24mm_Back
VT1, VT2, VT3, VT4, VT5, VT6, VT7, VT8, VT9, VT10, VT11, VT12, VT13, VT14, VT15, VT16, VT17, VT18, VT19, VT20: MPSA42; TS06_TO-92_Back
VT21: IRF840; TS06_TO-220_Horizontal_Back
XS1: DC 5.5x2.1; TS06_BarrelJack_Back

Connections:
+5V: C1.1, C2.1, C3.1, C4.1, C11.1, C13.1, J1.1, R45.1, R46.1, R47.1, R48.1, R49.1, R50.1, R51.1, R52.1, R54.1, R55.1, R69.1, U1.27 (+5V), U2.5 (VCC), U3.9 (VDD), U3.18 (RESET), U4.9 (VDD), U4.15 (A0), U4.18 (RESET), U12.8 (V+), U13.5 (+), U14.3 (OUT)
+12V: C8.1, C9.1, C10.1, C12.1, L1.1, U11.1 (VDD), U11.8 (VDD), U14.1 (IN), VD2.1 (K)
A0: U1.19 (A0), U2.7 (C 4)
A1: U1.20 (A1), U2.6 (B 2)
A2: U1.21 (A2), U2.4 (D 8)
A3: U1.22 (A3), U2.3 (A 1)
A6: C5.1, J1.3, U1.25 (A6)
A7: C6.1, J1.4, U1.26 (A7)
ANODE_AM: R56.1, V9.7
ANODE_H1: R28.2, R35.1, V2.7
ANODE_H10: R27.2, R33.1, V1.7
ANODE_M1: R30.2, R39.1, V4.7
ANODE_M10: R29.2, R37.1, V3.7
ANODE_PM: R57.1, V10.7
ANODE_S1: R32.2, R43.1, V6.A
ANODE_S10: R31.2, R41.1, V5.A
B1: R1.2, VT1.1 (B)
B2: R2.2, VT2.1 (B)
B3: R3.2, VT3.1 (B)
B4: R4.2, VT4.1 (B)
B5: R5.2, VT5.1 (B)
B6: R6.2, VT6.1 (B)
B7: R7.2, VT7.1 (B)
B8: R8.2, VT8.1 (B)
B9: R9.2, VT9.1 (B)
B10: R10.2, VT10.1 (B)
B11: R11.2, VT11.1 (B)
B12: R12.2, VT12.1 (B)
B13: R13.2, VT13.1 (B)
B14: R14.2, VT14.1 (B)
B15: R15.2, VT15.1 (B)
B16: R16.2, VT16.1 (B)
B17: R17.2, VT17.1 (B)
B18: R18.2, VT18.1 (B)
B19: R19.2, VT19.1 (B)
B20: R20.2, VT20.1 (B)
BLEED_H1: R35.2, R36.1
BLEED_H10: R33.2, R34.1
BLEED_HV: R60.2, R61.1
BLEED_M1: R39.2, R40.1
BLEED_M10: R37.2, R38.1
BLEED_S1: R43.2, R44.1
BLEED_S10: R41.2, R42.1
BL_A1: HL1.2 (A), R45.2
BL_A2: HL2.2 (A), R46.2
BL_A3: HL3.2 (A), R47.2
BL_A4: HL4.2 (A), R48.2
BL_A5: HL5.2 (A), R49.2
BL_A6: HL6.2 (A), R50.2
BL_A7: HL7.2 (A), R51.2
BL_A8: HL8.2 (A), R52.2
BL_K: HL1.1 (K), HL2.1 (K), HL3.1 (K), HL4.1 (K), HL5.1 (K), HL6.1 (K), HL7.1 (K), HL8.1 (K), VT20.3 (C)
CAT_A_KILO: V10.12, VT19.3 (C)
CAT_A_MEGA: V10.1, VT10.3 (C)
CAT_A_MICRO: V10.6, VT15.3 (C)
CAT_A_MILLI: V10.2, VT11.3 (C)
CAT_A_MINUS: V10.4, VT13.3 (C)
CAT_A_NANO: V10.9, VT16.3 (C)
CAT_A_P: V10.5, VT14.3 (C)
CAT_A_PCT: V10.10, VT17.3 (C)
CAT_A_PI: V10.11, VT18.3 (C)
CAT_A_PLUS: V10.3, VT12.3 (C)
CAT_B_AMP: V9.9, VT7.3 (C)
CAT_B_FARAD: V9.5, VT5.3 (C)
CAT_B_HENRY: V9.2, VT3.3 (C)
CAT_B_HERTZ: V9.3, VT4.3 (C)
CAT_B_OHM: V9.10, VT8.3 (C)
CAT_B_SIEMENS: V9.12, VT9.3 (C)
CAT_B_VOLT: V9.1, VT2.3 (C)
CAT_B_WATT: V9.6, VT6.3 (C)
COLON_L: R59.2, V8.1
COLON_RET: V7.2, V8.2, VT1.3 (C)
COLON_U: R58.2, V7.1
D2: R25.1, U1.5 (D2)
D3: R21.1, U1.6 (D3)
D4: R22.1, U1.7 (D4)
D5: R23.1, U1.8 (D5)
D6: R24.1, U1.9 (D6)
D7: J1.5, U1.10 (D7)
D8: J1.6, U1.11 (D8)
D9: R66.1, U1.12 (D9)
D10: R1.1, U1.13 (D10)
D11: R20.1, U1.14 (D11)
D12: R53.1, U1.15 (D12)
D13: R26.1, U1.16 (D13)
EMIT_H1: R28.1, U6.3 (E)
EMIT_H10: R27.1, U5.3 (E)
EMIT_M1: R30.1, U8.3 (E)
EMIT_M10: R29.1, U7.3 (E)
EMIT_S1: R32.1, U10.3 (E)
EMIT_S10: R31.1, U9.3 (E)
FB: R63.2, R64.1, U12.2 (IN1-)
FB_LOW: R64.2, RP1.1
FB_MID: R62.2, R63.1
GATE: R67.2, R68.1, VT21.1 (G)
GATE_D: R67.1, U11.6 (OUT), U11.7 (OUT)
GND: C1.2, C2.2, C3.2, C4.2, C5.2, C6.2, C7.2, C8.2, C9.2, C10.2, C11.2, C12.2, C13.2, C14.2, HL9.1 (K), J1.2, R34.2, R36.2, R38.2, R40.2, R42.2, R44.2, R61.2, R68.2, R70.2, R71.2, RP1.2 (W), RP1.3, U1.4 (GND), U1.29 (GND), U2.12 (GND), U3.10 (VSS), U3.15 (A0), U3.16 (A1), U3.17 (A2), U4.10 (VSS), U4.16 (A1), U4.17 (A2), U5.2 (K), U6.2 (K), U7.2 (K), U8.2 (K), U9.2 (K), U10.2 (K), U11.4 (GND), U11.5 (GND), U12.4 (GND), U12.6 (IN2-), U13.1 (-), U14.2 (GND), VT1.2 (E), VT2.2 (E), VT3.2 (E), VT4.2 (E), VT5.2 (E), VT6.2 (E), VT7.2 (E), VT8.2 (E), VT9.2 (E), VT10.2 (E), VT11.2 (E), VT12.2 (E), VT13.2 (E), VT14.2 (E), VT15.2 (E), VT16.2 (E), VT17.2 (E), VT18.2 (E), VT19.2 (E), VT20.2 (E), VT21.3 (S), XS1.2 (-)
HV185: C7.1, R56.2, R57.2, R58.1, R59.1, R60.1, R62.1, U5.4 (C), U6.4 (C), U7.4 (C), U8.4 (C), U9.4 (C), U10.4 (C), VD1.1 (K)
K0: U2.10 (Q7), V1.6, V2.6, V3.6, V4.6, V5.0, V6.0
K1: U2.9 (Q3), V1.9, V2.9, V3.9, V4.9, V5.1, V6.1
K2: U2.11 (Q6), V1.10, V2.10, V3.10, V4.10, V5.2, V6.2
K3: U2.13 (Q4), V1.11, V2.11, V3.11, V4.11, V5.3, V6.3
K4: U2.15 (Q1), V1.12, V2.12, V3.12, V4.12, V5.4, V6.4
K5: U2.2 (Q9), V1.1, V2.1, V3.1, V4.1, V5.5, V6.5
K6: U2.1 (Q8), V1.2, V2.2, V3.2, V4.2, V5.6, V6.6
K7: U2.16 (Q0), V1.3, V2.3, V3.3, V4.3, V5.7, V6.7
K8: U2.14 (Q5), V1.4, V2.4, V3.4, V4.4, V5.8, V6.8
K9: U2.8 (Q2), V1.5, V2.5, V3.5, V4.5, V5.9, V6.9
M_A: HL9.2 (A), R53.2
OPT_H1: R22.2, U6.1 (A)
OPT_H10: R21.2, U5.1 (A)
OPT_M1: R24.2, U8.1 (A)
OPT_M10: R23.2, U7.1 (A)
OPT_S1: R26.2, U10.1 (A)
OPT_S10: R25.2, U9.1 (A)
PWM_G: R65.1, R66.2, R71.1, U11.2 (IN), U12.1 (OUT1)
SCL: R55.2, U1.24 (A5/SCL), U3.12 (SCL), U4.12 (SCL), U13.3 (C)
SDA: R54.2, U1.23 (A4/SDA), U3.13 (SDA), U4.13 (SDA), U13.4 (D)
SW: L1.2, VD1.2 (A), VT21.2 (D)
U3_GPA0: R2.1, U3.21 (GPA0)
U3_GPA1: R3.1, U3.22 (GPA1)
U3_GPA2: R4.1, U3.23 (GPA2)
U3_GPA3: R5.1, U3.24 (GPA3)
U3_GPA4: R6.1, U3.25 (GPA4)
U3_GPA5: R7.1, U3.26 (GPA5)
U3_GPA6: R8.1, U3.27 (GPA6)
U3_GPA7: R9.1, U3.28 (GPA7)
U4_GPA0: R10.1, U4.21 (GPA0)
U4_GPA1: R11.1, U4.22 (GPA1)
U4_GPA2: R12.1, U4.23 (GPA2)
U4_GPA3: R13.1, U4.24 (GPA3)
U4_GPA4: R14.1, U4.25 (GPA4)
U4_GPA5: R15.1, U4.26 (GPA5)
U4_GPA6: R16.1, U4.27 (GPA6)
U4_GPA7: R17.1, U4.28 (GPA7)
U4_GPB0: R18.1, U4.1 (GPB0)
U4_GPB1: R19.1, U4.2 (GPB1)
VIN_F: F1.2, VD2.2 (A)
VIN_J: F1.1, XS1.1 (+)
VREF: C14.1, R65.2, R69.2, R70.1, U12.3 (IN1+), U12.5 (IN2+)

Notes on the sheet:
12 V IN. Barrel jack, PTC fuse, reverse-polarity Schottky, then an R-78E switching regulator makes the 5 V rail for everything, Nano included (its 5V pin; VIN open). A PC on the Nano's USB with no adapter plugged in runs the logic with the tubes dark - the boost has no 12 V.
185 V RAIL, regulated this time. D9's 31 kHz clock reaches the MOSFET through a proper 12 V driver; a comparator watches the rail through a 1.5 M / 20.5 k divider and holds the driver input low whenever FB is above VREF, so the stage skips cycles until the rail sags back. The trimmer is a rheostat 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
NANO. Pin map is the firmware's and is not renumbered.
ONE DECODER for six digit tubes. A0..A3 -> C B D A as on the inherited board; output Q_c goes to the cathode of digit d where digitMask[d] = c (BOARD_TYPE 0), so K7 hangs off Q0, K4 off Q1 ... K5 off Q9.
SIX DIGIT TUBES on the shared cathode bus K0..K9 (named by digit). IN-12A pads per the inherited copper: pad 7 anode, pad 8 no pin. IN-17 pads named by digit from judge2005's footprint - bench gate 3.
ANODE CHAINS, one per digit tube: Nano pin -> 470 R -> TLP627 LED; collector on HV185, emitter -> series R -> anode. Bleed pairs are DNP unless the bench asks for them. 6k8 for the IN-12s is TBC (gate 2).
AM/PM: two MCP23017 on the same I2C wires as the RTC, eighteen 300 V low-side switches, one per real cathode. V9 IN-15B shows A, V10 IN-15A shows P. Anode resistors one per tube. Pad maps: bench gate 4.
COLON: two INS-1 neons, each with its own 220 k ballast, one low-side MPSA42 on D10.
BACKLIGHT: eight amber LEDs, one under each tube, series 220 R from +5V, switched low-side from D11. The 'm' of AM/PM is HL9 straight off D12: firmware decides always-on or 12-hour-only.
FASCIA CABLE J1, pin order fixed for both fascia builds: +5V GND A6 A7 D7 D8. The 100 nF ladder filters sit here, at the board end.
RTC. SMD build: DS3231SN with a CR2032 holder. THT build: the DS3231 mini module on a 5-way header (- NC C D +).



Board: 2 copper layers, 176.0 x 96.0 mm, 146 parts (127 on the bottom side), 140 nets.

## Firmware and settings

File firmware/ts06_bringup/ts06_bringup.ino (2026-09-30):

/*
  TERMINAL-06 // bring-up sketch for the through-hole pair TS06-DISP + TS06-DRV
  ---------------------------------------------------------------------------
  A bench tool, not the clock. It drives the driver board one block at a time
  from the Serial Monitor, so each stage of PCB/TS06-pair-testing.md (part C)
  can be tested on its own. The clock firmware (firmware/nixieClock_TS06 with
  BOARD_TYPE 4) is not touched by this sketch and is flashed after it.

  Serial Monitor: 9600 baud, any line ending. Commands are single characters.

  SAFE BY DEFAULT
    * After every reset the 185 V converter is OFF (D9 held low), every anode
      is off, all four decoders are blank and every LED is off. Opening the
      Serial Monitor resets the Nano, so it switches the high voltage off too.
      (C7 still holds its charge for a few seconds: see the testing guide.)
    * The converter starts only on a capital H. A lower-case h stops it.
    * Only one anode is ever on. With the converter on, a tube runs at the
      clock's own duty, 21 of 156 ticks of 128 us (2.69 ms lit in each
      19.97 ms frame, 13.5 %), unless you ask for 's': a steady burst of 5 s
      for reading the voltage across its anode resistor. With the converter
      off (the rail is then only the 12 V input, ~11 V) 's' stays on until
      you change it, so a meter can read the switch at leisure.
    * The IN-15 pair has no anode switch: it is lit from the rail through
      R56 / R57 whenever its decoder gets a code with a glyph. So with the
      converter on, 'g', 'a', 'p' and 'c' light the IN-15s at full current.

  COMMANDS
    ?        help and status
    H / h    185 V converter on / off (31.4 kHz on D9, duty 190, as the clock)
    i        I2C scan: expects 0x20 (MCP23017, U3) and 0x68 (DS3231, U13)
    0 .. 9   that digit on U2 + U17 (the IN-12 bus and the IN-17 pair)
    g        next code on U15 + U16 (the IN-15 pair): 0 .. 9, then blank
    a / p    IN-15B shows A (AM) / IN-15A shows P (PM), the other one blank
    b        blank all four decoders
    c        cycle: every second the next code on all four decoders, with
             the decoder pin and the strip pin that should now be low
    t        next anode: H10 H1 M10 M1 S10 S1, then none
    x        all anodes off
    s        steady burst on the selected anode (5 s with the converter on);
             s again ends it early
    k        colon switch on / off (D10 -> R1 -> VT1)
    l        backlight: all nine, then HL1 .. HL8, HL9 (m) alone, then off
    r        live A6 / A7 / buttons, four times a second (r again stops)

  Every table below is the board's, from tools/ts06pair.py, and
  tools/verify_pair.sh checks them against it.
*/
#include <Wire.h>
#include <avr/pgmspace.h>

#define BAUD      9600
#define PIN_HV    9       // D9 -> R66 -> PWM_G -> TC4420 -> IRF840: the converter's clock
#define PIN_COLON 10      // D10 -> R1 10k -> VT1 base: both colon lamps
#define PIN_BACKL 11      // D11 -> R20 470R -> VT20 base: BL_K, every LED's cathode
#define PIN_M     12      // D12 -> R53 220R -> HL9, the "m" LED
#define PIN_MINUS 7       // fascia "-" button, to ground
#define PIN_PLUS  8       // fascia "+" button, to ground
#define DUTY      190     // the clock's DUTY: 23.8 us on in each 31.9 us period
#define MCP_ADDR  0x20    // U3, A0-A2 grounded
#define RTC_ADDR  0x68    // DS3231 on the module in U13

#define FRAME_TICKS 156   // 6 slots x 26 ticks of 128 us: the clock's 19.97 ms frame
#define LIT_TICKS   21    // SLOT_TICKS 26 - DEAD_TICKS 5 at INDI_BRIGHT 21: 13.5 %
#define BURST_MS    5000  // the steady burst, when the converter is on

// ---------------------------------------------------------------- the board's tables
// anode drive, in tube order H10 H1 M10 M1 S10 S1 (TUBE_PIN4)
const uint8_t ANODE_PIN[6] = {6, 5, 4, 3, 2, 13};
// digit -> K155ID1 code on U2 and U17 (DIGIT_MASK4, the firmware's BOARD_TYPE 4 digitMask)
const uint8_t DIGIT_CODE[10] = {1, 0, 5, 4, 6, 7, 3, 2, 9, 8};
// which bit carries code weight 1, 2, 4, 8: PORTC bit (Nano A0..A3) for U2 + U17 (K155_INPUT),
// MCP23017 port-A bit for U15 and for U16 (XA_IN)
const uint8_t NANO_BIT[4] = {3, 1, 0, 2};
const uint8_t U15_BIT[4] = {3, 1, 0, 2};
const uint8_t U16_BIT[4] = {7, 5, 4, 6};
// K155ID1 output Qn -> its DIP-16 pin
const uint8_t Q_PIN[10] = {16, 15, 8, 9, 13, 14, 11, 10, 1, 2};
// digit -> the strip pin that carries it: XS11 (IN-12 bus), XS12 pins 1-10 (IN-17 pair)
const uint8_t XS11_PIN[10] = {9, 10, 8, 6, 4, 2, 1, 3, 5, 7};
const uint8_t XS12_PIN[10] = {8, 7, 6, 5, 4, 3, 2, 1, 10, 9};
// IN-15 decoder code -> glyph (GLYPH_Q) and -> its XS12 pin (0: that output has no glyph)
const char G_U15[] PROGMEM = "WATT FARAD AMP OHM HENRY HERTZ VOLT SIEMENS - -";
const char G_U16[] PROGMEM = "MINUS PLUS NANO PCT MEGA MILLI KILO PI P MICRO";
const uint8_t U15_XS12[10] = {21, 20, 14, 15, 18, 19, 17, 16, 0, 0};
const uint8_t U16_XS12[10] = {29, 28, 22, 23, 26, 27, 25, 24, 30, 31};
// backlight: GPBk lights HL(k+1) through RN1 pins (8-k)-(9+k); the strip and pin of its anode
const uint8_t BL_STRIP[8] = {21, 21, 23, 23, 24, 24, 25, 25};
const uint8_t BL_PIN[8] = {2, 5, 1, 4, 1, 4, 1, 6};
// the anode resistor and the strip pin of each tube
const char TUBE_TXT[] PROGMEM =
  "H10 V1 IN-12 R27 6k8 XS21.3|H1 V2 IN-12 R28 6k8 XS21.4|M10 V3 IN-12 R29 6k8 XS23.2|"
  "M1 V4 IN-12 R30 6k8 XS23.3|S10 V5 IN-17 R31 12k XS24.2|S1 V6 IN-17 R32 12k XS24.3";
const char MODE_TXT[] PROGMEM = "NORMAL|SET TIME|DISPLAY|AMBIENT|FORMAT/DATE|INFO";

// ---------------------------------------------------------------- state
volatile uint8_t *volatile aPort = 0;   // the selected anode's port, and its bit (0: none)
volatile uint8_t aMask = 0;
volatile bool steady = false;
volatile uint8_t tick = 0;
int8_t tube = -1;                       // selected anode, -1: none
bool hv = false, colon = false, live = false, cycling = false, mcpOk = false;
bool busOk = false;                    // SDA and SCL idle high: safe to talk on the bus
uint8_t digitCode = 15, c15 = 15, c16 = 15, ledState = 0, cycleStep = 0;
uint32_t burstStart = 0, lastLive = 0, lastCycle = 0;

// ---------------------------------------------------------------- helpers
// the n-th item of a PROGMEM list separated by sep
void printItem(const char *p, uint8_t n, char sep) {
  char ch;
  while (n && (ch = pgm_read_byte(p++))) if (ch == sep) n--;
  while ((ch = pgm_read_byte(p++)) && ch != sep) Serial.write(ch);
}

uint8_t nibble(uint8_t code, const uint8_t *bitOf) {
  uint8_t v = 0;
  for (uint8_t w = 0; w < 4; w++)
    if (code & (1 << w)) v |= 1 << bitOf[w];
  return v;
}

uint8_t mcpWrite(uint8_t reg, uint8_t val) {
  if (!busOk) return 4;
  Wire.beginTransmission(MCP_ADDR);
  Wire.write(reg);
  Wire.write(val);
  return Wire.endTransmission();
}

int readReg(uint8_t addr, uint8_t reg) {
  if (!busOk) return -1;
  Wire.beginTransmission(addr);
  Wire.write(reg);
  if (Wire.endTransmission(false)) return -1;
  if (Wire.requestFrom(addr, (uint8_t)1) != 1) return -1;
  return Wire.read();
}

void writeDecoders() {
  PORTC = (PORTC & 0xF0) | nibble(digitCode, NANO_BIT);
  mcpWrite(0x12, nibble(c15, U15_BIT) | nibble(c16, U16_BIT));   // GPIOA
}

// Latches first, then directions, so no pin ever drives the power-on latch 0x00 (code 0,
// which would light a glyph on both IN-15s). Register 0x05 is IOCON in BANK = 1: a 0
// there brings a chip left in BANK = 1 back to BANK = 0 (in BANK = 0 it is GPINTENB).
void mcpInit() {
  mcpWrite(0x05, 0x00);
  writeDecoders();
  mcpWrite(0x13, 0x00);                 // GPIOB: LEDs off
  mcpWrite(0x00, 0x00);                 // IODIRA: outputs
  mcpWrite(0x01, 0x00);                 // IODIRB
  mcpOk = (readReg(MCP_ADDR, 0x00) == 0x00 && readReg(MCP_ADDR, 0x01) == 0x00);
}

// Timer2 overflow, 7812.5 Hz: the selected anode is lit for LIT_TICKS of every FRAME_TICKS,
// like one slot of the clock's multiplex, or all the time in a steady burst.
ISR(TIMER2_OVF_vect) {
  if (++tick >= FRAME_TICKS) tick = 0;
  if (aMask) {
    if (steady || tick < LIT_TICKS) *aPort |= aMask;
    else *aPort &= (uint8_t)~aMask;
  }
}

void selectTube(int8_t t) {
  cli();
  aMask = 0;
  for (uint8_t i = 0; i < 6; i++) digitalWrite(ANODE_PIN[i], LOW);
  steady = false;
  tube = t;
  if (t >= 0) {
    aPort = portOutputRegister(digitalPinToPort(ANODE_PIN[t]));
    aMask = digitalPinToBitMask(ANODE_PIN[t]);
  }
  sei();
}

void setHV(bool on) {
  if (on) {
    steady = false;                     // a burst started with the rail at 12 V ends here
    TCCR1B = (TCCR1B & 0xF8) | 1;       // Timer1 prescaler 1: 16 MHz / 510 = 31.4 kHz
    for (int d = 20; d < DUTY; d += 2) { // soft start, ~85 ms: L1 would saturate on a step to DUTY
      analogWrite(PIN_HV, d);
      delay(1);
    }
    analogWrite(PIN_HV, DUTY);
  } else {
    analogWrite(PIN_HV, 0);             // pin low, PWM disconnected
  }
  hv = on;
}

// ---------------------------------------------------------------- reports
void printTube() {
  Serial.print(F("anode: "));
  if (tube < 0) { Serial.println(F("none")); return; }
  printItem(TUBE_TXT, tube, '|');
  Serial.print(F(", pin D"));
  Serial.print(ANODE_PIN[tube]);
  Serial.println(steady ? F(", STEADY") : F(", 13.5 % duty"));
}

void printDigit(uint8_t d) {
  uint8_t c = DIGIT_CODE[d];
  Serial.print(F("digit "));
  Serial.print(d);
  Serial.print(F(" = code "));
  Serial.print(c);
  Serial.print(F(": U2/U17 pin "));
  Serial.print(Q_PIN[c]);
  Serial.print(F(" low -> XS11."));
  Serial.print(XS11_PIN[d]);
  Serial.print(F(" (IN-12), XS12."));
  Serial.print(XS12_PIN[d]);
  Serial.println(F(" (IN-17)"));
}

void printIn15() {
  Serial.print(F("IN-15B (U15) "));
  if (c15 > 9) Serial.print(F("blank"));
  else {
    Serial.print(F("code ")); Serial.print(c15); Serial.print(' ');
    printItem(G_U15, c15, ' ');
    if (U15_XS12[c15]) { Serial.print(F(": pin ")); Serial.print(Q_PIN[c15]); Serial.print(F(" low -> XS12.")); Serial.print(U15_XS12[c15]); }
  }
  Serial.print(F(" | IN-15A (U16) "));
  if (c16 > 9) Serial.println(F("blank"));
  else {
    Serial.print(F("code ")); Serial.print(c16); Serial.print(' ');
    printItem(G_U16, c16, ' ');
    Serial.print(F(": pin ")); Serial.print(Q_PIN[c16]); Serial.print(F(" low -> XS12.")); Serial.println(U16_XS12[c16]);
  }
}

void applyLeds() {
  uint8_t b = 0;
  if (ledState == 1) b = 0xFF;
  else if (ledState >= 2 && ledState <= 9) b = 1 << (ledState - 2);
  mcpWrite(0x13, b);
  digitalWrite(PIN_M, (ledState == 1 || ledState == 10) ? HIGH : LOW);
  digitalWrite(PIN_BACKL, ledState ? HIGH : LOW);   // VT20 grounds BL_K
  Serial.print(F("LEDs: "));
  if (ledState == 0) Serial.println(F("off"));
  else if (ledState == 1) Serial.println(F("all nine on (VT20 on, GPB0-7 high, D12 high)"));
  else if (ledState == 10) Serial.println(F("HL9, the m, alone (D12 -> R53 -> XS25.4)"));
  else {
    uint8_t k = ledState - 2;
    Serial.print(F("HL")); Serial.print(k + 1);
    Serial.print(F(" alone (GPB")); Serial.print(k);
    Serial.print(F(", RN1 pins ")); Serial.print(8 - k); Serial.print('-'); Serial.print(9 + k);
    Serial.print(F(", XS")); Serial.print(BL_STRIP[k]); Serial.print('.'); Serial.print(BL_PIN[k]);
    Serial.println(')');
  }
}

void scanI2C() {
  // the idle bus first: R54 / R55 (4k7) hold SDA and SCL high; the AVR's own pull-ups are off here
  Wire.end();
  pinMode(A4, INPUT);
  pinMode(A5, INPUT);
  delay(2);
  bool sda = digitalRead(A4), scl = digitalRead(A5);
  Wire.begin();
#if defined(WIRE_HAS_TIMEOUT)
  Wire.setWireTimeout(25000, true);
#endif
  Serial.print(F("idle bus: SDA ")); Serial.print(sda ? F("high") : F("LOW"));
  Serial.print(F(", SCL ")); Serial.print(scl ? F("high") : F("LOW"));
  Serial.println((sda && scl) ? F(" - ok") : F(" - a line held low or a pull-up missing (R54 / R55)"));
  busOk = sda && scl;
  if (!busOk) {                         // a stuck line can hang an AVR core without Wire timeouts
    Serial.println(F("  scan skipped: find the short first (U3 pins 12/13, U13 pins 3/4, R54, R55)"));
    return;
  }
  bool mcp = false, rtc = false;
  uint8_t n = 0;
  for (uint8_t a = 0x08; a < 0x78; a++) {
    Wire.beginTransmission(a);
    if (Wire.endTransmission() != 0) continue;
    n++;
    Serial.print(F("  0x")); if (a < 16) Serial.print('0'); Serial.print(a, HEX); Serial.print(F("  "));
    if (a == MCP_ADDR) { mcp = true; Serial.println(F("MCP23017, U3 - expected")); }
    else if (a > MCP_ADDR && a <= 0x27) Serial.println(F("an MCP23017 at the wrong address: U3 pins 15-17 must be grounded"));
    else if (a == RTC_ADDR) { rtc = true; Serial.println(F("DS3231, the RTC module in U13 - expected")); }
    else if (a >= 0x50 && a <= 0x57) Serial.println(F("EEPROM on the RTC module (AT24C32 class) - fine if the module has one"));
    else Serial.println(F("unknown device"));
  }
  Serial.print(n); Serial.println(F(" device(s)"));
  if (!mcp) Serial.println(F("  0x20 MISSING: U3 not fitted, turned round, or no +5 V on its pin 9"));
  if (!rtc) Serial.println(F("  0x68 MISSING: the module not fitted, or its pins in another order (gate 6: - NC C D +)"));
  if (mcp) {
    mcpInit();
    applyLeds();
    Serial.println(mcpOk ? F("  MCP23017 takes register writes and reads them back") : F("  MCP23017 answers but did not read back its registers"));
  }
  if (rtc) {
    int s = readReg(RTC_ADDR, 0), m = readReg(RTC_ADDR, 1), h = readReg(RTC_ADDR, 2);
    int st = readReg(RTC_ADDR, 0x0F), tm = readReg(RTC_ADDR, 0x11), tl = readReg(RTC_ADDR, 0x12);
    if (s >= 0 && m >= 0 && h >= 0) {
      Serial.print(F("  DS3231 time "));
      Serial.print((h >> 4) & 3); Serial.print(h & 15); Serial.print(':');
      Serial.print(m >> 4); Serial.print(m & 15); Serial.print(':');
      Serial.print((s >> 4) & 7); Serial.print(s & 15);
      if (tm >= 0 && tl >= 0) { Serial.print(F(", ")); Serial.print((int8_t)tm + (tl >> 6) * 0.25); Serial.print(F(" C")); }
      if (st >= 0 && (st & 0x80)) Serial.print(F(", OSF set: the clock stopped since it was last set (new battery?)"));
      Serial.println();
    }
  }
}

void printLive() {
  int a6 = analogRead(A6), a7 = analogRead(A7);
  uint8_t pos = (a6 + 102) / 205 + 1;               // the firmware's own rounding (ts06pair.ino)
  int ideal = (1023L * (pos - 1) + 2) / 5;          // 0 205 409 614 818 1023
  const int LV[4] = {1023, 682, 512, 409};           // open, FIELD, SUB, both
  uint8_t best = 0;
  for (uint8_t i = 1; i < 4; i++) if (abs(a7 - LV[i]) < abs(a7 - LV[best])) best = i;
  Serial.print(F("A6 ")); Serial.print(a6);
  Serial.print(F(" = MODE ")); Serial.print(pos); Serial.print(' ');
  printItem(MODE_TXT, pos - 1, '|');
  Serial.print(F(" (")); Serial.print(a6 - ideal >= 0 ? F("+") : F("")); Serial.print(a6 - ideal);
  Serial.print(F(")  A7 ")); Serial.print(a7);
  Serial.print(best == 0 ? F(" = levers open") : best == 1 ? F(" = FIELD") : best == 2 ? F(" = SUB") : F(" = FIELD+SUB"));
  Serial.print(F(" (")); Serial.print(a7 - LV[best] >= 0 ? F("+") : F("")); Serial.print(a7 - LV[best]);
  Serial.print(F(")  - ")); Serial.print(digitalRead(PIN_MINUS) ? F("up") : F("DOWN"));
  Serial.print(F("  + ")); Serial.println(digitalRead(PIN_PLUS) ? F("up") : F("DOWN"));
}

void cycleOnce() {
  if (cycleStep > 10) cycleStep = 0;
  if (cycleStep == 10) {
    digitCode = c15 = c16 = 15;
    writeDecoders();
    Serial.println(F("-- all four decoders blank (code 15): no strip pin low --"));
  } else {
    digitCode = DIGIT_CODE[cycleStep];
    c15 = c16 = cycleStep;
    writeDecoders();
    printDigit(cycleStep);
    Serial.print(F("        "));
    printIn15();
  }
  cycleStep++;
}

void help() {
  Serial.println(F("\nTS06 pair bring-up. 9600 baud.  ? help   H/h HV on/off   i I2C scan"));
  Serial.println(F("0-9 digit on U2+U17   g next IN-15 code   a / p  AM / PM   b blank   c cycle all decoders"));
  Serial.println(F("t next anode   x anodes off   s steady burst   k colon   l LEDs   r live A6/A7/buttons"));
  Serial.print(F("HV ")); Serial.print(hv ? F("ON  (185 V on C7, the optos, the anode and colon resistors)") : F("off"));
  Serial.print(F("   colon ")); Serial.print(colon ? F("on") : F("off"));
  Serial.print(F("   MCP23017 ")); Serial.println(mcpOk ? F("ok") : F("not answering (press i)"));
  printTube();
  if (digitCode > 9) Serial.println(F("U2/U17 blank"));
  else for (uint8_t d = 0; d < 10; d++) if (DIGIT_CODE[d] == digitCode) printDigit(d);
  printIn15();
}

// ---------------------------------------------------------------- setup / loop
void setup() {
  // everything safe before anything else: converter clock low, anodes low, decoders blank
  pinMode(PIN_HV, OUTPUT); digitalWrite(PIN_HV, LOW);
  for (uint8_t i = 0; i < 6; i++) { pinMode(ANODE_PIN[i], OUTPUT); digitalWrite(ANODE_PIN[i], LOW); }
  DDRC |= 0x0F;
  PORTC = (PORTC & 0xF0) | 0x0F;        // code 15 on U2 and U17: nothing lit
  pinMode(PIN_COLON, OUTPUT); digitalWrite(PIN_COLON, LOW);
  pinMode(PIN_BACKL, OUTPUT); digitalWrite(PIN_BACKL, LOW);
  pinMode(PIN_M, OUTPUT); digitalWrite(PIN_M, LOW);
  pinMode(PIN_MINUS, INPUT_PULLUP);
  pinMode(PIN_PLUS, INPUT_PULLUP);

  Serial.begin(BAUD);
  bool busIdle = digitalRead(A4) && digitalRead(A5);   // R54 / R55 hold an idle bus high
  Wire.begin();
#if defined(WIRE_HAS_TIMEOUT)
  Wire.setWireTimeout(25000, true);     // a missing or stuck chip must not hang the sketch
#endif
  busOk = busIdle;
  if (busOk) mcpInit();               // both IN-15 blank, LEDs off (harmless if U3 is absent)
  else Serial.println(F("I2C: SDA or SCL is low at reset - not touching the bus (press i)"));

  // Timer2: fast PWM, prescaler 8, overflow interrupt at 7812.5 Hz (the clock's tick)
  TCCR2A = _BV(WGM21) | _BV(WGM20);
  TCCR2B = (TCCR2B & 0xF8) | 2;
  TIMSK2 = _BV(TOIE2);

  help();
}

void loop() {
  uint32_t now = millis();
  if (steady && hv && now - burstStart >= BURST_MS) {
    steady = false;
    Serial.println(F("steady burst over: back to 13.5 %"));
  }
  if (live && now - lastLive >= 250) { lastLive = now; printLive(); }
  if (cycling && now - lastCycle >= 1000) { lastCycle = now; cycleOnce(); }

  if (!Serial.available()) return;
  char ch = Serial.read();
  if (ch >= '0' && ch <= '9') {
    cycling = false;
    digitCode = DIGIT_CODE[ch - '0'];
    writeDecoders();
    printDigit(ch - '0');
    return;
  }
  switch (ch) {
    case '?': help(); break;
    case 'H': setHV(true);  Serial.println(F("HV ON: the converter is running. One hand; meter leads clipped before power-up.")); break;
    case 'h': setHV(false); Serial.println(F("HV off: C7 is still charged - wait 15 s and check it is under 10 V")); break;
    case 'i': scanI2C(); break;
    case 'g': cycling = false; c15 = c16 = (c15 == 9) ? 15 : (c15 > 9) ? 0 : c15 + 1; writeDecoders(); printIn15(); break;
    case 'a': cycling = false; c15 = 2; c16 = 15; writeDecoders(); printIn15(); break;
    case 'p': cycling = false; c15 = 15; c16 = 8; writeDecoders(); printIn15(); break;
    case 'b': cycling = false; digitCode = c15 = c16 = 15; writeDecoders(); Serial.println(F("all four decoders blank")); break;
    case 'c': cycling = !cycling; cycleStep = 0; lastCycle = now - 1000; Serial.println(cycling ? F("cycling (c stops)") : F("cycle stopped")); break;
    case 't': selectTube(tube >= 5 ? -1 : tube + 1); printTube(); break;
    case 'x': selectTube(-1); printTube(); break;
    case 's':
      if (tube < 0) { Serial.println(F("no anode selected: t first")); break; }
      if (steady) { steady = false; printTube(); break; }
      burstStart = now; steady = true;
      Serial.println(hv ? F("steady burst, 5 s") : F("steady (HV off: until t, x or s again)"));
      printTube();
      break;
    case 'k': colon = !colon; digitalWrite(PIN_COLON, colon); Serial.println(colon ? F("colon on (VT1 conducting)") : F("colon off")); break;
    case 'l': ledState = (ledState >= 10) ? 0 : ledState + 1; applyLeds(); break;
    case 'r': live = !live; break;
    default: break;                      // line endings and anything else: ignored
  }
}

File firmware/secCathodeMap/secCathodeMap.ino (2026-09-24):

/*
  TERMINAL-06 // SEC cathode mapping jig
  --------------------------------------------------------------
  Run this ONCE, on one board, before you build the first SEC module.
  It tells you which physical K155ID1 output pin carries which digit,
  so the seconds-module harness can be crimped the same way ten times.

  Do NOT guess this from a datasheet you found online - Soviet K155ID1
  and Western SN74141 parts are pin compatible but the marking on
  surplus chips is not always what it claims. Measure it.

  METHOD
    1. Unplug the tube board. HV OFF - pull the boost transistor's supply,
       or simply leave the HV rail unloaded and DO NOT touch the tube pads.
       This sketch never enables the boost oscillator on D9, so the board
       stays at 5 V only. Verify with a meter before probing.
    2. Upload. Open the Serial Monitor at 9600 baud.
    3. The sketch parks on one BCD code at a time, 3 s each, and prints it.
    4. With a multimeter on continuity/diode or DC volts, find which
       K155ID1 output pin is pulled LOW (near 0 V) during each step.
    5. Write the pin number into the table below. That is your harness map.

  RESULT TABLE - fill in once, keep with the build documents:

      digit 0 -> K155ID1 pin ____      digit 5 -> K155ID1 pin ____
      digit 1 -> K155ID1 pin ____      digit 6 -> K155ID1 pin ____
      digit 2 -> K155ID1 pin ____      digit 7 -> K155ID1 pin ____
      digit 3 -> K155ID1 pin ____      digit 8 -> K155ID1 pin ____
      digit 4 -> K155ID1 pin ____      digit 9 -> K155ID1 pin ____

  Then wire SEC connector J2 pin N to the K155ID1 pin for digit N, and
  the IN-17 cathode for digit N to J2 pin N on the module. One mask,
  no firmware changes.
  --------------------------------------------------------------
*/

#define BOARD_TYPE 0      // MUST match the value in nixieClock_TS06.ino

#define DECODER0 A0
#define DECODER1 A1
#define DECODER2 A2
#define DECODER3 A3

#define STEP_MS 3000

// same masks as the clock firmware - the jig walks DISPLAYED digits, so the
// pin you record is exactly the pin that digit needs on the SEC module
#if (BOARD_TYPE == 0)
const byte digitMask[] = {7, 3, 6, 4, 1, 9, 8, 0, 5, 2};
#elif (BOARD_TYPE == 1)
const byte digitMask[] = {2, 8, 1, 9, 6, 4, 3, 5, 0, 7};
#elif (BOARD_TYPE == 2)
const byte digitMask[] = {9, 8, 0, 5, 4, 7, 3, 6, 2, 1};
#elif (BOARD_TYPE == 4)
const byte digitMask[] = {1, 0, 5, 4, 6, 7, 3, 2, 9, 8};
#else
const byte digitMask[] = {0, 1, 2, 3, 4, 5, 6, 7, 8, 9};
#endif

void setup() {
  Serial.begin(9600);
  pinMode(DECODER0, OUTPUT);
  pinMode(DECODER1, OUTPUT);
  pinMode(DECODER2, OUTPUT);
  pinMode(DECODER3, OUTPUT);
  // every anode driver stays off - nothing lights, nothing draws HV
  for (byte p = 2; p <= 6; p++) { pinMode(p, OUTPUT); digitalWrite(p, LOW); }
  pinMode(13, OUTPUT); digitalWrite(13, LOW);
  pinMode(9, OUTPUT);  digitalWrite(9, LOW);   // boost oscillator OFF

  Serial.println(F("TERMINAL-06 cathode mapping jig"));
  Serial.println(F("Confirm the HV rail reads ~0 V before probing."));
}

void loop() {
  for (byte d = 0; d < 10; d++) {
    byte v = digitMask[d];          // the code the clock sends for this digit
    // same bit order the clock firmware uses
    digitalWrite(DECODER3, bitRead(v, 0));
    digitalWrite(DECODER1, bitRead(v, 1));
    digitalWrite(DECODER0, bitRead(v, 2));
    digitalWrite(DECODER2, bitRead(v, 3));

    Serial.print(F("DISPLAYED DIGIT "));
    Serial.print(d);
    Serial.print(F("   (BCD "));
    Serial.print(v);
    Serial.println(F(")  -  record the K155ID1 output pin that is LOW"));
    delay(STEP_MS);
  }
  Serial.println(F("--- cycle complete, repeating ---"));
}

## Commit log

2026-08-28 Initial commit: TERMINAL-06 six-tube display firmware (P2 test build)
    Derived from AlexGyver NixieClock v2.5. Display-layer port only:
    4->6 tubes, Timer2 prescaler 1 (~400Hz refresh), anti-poisoning and
    glitch effects extended to all six tubes, buzzer removed (D2 reused).
    Still on the old rev B control scheme (2 buttons + 1 lever), not the
    rotary/lever panel described in the project spec.
    Known discrepancy vs TERMINAL-06-spec.md: DOT_BRIGHT is still 35/15
    (LED-era), not the 170/90 neon retune the spec describes as already
    done. Flagged in README, not fixed here.
    [0_data.ino, 1_setup.ino, 2_loop.ino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]
2026-09-05 Fix multiplex ghosting: explicit dead time, derived from named constants
    The K155ID1 was being switched to the next tube's digit while the outgoing
    tube's TLP627 was still conducting, so the outgoing tube faintly lit the
    incoming digit. The gap protecting against that was 26 - INDI_BRIGHT ticks:
    dead time and brightness were the same number, with no floor.
    That coupling was harmless at the stock prescaler of 8 (one tick = 128 us,
    so 256 us of margin even at full brightness). This fork moved to prescaler 1
    for a faster refresh without rescaling anything, cutting the margin to 48 us
    against a measured ~250-300 us optocoupler turn-off tail.
    Timing is now expressed as two named constants, ever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
    [0_data.ino, 2_loop.ino, bright.ino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]
2026-09-06 Revert Timer2 to prescaler 8: 640 us dead time, 50 Hz, ghost-free
    Product call from the bench: the camera-banding requirement is dropped.
    Ghosting is a defect every owner sees daily; 60 fps video flicker is a
    photography problem solvable with a shutter speed. Everything the ~400 Hz
    target justified goes with it, including the prescaler 8 -> 1 rewrite.
    The measured ghost-free configuration is 640 us of dead time across six
    tubes. At AlexGyver's original prescaler 8 a tick is 128 us, so that margin
    costs 5 ticks instead of the 18 it cost at 16 us ticks. That is what makes a
    short slot and a bright display compatible again - the previous revision had
    to trade one against the other and shipped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
    [1_setup.ino, isr.ino, nixieClock_TS06.ino]
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2026-09-08 Control scheme rev B: swap INFO to position 6, give SUB the glitch rate
    Two changes to spec section 1, decided while designing the fascia face. Spec section
    1 is not yet rewritten - this file is the authority until the sweep runs.
    INFO and FORMAT/DATE swap. Section 1 already called positions 1 and 5 the two screens
    that ignore every input; rev A left one of them mid-arc. Rev B puts both parking
    screens on end stops, so the knob cannot be knocked past either end into a live
    editing screen. Costs one row of the A6 threshold table - the voltages do not move,
    only the screen each maps to.
    SUB gains the glitch rate on Display, read only while FIELD = Effects. The point is
    not the feature but th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
    [TS06-FASCIA.kicad_sch]
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2026-09-08 TS06-FASCIA board: outline, placement, nets and front artwork
    tools/mkpcb.py generates the board; tools/checkpcb.py checks it offline. Placement
    and artwork only - no routing yet, on purpose. If a control sits 3mm off, routing it
    first is wasted work.
    FRONT FACE RULE, and it changed the design: nothing punches a hole through the face.
    The first pass used through-hole axial resistors and through-hole landing pads, and
    checkpcb caught why that was wrong - the decorative gold on the face is genuine copper
    on F.Cu, so every through-hole pad it crossed was a short, not a graphic. Three of them
    were. Rather than route the artwork around the pads, the pads left the front: every
    wire-landing pad is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
    [TS06-FASCIA.kicad_pcb]
2026-09-09 Strip fab notes, mirror back-side text, replace J1 with back-side cable pads
    Three fixes from first contact with the board in KiCad.
    Back-layer text was NOT mirrored - my mistake, not a viewer quirk. Renaming F.SilkS
    to B.SilkS is not enough; KiCad needs (justify mirror) on every text that lives on a
    back layer, or it reads backwards when you actually look at the back. 46 text blocks
    corrected.
    F.Fab notes stripped entirely. I had written long strings at fixed offsets inside
    each footprint, so five copies of a 40mm note stacked into an unreadable pile the
    moment they shared a board. The detail moves into each footprint's descr field, which
    KiCad stores as metadata and never draws. Switch V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
    [TS06-FASCIA.kicad_pcb]
2026-09-09 Fit the real JST PH SMT connector; fix nets that were silently not attaching
    J1 becomes S6B-PH-SM4-TB: 6-way, 2.0mm pitch, side entry, surface mount, 2A/100V.
    Land pattern taken from KiCad's Connector_JST library, which draws it from JST's
    manufacturer drawing - not invented, and not scaled off a marketplace photo. JST's
    own PH sheet omits the SMT layout entirely, so the library is the better source.
    Cross-checked before use: the library body is 15.9mm wide, and JST's dimension table
    gives B = A + 5.9 with A = 2.0 x (n-1), so n=6 is 10.0 + 5.9 = 15.9. Their table's
    endpoints agree too (n=2 -> 7.9, n=16 -> 35.95). Two independent sources, one number.
    Mirrored in X for back-side mounting, so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
    [TS06-FASCIA.kicad_pcb]
2026-09-09 Re-place the A6 ladder so it routes without a single crossing
    The old arrangement had the rotary landing pads on a 3.6mm pitch in ascending order
    and R1-R5 in a separate row to one side. Every tap trace then had to cross its
    neighbours to reach the right pad - unroutable on one layer without vias.
    Two changes fix it together. The landing pads go to 8mm pitch, which leaves room to
    sit a 1206 in the gap between every adjacent pair. And both the pads and the chain
    run in DESCENDING voltage order (+5V leftmost, GND, then COM on the right nearest
    the connector), which puts each resistor's pad 1 - its higher node - facing left
    toward the switch pad it belongs to.
    The ladder is now ten short diag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
    [TS06-FASCIA.kicad_pcb]
2026-09-09 Route TS06-FASCIA on two layers; link the schematic to the board
    43 tracks, 7 vias, both clearance and connectivity checks clean at 0.2mm.
    TWO LAYERS, deliberately. The front of this board is copper too, and a trace there is
    invisible: solder mask is opaque, so only the deliberate mask openings show gold. That
    makes F.Cu a free routing layer for anything clear of the decorative copper. All seven
    vias are tented and sit at y > 45, in the band the chassis recess covers. Single-layer
    was attempted first and does not fit: the switch body keepouts occupy everything above
    y=38, leaving a 13mm band that already holds the landing pads, both resistor rows and
    the connector - four buses through that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
    [TS06-FASCIA.kicad_pcb, TS06-FASCIA.kicad_sch]
2026-09-09 Audit found six real defects on the fascia; all fixed
    You were right to push. tools/checkcopper.py was passing a board with visible faults,
    because it only checks copper against copper. tools/audit.py is a second opinion that
    checks what the first one structurally cannot.
    The gap that mattered most: checkcopper verifies each pad is TOUCHED by a track of its
    net. A net split into two islands passes that, because every pad is touched by
    something. audit.py builds the real graph - pads, tracks and vias unioned by geometric
    contact - and requires ONE component per net. All 12 nets pass, so the routing itself
    was sound. The faults were everywhere else.
    Found by the audit:
    - MASK HALO on every g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
    [TS06-FASCIA.kicad_pcb]
2026-09-09 Revert the fascia to placement + cosmetic gold; routing preserved on a branch
    Board is back to what it was at 7213e72 in copper terms: footprints, nets, front
    artwork and decorative gold, no functional traces. 0 segments, 0 vias.
    Nothing is lost. Two ways back to the routed board:
    git checkout pcb/fascia-routed the full routed board, audited clean
    tools/_fascia_routing.py.disabled the block verbatim, paste it back
    KEPT from the audit pass, because none of it is routing and all of it was wrong:
    mask openings inverted so gold has no bare-laminate halo
    SW1..SW5 designators off the product face, onto F.Fab
    dial leader lines horizontal instead of sloping away from t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
    [TS06-FASCIA.kicad_pcb]
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2026-09-09 PCB: fix stale J1 pin-order legend on the fascia back silkscreen
    The physical silkscreen text still read the pre-fix order (D8, D7,
    GND, A7, +5V, A6) even after the schematic/symbol description was
    corrected earlier. THT's board and both mkpcb*.py generators already
    had the right text - this was the one place it hadn't propagated to.
    [TS06-FASCIA.kicad_pcb]
2026-09-09 PCB: TS06-FASCIA-THT cosmetic rework and GND pour fill
    Cosmetic trace tidy-up around the 6-pin connector done by hand in
    KiCad, and the GND pour re-filled over the reworked layout. Checked
    clean: 18 footprints/46 pads, 34 tracks/0 vias, schematic and board
    agree on all 12 nets, pour reaches all 7 GND pads.
    [TS06-FASCIA-THT.kicad_pcb]
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2026-09-17 PCB: TS06-SEC routed, checker fixes, 3D assembly and the TS06-MAIN brief
    Work left uncommitted by the session that drew TS06-SEC, committed as-is so the
    TS06-MAIN work that follows starts from a clean tree:
    - PCB/TS06-SEC: surface-mount build, placed and routed by tools/mkpcb_sec.py
    with the new grid router tools/pcbroute.py (negotiated routing, HV clearance class)
    - tools/mkfp_sec.py and the pre-rotated back-side footprints it generates;
    corrected TS06_IN12_Socket / TS06_IN17_Socket (Y mirror, anode pad, no pip hole)
    - audit.py, checkcopper.py, checkpcb.py, render.py fixes (both KiCad file dialects)
    - TS06-FASCIA compressed to 40 mm; PCB/README.md updated
    - 3d/Clock.FCStd reviewed 8-tu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
    [Clock.FCStd, IN12.FCStd, IN12.step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]
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2026-09-17 sch: write symbols the way KiCad 10 reads them; accept no-connect flags in checksch
    kicad-cli 10.0.5 refused to load either fascia schematic ("Failed to load schematic")
    because tools/mksch.py prefixed the unit sub-symbols inside lib_symbols with the
    library nickname ("TS06:R_0_1"); KiCad writes them bare ("R_0_1") and only names the
    entry itself with the full lib_id. The generator's own comment claimed the opposite
    and had never been checked against KiCad. Fixed, both fascia schematics regenerated
    (UUIDs churn: mksch.py uses uuid4), checksch and checkmatch still pass, and KiCad
    now loads both. The (hide yes) flag also moves from a property's effects to the
    property itself, which is where Ki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
    [TS06-FASCIA-THT.kicad_sch, TS06-FASCIA.kicad_sch]
2026-09-17 TS06-MAIN phase 1-3: one netlist, two schematics, the footprints, both boards placed
    tools/ts06main.py is the netlist both builds share: every part, pin and net of the
    combined board, with the display chain, the AM/PM section and the colon carried over
    from the inherited copper and TS06-SEC, and the converter redesigned for 12 V in with a
    real feedback loop (LM393 gating the D9 clock through a TC4420 driver). Two builds
    differ only in package and, for the RTC, in the part.
    tools/mksch_main.py draws it as a labelled netlist grouped by function, into its own
    symbol library (PCB/lib/TS06M.kicad_sym). Both schematics pass checksch with no
    dangling pins, KiCad 10 loads them, and KiCad's own netl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
    [TS06-MAIN-THT.kicad_pcb, TS06-MAIN-THT.kicad_sch, TS06-MAIN.kicad_pcb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]
2026-09-17 sch: symbol libraries claim the library format version KiCad 10 writes
    Both generators stamped the .kicad_sym files with the schematic format version
    (20260306); KiCad 10.0.5 writes its own libraries as 20251024 and refuses to load a
    library claiming a newer one, so the TS06 and TS06M libraries could not be opened in
    the symbol editor and every schematic symbol raised a library warning in ERC. Fixed in
    tools/mksch.py and tools/mksch_main.py, libraries and schematics regenerated; the two
    main boards also get a KiCad project file so the library tables resolve.
    [TS06-FASCIA-THT.kicad_sch, TS06-FASCIA.kicad_sch, TS06-MAIN-THT.kicad_sch]
2026-09-17 TS06-MAIN: README, bills of materials, and the board in the FreeCAD assembly
    PCB/README.md marks TS06-SEC and TS06-COLON superseded and describes the combined
    board: the 17.09.26 decisions, how it is built, where the three bands are, what is
    checked. tools/bom_main.py writes each build's bom.md from the netlist module, with the
    delta against the three boards it replaces. 3d/Clock.FCStd now carries KiCad's STEP export
    of the placed board in the tube plane (world X 0..176, Y 4..100, Z 15..16.51), the two
    inherited halves and the colon board switched off; every tube's pins reach through it.
    [Clock.FCStd]
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2026-09-18 PCB/README: the routing results for both TS06-MAIN builds, and what is left
    The surface-mount build routes with one net unconnected and KiCad DRC clean apart from
    that and three accepted items. The through-hole build is space-limited and needs its own
    placement pass: 13 split nets and 50 through-hole pads inside another part CourtYard.
    Both tables, the one known surface-mount defect and why moving the in-ring switches is
    not its fix, are written up beside the decisions that produced them.
    [TS06-MAIN-THT.kicad_pcb]
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2026-09-18 TS06-MAIN: every signal net routed, 339 vias instead of 476, and an honest ground
    The surface-mount board, re-routed with what the study settled on: grain 8, a via at
    9 mm, relax 4, two tighten passes, history decay off, infrastructure nets exempt, and
    a stage-4 rescue freed of the grain.
    every signal net routed (the board that shipped left B2 split)
    339 vias (476)
    8726 mm of copper (8575, at a 1.23x detour either way)
    49% / 11% front grain (33% / 25% - that one is what routing at random looks like)
    checkcopper --hv clean, checkmatch agrees, audit down to one finding
    The one finding is real and is NOT new. GND's copper joins into three pieces, not o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
    [TS06-MAIN.kicad_pcb]
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2026-09-18 PCB: both TS06-MAIN builds re-routed, and the README says what is now true
    Surface-mount: every signal net connected, 339 vias against 476, 49%/11% front grain
    against 33%/25%, checkcopper --hv clean, checkmatch agrees. The VT2 base that used to
    be the one split net is routed.
    Through-hole: the rules improve its copper a lot - 177 vias against 271, a grain of
    44/14 where it used to run MORE ACROSS than along - and do not touch its connectivity.
    13 nets split either way. That build's problem is placement and always was.
    The README now carries the measured trade for the two stranded ИН-15 emitters, the
    pointer to the routing study and its twenty-two configurations, and the two findings
    tha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
    [TS06-MAIN-THT.kicad_pcb]
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2026-09-24 TS06-DISP: THT display board, tubes only, zero vias
    The display half of the Gyver-style split: 4x IN-12, 2x IN-17, 2x IN-15,
    2x INS-1, 9 LEDs and male pin strips (PLS) that plug straight into
    female strips (PBS) on the driver board - no wires.
    - tools/sexp.py: small S-expression reader/writer for KiCad files
    - tools/pcbkit.py: footprint transform, placement, octilinear router,
    clearance/connectivity check, KiCad 10 board + project writer (HV/CATH
    net classes carried into the .kicad_pro), refuses to write vias
    - tools/ts06pair.py: netlist for the display/driver pair, checked for
    single-pin nets and header agreement between the two boards
    - tools/mkpcb_disp.py: the board generator
    - PCB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
    [TS06-DISP.kicad_pcb]
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2026-09-29 Pair: move the top-right standoff clear of XP12; review corrected by an independent check
    The display's H4 standoff shares the gap between the boards with XP12's plastic body. No
    courtyard check compares them, because the hole's footprint is on the front and the strip's
    on the back. At (172.5, 5.5) a hex spacer's corner came 0.5 mm from the strip's end. It now
    sits at (172.5, 7.5) on both boards: 1.9 mm to a 5.5 mm hex, 1.6 mm to a 7 mm washer. The
    display's copper is unchanged. TS06-DISP: 0 vias, checkcopper --hv clean. KiCad 10 DRC shows
    0 unconnected and only the two known colon courtyard overlaps. TS06-DRV takes the new hole
    when it is regenerated from its route.
    The review and the gene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
    [TS06-DISP.kicad_pcb]
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2026-09-29 firmware: make BOARD_TYPE 4 run on the TS06 pair
    BOARD_TYPE 4 had the pair's digit map and anode order, but three things
    kept it from running as a clock. All three are fixed under
    #if (BOARD_TYPE == 4):
    * D12 is the "m" LED on the pair (R53 220R -> HL9 -> BL_K), not the SW3
    PROGRAM/RUN lever. It is now an output, driven high. The fascia has no
    PROGRAM/RUN lever at all (A6 MODE rotary, A7 FIELD/SUB levers, D7 "-",
    D8 "+"). So readLever() reads the rotary: SET TIME is PROGRAM and every
    other position is RUN. For types 0-3, readLever() is a macro for
    digitalRead(LEVER), and LEVER is left undefined for type 4.
    * MUX_SLOTS 6: the pair always carries all six tubes. The timing
    constant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
    [1_setup.ino, buttonsSettings.ino, nixieClock_TS06.ino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]
2026-09-29 TS06-DRV: routed, no vias, clean in KiCad 10's DRC
    The route converged in negotiated routing: round 16, 0 nets sharing, 0 unrouted. A polish
    pass then re-routed each net alone. The route is saved in tools/mkpcb_drv_routes.json, so the
    board regenerates exactly.
    - 1067 segments, 0 vias. Every strip pin and standoff lines up with TS06-DISP (check_mate()
    == []).
    - checkcopper --hv is clean, audit.py is clean, and B.check finds 0 problems.
    - KiCad 10 DRC: 0 errors and 0 unconnected. Four warnings remain:
    - the Nano's USB outline is proud of the edge, by design;
    - the stock silkscreen of VT21 and XS1 is clipped at their pads.
    Fixes on the way:
    - The router: an end snapped sideways onto ano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
    [TS06-DRV.kicad_pcb]
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2026-09-29 case-pair: interference checks, 1:1 drawings, STL parts and PNG views
    - checks.md: the envelope (189.0 x 120.3 x 83.6) and every check.
    - Rear panel vs the parts: U13 5.0 mm clear.
    - Jack plug engagement per cheek treatment.
    - Brow vs the tubes at 10°: the digits clear to 12.6°, and the glass top
    shows for its first 3.6 mm. The brow, valance, sill and trench walls hide
    the header joints (ray cast).
    - Clearances found tight: the trench wall vs H10 glass, the sill vs the
    ИН-17 LEDs, the SR25 rim vs the sill, the КМД1 vs the fascia's top-right
    hole, the fascia lead slack.
    - The inherited ИН-17 13.0 mm pitch against Ø20 stems.
    out/: front elevation, section through M10 with si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
    [base.stl, brow.stl, cheek_l.stl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]
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2026-09-29 Pair review: the ИН-17 spacing blocks an order; firmware and case findings folded in
    - Blocking finding: TS06-DISP carries the FreeCAD assembly's 13.0 mm between the two ИН-17.
    The tube's factory outline (Ø20 stem; knowledge/TERMINAL-06-measurements-IN17 Rev 5) and
    concept Rev F need 20.5. The case model's interference check found it. The review sets out
    the two ways to re-space the row; the choice is the owner's.
    - Finding 8: BOARD_TYPE 4 now runs the pair. Still to do: the rotary's screens, the levers,
    the ИН-15 content. Two older problems for every board type are recorded but not changed:
    rtc.adjust() on every boot, and a stale .hex.
    - Case: 189 x 120 x 84 mm outside, fro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
    [params.scad]
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2026-09-29 TS06-DRV: re-routed on the widened 191.4 mm board; both boards re-verified
    The route converged in negotiated routing at round 15, with 0 nets sharing and 0 unrouted. A
    polish pass followed. The route is saved in tools/mkpcb_drv_routes.json.
    - TS06-DRV:
    - 1097 segments (369 hand-laid), 0 vias; check_mate() == [];
    - checkcopper --hv clean, audit.py clean;
    - KiCad 10 DRC: 0 errors, 0 unconnected. Four warnings as before: the Nano's USB outline past
    the edge, and the stock silk of VT21 and XS1 clipped at their pads.
    - 5936 mm of signal copper, 1.33x its 4479 mm floor, 86.1 % square.
    - Three more ground pads, where the new route left back-face slivers, keep out of the pours.
    - TS06-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
    [TS06-DRV.kicad_pcb, base.stl, brow.stl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]
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2026-09-30 case-pair + TS06-FASCIA: fascia centred on the tube row, trench wall clear of ИН-15А, stray silk ring fixed
    Found by the fascia/case grill at 40cc33b and verified against the files:
    - The right trench wall stood at X 166.5, left over from the 176 mm
    boards, and covered ИН-15А's glass from 166.5 to 181.1. The check
    printed "OK" over a -14.6 mm gap. The wall is now derived: ИН-15А's
    glass + 0.4 allowance + 0.5 = X 182.035. It still hides XP12's last
    pins (183.55) and the H4 screw. The check grades FAIL / TIGHT / OK.
    - "Centred under the tube row" was centred on the board outline (95.7).
    The tube row's middle is 92.3, halfway between H10 and ИН-15А, because
    TS06-DISP's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
    [TS06-FASCIA.kicad_pcb, cheek_l.stl, cheek_r.stl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]
2026-09-30 BOMs and firmware: fixes from the manufacturing and product grills
    BOM (tools/bom_pair.py; both BOMs regenerated), all checked against the
    repo:
    - U13: the DS3231 mini's own header is female. It needs a PLS (male)
    header, not a PBS socket. Pad 1 (square) is GND and the module's "+"
    goes to pad 5, so matching square to square reverses it.
    - F1: the footprint is the MF-RG1100 outline, an 11 A part. The BOM now
    asks for a 1.1 A radial PTC on 5.1 mm leads, e.g. MF-R110.
    - The 0.5 W 350 V resistors must be DIN0309 size with leads of 0.6 mm or
    less. МЛТ-0,5 / С2-23-0,5 (Ø4.2 × 10.8, 0.8 mm leads) don't fit the
    0.8 mm drill, and they collide at 3.8 mm row spacing.
    - L1 is flagged: c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
    [1_setup.ino, buttonsSettings.ino]
2026-09-30 TS06-DRV values and firmware soft-start: fixes from the electrical grill
    - R56/R57, the static ИН-15 anode resistors: 8k2 -> 18k. The ИН-15s are
    lit continuously, so 8k2 ran them at 4.2-5.4 mA, about twice the
    rated 2.5 mA. 18k gives 2.5 mA at a 140 V sustaining voltage.
    - R64 15k -> 18k and RP1 10k -> 5k: the set point now spans 165-210 V
    and reaches 185 V near mid-travel. At one end of the old trimmer it
    reached 252 V.
    - Firmware: the HV PWM ramps from 20 to DUTY over about 85 ms. Jumping
    straight to DUTY with C7 at 12 V let L1's current ratchet past
    saturation for 15-20 ms. Types 0 and 4 compile.
    The board changed in its value fields only. KiCad 10 DRC: 0 errors,
    0 unconn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
    [TS06-DRV.kicad_pcb]
2026-09-30 Pair: one-command verification, the owner's viewing and bench guide, a bring-up sketch
    tools/verify_pair.sh runs every check on TS06-DISP and TS06-DRV from the repo root and prints
    PASS / FAIL / SKIP per check with its numbers: the netlist, the mate, the firmware and sketch
    tables against the netlist, each board against a fresh run of its generator, checkpcb,
    checkcopper --hv, audit, KiCad 10 DRC (local kicad-cli, else Docker, else SKIP), BOM freshness
    and the case model's checks and outputs. Nothing in the tree is written. The accepted items
    (H3 and the colon courtyards on DISP, the Nano and XS11 past the edge, DRV's 4 KiCad warnings,
    the case's two rejected jack alternatives) are documente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
    [ts06_bringup.ino]
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

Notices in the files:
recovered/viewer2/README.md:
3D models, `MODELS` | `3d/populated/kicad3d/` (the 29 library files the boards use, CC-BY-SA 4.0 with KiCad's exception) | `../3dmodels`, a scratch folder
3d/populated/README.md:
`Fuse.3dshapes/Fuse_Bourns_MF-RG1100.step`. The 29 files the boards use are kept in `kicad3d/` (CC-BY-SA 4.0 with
